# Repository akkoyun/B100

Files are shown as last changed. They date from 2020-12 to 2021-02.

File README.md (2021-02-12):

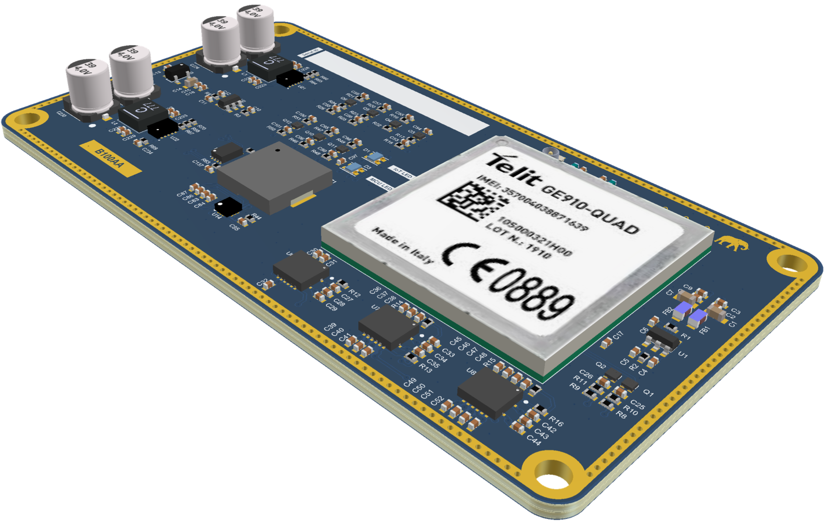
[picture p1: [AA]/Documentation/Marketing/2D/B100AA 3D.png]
B100AA


# B100 All in one GSM IoT Module

B100 module is an open source industrial GSM IoT module.  Module have Atmel based AtMega2560 main microcontroller and AtMega 328P FOTA (remote firmware update - Firmware Over The Air) microcontroller. B100 also have a lot of features on it in a 86x46 (mm) size.

## Features

* Small size 86mm x 46 mm (10 mm heigh).
* Mini header socket for plug and play use.
* 1V8 - 5V5 Vin.
* 3V8 and 5V buck-boost converter.
* 3V3 LDO regulator for digital use.
* All power network are controlled by MCU (for low power modes).
* Main power switch for time trigged sleep mode.
* Atmel based main microcontroller - AtMega2560
* 3V3 / 7.3728mHz main microcontroller.
* Main MCU controlled status LED (RGB).
* 5 port main MCU pinout (socket output).
* External main MCU programmer (ICSP) pinout (socket output).
* External I2C pinout (master line) (socket output).
* External 4 UART pinout (socket output).
* Remote firmware update over GSM.
* Atmel based FOTA microcontroller - AtMega328P
* External FOTA MCU programmer (ICSP) pinout (socket output).
* FOTA MCU controlled status LED (RGB).
* 2G GSM modem - Telit GE910QUAD
* Full hardware based flow control structure.
* External SIM (tray) pin outs.
* Internal eSIM.
* MHF4 GSM antenna output socket.
* GSM power LED.
* GSM status LED (connection etc).
* GSM data transfer LED.
* GSM modem external control USB test points.
* Internal SD card.
* Internal piezo buzzer.
* Internal I2C multiplexer for onboard features.
* Internal real time clock.
* RTC time tick LED.
* I2C Serial ID eeprom.
* I2C eeprom for setting storage.
* Internal I2C ADC (for pressure sensor etc).
* All software (library and samples) are open source.

## Production

All production files are in [production](https://github.com/akkoyun/B100/tree/01.00.00/%5BAA%5D/Production) folder. 

You can download and produce B100 yourself (according license declaration), or you can write us for buy module.

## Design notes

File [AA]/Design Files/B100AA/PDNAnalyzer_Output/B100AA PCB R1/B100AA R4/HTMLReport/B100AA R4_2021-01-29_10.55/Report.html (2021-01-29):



PDN Analyzer Results Report for
B100AA PCB R1

PDN Analyzer Version: 2.0.6.338
Report Time / Date: 29.01.2021 10:55:08
Project Name: B100AA PCB R1
Project Path: C:\Altium Projects\B100\[AA]\Design Files\B100AA\B100AA PCB R1.PcbDoc
PCB Design Name: B100AA PCB R1.PcbDoc
PDN Analyzer Configuration File: C:\Altium Projects\B100\[AA]\Design Files\B100AA\PDNAnalyzer_Output\B100AA PCB R1\B100AA R4\HTMLReport\B100AA R4_2021-01-29_10.55\B100AA R4.pdna

Design Stackup

Layer Name | Layer Name | Material | Thickness (mm) | Dielectric Material | Dielectric Constant | Pullback (mm) | Orientation
Top Overlay | Overlay | | | | | | Top
Top Solder | Solder Mask | Surface Material | 0.013 | Solder Resist | 3,8 | | Top
Top Layer | Signal | Copper | 0.035 | | | | Top
Dielectric 1 | Dielectric | Prepreg | 0.1 | 2313 | 4,05
Mid Layer 1 | Signal | Copper | 0.018
Core 1 | Dielectric | Core | 0.565 | FR-4 | 4,5
Mid Layer 2 | Signal | Copper | 0.018
Dielectric 2 | Dielectric | Prepreg | 0.127 | 2116 | 4,25
Mid Layer 3 | Signal | Copper | 0.018
Core 2 | Dielectric | Core | 0.565 | FR-4 | 4,5
Mid Layer 4 | Signal | Copper | 0.018
Dielectric 3 | Dielectric | Prepreg | 0.1 | 2313 | 4,05
Bottom Layer | Signal | Copper | 0.035 | | | | Bottom
Bottom Solder | Solder Mask | Surface Material | 0.013 | Solder Resist | 3,8 | | Bottom
Bottom Overlay | Overlay | | | | | | Bottom

Artwork by Layer

Layer: Top Layer
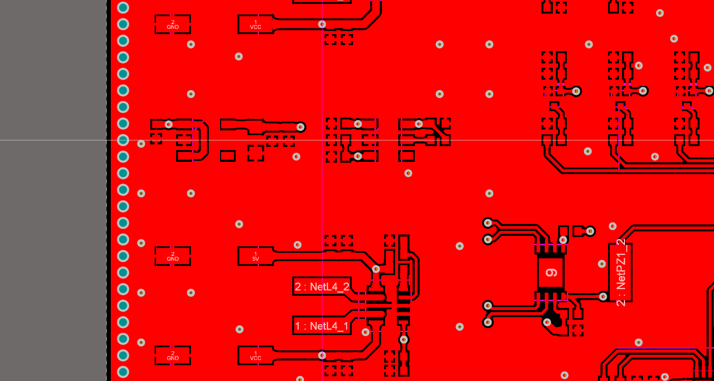
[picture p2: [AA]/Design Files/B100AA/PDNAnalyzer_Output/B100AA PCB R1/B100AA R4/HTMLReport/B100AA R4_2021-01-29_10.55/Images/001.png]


Layer: Mid Layer 1
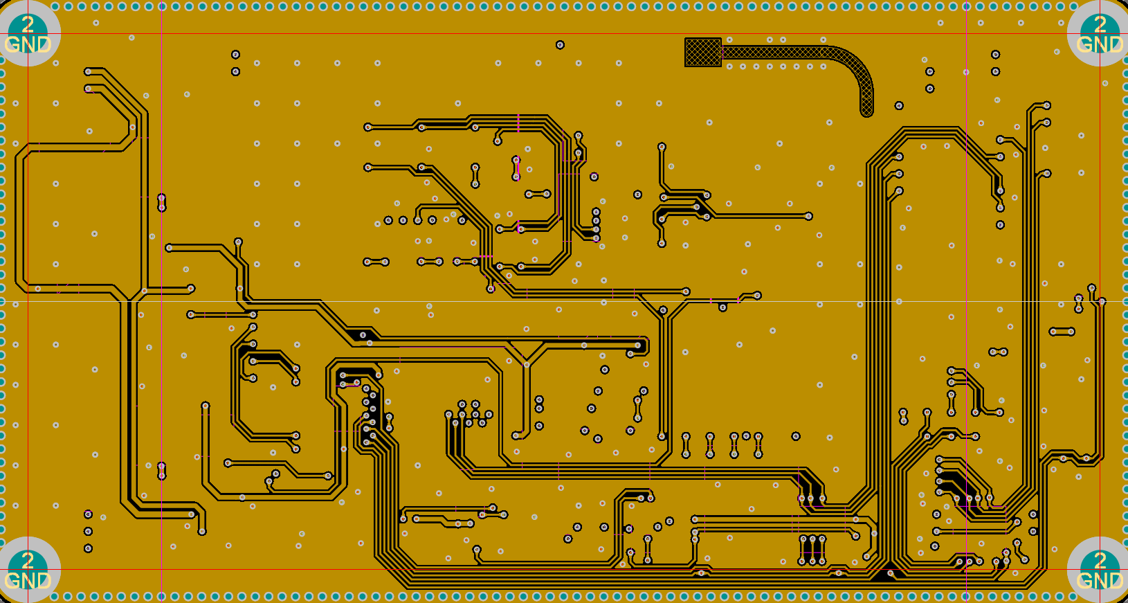
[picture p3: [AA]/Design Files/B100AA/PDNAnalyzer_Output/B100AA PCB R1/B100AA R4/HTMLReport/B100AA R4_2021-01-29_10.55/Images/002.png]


Layer: Mid Layer 2
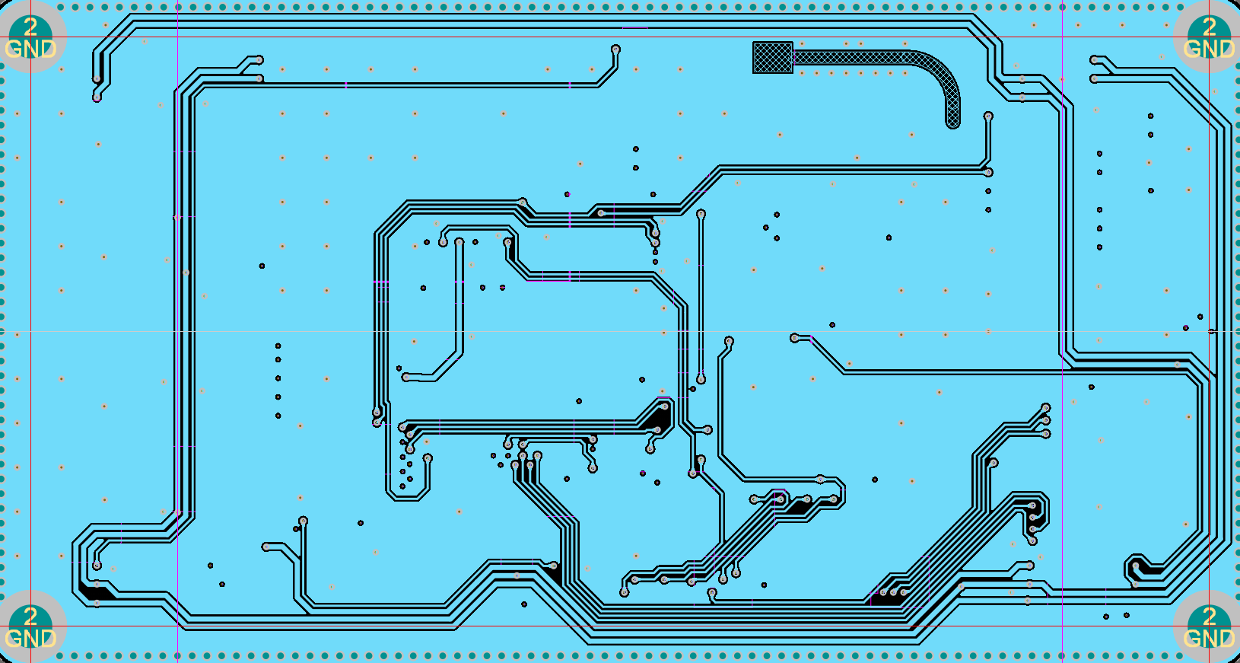
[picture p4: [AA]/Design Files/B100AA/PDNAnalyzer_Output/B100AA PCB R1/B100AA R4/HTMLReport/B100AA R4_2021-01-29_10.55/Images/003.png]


Layer: Mid Layer 3
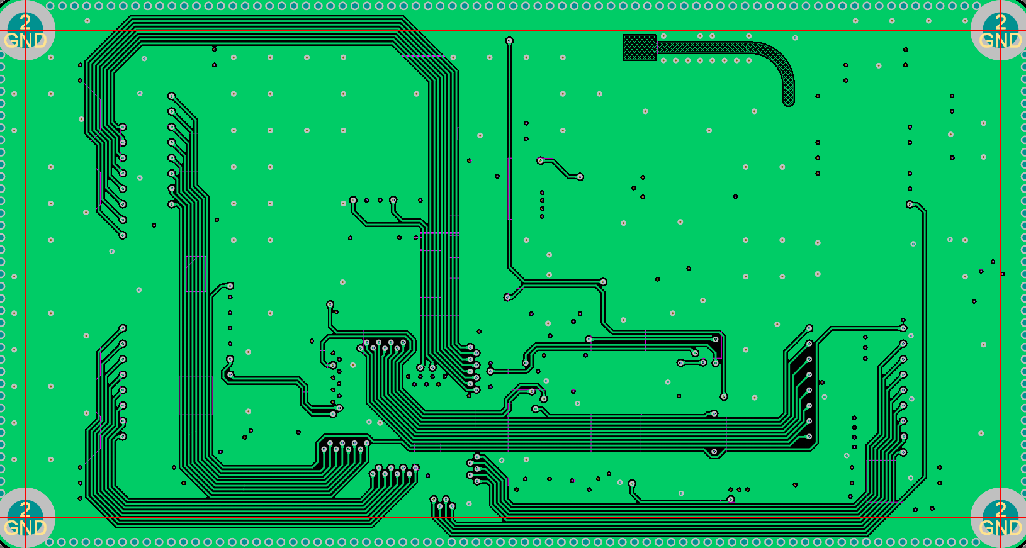
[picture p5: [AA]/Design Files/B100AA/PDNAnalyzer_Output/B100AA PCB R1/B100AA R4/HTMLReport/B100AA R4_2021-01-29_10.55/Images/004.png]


Layer: Mid Layer 4
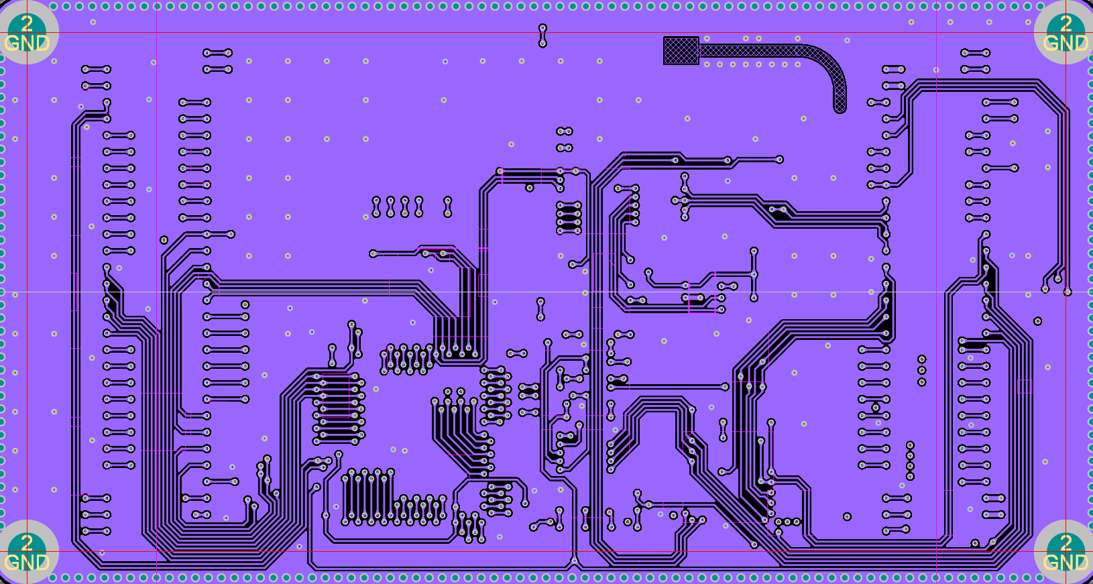
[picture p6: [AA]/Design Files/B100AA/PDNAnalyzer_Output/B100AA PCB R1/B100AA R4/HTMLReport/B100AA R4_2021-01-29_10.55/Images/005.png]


Layer: Bottom Layer
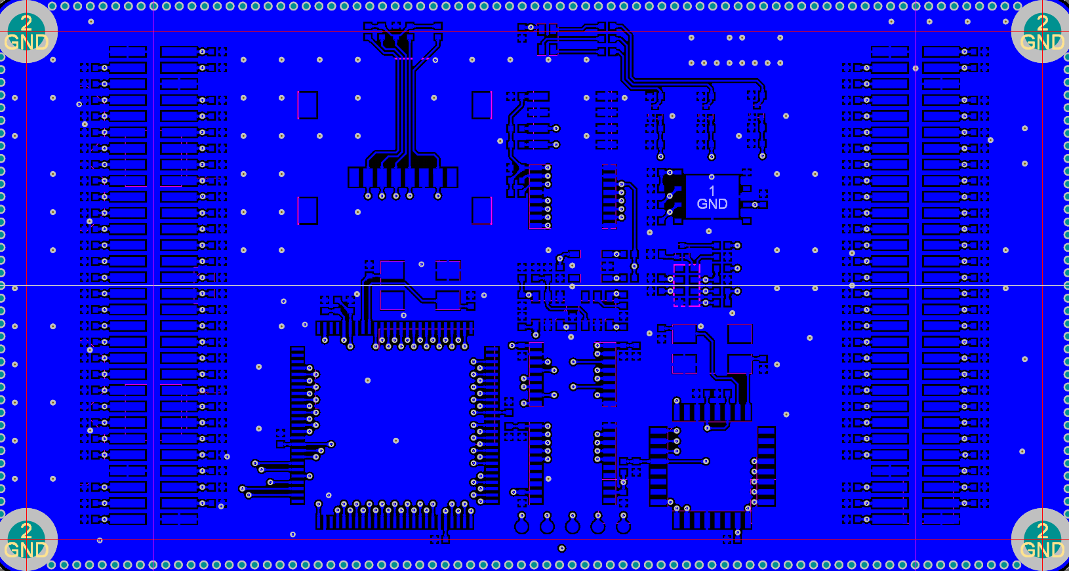
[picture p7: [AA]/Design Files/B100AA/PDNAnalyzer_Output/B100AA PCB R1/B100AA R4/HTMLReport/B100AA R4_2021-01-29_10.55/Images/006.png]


PDN Analizer Global Settings

Parameter | Value
Metal conductivity | 47M S/m
Metal base temperature | 3E+01 °C
Metal work temperature | 3E+01 °C
Metal base conductivity | 47M S/m
Metal temperature coefficient | 4E+02m %/°C
Conductor Max Current Density for Surfase Layers | 0 A/mm^2
Conductor Max Current Density for Internal Layers | 0 A/mm^2
Via wall thickness | 17,78 μm
Max Via Current Density | 0 A/mm^2

System-Level Power Network Results

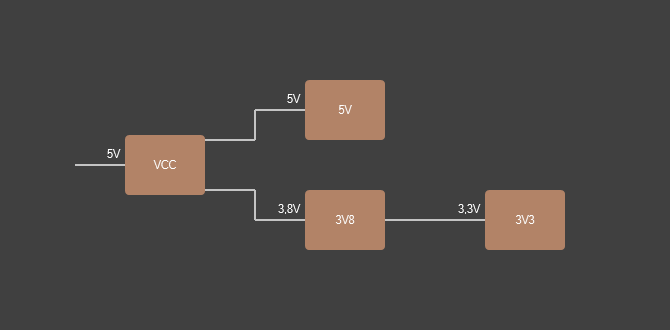
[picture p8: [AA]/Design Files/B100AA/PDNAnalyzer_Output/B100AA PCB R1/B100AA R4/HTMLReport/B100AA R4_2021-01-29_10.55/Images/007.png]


Simulation Pass/Fail Overall: PASS
VCC PASS
3V8 PASS
5V PASS
3V3 PASS

Total Power Consumption: 18,5 Watts

Least Margins:

Margin Type | Absolute | Pass/Fail | Network | ID
Load Voltage (V) | 283,51m | PASS | 3V8 | Load 2
Voltage Source Current (A) | 29,743m | PASS | 3V3 | Source 1
Series Element Current (A) | 1,4298 | PASS | 3V3 | Series 1

Margin Type (%) | Percent | Pass/Fail | Network | ID
Load Voltage | 8.34% | PASS | 3V8 | Load 2
Voltage Source Current | 4.96% | PASS | 3V3 | Source 1
Series Element Current | 71.49% | PASS | 3V3 | Series 1

Network VCC Details

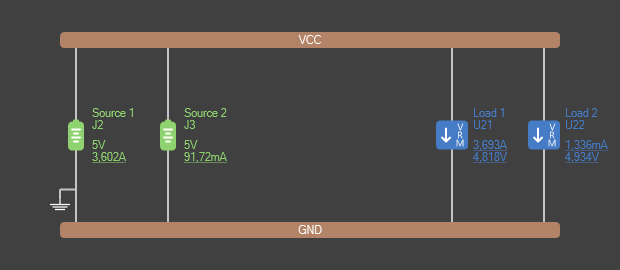
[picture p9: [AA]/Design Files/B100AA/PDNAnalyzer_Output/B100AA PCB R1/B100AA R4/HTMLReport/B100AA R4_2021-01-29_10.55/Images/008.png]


PDN Analysis Pass/Fail: PASS

Power Consumption for This Network: 15,3 Watts

Least Margins:

Margin Type | Absolute | Pass/Fail | ID
Voltage Source Current (A) | 397,64m | PASS | Source 1

Margin Type (%) | Percent | Pass/Fail | ID
Voltage Source Current | 9.94% | PASS | Source 1

Voltage Source Performance Summary:

ID | Source Type | Ref Des | Pass / Fail | Vout setting (V) | Actual Output Voltage (V) | Max Output Current (A) | Actual Output Current (A) | Margin (A) | Margin (%) | Max Pin Current | Highest Actual (A) | Margin (A) | Margin (%) | Max Power Dissipation (W) | Actual Power Dissipation (W) | Margin (W) | Margin (%)
Source 1 | Voltage Source | J2 | PASS | 5 | 4,9964 | 4 | 3,6024 | 397,64m | 9.94% | 0 | 1,8012 | ∞ | ∞
Source 2 | Voltage Source | J3 | PASS | 5 | 4,9999 | 4 | 91,721m | 3,9083 | 97.71% | 0 | 45,86m | ∞ | ∞

Voltage Source Pin Voltage/Current Details:

ID | SourceType | Terminal | Ref Des | Pin | Max Pin Current (A) | Actual Pin Current (A) | Pass / Fail | Pin Voltage (V)
Source 1 | Voltage Source | Power | J2 | 60 | 0 | 1,8012 | PASS | 4,9964
Source 1 | Voltage Source | Power | J2 | 1 | 0 | 1,8012 | PASS | 4,9964
Source 1 | Voltage Source | Ground | J2 | 30 | 0 | 900,59m | PASS | 0
Source 1 | Voltage Source | Ground | J2 | 58 | 0 | 900,59m | PASS | 0
Source 1 | Voltage Source | Ground | J2 | 4 | 0 | 900,59m | PASS | 0
Source 1 | Voltage Source | Ground | J2 | 31 | 0 | 900,59m | PASS | 0
Source 2 | Voltage Source | Power | J3 | 60 | 0 | 45,86m | PASS | 5,001
Source 2 | Voltage Source | Power | J3 | 1 | 0 | 45,86m | PASS | 5,001
Source 2 | Voltage Source | Ground | J3 | 30 | 0 | 22,93m | PASS | 1,0648m
Source 2 | Voltage Source | Ground | J3 | 58 | 0 | 22,93m | PASS | 1,0648m
Source 2 | Voltage Source | Ground | J3 | 4 | 0 | 22,93m | PASS | 1,0648m
Source 2 | Voltage Source | Ground | J3 | 31 | 0 | 22,93m | PASS | 1,0648m

Load Performance Summary:

ID | Load Type | Ref Des | Pass / Fail | Load Value | Min Voltage (V) | Max Voltage (V) | Actual Voltage | Margin (V) | Margin (%) | Min Pwr Pin | Voltage (V) | Max Gnd Pin | Voltage (V) | Actual Current (A)
Load 1 | SMPS_S | U21 | | | | | 4,8183 | | | U21-10 | 4,8232 | U21-8 | 4,8112m | 3,6928
Load 2 | SMPS_S | U22 | | | | | 4,9336 | | | U22-10 | 4,9344 | U22-8 | 859,12u | 1,3363m

Load Pin Voltage/Current Details:

ID | Load Type | Terminal | Ref Des | Pin | Pin Voltage (V) | Pin Current (A)
Load 1 | SMPS_S | In+ | U21 | 10 | 4,8232 | 3,6928
Load 1 | SMPS_S | In- | U21 | 8 | 4,8112m | 418,84m
Load 1 | SMPS_S | In- | U21 | 8 | 4,8112m | 1,8464
Load 1 | SMPS_S | In- | U21 | 3 | 4,8112m | 418,84m
Load 1 | SMPS_S | In- | U21 | 3 | 4,8112m | 1,8464
Load 2 | SMPS_S | In+ | U22 | 10 | 4,9344 | 1,3363m
Load 2 | SMPS_S | In- | U22 | 8 | 859,12u | 592,72u
Load 2 | SMPS_S | In- | U22 | 8 | 859,12u | 668,16u
Load 2 | SMPS_S | In- | U22 | 3 | 859,12u | 592,72u
Load 2 | SMPS_S | In- | U22 | 3 | 859,12u | 668,16u

Component Definition Summary:

ID | Ref Des | Type | In+ Pins | In- Pins | Out+ Pins | Out- Pins | S+ | S- | Vout (V) | Efficiency (%) | Ibias (A) | Resistance | Load Current (A) | Vmin | Vmax | Iout max (A) | PD max (W) | Pin Current max (A)
Source 1 | J2 | Voltage Source | | | J2-1,60 | J2-4,30,31,58 | | | 5 | | | | | | | 4 | | 1,8012
Source 2 | J3 | Voltage Source | | | J3-1,60 | J3-4,30,31,58 | | | 5 | | | | | | | 4 | | 45,86m
Load 1 | U21 | SMPS_S | U21-10 | U21-3,8 | U21-6 | U21-3,8 | R65-2 | R66-1 | 3,8 | 850m | | | 0 | | | 2 | | 0
Load 2 | U22 | SMPS_S | U22-10 | U22-3,8 | U22-6 | U22-3,8 | R68-2 | R70-1 | 5 | 900m | | | 0 | | | 2 | | 0

Network 3V8 Details

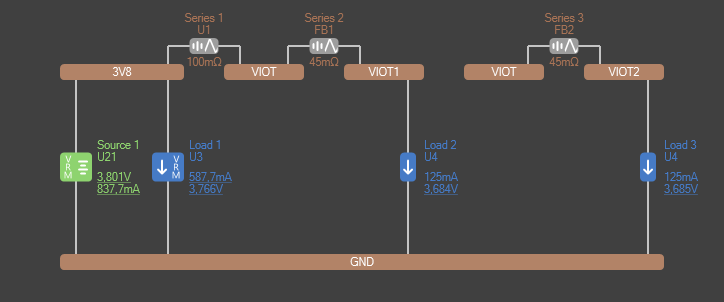
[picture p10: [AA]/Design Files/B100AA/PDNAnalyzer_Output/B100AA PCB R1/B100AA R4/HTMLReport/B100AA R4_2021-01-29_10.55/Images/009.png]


PDN Analysis Pass/Fail: PASS

Power Consumption for This Network: 1,3 Watts

Least Margins:

Margin Type | Absolute | Pass/Fail | ID
Load Voltage (V) | 283,51m | PASS | Load 2
Voltage Source Current (A) | 1,1623 | PASS | Source 1
Series Element Current (A) | 1,75 | PASS | Series 1

Margin Type (%) | Percent | Pass/Fail | ID
Load Voltage | 8.34% | PASS | Load 2
Voltage Source Current | 58.12% | PASS | Source 1
Series Element Current | 87.50% | PASS | Series 1

Voltage Source Performance Summary:

ID | Source Type | Ref Des | Pass / Fail | Vout setting (V) | Actual Output Voltage (V) | Max Output Current (A) | Actual Output Current (A) | Margin (A) | Margin (%) | Max Pin Current | Highest Actual (A) | Margin (A) | Margin (%) | Max Power Dissipation (W) | Actual Power Dissipation (W) | Margin (W) | Margin (%)
Source 1 | SMPS_S | U21 | PASS | 3,8 | 3,8005 | 2 | 837,69m | 1,1623 | 58.12% | 0 | 3,6928 | ∞ | ∞

Voltage Source Pin Voltage/Current Details:

ID | SourceType | Terminal | Ref Des | Pin | Max Pin Current (A) | Actual Pin Current (A) | Pass / Fail | Pin Voltage (V)
Source 1 | SMPS_S | Out+ | U21 | 6 | 0 | 837,69m | PASS | 3,8053
Source 1 | SMPS_S | Out- | U21 | 8 | 0 | 418,84m | PASS | 4,8112m
Source 1 | SMPS_S | Out- | U21 | 8 | 0 | 1,8464 | PASS | 4,8112m
Source 1 | SMPS_S | Out- | U21 | 3 | 0 | 418,84m | PASS | 4,8112m
Source 1 | SMPS_S | Out- | U21 | 3 | 0 | 1,8464 | PASS | 4,8112m

Load Performance Summary:

ID | Load Type | Ref Des | Pass / Fail | Load Value | Min Voltage (V) | Max Voltage (V) | Actual Voltage | Margin (V) | Margin (%) | Min Pwr Pin | Voltage (V) | Max Gnd Pin | Voltage (V) | Actual Current (A)
Load 2 | Current | U4 | PASS | 125mA | 3,4 | 4,2 | 3,6835 | 283,51m | 8.34% | U4-M02 | 3,6846 | U4-P04 | 1,1256m | 125m
Load 3 | Current | U4 | PASS | 125mA | 3,4 | 4,2 | 3,6848 | 284,78m | 8.38% | U4-P02 | 3,6859 | U4-P04 | 1,1256m | 125m
Load 1 | SMPS | U3 | | | | | 3,7664 | | | U3-1 | 3,7673 | U3-2 | 904,12u | 587,68m

Load Pin Voltage/Current Details:

ID | Load Type | Terminal | Ref Des | Pin | Pin Voltage (V) | Pin Current (A)
Load 2 | Current | Power | U4 | M01 | 3,6848 | 62,523m
Load 2 | Current | Power | U4 | M02 | 3,6846 | 62,477m
Load 2 | Current | Ground | U4 | R02 | 1,1179m | 3,288m
Load 2 | Current | Ground | U4 | R04 | 1,1241m | 3,2859m
Load 2 | Current | Ground | U4 | R03 | 1,122m | 3,2866m
Load 2 | Current | Ground | U4 | P03 | 1,124m | 3,286m
Load 2 | Current | Ground | U4 | P04 | 1,1256m | 3,2854m
Load 2 | Current | Ground | U4 | N03 | 1,1242m | 3,2859m
Load 2 | Current | Ground | U4 | R05 | 1,1236m | 3,2861m
Load 2 | Current | Ground | U4 | R06 | 1,1209m | 3,287m
Load 2 | Current | Ground | U4 | P05 | 1,1248m | 3,2857m
Load 2 | Current | Ground | U4 | R08 | 1,1134m | 3,2894m
Load 2 | Current | Ground | U4 | N05 | 1,1234m | 3,2862m
Load 2 | Current | Ground | U4 | P06 | 1,1214m | 3,2868m
Load 2 | Current | Ground | U4 | N04 | 1,125m | 3,2856m
Load 2 | Current | Ground | U4 | N06 | 1,1195m | 3,2874m
Load 2 | Current | Ground | U4 | L01 | 1,1132m | 3,2895m
Load 2 | Current | Ground | U4 | L02 | 1,1174m | 3,2881m
Load 2 | Current | Ground | U4 | J01 | 1,1123m | 3,2898m
Load 2 | Current | Ground | U4 | K02 | 1,1174m | 3,2881m
Load 2 | Current | Ground | U4 | H01 | 1,1102m | 3,2905m
Load 2 | Current | Ground | U4 | J02 | 1,1152m | 3,2889m
Load 2 | Current | Ground | U4 | G02 | 1,1106m | 3,2904m
Load 2 | Current | Ground | U4 | M03 | 1,1218m | 3,2867m
Load 2 | Current | Ground | U4 | M04 | 1,1224m | 3,2865m
Load 2 | Current | Ground | U4 | H02 | 1,1119m | 3,2899m
Load 2 | Current | Ground | U4 | R10 | 1,1108m | 3,2903m
Load 2 | Current | Ground | U4 | P09 | 1,1114m | 3,2901m
Load 2 | Current | Ground | U4 | P10 | 1,1104m | 3,2904m
Load 2 | Current | Ground | U4 | P08 | 1,1137m | 3,2893m
Load 2 | Current | Ground | U4 | P13 | 1,1005m | 3,2937m
Load 2 | Current | Ground | U4 | M12 | 1,1003m | 3,2937m
Load 2 | Current | Ground | U4 | G01 | 1,111m | 3,2902m
Load 2 | Current | Ground | U4 | E01 | 1,1066m | 3,2917m
Load 2 | Current | Ground | U4 | F02 | 1,1088m | 3,2909m
Load 2 | Current | Ground | U4 | E02 | 1,1078m | 3,2913m
Load 2 | Current | Ground | U4 | A02 | 1,1018m | 3,2932m
Load 2 | Current | Ground | U4 | A04 | 1,0998m | 3,2939m
Load 2 | Current | Ground | U4 | E14 | 1,0695m | 3,3039m
Load 2 | Current | Ground | U4 | B13 | 1,0906m | 3,297m
Load 3 | Current | Power | U4 | P01 | 3,6863 | 31,289m
Load 3 | Current | Power | U4 | P02 | 3,6859 | 31,222m
Load 3 | Current | Power | U4 | N02 | 3,686 | 31,233m
Load 3 | Current | Power | U4 | N01 | 3,6861 | 31,256m
Load 3 | Current | Ground | U4 | R02 | 1,1179m | 3,2887m
Load 3 | Current | Ground | U4 | R04 | 1,1241m | 3,2876m
Load 3 | Current | Ground | U4 | R03 | 1,122m | 3,288m
Load 3 | Current | Ground | U4 | P03 | 1,124m | 3,2876m
Load 3 | Current | Ground | U4 | P04 | 1,1256m | 3,2873m
Load 3 | Current | Ground | U4 | N03 | 1,1242m | 3,2876m
Load 3 | Current | Ground | U4 | R05 | 1,1236m | 3,2877m
Load 3 | Current | Ground | U4 | R06 | 1,1209m | 3,2882m
Load 3 | Current | Ground | U4 | P05 | 1,1248m | 3,2875m
Load 3 | Current | Ground | U4 | R08 | 1,1134m | 3,2895m
Load 3 | Current | Ground | U4 | N05 | 1,1234m | 3,2877m
Load 3 | Current | Ground | U4 | P06 | 1,1214m | 3,2881m
Load 3 | Current | Ground | U4 | N04 | 1,125m | 3,2875m
Load 3 | Current | Ground | U4 | N06 | 1,1195m | 3,2884m
Load 3 | Current | Ground | U4 | L01 | 1,1132m | 3,2895m
Load 3 | Current | Ground | U4 | L02 | 1,1174m | 3,2888m
Load 3 | Current | Ground | U4 | J01 | 1,1123m | 3,2896m
Load 3 | Current | Ground | U4 | K02 | 1,1174m | 3,2888m
Load 3 | Current | Ground | U4 | H01 | 1,1102m | 3,29m
Load 3 | Current | Ground | U4 | J02 | 1,1152m | 3,2892m
Load 3 | Current | Ground | U4 | G02 | 1,1106m | 3,2899m
Load 3 | Current | Ground | U4 | M03 | 1,1218m | 3,288m
Load 3 | Current | Ground | U4 | M04 | 1,1224m | 3,2879m
Load 3 | Current | Ground | U4 | H02 | 1,1119m | 3,2897m
Load 3 | Current | Ground | U4 | R10 | 1,1108m | 3,2899m
Load 3 | Current | Ground | U4 | P09 | 1,1114m | 3,2898m
Load 3 | Current | Ground | U4 | P10 | 1,1104m | 3,29m
Load 3 | Current | Ground | U4 | P08 | 1,1137m | 3,2894m
Load 3 | Current | Ground | U4 | P13 | 1,1005m | 3,2917m
Load 3 | Current | Ground | U4 | M12 | 1,1003m | 3,2917m
Load 3 | Current | Ground | U4 | G01 | 1,111m | 3,2899m
Load 3 | Current | Ground | U4 | E01 | 1,1066m | 3,2906m
Load 3 | Current | Ground | U4 | F02 | 1,1088m | 3,2902m
Load 3 | Current | Ground | U4 | E02 | 1,1078m | 3,2904m
Load 3 | Current | Ground | U4 | A02 | 1,1018m | 3,2915m
Load 3 | Current | Ground | U4 | A04 | 1,0998m | 3,2918m
Load 3 | Current | Ground | U4 | E14 | 1,0695m | 3,297m
Load 3 | Current | Ground | U4 | B13 | 1,0906m | 3,2934m
Load 1 | SMPS | In+ | U3 | 1 | 3,7673 | 587,68m
Load 1 | SMPS | In- | U3 | 2 | 904,12u | 570,26m
Load 1 | SMPS | In- | U3 | 2 | 904,12u | 587,68m

Series Element Performance Summary:

ID | Ref Des | Pass / Fail | Voltage (V) | Resistance (Ohms) | Max Current (A) | Actual Current (A) | Margin (A) | Margin (%) | Actual Voltage Drop (V)
Series 1 | U1 | PASS | 0 | 100m | 2 | 250m | 1,75 | 87.50% | 25m
Series 2 | FB1 | PASS | 0 | 45m | 2 | 125m | 1,875 | 93.75% | 5,63m
Series 3 | FB2 | PASS | 0 | 45m | 2 | 125m | 1,875 | 93.75% | 5,62m

Series Element Pin Voltage/Current Details:

ID | Terminal | Ref Des | Pin | Pin Voltage (V) | Pin Current (A)
Series 1 | In | U1 | 1 | 3,7208 | 250m
Series 1 | Out | U1 | 6 | 3,6958 | 250m
Series 2 | In | FB1 | 1 | 3,6945 | 125m
Series 2 | Out | FB1 | 2 | 3,6889 | 125m
Series 3 | In | FB2 | 1 | 3,6946 | 125m
Series 3 | Out | FB2 | 2 | 3,689 | 125m

Component Definition Summary:

ID | Ref Des | Type | In+ Pins | In- Pins | Out+ Pins | Out- Pins | S+ | S- | Vout (V) | Efficiency (%) | Ibias (A) | Resistance | Load Current (A) | Vmin | Vmax | Iout max (A) | PD max (W) | Pin Current max (A)
Source 1 | U21 | SMPS_S
Load 2 | U4 | Current | U4-M01,M02 | U4-R02,R04,R03,P03,P04,N03,R05,R06,P05,R08,N05,P06,N04,N06,L01,L02,J01,K02,H01,J02,G02,M03,M04,H02,R10,P09,P10,P08,P13,M12,G01,E01,F02,E02,A02,A04,E14,B13 | | | | | | | | | 125m | 3,4 | 4,2
Load 3 | U4 | Current | U4-P01,P02,N02,N01 | U4-R02,R04,R03,P03,P04,N03,R05,R06,P05,R08,N05,P06,N04,N06,L01,L02,J01,K02,H01,J02,G02,M03,M04,H02,R10,P09,P10,P08,P13,M12,G01,E01,F02,E02,A02,A04,E14,B13 | | | | | | | | | 125m | 3,4 | 4,2
Load 1 | U3 | SMPS | U3-1 | U3-2 | U3-5 | U3-2 | | | 3,3 | 850m | | | 0 | | | 600m | | 0
Series 1 | U1 | Series | U1-1 | | U1-6 | | | | 0 | | | 100m | | | | 2 | | 2
Series 2 | FB1 | Series | FB1-1 | | FB1-2 | | | | 0 | | | 45m | | | | 2 | | 2
Series 3 | FB2 | Series | FB2-1 | | FB2-2 | | | | 0 | | | 45m | | | | 2 | | 2

Network 5V Details

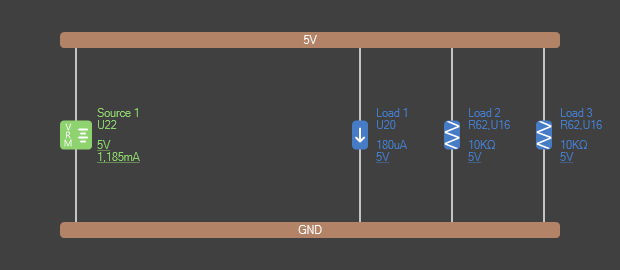
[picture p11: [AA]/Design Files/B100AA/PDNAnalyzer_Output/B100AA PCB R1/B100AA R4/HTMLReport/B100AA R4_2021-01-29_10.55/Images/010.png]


PDN Analysis Pass/Fail: PASS

Power Consumption for This Network: 5,93m Watts

Least Margins:

Margin Type | Absolute | Pass/Fail | ID
Load Voltage (V) | 500,24m | PASS | Load 1
Voltage Source Current (A) | 1,9988 | PASS | Source 1

Margin Type (%) | Percent | Pass/Fail | ID
Load Voltage | 18.53% | PASS | Load 1
Voltage Source Current | 99.94% | PASS | Source 1

Voltage Source Performance Summary:

ID | Source Type | Ref Des | Pass / Fail | Vout setting (V) | Actual Output Voltage (V) | Max Output Current (A) | Actual Output Current (A) | Margin (A) | Margin (%) | Max Pin Current | Highest Actual (A) | Margin (A) | Margin (%) | Max Power Dissipation (W) | Actual Power Dissipation (W) | Margin (W) | Margin (%)
Source 1 | SMPS_S | U22 | PASS | 5 | 5 | 2 | 1,1854m | 1,9988 | 99.94% | 0 | 1,3363m | ∞ | ∞

Voltage Source Pin Voltage/Current Details:

ID | SourceType | Terminal | Ref Des | Pin | Max Pin Current (A) | Actual Pin Current (A) | Pass / Fail | Pin Voltage (V)
Source 1 | SMPS_S | Out+ | U22 | 6 | 0 | 1,1854m | PASS | 5,0009
Source 1 | SMPS_S | Out- | U22 | 8 | 0 | 592,72u | PASS | 859,12u
Source 1 | SMPS_S | Out- | U22 | 8 | 0 | 668,16u | PASS | 859,12u
Source 1 | SMPS_S | Out- | U22 | 3 | 0 | 592,72u | PASS | 859,12u
Source 1 | SMPS_S | Out- | U22 | 3 | 0 | 668,16u | PASS | 859,12u

Load Performance Summary:

ID | Load Type | Ref Des | Pass / Fail | Load Value | Min Voltage (V) | Max Voltage (V) | Actual Voltage | Margin (V) | Margin (%) | Min Pwr Pin | Voltage (V) | Max Gnd Pin | Voltage (V) | Actual Current (A)
Load 1 | Current | U20 | PASS | 180uA | 2,7 | 5,5 | 4,9998 | 500,24m | 18.53% | U20-3 | 5,0008 | U20-6 | 1,0267m | 180u
Load 2 | Resistor | R62, U16 | PASS | 10KOhm | 0 | 0 | 4,9997 | 0 | ∞ | R62-2 | 5,0008 | U16-8 | 1,0912m | 500,05u
Load 3 | Resistor | R62, U16 | PASS | 10KOhm | 0 | 0 | 4,9997 | 0 | ∞ | R62-2 | 5,0008 | U16-8 | 1,0912m | 500,05u

Load Pin Voltage/Current Details:

ID | Load Type | Terminal | Ref Des | Pin | Pin Voltage (V) | Pin Current (A)
Load 1 | Current | Power | U20 | 3 | 5,0008 | 180u
Load 1 | Current | Ground | U20 | 6 | 1,0267m | 180u
Load 2 | Resistor | Power | R62 | 2 | 5,0008 | 500,05u
Load 2 | Resistor | Ground | U16 | 8 | 1,0912m | 499,88u
Load 3 | Resistor | Power | R62 | 2 | 5,0008 | 500,05u
Load 3 | Resistor | Ground | U16 | 8 | 1,0912m | 499,88u

Component Definition Summary:

ID | Ref Des | Type | In+ Pins | In- Pins | Out+ Pins | Out- Pins | S+ | S- | Vout (V) | Efficiency (%) | Ibias (A) | Resistance | Load Current (A) | Vmin | Vmax | Iout max (A) | PD max (W) | Pin Current max (A)
Source 1 | U22 | SMPS_S
Load 1 | U20 | Current | U20-3 | U20-6 | | | | | | | | | 180u | 2,7 | 5,5
Load 2 | R62, U16 | Resistor | R62-2 | U16-8 | | | | | | | | 10K | | 0 | 0
Load 3 | R62, U16 | Resistor | R62-2 | U16-8 | | | | | | | | 10K | | 0 | 0

Network 3V3 Details

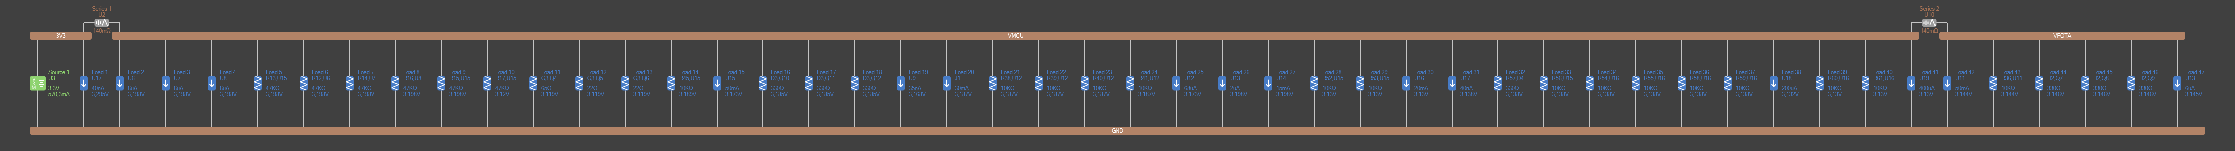
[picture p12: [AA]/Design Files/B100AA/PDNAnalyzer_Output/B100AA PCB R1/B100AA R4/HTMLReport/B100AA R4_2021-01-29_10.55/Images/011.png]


PDN Analysis Pass/Fail: PASS

Power Consumption for This Network: 1,88 Watts

Least Margins:

Margin Type | Absolute | Pass/Fail | ID
Load Voltage (V) | 630,33m | PASS | Load 41
Voltage Source Current (A) | 29,743m | PASS | Source 1
Series Element Current (A) | 1,4298 | PASS | Series 1

Margin Type (%) | Percent | Pass/Fail | ID
Load Voltage | 25.21% | PASS | Load 41
Voltage Source Current | 4.96% | PASS | Source 1
Series Element Current | 71.49% | PASS | Series 1

Voltage Source Performance Summary:

ID | Source Type | Ref Des | Pass / Fail | Vout setting (V) | Actual Output Voltage (V) | Max Output Current (A) | Actual Output Current (A) | Margin (A) | Margin (%) | Max Pin Current | Highest Actual (A) | Margin (A) | Margin (%) | Max Power Dissipation (W) | Actual Power Dissipation (W) | Margin (W) | Margin (%)
Source 1 | SMPS | U3 | PASS | 3,3 | 3,2994 | 600m | 570,26m | 29,743m | 4.96% | 0 | 587,68m | ∞ | ∞

Voltage Source Pin Voltage/Current Details:

ID | SourceType | Terminal | Ref Des | Pin | Max Pin Current (A) | Actual Pin Current (A) | Pass / Fail | Pin Voltage (V)
Source 1 | SMPS | Out+ | U3 | 5 | 0 | 570,26m | PASS | 3,3003
Source 1 | SMPS | Out- | U3 | 2 | 0 | 570,26m | PASS | 904,12u
Source 1 | SMPS | Out- | U3 | 2 | 0 | 587,68m | PASS | 904,12u

Load Performance Summary:

ID | Load Type | Ref Des | Pass / Fail | Load Value | Min Voltage (V) | Max Voltage (V) | Actual Voltage | Margin (V) | Margin (%) | Min Pwr Pin | Voltage (V) | Max Gnd Pin | Voltage (V) | Actual Current (A)
Load 1 | Current | U17 | PASS | 40nA | 0 | 0 | 3,2947 | 0 | ∞ | U17-6 | 3,2957 | U17-5 | 1,0866m | 100u
Load 2 | Current | U6 | PASS | 8uA | 0 | 0 | 3,1979 | 0 | ∞ | U6-1 | 3,1989 | U6-17 | 1,0207m | 100u
Load 3 | Current | U7 | PASS | 8uA | 0 | 0 | 3,1979 | 0 | ∞ | U7-1 | 3,1989 | U7-17 | 1,0605m | 100u
Load 4 | Current | U8 | PASS | 8uA | 0 | 0 | 3,1978 | 0 | ∞ | U8-1 | 3,1989 | U8-8 | 1,0789m | 100u
Load 5 | Resistor | R13, U15 | PASS | 47KOhm | 0 | 0 | 3,1979 | 0 | ∞ | R13-2 | 3,1989 | U15-62 | 996,22u | 68,031u
Load 6 | Resistor | R12, U6 | PASS | 47KOhm | 0 | 0 | 3,1979 | 0 | ∞ | R12-2 | 3,1989 | U6-17 | 1,0207m | 68,043u
Load 7 | Resistor | R14, U7 | PASS | 47KOhm | 0 | 0 | 3,1979 | 0 | ∞ | R14-2 | 3,1989 | U7-17 | 1,0605m | 68,042u
Load 8 | Resistor | R16, U8 | PASS | 47KOhm | 0 | 0 | 3,1978 | 0 | ∞ | R16-2 | 3,1989 | U8-8 | 1,0789m | 68,042u
Load 9 | Resistor | R15, U15 | PASS | 47KOhm | 0 | 0 | 3,1979 | 0 | ∞ | R15-2 | 3,1989 | U15-62 | 996,22u | 68,052u
Load 10 | Resistor | R17, U15 | PASS | 47KOhm | 0 | 0 | 3,1198 | 0 | ∞ | R17-2 | 3,1208 | U15-62 | 996,22u | 66,391u
Load 11 | Resistor | Q3, Q4 | PASS | 65Ohm | 0 | 0 | 3,1194 | 0 | ∞ | Q3-2 | 3,1206 | Q4-2 | 1,1851m | 47,99m
Load 12 | Resistor | Q3, Q5 | PASS | 22Ohm | 0 | 0 | 3,1193 | 0 | ∞ | Q3-2 | 3,1206 | Q5-2 | 1,2824m | 141,79m
Load 13 | Resistor | Q3, Q6 | PASS | 22Ohm | 0 | 0 | 3,1193 | 0 | ∞ | Q3-2 | 3,1206 | Q6-2 | 1,2945m | 141,78m
Load 14 | Resistor | R45, U15 | PASS | 10KOhm | 0 | 0 | 3,1893 | 0 | ∞ | R45-2 | 3,1903 | U15-62 | 996,22u | 318,96u
Load 15 | Current | U15 | PASS | 50mA | 0 | 0 | 3,1733 | 0 | ∞ | U15-61 | 3,1743 | U15-62 | 996,22u | 50m
Load 16 | Resistor | D3, Q10 | PASS | 330Ohm | 0 | 0 | 3,1853 | 0 | ∞ | D3-4 | 3,1864 | Q10-2 | 1,1398m | 9,6523m
Load 17 | Resistor | D3, Q11 | PASS | 330Ohm | 0 | 0 | 3,1853 | 0 | ∞ | D3-4 | 3,1864 | Q11-2 | 1,1343m | 9,6523m
Load 18 | Resistor | D3, Q12 | PASS | 330Ohm | 0 | 0 | 3,1853 | 0 | ∞ | D3-4 | 3,1864 | Q12-2 | 1,1368m | 9,6523m
Load 19 | Current | U9 | PASS | 35nA | 0 | 0 | 3,1676 | 0 | ∞ | U9-1 | 3,1687 | U9-2 | 1,0522m | 100u
Load 42 | Current | U11 | PASS | 50mA | 0 | 0 | 3,1435 | 0 | ∞ | U11-18 | 3,1447 | U11-5 | 1,1612m | 50m
Load 43 | Resistor | R36, U11 | PASS | 10KOhm | 0 | 0 | 3,1444 | 0 | ∞ | R36-2 | 3,1456 | U11-5 | 1,1612m | 314,4u
Load 44 | Resistor | D2, Q7 | PASS | 330Ohm | 0 | 0 | 3,1455 | 0 | ∞ | D2-4 | 3,1467 | Q7-2 | 1,1072m | 9,532m
Load 45 | Resistor | D2, Q8 | PASS | 330Ohm | 0 | 0 | 3,1455 | 0 | ∞ | D2-4 | 3,1467 | Q8-2 | 1,1062m | 9,532m
Load 46 | Resistor | D2, Q9 | PASS | 330Ohm | 0 | 0 | 3,1455 | 0 | ∞ | D2-4 | 3,1467 | Q9-2 | 1,106m | 9,532m
Load 20 | Current | J1 | PASS | 30mA | 0 | 0 | 3,187 | 0 | ∞ | J1-4 | 3,1881 | J1-6 | 1,1258m | 30m
Load 21 | Resistor | R38, U12 | PASS | 10KOhm | 0 | 0 | 3,187 | 0 | ∞ | R38-2 | 3,1881 | U12-8 | 1,059m | 318,66u
Load 22 | Resistor | R39, U12 | PASS | 10KOhm | 0 | 0 | 3,187 | 0 | ∞ | R39-2 | 3,1881 | U12-8 | 1,059m | 318,66u
Load 23 | Resistor | R40, U12 | PASS | 10KOhm | 0 | 0 | 3,187 | 0 | ∞ | R40-2 | 3,1881 | U12-8 | 1,059m | 318,66u
Load 24 | Resistor | R41, U12 | PASS | 10KOhm | 0 | 0 | 3,187 | 0 | ∞ | R41-2 | 3,1881 | U12-8 | 1,059m | 318,66u
Load 25 | Current | U12 | PASS | 68uA | 0 | 0 | 3,1735 | 0 | ∞ | U12-16 | 3,1745 | U12-8 | 1,059m | 100u
Load 26 | Current | U13 | PASS | 2uA | 0 | 0 | 3,1979 | 0 | ∞ | U13-2 | 3,1989 | U13-11 | 1,0581m | 100u
Load 47 | Current | U13 | PASS | 6uA | 0 | 0 | 3,1445 | 0 | ∞ | U13-19 | 3,1456 | U13-11 | 1,0581m | 100u
Load 27 | Current | U14 | PASS | 15mA | 0 | 0 | 3,1979 | 0 | ∞ | U14-12 | 3,1989 | U14-13 | 1,0191m | 15m
Load 28 | Resistor | R52, U15 | PASS | 10KOhm | 0 | 0 | 3,1304 | 0 | ∞ | R52-2 | 3,1314 | U15-62 | 996,22u | 313,07u
Load 29 | Resistor | R53, U15 | PASS | 10KOhm | 0 | 0 | 3,1304 | 0 | ∞ | R53-2 | 3,1314 | U15-62 | 996,22u | 313,07u
Load 30 | Current | U16 | PASS | 20mA | 0 | 0 | 3,1303 | 0 | ∞ | U16-16 | 3,1314 | U16-13 | 1,1003m | 20m
Load 31 | Current | U17 | PASS | 40nA | 0 | 0 | 3,1383 | 0 | ∞ | U17-7 | 3,1394 | U17-5 | 1,0866m | 100u
Load 32 | Resistor | R57, D4 | PASS | 330Ohm | 0 | 0 | 3,1379 | 0 | ∞ | R57-2 | 3,139 | D4-1 | 1,0985m | 9,5087m
Load 33 | Resistor | R56, U15 | PASS | 10KOhm | 0 | 0 | 3,1381 | 0 | ∞ | R56-2 | 3,1391 | U15-62 | 996,22u | 313,83u
Load 34 | Resistor | R54, U16 | PASS | 10KOhm | 0 | 0 | 3,1379 | 0 | ∞ | R54-2 | 3,139 | U16-8 | 1,0912m | 313,85u
Load 35 | Resistor | R55, U16 | PASS | 10KOhm | 0 | 0 | 3,1379 | 0 | ∞ | R55-2 | 3,139 | U16-13 | 1,1003m | 313,83u
Load 36 | Resistor | R58, U16 | PASS | 10KOhm | 0 | 0 | 3,1385 | 0 | ∞ | R58-2 | 3,1396 | U16-8 | 1,0912m | 313,9u
Load 37 | Resistor | R59, U16 | PASS | 10KOhm | 0 | 0 | 3,1385 | 0 | ∞ | R59-2 | 3,1396 | U16-8 | 1,0912m | 313,9u
Load 38 | Current | U18 | PASS | 200uA | 1,62 | 5,25 | 3,1317 | 1,5117 | 93.31% | U18-5 | 3,1328 | U18-2 | 1,0825m | 200u
Load 39 | Resistor | R60, U16 | PASS | 10KOhm | 0 | 0 | 3,1303 | 0 | ∞ | R60-2 | 3,1314 | U16-8 | 1,0912m | 313,09u
Load 40 | Resistor | R61, U16 | PASS | 10KOhm | 0 | 0 | 3,1303 | 0 | ∞ | R61-2 | 3,1314 | U16-8 | 1,0912m | 313,09u
Load 41 | Current | U19 | PASS | 400uA | 2,5 | 5,5 | 3,1303 | 630,33m | 25.21% | U19-8 | 3,1314 | U19-4 | 1,0956m | 400u

Load Pin Voltage/Current Details:

ID | Load Type | Terminal | Ref Des | Pin | Pin Voltage (V) | Pin Current (A)
Load 1 | Current | Power | U17 | 6 | 3,2957 | 100u
Load 1 | Current | Ground | U17 | 5 | 1,0866m | 100u
Load 2 | Current | Power | U6 | 1 | 3,1989 | 100u
Load 2 | Current | Ground | U6 | 8 | 1,0111m | 33,335u
Load 2 | Current | Ground | U6 | 9 | 1,0066m | 33,338u
Load 2 | Current | Ground | U6 | 17 | 1,0207m | 33,328u
Load 3 | Current | Power | U7 | 1 | 3,1989 | 100u
Load 3 | Current | Ground | U7 | 8 | 1,0554m | 33,334u
Load 3 | Current | Ground | U7 | 9 | 1,0528m | 33,336u
Load 3 | Current | Ground | U7 | 17 | 1,0605m | 33,331u
Load 4 | Current | Power | U8 | 1 | 3,1989 | 100u
Load 4 | Current | Ground | U8 | 8 | 1,0789m | 33,333u
Load 4 | Current | Ground | U8 | 9 | 1,0774m | 33,334u
Load 4 | Current | Ground | U8 | 17 | 1,0786m | 33,333u
Load 5 | Resistor | Power | R13 | 2 | 3,1989 | 68,031u
Load 5 | Resistor | Ground | U15 | 11 | 896,7u | 13,621u
Load 5 | Resistor | Ground | U15 | 32 | 974,2u | 13,619u
Load 5 | Resistor | Ground | U15 | 62 | 996,22u | 13,618u
Load 5 | Resistor | Ground | U15 | 81 | 941,96u | 13,62u
Load 5 | Resistor | Ground | U15 | 99 | 871,28u | 13,621u
Load 6 | Resistor | Power | R12 | 2 | 3,1989 | 68,043u
Load 6 | Resistor | Ground | U6 | 8 | 1,0111m | 22,678u
Load 6 | Resistor | Ground | U6 | 9 | 1,0066m | 22,678u
Load 6 | Resistor | Ground | U6 | 17 | 1,0207m | 22,678u
Load 7 | Resistor | Power | R14 | 2 | 3,1989 | 68,042u
Load 7 | Resistor | Ground | U7 | 8 | 1,0554m | 22,678u
Load 7 | Resistor | Ground | U7 | 9 | 1,0528m | 22,678u
Load 7 | Resistor | Ground | U7 | 17 | 1,0605m | 22,677u
Load 8 | Resistor | Power | R16 | 2 | 3,1989 | 68,042u
Load 8 | Resistor | Ground | U8 | 8 | 1,0789m | 22,677u
Load 8 | Resistor | Ground | U8 | 9 | 1,0774m | 22,677u
Load 8 | Resistor | Ground | U8 | 17 | 1,0786m | 22,677u
Load 9 | Resistor | Power | R15 | 2 | 3,1989 | 68,052u
Load 9 | Resistor | Ground | U15 | 11 | 896,7u | 13,6u
Load 9 | Resistor | Ground | U15 | 32 | 974,2u | 13,598u
Load 9 | Resistor | Ground | U15 | 62 | 996,22u | 13,597u
Load 9 | Resistor | Ground | U15 | 81 | 941,96u | 13,598u
Load 9 | Resistor | Ground | U15 | 99 | 871,28u | 13,6u
Load 10 | Resistor | Power | R17 | 2 | 3,1208 | 66,391u
Load 10 | Resistor | Ground | U15 | 11 | 896,7u | 13,268u
Load 10 | Resistor | Ground | U15 | 32 | 974,2u | 13,266u
Load 10 | Resistor | Ground | U15 | 62 | 996,22u | 13,265u
Load 10 | Resistor | Ground | U15 | 81 | 941,96u | 13,266u
Load 10 | Resistor | Ground | U15 | 99 | 871,28u | 13,268u
Load 11 | Resistor | Power | Q3 | 2 | 3,1206 | 47,99m
Load 11 | Resistor | Ground | Q4 | 2 | 1,1851m | 47,99m
Load 12 | Resistor | Power | Q3 | 2 | 3,1206 | 141,79m
Load 12 | Resistor | Ground | Q5 | 2 | 1,2824m | 141,79m
Load 13 | Resistor | Power | Q3 | 2 | 3,1206 | 141,78m
Load 13 | Resistor | Ground | Q6 | 2 | 1,2945m | 141,78m
Load 14 | Resistor | Power | R45 | 2 | 3,1903 | 318,96u
Load 14 | Resistor | Ground | U15 | 11 | 896,7u | 63,768u
Load 14 | Resistor | Ground | U15 | 32 | 974,2u | 63,759u
Load 14 | Resistor | Ground | U15 | 62 | 996,22u | 63,756u
Load 14 | Resistor | Ground | U15 | 81 | 941,96u | 63,763u
Load 14 | Resistor | Ground | U15 | 99 | 871,28u | 63,771u
Load 15 | Current | Power | U15 | 10 | 3,1969 | 10,542m
Load 15 | Current | Power | U15 | 31 | 3,1903 | 9,8755m
Load 15 | Current | Power | U15 | 61 | 3,1743 | 8,2802m
Load 15 | Current | Power | U15 | 80 | 3,1988 | 10,729m
Load 15 | Current | Power | U15 | 100 | 3,1972 | 10,574m
Load 15 | Current | Ground | U15 | 11 | 896,7u | 10,004m
Load 15 | Current | Ground | U15 | 32 | 974,2u | 9,9962m
Load 15 | Current | Ground | U15 | 62 | 996,22u | 9,994m
Load 15 | Current | Ground | U15 | 81 | 941,96u | 9,9994m
Load 15 | Current | Ground | U15 | 99 | 871,28u | 10,007m
Load 16 | Resistor | Power | D3 | 4 | 3,1864 | 9,6523m
Load 16 | Resistor | Ground | Q10 | 2 | 1,1398m | 9,6523m
Load 17 | Resistor | Power | D3 | 4 | 3,1864 | 9,6523m
Load 17 | Resistor | Ground | Q11 | 2 | 1,1343m | 9,6524m
Load 18 | Resistor | Power | D3 | 4 | 3,1864 | 9,6523m
Load 18 | Resistor | Ground | Q12 | 2 | 1,1368m | 9,6524m
Load 19 | Current | Power | U9 | 1 | 3,1687 | 100u
Load 19 | Current | Ground | U9 | 2 | 1,0522m | 100u
Load 42 | Current | Power | U11 | 4 | 3,1466 | 16,774m
Load 42 | Current | Power | U11 | 6 | 3,1465 | 16,762m
Load 42 | Current | Power | U11 | 18 | 3,1447 | 16,464m
Load 42 | Current | Ground | U11 | 3 | 1,1126m | 16,667m
Load 42 | Current | Ground | U11 | 5 | 1,1612m | 16,659m
Load 42 | Current | Ground | U11 | 21 | 1,0627m | 16,675m
Load 43 | Resistor | Power | R36 | 2 | 3,1456 | 314,4u
Load 43 | Resistor | Ground | U11 | 3 | 1,1126m | 104,86u
Load 43 | Resistor | Ground | U11 | 5 | 1,1612m | 104,86u
Load 43 | Resistor | Ground | U11 | 21 | 1,0627m | 104,87u
Load 44 | Resistor | Power | D2 | 4 | 3,1467 | 9,532m
Load 44 | Resistor | Ground | Q7 | 2 | 1,1072m | 9,532m
Load 45 | Resistor | Power | D2 | 4 | 3,1467 | 9,532m
Load 45 | Resistor | Ground | Q8 | 2 | 1,1062m | 9,532m
Load 46 | Resistor | Power | D2 | 4 | 3,1467 | 9,532m
Load 46 | Resistor | Ground | Q9 | 2 | 1,106m | 9,532m
Load 20 | Current | Power | J1 | 4 | 3,1881 | 30m
Load 20 | Current | Ground | J1 | 6 | 1,1258m | 30m
Load 21 | Resistor | Power | R38 | 2 | 3,1881 | 318,66u
Load 21 | Resistor | Ground | U12 | 8 | 1,059m | 159,39u
Load 21 | Resistor | Ground | U12 | 15 | 1,0474m | 159,39u
Load 22 | Resistor | Power | R39 | 2 | 3,1881 | 318,66u
Load 22 | Resistor | Ground | U12 | 8 | 1,059m | 159,39u
Load 22 | Resistor | Ground | U12 | 15 | 1,0474m | 159,39u
Load 23 | Resistor | Power | R40 | 2 | 3,1881 | 318,66u
Load 23 | Resistor | Ground | U12 | 8 | 1,059m | 159,39u
Load 23 | Resistor | Ground | U12 | 15 | 1,0474m | 159,39u
Load 24 | Resistor | Power | R41 | 2 | 3,1881 | 318,66u
Load 24 | Resistor | Ground | U12 | 8 | 1,059m | 159,39u
Load 24 | Resistor | Ground | U12 | 15 | 1,0474m | 159,39u
Load 25 | Current | Power | U12 | 16 | 3,1745 | 100u
Load 25 | Current | Ground | U12 | 8 | 1,059m | 49,996u
Load 25 | Current | Ground | U12 | 15 | 1,0474m | 50,005u
Load 26 | Current | Power | U13 | 2 | 3,1989 | 100u
Load 26 | Current | Ground | U13 | 11 | 1,0581m | 100u
Load 47 | Current | Power | U13 | 19 | 3,1456 | 100u
Load 47 | Current | Ground | U13 | 11 | 1,0581m | 100u
Load 27 | Current | Power | U14 | 12 | 3,1989 | 15m
Load 27 | Current | Ground | U14 | 5 | 1,0078m | 7,5006m
Load 27 | Current | Ground | U14 | 13 | 1,0191m | 7,4994m
Load 28 | Resistor | Power | R52 | 2 | 3,1314 | 313,07u
Load 28 | Resistor | Ground | U15 | 11 | 896,7u | 62,592u
Load 28 | Resistor | Ground | U15 | 32 | 974,2u | 62,583u
Load 28 | Resistor | Ground | U15 | 62 | 996,22u | 62,58u
Load 28 | Resistor | Ground | U15 | 81 | 941,96u | 62,587u
Load 28 | Resistor | Ground | U15 | 99 | 871,28u | 62,595u
Load 29 | Resistor | Power | R53 | 2 | 3,1314 | 313,07u
Load 29 | Resistor | Ground | U15 | 11 | 896,7u | 62,592u
Load 29 | Resistor | Ground | U15 | 32 | 974,2u | 62,583u
Load 29 | Resistor | Ground | U15 | 62 | 996,22u | 62,58u
Load 29 | Resistor | Ground | U15 | 81 | 941,96u | 62,587u
Load 29 | Resistor | Ground | U15 | 99 | 871,28u | 62,595u
Load 30 | Current | Power | U16 | 16 | 3,1314 | 9,6883m
Load 30 | Current | Power | U16 | 3 | 3,1398 | 10,312m
Load 30 | Current | Ground | U16 | 13 | 1,1003m | 4,9997m
Load 30 | Current | Ground | U16 | 2 | 1,0967m | 5m
Load 30 | Current | Ground | U16 | 8 | 1,0912m | 5,0004m
Load 30 | Current | Ground | U16 | 1 | 1,0984m | 4,9999m
Load 31 | Current | Power | U17 | 7 | 3,1394 | 100u
Load 31 | Current | Ground | U17 | 5 | 1,0866m | 100u
Load 32 | Resistor | Power | R57 | 2 | 3,139 | 9,5087m
Load 32 | Resistor | Ground | D4 | 1 | 1,0985m | 9,5087m
Load 33 | Resistor | Power | R56 | 2 | 3,1391 | 313,83u
Load 33 | Resistor | Ground | U15 | 11 | 896,7u | 62,744u
Load 33 | Resistor | Ground | U15 | 32 | 974,2u | 62,735u
Load 33 | Resistor | Ground | U15 | 62 | 996,22u | 62,732u
Load 33 | Resistor | Ground | U15 | 81 | 941,96u | 62,739u
Load 33 | Resistor | Ground | U15 | 99 | 871,28u | 62,747u
Load 34 | Resistor | Power | R54 | 2 | 3,139 | 313,85u
Load 34 | Resistor | Ground | U16 | 8 | 1,0912m | 313,74u
Load 35 | Resistor | Power | R55 | 2 | 3,139 | 313,83u
Load 35 | Resistor | Ground | U16 | 13 | 1,1003m | 78,416u
Load 35 | Resistor | Ground | U16 | 2 | 1,0967m | 78,417u
Load 35 | Resistor | Ground | U16 | 8 | 1,0912m | 78,418u
Load 35 | Resistor | Ground | U16 | 1 | 1,0984m | 78,417u
Load 36 | Resistor | Power | R58 | 2 | 3,1396 | 313,9u
Load 36 | Resistor | Ground | U16 | 8 | 1,0912m | 313,8u
Load 37 | Resistor | Power | R59 | 2 | 3,1396 | 313,9u
Load 37 | Resistor | Ground | U16 | 8 | 1,0912m | 313,79u
Load 38 | Current | Power | U18 | 5 | 3,1328 | 200u
Load 38 | Current | Ground | U18 | 2 | 1,0825m | 200u
Load 39 | Resistor | Power | R60 | 2 | 3,1314 | 313,09u
Load 39 | Resistor | Ground | U16 | 8 | 1,0912m | 312,98u
Load 40 | Resistor | Power | R61 | 2 | 3,1314 | 313,09u
Load 40 | Resistor | Ground | U16 | 8 | 1,0912m | 312,98u
Load 41 | Current | Power | U19 | 8 | 3,1314 | 400u
Load 41 | Current | Ground | U19 | 4 | 1,0956m | 400u

Series Element Performance Summary:

ID | Ref Des | Pass / Fail | Voltage (V) | Resistance (Ohms) | Max Current (A) | Actual Current (A) | Margin (A) | Margin (%) | Actual Voltage Drop (V)
Series 1 | U2 | PASS | 0 | 140m | 2 | 570,16m | 1,4298 | 71.49% | 79,82m
Series 2 | U10 | PASS | 0 | 140m | 2 | 79,01m | 1,921 | 96.05% | 11,06m

Series Element Pin Voltage/Current Details:

ID | Terminal | Ref Des | Pin | Pin Voltage (V) | Pin Current (A)
Series 1 | In | U2 | 1 | 3,2895 | 570,16m
Series 1 | Out | U2 | 6 | 3,2097 | 570,16m
Series 2 | In | U10 | 1 | 3,1628 | 79,01m
Series 2 | Out | U10 | 6 | 3,1517 | 79,01m

Component Definition Summary:

ID | Ref Des | Type | In+ Pins | In- Pins | Out+ Pins | Out- Pins | S+ | S- | Vout (V) | Efficiency (%) | Ibias (A) | Resistance | Load Current (A) | Vmin | Vmax | Iout max (A) | PD max (W) | Pin Current max (A)
Source 1 | U3 | SMPS
Load 1 | U17 | Current | U17-6 | U17-5 | | | | | | | | | 40n | 0 | 0
Load 2 | U6 | Current | U6-1 | U6-8,9,17 | | | | | | | | | 8u | 0 | 0
Load 3 | U7 | Current | U7-1 | U7-8,9,17 | | | | | | | | | 8u | 0 | 0
Load 4 | U8 | Current | U8-1 | U8-8,9,17 | | | | | | | | | 8u | 0 | 0
Load 5 | R13, U15 | Resistor | R13-2 | U15-11,32,62,81,99 | | | | | | | | 47K | | 0 | 0
Load 6 | R12, U6 | Resistor | R12-2 | U6-8,9,17 | | | | | | | | 47K | | 0 | 0
Load 7 | R14, U7 | Resistor | R14-2 | U7-8,9,17 | | | | | | | | 47K | | 0 | 0
Load 8 | R16, U8 | Resistor | R16-2 | U8-8,9,17 | | | | | | | | 47K | | 0 | 0
Load 9 | R15, U15 | Resistor | R15-2 | U15-11,32,62,81,99 | | | | | | | | 47K | | 0 | 0
Load 10 | R17, U15 | Resistor | R17-2 | U15-11,32,62,81,99 | | | | | | | | 47K | | 0 | 0
Load 11 | Q3, Q4 | Resistor | Q3-2 | Q4-2 | | | | | | | | 65 | | 0 | 0
Load 12 | Q3, Q5 | Resistor | Q3-2 | Q5-2 | | | | | | | | 22 | | 0 | 0
Load 13 | Q3, Q6 | Resistor | Q3-2 | Q6-2 | | | | | | | | 22 | | 0 | 0
Load 14 | R45, U15 | Resistor | R45-2 | U15-11,32,62,81,99 | | | | | | | | 10K | | 0 | 0
Load 15 | U15 | Current | U15-10,31,61,80,100 | U15-11,32,62,81,99 | | | | | | | | | 50m | 0 | 0
Load 16 | D3, Q10 | Resistor | D3-4 | Q10-2 | | | | | | | | 330 | | 0 | 0
Load 17 | D3, Q11 | Resistor | D3-4 | Q11-2 | | | | | | | | 330 | | 0 | 0
Load 18 | D3, Q12 | Resistor | D3-4 | Q12-2 | | | | | | | | 330 | | 0 | 0
Load 19 | U9 | Current | U9-1 | U9-2 | | | | | | | | | 35n | 0 | 0
Load 42 | U11 | Current | U11-4,6,18 | U11-3,5,21 | | | | | | | | | 50m | 0 | 0
Load 43 | R36, U11 | Resistor | R36-2 | U11-3,5,21 | | | | | | | | 10K | | 0 | 0
Load 44 | D2, Q7 | Resistor | D2-4 | Q7-2 | | | | | | | | 330 | | 0 | 0
Load 45 | D2, Q8 | Resistor | D2-4 | Q8-2 | | | | | | | | 330 | | 0 | 0
Load 46 | D2, Q9 | Resistor | D2-4 | Q9-2 | | | | | | | | 330 | | 0 | 0
Load 20 | J1 | Current | J1-4 | J1-6 | | | | | | | | | 30m | 0 | 0
Load 21 | R38, U12 | Resistor | R38-2 | U12-8,15 | | | | | | | | 10K | | 0 | 0
Load 22 | R39, U12 | Resistor | R39-2 | U12-8,15 | | | | | | | | 10K | | 0 | 0
Load 23 | R40, U12 | Resistor | R40-2 | U12-8,15 | | | | | | | | 10K | | 0 | 0
Load 24 | R41, U12 | Resistor | R41-2 | U12-8,15 | | | | | | | | 10K | | 0 | 0
Load 25 | U12 | Current | U12-16 | U12-8,15 | | | | | | | | | 68u | 0 | 0
Load 26 | U13 | Current | U13-2 | U13-11 | | | | | | | | | 2u | 0 | 0
Load 47 | U13 | Current | U13-19 | U13-11 | | | | | | | | | 6u | 0 | 0
Load 27 | U14 | Current | U14-12 | U14-5,13 | | | | | | | | | 15m | 0 | 0
Load 28 | R52, U15 | Resistor | R52-2 | U15-11,32,62,81,99 | | | | | | | | 10K | | 0 | 0
Load 29 | R53, U15 | Resistor | R53-2 | U15-11,32,62,81,99 | | | | | | | | 10K | | 0 | 0
Load 30 | U16 | Current | U16-3,16 | U16-1,2,8,13 | | | | | | | | | 20m | 0 | 0
Load 31 | U17 | Current | U17-7 | U17-5 | | | | | | | | | 40n | 0 | 0
Load 32 | R57, D4 | Resistor | R57-2 | D4-1 | | | | | | | | 330 | | 0 | 0
Load 33 | R56, U15 | Resistor | R56-2 | U15-11,32,62,81,99 | | | | | | | | 10K | | 0 | 0
Load 34 | R54, U16 | Resistor | R54-2 | U16-8 | | | | | | | | 10K | | 0 | 0
Load 35 | R55, U16 | Resistor | R55-2 | U16-1,2,8,13 | | | | | | | | 10K | | 0 | 0
Load 36 | R58, U16 | Resistor | R58-2 | U16-8 | | | | | | | | 10K | | 0 | 0
Load 37 | R59, U16 | Resistor | R59-2 | U16-8 | | | | | | | | 10K | | 0 | 0
Load 38 | U18 | Current | U18-5 | U18-2 | | | | | | | | | 200u | 1,62 | 5,25
Load 39 | R60, U16 | Resistor | R60-2 | U16-8 | | | | | | | | 10K | | 0 | 0
Load 40 | R61, U16 | Resistor | R61-2 | U16-8 | | | | | | | | 10K | | 0 | 0
Load 41 | U19 | Current | U19-8 | U19-4 | | | | | | | | | 400u | 2,5 | 5,5
Series 1 | U2 | Series | U2-1 | | U2-6 | | | | 0 | | | 140m | | | | 2 | | 2
Series 2 | U10 | Series | U10-1 | | U10-6 | | | | 0 | | | 140m | | | | 2 | | 2

Network Simulation Messages Details

Type | Text
Info | Generated the settings file: C:\Altium Projects\B100\[AA]\Design Files\B100AA\PDNAnalyzer_Output\B100AA PCB R1\B100AA R4\B100AA PCB R1.py
Info | Simulation Progress: 10%
Info | Simulation Progress: 99,16%
Info | Simulation Progress: 99,91%
Info | Simulation Progress: 100%
Info | Load and analyze result for B100AA R4
Info | Found violations
Info | Analysis Complete B100AA R4
Info | No violations

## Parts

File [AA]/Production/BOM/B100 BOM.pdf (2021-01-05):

### Resistor (Passive)

References | Value | Part ID | Power | Tolerance | Package | Supplier | Qty / Pc
R1 | | CRCW0402100KFKED | | | | Yageo | 1
R11, R12, R25, R26, R27, R35, R36, R37, R38, R42, R43, R44, R45, R46, R47, R49, R50 | | CRCW040210K0FKEDHP | | | | Vishay Dale | 17
R2 | | CRCW0402390KFKED | | | | Vishay | 1
R23 | | CRCW0402249KFKED | | | | Vishay | 1
R3 | | CRCW040291K0FKED | | | | Vishay | 1
R4, R6, R18, R19, R20, R30, R31, R32, R39, R48, R59, R60, R62 | | CRCW0402330RFKED | | | | Vishay | 13
R5, R7, R10, R13, R14, R16, R17, R21, R22, R24, R28, R29, R33, R34, R40, R41, R61, R63, R64 | | CRCW040247K0FKEDHP | | | | Vishay Dale | 19
R8, R9, R15 | | CRCW04020000Z0ED | | | | Vishay | 3
| | | | | | Quantity | 56

### Capacitor (Passive)

References | Value | Part ID | Voltage | Tolerance | Package | Supplier | Qty / Pc
C2, C5, C7, C8, C13, C19, C23, C25, C36, C37, C55, C56, C106, C108, C109, C110, C111, C112, C115, C116, C117, C126, C127, C128, C131, C132, C133, C136, C137, C140, C141, C142, C150, C151, C152, C153 | 100 nF | 04026D104KAT4A | 6V3 | | | Kyocera AVX | 36
C1, C6, C11, C12, C14, C17, C18, C20, C21, C22, C26, C27, C28, C29, C30, C31, C34, C35, C38, C39, C40, C41, C42, C43, C44, C45, C47, C48, C49, C50, C51, C52, C53, C54, C57, C58, C59, C60, C61, C62, C63, C64, C65, C66, C67, C68, C69, C70, C71, C72, C73, C74, C75, C76, C77, C78, C79, C80, C81, C82, C83, C84, C85, C86, C87, C88, C89, C90, C91, C92, C93, C94, C95, C96, C97, C98, C99, C100, C101, C102, C103, C104, C105, C107, C118, C119, C120, C121, C122, C123, C124, C125, C129, C130, C134, C135, C154, C155, C156 | | C0402C330J9RACAUTO | | | | KEMET | 99
C10, C16 | | GRM153R60J105ME95D | | | | Murata | 2
C113, C114, C138, C139 | | CBR04C130F5GAC | | | | KEMET | 4
C15 | | F380J476MMAAXEH3 | | | | Kyocera AVX | 1
C3, C4 | | 16SVPC39MV | | | | Panasonic | 2
C32 | | 04026C474KAT2A | | | | Kyocera AVX | 1
C33, C46 | | 04026C102MAT2A | | | | Kyocera AVX | 2
C9, C24 | | F380J106MMAAH3 | | | | Kyocera AVX | 2
| | | | | | Quantity | 149

### Fuse (Passive)

References | Value | Part ID | Voltage | Current | Package | Supplier | Qty / Pc
Quantity | 0

### Diode (Active)

References | Value | Part ID | Voltage | Current | Package | Supplier | Qty / Pc
D1, D2, D5 | | 150066M153000 | | | | Wurth Electronics | 3
D3 | | SMLP13BC8TT86 | | | | Rohm | 1
| | | | | | Quantity | 4

### Transistor (Active)

References | Value | Part ID | Polarity | Current | Package | Supplier | Qty / Pc
Q1, Q2, Q3, Q4, Q5, Q6, Q7, Q8, Q9, Q10, Q14, Q15, Q16 | | BC847AQAZ | | | | Nexperia | 13
| | | | | | Quantity | 13

### Oscillator (Active)

References | Value | Part ID | Freq. | Tolerance | Package | Supplier | Qty / Pc
X1, X2 | | ABMM2-7.3728MHZ-E2-T | 7,3728 | | | Abracon | 2
| | | | | | Quantity | 2

### Inductor (Passive)

References | Value | Part ID | Imp. | Tolerance | Package | Supplier | Qty / Pc
FB1, FB2 | | BLM18EG101TZ1D | | | | Murata | 2
L1 | | 7443551130 | | | | Wurth Electronics | 1
L2, L3 | | LQG15HN1N0S02D | | | | Murata | 2
| | | | | | Quantity | 5

### IC (Active)

References | Value | Part ID | Package | Supplier | Qty / Pc
U1 | | TPS63802DLAT | | Texas Instruments | 1
U10 | | TPL5111DDCT | | Texas Instruments | 1
U11 | | TCA9546APWR | | Texas Instruments | 1
U12 | | ATMEGA328P-AU | | Microchip / Atmel | 1
U14 | | SN3257QPWRQ1 | | Texas Instruments | 1
U15 | | DS28CM00R-A00+T | | Maxim | 1
U16 | | 203591-MG01 | | Micro Crystal | 1

U17 | 24LC128T-I/SN | Microchip | 1
U19 | PAM8904EGPR | Diodes | 1
U2, U3, U21 | TPS22917DBVR | Texas Instruments | 3
U4 | TLV75533PDBVR | Texas Instruments | 1
U5 | | | 1
U6 | | | 1
U7, U13 | TXS0108EPWR | Texas Instruments | 2
U8 | TXS0101DBVR | Texas Instruments | 1
U9 | ATMEGA2560V-8AU | Microchip | 1
| | Quantity | 19

### Connectors

References | Type | Part ID | Package | Supplier | Qty / Pc
RF1 | | RSP-122811-01 | | Samtec | 1
J1 | | 472192001 | | Molex | 1
J2, J3 | | FTSH-130-01-F-DV | | Samtec | 2
| | | | Quantity | 4

### Mechanical

References | Type | Part ID | Package | Supplier | Qty / Pc
PZ1 | | PKMCS0909E4000-R1 | | Murata | 1
| | | | Quantity | 1

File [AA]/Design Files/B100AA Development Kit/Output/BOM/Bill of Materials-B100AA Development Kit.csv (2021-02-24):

Designator | Quantity | Description | Footprint | Case | Manufacturer _Part_Number | Manufacturer Name | Manufacturer Part Number | Manufacturer_Name | Manufacturer_Part_Number
C1, C2, C3, C4, C5, C6, C8, C9, C15, C16, C17, C18, C19, C20, C21, C23, C25, C26, C27, C28, C29, C30, C31, C32, C33, C34, C35, C36, C38, C39, C40, C41, C42, C43, C44, C45, C47, C48, C49, C50, C51, C52, C53, C54, C55, C56, C57, C58, C60, C61, C62, C63, C64, C65, C66, C67, C68, C69, C70, C71, C72, C73, C74, C75, C76, C77, C78, C79, C80, C81, C82, C83, C84, C85, C86, C87, C88, C89, C90, C91, C92, C93, C94, C95, C96, C98, C101, C102, C103, C104, C105, C106, C107, C109, C111, C112, C113, C115, C116, C117, C118, C119, C120, C129, C130, C147, C148 | 107 | Capacitor - 33pF [0402] (Ceramic) | CAPACITOR_0402 | 0402 |  | Kemet | C0402C330J9RACAUTO
C7, C10, C22, C24, C37, C46, C97, C99, C100, C108, C110, C114, C133, C134, C137, C138, C141, C142, C145, C146 | 20 | Capacitor - 33pF [0402] (Ceramic) | CAPACITOR_0402 | 0402 |  |  |  | Kemet | C0402C330J9RACAUTO
C11, C13, C14, C121, C122, C123, C124, C125, C126, C127, C128, C132, C136, C140, C144 | 15 | Capacitor - 100nF [0402-6V3] (Ceramic) | CAPACITOR_0402 | 0402 |  |  |  | AVX | 04026D104KAT4A
C12 | 1 | Capacitor - 10uF [0402] (Ceramic) | CAPACITOR_0402 | 0402 |  | Kemet | C0402C106M9PACTU
C59 | 1 | Capacitor - 470nF [0402] (Ceramic) | CAPACITOR_0402 | 0402 |  | AVX | 04026C474KAT2A
C131, C135, C139, C143 | 4 | Capacitor - 4.7uF [0402] (Ceramic) | CAPACITOR_0402 | 0402 |  |  |  | Kemet | C0402C475M9PACTU
D1, D2, D3, D4, D5, D6, D7, D8, D9, D10, D11, D12, D13, D14, D15, D16, D17, D18, D19, D20, D21, D22, D23, D24, D25, D26, D27, D28, D29, D30, D31, D32, D33, D34, D35, D36, D37, D38, D39, D40, D41, D42, D43, D44, D45, D46, D47, D48, D49, D50, D51, D52, D53, D54, D55, D56, D57, D58, D59, D60, D61, D62, D63, D64, D65, D66, D67, D68, D69, D70, D71, D72, D73 | 73 | Standard LEDs - SMD PICOLEDTM;BLUE LED; 25M @ 5MA | LED_0402 | 0402 |  |  |  | ROHM Semiconductor | SMLP13BC8TT86
J1 | 1 | Fixed Terminal Blocks Terminal block, screwless, 3.50, 45 , 2 poles, cool gray | TBL002A-350-02GY-2GY |  |  | CUI Devices | TBL002A-350-02GY-2GY
J2, J3, J4, J8, J10, J14, J15, J17, J19 | 9 | Headers & Wire Housings BREAKAWAY HDR VERT 8 | 8P Header |  |  | Molex | 22-28-4083
J5, J6, J16, J18 | 4 | Mini Tunic Connector with 6P | Connector_Tunic 6P - H |  |  |  |  | Molex | 53261-0671
J7, J12 | 2 | Headers & Wire Housings BREAKAWAY HDR VERT 60 | SAMTEC-CLP-130-02-X-D |  |  | Samtec | CLP-130-02-F-D
J9 | 1 | Memory Card Connectors ASSY 1.90 SIM CARD R IM CARD READER CONN. | Connector - SIM Tray |  |  |  |  | Molex | 47388-2001
J11, J13, J20 | 3 | Headers & Wire Housings BREAKAWAY HDR VERT 6 | 6P Header |  |  | Molex | 22-28-4063
J21, J22, J23, J24 | 4 | USB Connectors MINI B RECEPT RA SMT W/ POST | USB Micro B Female - Vertical | SMD |  |  |  | Molex | 105133-0011
Q1, Q2, Q3, Q4, Q5, Q6, Q7, Q8, Q9, Q10, Q11, Q12, Q13, Q14, Q15, Q16, Q17, Q18, Q19, Q20, Q21, Q22, Q23, Q24, Q25, Q26, Q27, Q28, Q29, Q30, Q31, Q32, Q33, Q34, Q35, Q36, Q37, Q38, Q39, Q40, Q41, Q42, Q43, Q44, Q45, Q46, Q47, Q48, Q49, Q50, Q51, Q52, Q53, Q54, Q55, Q56, Q57, Q58, Q59, Q60, Q61, Q62, Q63, Q64, Q65 | 65 | Bipolar Transistors - BJT BC847AQA/DFN1010D-3/REEL 7" Q2 | SOT1215 | DFN-1010D-3 |  |  |  | Nexperia | BC847AQAZ
R1, R3, R4, R6, R7, R10, R12, R13, R40, R42, R43, R45, R46, R48, R49, R51, R68, R70, R71, R73, R74, R77, R79, R81, R103, R105, R106, R108, R109, R111, R112, R113, R130, R132, R133, R135, R136, R141, R142, R143 | 40 | Thick Film Resistors - SMD 1/16 W 47 Kohms 1% | RESISTOR_0402 | 0402 |  | Vishay | CRCW040247K0FKED
R2, R5, R8, R9, R14, R17, R20, R23, R25, R27, R31, R32, R34, R35, R36, R37, R38, R39, R41, R44, R47, R52, R53, R54, R57, R60, R63, R66, R69, R72, R75, R76, R78, R80, R82, R83, R84, R85, R88, R90, R92, R93, R95, R97, R99, R100, R102, R104, R107, R110, R114, R115, R118, R120, R121, R122, R124, R128, R131, R134, R137, R138, R139, R140, R144, R145, R152, R159, R163 | 69 | Thick Film Resistors - SMD 1/16 W 330 Ohm 1% | RESISTOR_0402 | 0402 |  | Vishay | CRCW0402330RFKED
R11, R28, R29, R50, R64 | 5 | Thick Film Resistors - SMD 1/16 W 47 Kohms 1% | RESISTOR_0402 | 0402 |  |  |  | Vishay | CRCW040247K0FKED
R15, R16 | 2 | Thick Film Resistors - SMD 1/16 W 249 Kohms 1% | RESISTOR_0402 | 0402 |  |  |  | Vishay | CRCW0402249KFKED
R18, R19, R21, R22, R24, R26, R30, R33, R55, R56, R58, R59, R61, R62, R65, R67, R86, R87, R89, R91, R94, R96, R98, R101, R116, R117, R119, R123, R125, R126, R127, R129, R146, R147, R157, R158, R160, R161, R162, R164 | 40 | Thick Film Resistors - SMD 1/16 W 1.0 Kohms 1% | RESISTOR_0402 | 0402 |  | Vishay | CRCW04021K00FKED
R148, R149, R150, R151 | 4 | Thick Film Resistors - SMD 1/16 W 330 Ohm 1% | RESISTOR_0402 | 0402 |  |  |  | Vishay | CRCW0402330RFKED
R153, R154, R155, R156 | 4 | Thick Film Resistors - SMD 1/16 W 10 Kohms 1% | RESISTOR_0402 | 0402 |  |  |  | Vishay | CRCW040210K0FKED
SW1, SW4, SW5, SW7, SW8, SW9, SW11, SW12, SW14, SW15, SW16, SW18, SW19, SW20, SW21, SW22, SW23, SW25, SW26, SW27, SW28, SW30, SW31, SW32, SW33, SW35, SW36, SW37, SW38, SW40, SW41, SW42, SW43, SW45, SW49, SW50, SW51, SW53, SW54, SW55, SW56, SW57, SW58, SW60, SW61, SW62 | 46 | Tactile Switches 50mA 12VDC, 5.2x5.2mm, 0.8mm H, 260gf, G leads. | PTS526_Switch |  |  | C&K Switches | PTS526 SK08 SMTR2 LFS
SW2, SW10, SW17, SW24, SW29, SW34, SW39, SW44, SW52, SW59 | 10 | DIP Switches/SIP Switches TRI-STATE DIP 8P G RAISED T&R | TDS08SGNNTR04 |  |  | TE Connectivity | TDS08SGNNTR04
SW3, SW6, SW13, SW46, SW47, SW48 | 6 | DIP Switches/SIP Switches DIP Switch, SPST, 2.54 pitch, flat actuator, SMT, Tape and reel, 1 position, Black | DS04-254-2-01BK-SMT-TR |  |  | CUI Devices | DS04-254-2-01BK-SMT-TR
U1 | 1 | LDO Voltage Regulators 800MA LDO LINEAR REG | SOT-223-4 | SOT-223-4 |  | Texas Instruments | LM1117MPX-3.3/NOPB
U2 | 1 | Timers & Support Products Ultra Low Power System Timer (35 nA) for Power Gating in duty cycled applications. | SOT-23-6 |  | TPL5111DDCT |  |  | Texas Instruments
U3, U4, U5, U6 | 4 | USB/UART IC | DFN-12 |  |  |  |  | FTDI Chip | FT234XD-R

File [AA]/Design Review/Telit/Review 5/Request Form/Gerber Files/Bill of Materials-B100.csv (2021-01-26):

Description | Designator | Quantity | Case | Mouser_Part_Number | Tolerance | Value | Manufacturer Part Number | Manufacturer_Part_Number
Crystals 7.3728MHz 18pF -40C +85C | X2 | 1 |  |  | 20 ppm |  | ABMM2-7.3728MHZ-E2-T
Crystals 7.3728MHz 18pF -40C +85C | X1 | 1 |  |  | 20 ppm |  | ABMM2-7.3728MHZ-E2-T
Switching Voltage Regulators High current, high efficiency single inductor buck-boost converter 10-VSON-HR -40 to 125 | U22 | 1 | VSON-10 | 595-TPS63802DLAT |  |  |  | TPS63802DLAT
Switching Voltage Regulators High current, high efficiency single inductor buck-boost converter 10-VSON-HR -40 to 125 | U21 | 1 | VSON-10 | 595-TPS63802DLAT |  |  |  | TPS63802DLAT
Analog to Digital Converters - ADC 18B delta-sigma ADC dual Ch 4sps | U20 | 1 | DFN-8 | 579-MCP3422A0-E/MC |  |  |  | MCP3422A0-E/MC
EEPROM | U19 | 1 | SOIC-8 |  |  |  | 24LC128T-I/SN
Security ICs / Authentication ICs I C/SMBus Silicon Serial Number | U18 | 1 | SOT-23-5 | 700-DS28CM00R-A00T |  |  |  | DS28CM00R-A00+T
Real Time Clock 32.768kHz I2C Time Acc. 1ppm | U17 | 1 | SMD | 428-203591-MG01 |  |  |  | RV-3028-C7
Switch ICs - Various 4-Channel I2C and SMBus | U16 | 1 | TSSOP-16 |  |  |  |  | TCA9546APWR
8-bit Microcontrollers - MCU 256kB Flash 4kB EEPROM 86 I/O Pins | U15 | 1 | TQFP-100 | 556-ATMEGA2560V8AU |  |  |  | ATMEGA2560V-8AU
Audio Amplifiers Audio High Volt | U14 | 1 | VQFN2020-12 | 621-PAM8904EGPR |  |  |  | PAM8904EGPR
Translation - Voltage Levels 8B Bidir Vltg-Level Translator | U13 | 1 | TSSOP-20 |  |  |  | TXS0108EPWR
Analogue Switch ICs 2:1 (SPDT), 4-channel switch with 1.8-V logic 16-TSSOP -40 to 125 | U12 | 1 | TSSOP-16 |  |  |  |  | SN3257QPWRQ1
8-bit Microcontrollers - MCU 32KB In-system Flash 20MHz 1.8V-5.5V | U11 | 1 | TQFP-32 | 556-ATMEGA328P-AU |  |  |  | ATMEGA328P-AU
Power Switch MosFet | U10 | 1 |  | 595-TPS22917DBVR |  |  |  | TPS22917DBVR
Timers & Support Products Ultra Low Power System Timer (35 nA) for Power Gating in duty cycled applications. | U9 | 1 |  | 595-TPL5111DDCT
Translation - Voltage Levels Low Power Dual Channel | U8 | 1 | VQFN-16 |  |  |  | SN74AVCH4T245RGYR
Translation - Voltage Levels Low Power Dual Channel | U7 | 1 | VQFN-16 |  |  |  | SN74AVCH4T245RGYR
Translation - Voltage Levels Low Power Dual Channel | U6 | 1 | VQFN-16 |  |  |  | SN74AVCH4T245RGYR
SIM Chip MFF2 | U5 | 1
Telit GE910 GPRS/UMTS Module | U4 | 1 |  |  |  | GE910QUAD
LDO Voltage Regulators 500-mA low-IQ small-size low-dropout (LDO) regulator. | U3 | 1 | SOT-23-5 | 595-TLV75533PDBVR |  |  |  | TLV75533PDBVR
Power Switch MosFet | U2 | 1 |  | 595-TPS22917DBVR |  |  |  | TPS22917DBVR
Power Switch MosFet | U1 | 1 |  | 595-TPS22917DBVR |  |  |  | TPS22917DBVR
MHF Antenna Socket | RF1 | 1
Thick Film Resistors - SMD 1/16 W 91 Kohms 1% | R70 | 1 | 0402 |  | %1 | 91K | CRCW040291K0FKED
Thick Film Resistors - SMD 1/16 W 47 Kohms 1% | R69 | 1 | 0402 |  | %1 | 47K | CRCW040247K0FKED
Thick Film Resistors - SMD 1/16 W 806 Kohms 1% | R68 | 1 | 0402 |  | %1 | 806K | CRCW0402806KFKED
Thick Film Resistors - SMD 1/16 W 100 Kohms 1% | R67 | 1 | 0402 |  | %1 | 100K | CRCW0402100KFKED
Thick Film Resistors - SMD 1/16 W 91 Kohms 1% | R66 | 1 | 0402 |  | %1 | 91K | CRCW040291K0FKED
Thick Film Resistors - SMD 1/16 W 604 Kohms 1% | R65 | 1 | 0402 |  | %1 | 604K | CRCW0402604KFKED
Thick Film Resistors - SMD 1/16 W 100 Kohms 1% | R64 | 1 | 0402 |  | %1 | 100K | CRCW0402100KFKED
Thick Film Resistors - SMD 1/16 W 10 Kohms 1% | R63 | 1 | 0402 |  | %1 | 10K | CRCW040210K0FKED
Thick Film Resistors - SMD 1/16 W 10 Kohms 1% | R62 | 1 | 0402 |  | %1 | 10K | CRCW040210K0FKED
Thick Film Resistors - SMD 1/16 W 10 Kohms 1% | R61 | 1 | 0402 |  | %1 | 10K | CRCW040210K0FKED
Thick Film Resistors - SMD 1/16 W 10 Kohms 1% | R60 | 1 | 0402 |  | %1 | 10K | CRCW040210K0FKED
Thick Film Resistors - SMD 1/16 W 10 Kohms 1% | R59 | 1 | 0402 |  | %1 | 10K | CRCW040210K0FKED
Thick Film Resistors - SMD 1/16 W 10 Kohms 1% | R58 | 1 | 0402 |  | %1 | 10K | CRCW040210K0FKED
Thick Film Resistors - SMD 1/16 W 330 Ohm 1% | R57 | 1 | 0402 |  | %1 | 330R | CRCW0402330RFKED
Thick Film Resistors - SMD 1/16 W 10 Kohms 1% | R56 | 1 | 0402 |  | %1 | 10K | CRCW040210K0FKED
Thick Film Resistors - SMD 1/16 W 10 Kohms 1% | R55 | 1 | 0402 |  | %1 | 10K | CRCW040210K0FKED
Thick Film Resistors - SMD 1/16 W 10 Kohms 1% | R54 | 1 | 0402 |  | %1 | 10K | CRCW040210K0FKED
Thick Film Resistors - SMD 1/16 W 10 Kohms 1% | R53 | 1 | 0402 |  | %1 | 10K | CRCW040210K0FKED
Thick Film Resistors - SMD 1/16 W 10 Kohms 1% | R52 | 1 | 0402 |  | %1 | 10K | CRCW040210K0FKED
Thick Film Resistors - SMD 1/16 W 47 Kohms 1% | R51 | 1 | 0402 |  | %1 | 47K | CRCW040247K0FKED
Thick Film Resistors - SMD 1/16 W 330 Ohm 1% | R50 | 1 | 0402 |  | %1 | 330R | CRCW0402330RFKED
Thick Film Resistors - SMD 1/16 W 47 Kohms 1% | R49 | 1 | 0402 |  | %1 | 47K | CRCW040247K0FKED
Thick Film Resistors - SMD 1/16 W 330 Ohm 1% | R48 | 1 | 0402 |  | %1 | 330R | CRCW0402330RFKED
Thick Film Resistors - SMD 1/16 W 47 Kohms 1% | R47 | 1 | 0402 |  | %1 | 47K | CRCW040247K0FKED
Thick Film Resistors - SMD 1/16 W 330 Ohm 1% | R46 | 1 | 0402 |  | %1 | 330R | CRCW0402330RFKED
Thick Film Resistors - SMD 1/16 W 10 Kohms 1% | R45 | 1 | 0402 |  | %1 | 10K | CRCW040210K0FKED
Thick Film Resistors - SMD 1/16 W 47 Kohms 1% | R44 | 1 | 0402 |  | %1 | 47K | CRCW040247K0FKED
Thick Film Resistors - SMD 1/16 W 47 Kohms 1% | R43 | 1 | 0402 |  | %1 | 47K | CRCW040247K0FKED
Thick Film Resistors - SMD 1/16 W 47 Kohms 1% | R42 | 1 | 0402 |  | %1 | 47K | CRCW040247K0FKED
Thick Film Resistors - SMD 1/16 W 10 Kohms 1% | R41 | 1 | 0402 |  | %1 | 10K | CRCW040210K0FKED
Thick Film Resistors - SMD 1/16 W 10 Kohms 1% | R40 | 1 | 0402 |  | %1 | 10K | CRCW040210K0FKED
Thick Film Resistors - SMD 1/16 W 10 Kohms 1% | R39 | 1 | 0402 |  | %1 | 10K | CRCW040210K0FKED
Thick Film Resistors - SMD 1/16 W 10 Kohms 1% | R38 | 1 | 0402 |  | %1 | 10K | CRCW040210K0FKED
Thick Film Resistors - SMD 1/16 W 47 Kohms 1% | R37 | 1 | 0402 |  | %1 | 47K | CRCW040247K0FKED
Thick Film Resistors - SMD 1/16 W 10 Kohms 1% | R36 | 1 | 0402 |  | %1 | 10K | CRCW040210K0FKED
Thick Film Resistors - SMD 1/16 W 47 Kohms 1% | R35 | 1 | 0402 |  | %1 | 47K | CRCW040247K0FKED
Thick Film Resistors - SMD 1/16 W 330 Ohm 1% | R34 | 1 | 0402 |  | %1 | 330R | CRCW0402330RFKED
Thick Film Resistors - SMD 1/16 W 47 Kohms 1% | R33 | 1 | 0402 |  | %1 | 47K | CRCW040247K0FKED
Thick Film Resistors - SMD 1/16 W 330 Ohm 1% | R32 | 1 | 0402 |  | %1 | 330R | CRCW0402330RFKED
Thick Film Resistors - SMD 1/16 W 330 Ohm 1% | R31 | 1 | 0402 |  | %1 | 330R | CRCW0402330RFKED
Thick Film Resistors - SMD 1/16 W 47 Kohms 1% | R30 | 1 | 0402 |  | %1 | 47K | CRCW040247K0FKED
Thick Film Resistors - SMD 1/16 W 47 Kohms 1% | R29 | 1 | 0402 |  | %1 | 47K | CRCW040247K0FKED
Thick Film Resistors - SMD 1/16 W 249 Kohms 1% | R28 | 1 | 0402 |  | %1 | 249K | CRCW0402249KFKED
Thick Film Resistors - SMD 1/16 W 330 Ohm 1% | R27 | 1 | 0402 |  | %1 | 330R | CRCW0402330RFKED
Thick Film Resistors - SMD 1/16 W 47 Kohms 1% | R26 | 1 | 0402 |  | %1 | 47K | CRCW040247K0FKED
Thick Film Resistors - SMD 1/16 W 47 Kohms 1% | R25 | 1 | 0402 |  | %1 | 47K | CRCW040247K0FKED
Thick Film Resistors - SMD 1/16 W 4.7 Kohms 1% | R24 | 1 | 0402 |  | %1 | 4K7 | CRCW04024K70FKED
Thick Film Resistors - SMD 1/16 W 4.7 Kohms 1% | R23 | 1 | 0402 |  | %1 | 4K7 | CRCW04024K70FKED
Thick Film Resistors - SMD 1/16 W 4.7 Kohms 1% | R22 | 1 | 0402 |  | %1 | 4K7 | CRCW04024K70FKED
Thick Film Resistors - SMD 1/16 W 22R Ohms 1% | R21 | 1 | 0402 |  | %1 | 22R | CRCW040222R0FKED
Thick Film Resistors - SMD 1/16 W 22R Ohms 1% | R20 | 1 | 0402 |  | %1 | 22R | CRCW040222R0FKED
Thick Film Resistors - SMD 1/16 W 64R9 Ohms 1% | R19 | 1 | 0402 |  | %1 | 64R9 | CRCW040264R9FKED
Thick Film Resistors - SMD 1/16 W 4.7 Kohms 1% | R18 | 1 | 0402 |  | %1 | 4K7 | CRCW04024K70FKED
Thick Film Resistors - SMD 1/16 W 47 Kohms 1% | R17 | 1 | 0402 |  | %1 | 47K | CRCW040247K0FKED
Thick Film Resistors - SMD 1/16 W 47 Kohms 1% | R16 | 1 | 0402 |  | %1 | 47K | CRCW040247K0FKED
Thick Film Resistors - SMD 1/16 W 47 Kohms 1% | R15 | 1 | 0402 |  | %1 | 47K | CRCW040247K0FKED
Thick Film Resistors - SMD 1/16 W 47 Kohms 1% | R14 | 1 | 0402 |  | %1 | 47K | CRCW040247K0FKED
Thick Film Resistors - SMD 1/16 W 47 Kohms 1% | R13 | 1 | 0402 |  | %1 | 47K | CRCW040247K0FKED
Thick Film Resistors - SMD 1/16 W 47 Kohms 1% | R12 | 1 | 0402 |  | %1 | 47K | CRCW040247K0FKED
Thick Film Resistors - SMD 1/16 W 47 Kohms 1% | R11 | 1 | 0402 |  | %1 | 47K | CRCW040247K0FKED
Thick Film Resistors - SMD 1/16 W 47 Kohms 1% | R10 | 1 | 0402 |  | %1 | 47K | CRCW040247K0FKED
Thick Film Resistors - SMD 1/16 W 10 Kohms 1% | R9 | 1 | 0402 |  | %1 | 10K | CRCW040210K0FKED
Thick Film Resistors - SMD 1/16 W 10 Kohms 1% | R8 | 1 | 0402 |  | %1 | 10K | CRCW040210K0FKED
Thick Film Resistors - SMD 1/16 W 0 Ohms | R7 | 1 | 0402 |  |  | 0R | CRCW04020000Z0ED
Thick Film Resistors - SMD 1/16 W 0 Ohms | R6 | 1 | 0402 |  |  | 0R | CRCW04020000Z0ED
Thick Film Resistors - SMD 1/16 W 0 Ohms | R5 | 1 | 0402 |  |  | 0R | CRCW04020000Z0ED
Thick Film Resistors - SMD 1/16 W 47 Kohms 1% | R4 | 1 | 0402 |  | %1 | 47K | CRCW040247K0FKED
Thick Film Resistors - SMD 1/16 W 330 Ohm 1% | R3 | 1 | 0402 |  | %1 | 330R | CRCW0402330RFKED
Thick Film Resistors - SMD 1/16 W 47 Kohms 1% | R2 | 1 | 0402 |  | %1 | 47K | CRCW040247K0FKED
Thick Film Resistors - SMD 1/16 W 330 Ohm 1% | R1 | 1 | 0402 |  | %1 | 330R | CRCW0402330RFKED
Bipolar Transistors - BJT BC847AQA/DFN1010D-3/REEL 7" Q2 | Q13 | 1 | DFN-1010D-3 | 771-BC847AQAZ |  |  |  | BC847AQAZ
Bipolar Transistors - BJT BC847AQA/DFN1010D-3/REEL 7" Q2 | Q12 | 1 | DFN-1010D-3 | 771-BC847AQAZ |  |  |  | BC847AQAZ
Bipolar Transistors - BJT BC847AQA/DFN1010D-3/REEL 7" Q2 | Q11 | 1 | DFN-1010D-3 | 771-BC847AQAZ |  |  |  | BC847AQAZ
Bipolar Transistors - BJT BC847AQA/DFN1010D-3/REEL 7" Q2 | Q10 | 1 | DFN-1010D-3 | 771-BC847AQAZ |  |  |  | BC847AQAZ
Bipolar Transistors - BJT BC847AQA/DFN1010D-3/REEL 7" Q2 | Q9 | 1 | DFN-1010D-3 | 771-BC847AQAZ |  |  |  | BC847AQAZ
Bipolar Transistors - BJT BC847AQA/DFN1010D-3/REEL 7" Q2 | Q8 | 1 | DFN-1010D-3 | 771-BC847AQAZ |  |  |  | BC847AQAZ
Bipolar Transistors - BJT BC847AQA/DFN1010D-3/REEL 7" Q2 | Q7 | 1 | DFN-1010D-3 | 771-BC847AQAZ |  |  |  | BC847AQAZ
Bipolar Transistors - BJT BC847AQA/DFN1010D-3/REEL 7" Q2 | Q6 | 1 | DFN-1010D-3 | 771-BC847AQAZ |  |  |  | BC847AQAZ
Bipolar Transistors - BJT BC847AQA/DFN1010D-3/REEL 7" Q2 | Q5 | 1 | DFN-1010D-3 | 771-BC847AQAZ |  |  |  | BC847AQAZ
Bipolar Transistors - BJT BC847AQA/DFN1010D-3/REEL 7" Q2 | Q4 | 1 | DFN-1010D-3 | 771-BC847AQAZ |  |  |  | BC847AQAZ
Bipolar Transistors - BJT 45 V, 500 mA PNP gen purpose transistors | Q3 | 1 | DFN-1010D-3 |  |  |  | BC807-40QAZ
Bipolar Transistors - BJT BC847AQA/DFN1010D-3/REEL 7" Q2 | Q2 | 1 | DFN-1010D-3 | 771-BC847AQAZ |  |  |  | BC847AQAZ
Bipolar Transistors - BJT BC847AQA/DFN1010D-3/REEL 7" Q2 | Q1 | 1 | DFN-1010D-3 | 771-BC847AQAZ |  |  |  | BC847AQAZ
Piezo Buzzers & Audio Indicators Piezo Buzzer 9x9mm 4KHz 1.9mm Thickness | PZ1 | 1 |  |  |  |  | PKMCS0909E4000-R1
Fixed Inductors 0.47uH 20% 11.2A 8.36mOhms AEC-Q200 | L4 | 1 | XFL4015 |  | 20% | 470 nH | XFL4015-471MEB
Fixed Inductors 0.47uH 20% 11.2A 8.36mOhms AEC-Q200 | L3 | 1 | XFL4015 |  | 20% | 470 nH | XFL4015-471MEB
Fixed Inductor | L2 | 1 | 0402 |  | 0.3 nH | 1nH | LQG15HN1N0S02D
Fixed Inductor | L1 | 1 | 0402 |  | 0.3 nH | 1nH | LQG15HN1N0S02D
Headers & Wire Housings BREAKAWAY HDR VERT 6 | J3 | 1 |  |  |  |  | FTSH-130-01-F-DV
Headers & Wire Housings BREAKAWAY HDR VERT 6 | J2 | 1 |  |  |  |  | FTSH-130-01-F-DV
Memory Card Connectors TFR READER (HINGE TYPE) | J1 | 1 |  |  |  |  | 47219-2001
Ferrite Beads 0603 100ohms 2000mA Auto Infotainment | FB2 | 1 | 0603 |  | 25% | BLM18EG101TZ1D | BLM18EG101TZ1D
Ferrite Beads 0603 100ohms 2000mA Auto Infotainment | FB1 | 1 | 0603 |  | 25% | BLM18EG101TZ1D | BLM18EG101TZ1D
Standard LEDs - SMD PICOLEDTM;BLUE LED; 25M @ 5MA | D4 | 1 | 0402 | 755-SMLP13BC8TT86 |  |  |  | SMLP13BC8TT86
Standard LEDs - SMD PICOLED series Red LED | D3 | 1 | 0606 (1616 metric) |  |  |  | 150066M153000
Standard LEDs - SMD PICOLED series Red LED | D2 | 1 | 0606 (1616 metric) |  |  |  | 150066M153000
Standard LEDs - SMD PICOLED series Red LED | D1 | 1 | 0606 (1616 metric) |  |  |  | 150066M153000
Capacitor - 33pF [0402] (Ceramic) | C234 | 1 | 0402 |  | 10% | 33pF | C0402C330J9RACAUTO
Capacitor - 33pF [0402] (Ceramic) | C233 | 1 | 0402 |  | 10% | 33pF | C0402C330J9RACAUTO
Capacitor - 100nF [0402-6V3] (Ceramic) | C232 | 1 | 0402 |  | %10 | 100nF | 04026D104KAT4A
Capacitor - 39uF 16V [Can] (Electrolytic) | C231 | 1 | Can |  | 20% | 39uF | 16SVPC39MV
Capacitor - 39uF 16V [Can] (Electrolytic) | C230 | 1 | Can |  | 20% | 39uF | 16SVPC39MV
Capacitor - 100nF [0402-6V3] (Ceramic) | C229 | 1 | 0402 |  | %10 | 100nF | 04026D104KAT4A
Capacitor - 33pF [0402] (Ceramic) | C228 | 1 | 0402 |  | 10% | 33pF | C0402C330J9RACAUTO
Capacitor - 33pF [0402] (Ceramic) | C227 | 1 | 0402 |  | 10% | 33pF | C0402C330J9RACAUTO
Capacitor - 100nF [0402-6V3] (Ceramic) | C226 | 1 | 0402 |  | %10 | 100nF | 04026D104KAT4A
Capacitor - 39uF 16V [Can] (Electrolytic) | C225 | 1 | Can |  | 20% | 39uF | 16SVPC39MV
Capacitor - 39uF 16V [Can] (Electrolytic) | C224 | 1 | Can |  | 20% | 39uF | 16SVPC39MV
Capacitor - 100nF [0402-6V3] (Ceramic) | C223 | 1 | 0402 |  | %10 | 100nF | 04026D104KAT4A
Capacitor - 33pF [0402] (Ceramic) | C222 | 1 | 0402 |  | 10% | 33pF | C0402C330J9RACAUTO
Capacitor - 33pF [0402] (Ceramic) | C221 | 1 | 0402 |  | 10% | 33pF | C0402C330J9RACAUTO
Capacitor - 33pF [0402] (Ceramic) | C220 | 1 | 0402 |  | 10% | 33pF | C0402C330J9RACAUTO
Capacitor - 33pF [0402] (Ceramic) | C219 | 1 | 0402 |  | 10% | 33pF | C0402C330J9RACAUTO
Capacitor - 33pF [0402] (Ceramic) | C218 | 1 | 0402 |  | 10% | 33pF | C0402C330J9RACAUTO
Capacitor - 33pF [0402] (Ceramic) | C217 | 1 | 0402 |  | 10% | 33pF | C0402C330J9RACAUTO
Capacitor - 33pF [0402] (Ceramic) | C216 | 1 | 0402 |  | 10% | 33pF | C0402C330J9RACAUTO
Capacitor - 33pF [0402] (Ceramic) | C215 | 1 | 0402 |  | 10% | 33pF | C0402C330J9RACAUTO
Capacitor - 33pF [0402] (Ceramic) | C214 | 1 | 0402 |  | 10% | 33pF | C0402C330J9RACAUTO
Capacitor - 33pF [0402] (Ceramic) | C213 | 1 | 0402 |  | 10% | 33pF | C0402C330J9RACAUTO
Capacitor - 33pF [0402] (Ceramic) | C212 | 1 | 0402 |  | 10% | 33pF | C0402C330J9RACAUTO
Capacitor - 33pF [0402] (Ceramic) | C211 | 1 | 0402 |  | 10% | 33pF | C0402C330J9RACAUTO
Capacitor - 33pF [0402] (Ceramic) | C210 | 1 | 0402 |  | 10% | 33pF | C0402C330J9RACAUTO
Capacitor - 33pF [0402] (Ceramic) | C209 | 1 | 0402 |  | 10% | 33pF | C0402C330J9RACAUTO
Capacitor - 33pF [0402] (Ceramic) | C208 | 1 | 0402 |  | 10% | 33pF | C0402C330J9RACAUTO
Capacitor - 33pF [0402] (Ceramic) | C207 | 1 | 0402 |  | 10% | 33pF | C0402C330J9RACAUTO
Capacitor - 33pF [0402] (Ceramic) | C206 | 1 | 0402 |  | 10% | 33pF | C0402C330J9RACAUTO
Capacitor - 33pF [0402] (Ceramic) | C205 | 1 | 0402 |  | 10% | 33pF | C0402C330J9RACAUTO
Capacitor - 33pF [0402] (Ceramic) | C204 | 1 | 0402 |  | 10% | 33pF | C0402C330J9RACAUTO
Capacitor - 33pF [0402] (Ceramic) | C203 | 1 | 0402 |  | 10% | 33pF | C0402C330J9RACAUTO
Capacitor - 33pF [0402] (Ceramic) | C202 | 1 | 0402 |  | 10% | 33pF | C0402C330J9RACAUTO
Capacitor - 33pF [0402] (Ceramic) | C201 | 1 | 0402 |  | 10% | 33pF | C0402C330J9RACAUTO
Capacitor - 33pF [0402] (Ceramic) | C200 | 1 | 0402 |  | 10% | 33pF | C0402C330J9RACAUTO
Capacitor - 33pF [0402] (Ceramic) | C199 | 1 | 0402 |  | 10% | 33pF | C0402C330J9RACAUTO
Capacitor - 33pF [0402] (Ceramic) | C198 | 1 | 0402 |  | 10% | 33pF | C0402C330J9RACAUTO
Capacitor - 33pF [0402] (Ceramic) | C197 | 1 | 0402 |  | 10% | 33pF | C0402C330J9RACAUTO
Capacitor - 33pF [0402] (Ceramic) | C196 | 1 | 0402 |  | 10% | 33pF | C0402C330J9RACAUTO
Capacitor - 33pF [0402] (Ceramic) | C195 | 1 | 0402 |  | 10% | 33pF | C0402C330J9RACAUTO
Capacitor - 33pF [0402] (Ceramic) | C194 | 1 | 0402 |  | 10% | 33pF | C0402C330J9RACAUTO
Capacitor - 33pF [0402] (Ceramic) | C193 | 1 | 0402 |  | 10% | 33pF | C0402C330J9RACAUTO
Capacitor - 33pF [0402] (Ceramic) | C192 | 1 | 0402 |  | 10% | 33pF | C0402C330J9RACAUTO
Capacitor - 33pF [0402] (Ceramic) | C191 | 1 | 0402 |  | 10% | 33pF | C0402C330J9RACAUTO
Capacitor - 33pF [0402] (Ceramic) | C190 | 1 | 0402 |  | 10% | 33pF | C0402C330J9RACAUTO
Capacitor - 33pF [0402] (Ceramic) | C189 | 1 | 0402 |  | 10% | 33pF | C0402C330J9RACAUTO
Capacitor - 33pF [0402] (Ceramic) | C188 | 1 | 0402 |  | 10% | 33pF | C0402C330J9RACAUTO
Capacitor - 33pF [0402] (Ceramic) | C187 | 1 | 0402 |  | 10% | 33pF | C0402C330J9RACAUTO
Capacitor - 33pF [0402] (Ceramic) | C186 | 1 | 0402 |  | 10% | 33pF | C0402C330J9RACAUTO
Capacitor - 33pF [0402] (Ceramic) | C185 | 1 | 0402 |  | 10% | 33pF | C0402C330J9RACAUTO
Capacitor - 33pF [0402] (Ceramic) | C184 | 1 | 0402 |  | 10% | 33pF | C0402C330J9RACAUTO
Capacitor - 33pF [0402] (Ceramic) | C183 | 1 | 0402 |  | 10% | 33pF | C0402C330J9RACAUTO
Capacitor - 33pF [0402] (Ceramic) | C182 | 1 | 0402 |  | 10% | 33pF | C0402C330J9RACAUTO
Capacitor - 33pF [0402] (Ceramic) | C181 | 1 | 0402 |  | 10% | 33pF | C0402C330J9RACAUTO
Capacitor - 33pF [0402] (Ceramic) | C180 | 1 | 0402 |  | 10% | 33pF | C0402C330J9RACAUTO
Capacitor - 33pF [0402] (Ceramic) | C179 | 1 | 0402 |  | 10% | 33pF | C0402C330J9RACAUTO
Capacitor - 33pF [0402] (Ceramic) | C178 | 1 | 0402 |  | 10% | 33pF | C0402C330J9RACAUTO
Capacitor - 33pF [0402] (Ceramic) | C177 | 1 | 0402 |  | 10% | 33pF | C0402C330J9RACAUTO
Capacitor - 33pF [0402] (Ceramic) | C176 | 1 | 0402 |  | 10% | 33pF | C0402C330J9RACAUTO
Capacitor - 33pF [0402] (Ceramic) | C175 | 1 | 0402 |  | 10% | 33pF | C0402C330J9RACAUTO
Capacitor - 33pF [0402] (Ceramic) | C174 | 1 | 0402 |  | 10% | 33pF | C0402C330J9RACAUTO
Capacitor - 33pF [0402] (Ceramic) | C173 | 1 | 0402 |  | 10% | 33pF | C0402C330J9RACAUTO
Capacitor - 33pF [0402] (Ceramic) | C172 | 1 | 0402 |  | 10% | 33pF | C0402C330J9RACAUTO
Capacitor - 33pF [0402] (Ceramic) | C171 | 1 | 0402 |  | 10% | 33pF | C0402C330J9RACAUTO
Capacitor - 33pF [0402] (Ceramic) | C170 | 1 | 0402 |  | 10% | 33pF | C0402C330J9RACAUTO
Capacitor - 33pF [0402] (Ceramic) | C169 | 1 | 0402 |  | 10% | 33pF | C0402C330J9RACAUTO
Capacitor - 33pF [0402] (Ceramic) | C168 | 1 | 0402 |  | 10% | 33pF | C0402C330J9RACAUTO
Capacitor - 33pF [0402] (Ceramic) | C167 | 1 | 0402 |  | 10% | 33pF | C0402C330J9RACAUTO
Capacitor - 33pF [0402] (Ceramic) | C166 | 1 | 0402 |  | 10% | 33pF | C0402C330J9RACAUTO
Capacitor - 33pF [0402] (Ceramic) | C165 | 1 | 0402 |  | 10% | 33pF | C0402C330J9RACAUTO
Capacitor - 33pF [0402] (Ceramic) | C164 | 1 | 0402 |  | 10% | 33pF | C0402C330J9RACAUTO
Capacitor - 33pF [0402] (Ceramic) | C163 | 1 | 0402 |  | 10% | 33pF | C0402C330J9RACAUTO
Capacitor - 33pF [0402] (Ceramic) | C162 | 1 | 0402 |  | 10% | 33pF | C0402C330J9RACAUTO
Capacitor - 33pF [0402] (Ceramic) | C161 | 1 | 0402 |  | 10% | 33pF | C0402C330J9RACAUTO
Capacitor - 33pF [0402] (Ceramic) | C160 | 1 | 0402 |  | 10% | 33pF | C0402C330J9RACAUTO
Capacitor - 33pF [0402] (Ceramic) | C159 | 1 | 0402 |  | 10% | 33pF | C0402C330J9RACAUTO
Capacitor - 33pF [0402] (Ceramic) | C158 | 1 | 0402 |  | 10% | 33pF | C0402C330J9RACAUTO
Capacitor - 33pF [0402] (Ceramic) | C157 | 1 | 0402 |  | 10% | 33pF | C0402C330J9RACAUTO
Capacitor - 33pF [0402] (Ceramic) | C156 | 1 | 0402 |  | 10% | 33pF | C0402C330J9RACAUTO
Capacitor - 33pF [0402] (Ceramic) | C155 | 1 | 0402 |  | 10% | 33pF | C0402C330J9RACAUTO
Capacitor - 33pF [0402] (Ceramic) | C154 | 1 | 0402 |  | 10% | 33pF | C0402C330J9RACAUTO
Capacitor - 33pF [0402] (Ceramic) | C153 | 1 | 0402 |  | 10% | 33pF | C0402C330J9RACAUTO
Capacitor - 33pF [0402] (Ceramic) | C152 | 1 | 0402 |  | 10% | 33pF | C0402C330J9RACAUTO
Capacitor - 33pF [0402] (Ceramic) | C151 | 1 | 0402 |  | 10% | 33pF | C0402C330J9RACAUTO
Capacitor - 33pF [0402] (Ceramic) | C150 | 1 | 0402 |  | 10% | 33pF | C0402C330J9RACAUTO
Capacitor - 33pF [0402] (Ceramic) | C149 | 1 | 0402 |  | 10% | 33pF | C0402C330J9RACAUTO
Capacitor - 33pF [0402] (Ceramic) | C148 | 1 | 0402 |  | 10% | 33pF | C0402C330J9RACAUTO
Capacitor - 33pF [0402] (Ceramic) | C147 | 1 | 0402 |  | 10% | 33pF | C0402C330J9RACAUTO
Capacitor - 33pF [0402] (Ceramic) | C146 | 1 | 0402 |  | 10% | 33pF | C0402C330J9RACAUTO
Capacitor - 33pF [0402] (Ceramic) | C145 | 1 | 0402 |  | 10% | 33pF | C0402C330J9RACAUTO
Capacitor - 33pF [0402] (Ceramic) | C144 | 1 | 0402 |  | 10% | 33pF | C0402C330J9RACAUTO
Capacitor - 33pF [0402] (Ceramic) | C143 | 1 | 0402 |  | 10% | 33pF | C0402C330J9RACAUTO
Capacitor - 33pF [0402] (Ceramic) | C142 | 1 | 0402 |  | 10% | 33pF | C0402C330J9RACAUTO
Capacitor - 33pF [0402] (Ceramic) | C141 | 1 | 0402 |  | 10% | 33pF | C0402C330J9RACAUTO
Capacitor - 33pF [0402] (Ceramic) | C140 | 1 | 0402 |  | 10% | 33pF | C0402C330J9RACAUTO
Capacitor - 33pF [0402] (Ceramic) | C139 | 1 | 0402 |  | 10% | 33pF | C0402C330J9RACAUTO
Capacitor - 33pF [0402] (Ceramic) | C138 | 1 | 0402 |  | 10% | 33pF | C0402C330J9RACAUTO
Capacitor - 100nF [0402-6V3] (Ceramic) | C137 | 1 | 0402 |  | %10 | 100nF | 04026D104KAT4A
Capacitor - 100nF [0402-6V3] (Ceramic) | C136 | 1 | 0402 |  | %10 | 100nF | 04026D104KAT4A
Capacitor - 100nF [0402-6V3] (Ceramic) | C135 | 1 | 0402 |  | %10 | 100nF | 04026D104KAT4A
Capacitor - 33pF [0402] (Ceramic) | C134 | 1 | 0402 |  | 10% | 33pF | C0402C330J9RACAUTO
Capacitor - 33pF [0402] (Ceramic) | C133 | 1 | 0402 |  | 10% | 33pF | C0402C330J9RACAUTO
Capacitor - 100nF [0402-6V3] (Ceramic) | C132 | 1 | 0402 |  | %10 | 100nF | 04026D104KAT4A
Capacitor - 100nF [0402-6V3] (Ceramic) | C131 | 1 | 0402 |  | %10 | 100nF | 04026D104KAT4A
Capacitor - 100nF [0402-6V3] (Ceramic) | C130 | 1 | 0402 |  | %10 | 100nF | 04026D104KAT4A
Capacitor - 33pF [0402] (Ceramic) | C129 | 1 | 0402 |  | 10% | 33pF | C0402C330J9RACAUTO
Capacitor - 33pF [0402] (Ceramic) | C128 | 1 | 0402 |  | 10% | 33pF | C0402C330J9RACAUTO
Capacitor - 33pF [0402] (Ceramic) | C127 | 1 | 0402 |  | 10% | 33pF | C0402C330J9RACAUTO
Capacitor - 33pF [0402] (Ceramic) | C126 | 1 | 0402 |  | 10% | 33pF | C0402C330J9RACAUTO
Capacitor - 33pF [0402] (Ceramic) | C125 | 1 | 0402 |  | 10% | 33pF | C0402C330J9RACAUTO
Capacitor - 33pF [0402] (Ceramic) | C124 | 1 | 0402 |  | 10% | 33pF | C0402C330J9RACAUTO
Capacitor - 33pF [0402] (Ceramic) | C123 | 1 | 0402 |  | 10% | 33pF | C0402C330J9RACAUTO
Capacitor - 33pF [0402] (Ceramic) | C122 | 1 | 0402 |  | 10% | 33pF | C0402C330J9RACAUTO
Capacitor - 33pF [0402] (Ceramic) | C121 | 1 | 0402 |  | 10% | 33pF | C0402C330J9RACAUTO
Capacitor - 33pF [0402] (Ceramic) | C120 | 1 | 0402 |  | 10% | 33pF | C0402C330J9RACAUTO
Capacitor - 33pF [0402] (Ceramic) | C119 | 1 | 0402 |  | 10% | 33pF | C0402C330J9RACAUTO
Capacitor - 33pF [0402] (Ceramic) | C118 | 1 | 0402 |  | 10% | 33pF | C0402C330J9RACAUTO
Capacitor - 33pF [0402] (Ceramic) | C117 | 1 | 0402 |  | 10% | 33pF | C0402C330J9RACAUTO
Capacitor - 33pF [0402] (Ceramic) | C116 | 1 | 0402 |  | 10% | 33pF | C0402C330J9RACAUTO
Capacitor - 33pF [0402] (Ceramic) | C115 | 1 | 0402 |  | 10% | 33pF | C0402C330J9RACAUTO
Capacitor - 33pF [0402] (Ceramic) | C114 | 1 | 0402 |  | 10% | 33pF | C0402C330J9RACAUTO
Capacitor - 33pF [0402] (Ceramic) | C113 | 1 | 0402 |  | 10% | 33pF | C0402C330J9RACAUTO
Capacitor - 33pF [0402] (Ceramic) | C112 | 1 | 0402 |  | 10% | 33pF | C0402C330J9RACAUTO
Capacitor - 33pF [0402] (Ceramic) | C111 | 1 | 0402 |  | 10% | 33pF | C0402C330J9RACAUTO
Capacitor - 33pF [0402] (Ceramic) | C110 | 1 | 0402 |  | 10% | 33pF | C0402C330J9RACAUTO
Capacitor - 33pF [0402] (Ceramic) | C109 | 1 | 0402 |  | 10% | 33pF | C0402C330J9RACAUTO
Capacitor - 33pF [0402] (Ceramic) | C108 | 1 | 0402 |  | 10% | 33pF | C0402C330J9RACAUTO
Capacitor - 33pF [0402] (Ceramic) | C107 | 1 | 0402 |  | 10% | 33pF | C0402C330J9RACAUTO
Capacitor - 33pF [0402] (Ceramic) | C106 | 1 | 0402 |  | 10% | 33pF | C0402C330J9RACAUTO
Capacitor - 33pF [0402] (Ceramic) | C105 | 1 | 0402 |  | 10% | 33pF | C0402C330J9RACAUTO
Capacitor - 33pF [0402] (Ceramic) | C104 | 1 | 0402 |  | 10% | 33pF | C0402C330J9RACAUTO
Capacitor - 33pF [0402] (Ceramic) | C103 | 1 | 0402 |  | 10% | 33pF | C0402C330J9RACAUTO
Capacitor - 33pF [0402] (Ceramic) | C102 | 1 | 0402 |  | 10% | 33pF | C0402C330J9RACAUTO
Capacitor - 33pF [0402] (Ceramic) | C101 | 1 | 0402 |  | 10% | 33pF | C0402C330J9RACAUTO
Capacitor - 33pF [0402] (Ceramic) | C100 | 1 | 0402 |  | 10% | 33pF | C0402C330J9RACAUTO
Capacitor - 33pF [0402] (Ceramic) | C99 | 1 | 0402 |  | 10% | 33pF | C0402C330J9RACAUTO
Capacitor - 33pF [0402] (Ceramic) | C98 | 1 | 0402 |  | 10% | 33pF | C0402C330J9RACAUTO
Capacitor - 33pF [0402] (Ceramic) | C97 | 1 | 0402 |  | 10% | 33pF | C0402C330J9RACAUTO
Capacitor - 33pF [0402] (Ceramic) | C96 | 1 | 0402 |  | 10% | 33pF | C0402C330J9RACAUTO
Capacitor - 33pF [0402] (Ceramic) | C95 | 1 | 0402 |  | 10% | 33pF | C0402C330J9RACAUTO
Capacitor - 100nF [0402-6V3] (Ceramic) | C94 | 1 | 0402 |  | %10 | 100nF | 04026D104KAT4A
Capacitor - 100nF [0402-6V3] (Ceramic) | C93 | 1 | 0402 |  | %10 | 100nF | 04026D104KAT4A
Capacitor - 100nF [0402-6V3] (Ceramic) | C92 | 1 | 0402 |  | %10 | 100nF | 04026D104KAT4A
Capacitor - 13pF [0402] (Ceramic) | C91 | 1 | 0402 |  | 1% | 13pF | CBR04C130F5GAC
Capacitor - 13pF [0402] (Ceramic) | C90 | 1 | 0402 |  | 1% | 13pF | CBR04C130F5GAC
Capacitor - 100nF [0402-6V3] (Ceramic) | C89 | 1 | 0402 |  | %10 | 100nF | 04026D104KAT4A
Capacitor - 100nF [0402-6V3] (Ceramic) | C88 | 1 | 0402 |  | %10 | 100nF | 04026D104KAT4A
Capacitor - 100nF [0402-6V3] (Ceramic) | C87 | 1 | 0402 |  | %10 | 100nF | 04026D104KAT4A
Capacitor - 100nF [0402-6V3] (Ceramic) | C86 | 1 | 0402 |  | %10 | 100nF | 04026D104KAT4A
Capacitor - 33pF [0402] (Ceramic) | C85 | 1 | 0402 |  | 10% | 33pF | C0402C330J9RACAUTO
Capacitor - 100nF [0402-6V3] (Ceramic) | C84 | 1 | 0402 |  | %10 | 100nF | 04026D104KAT4A
Capacitor - 100nF [0402-6V3] (Ceramic) | C83 | 1 | 0402 |  | %10 | 100nF | 04026D104KAT4A
Capacitor - 33pF [0402] (Ceramic) | C82 | 1 | 0402 |  | 10% | 33pF | C0402C330J9RACAUTO
Capacitor - 100nF [0402-6V3] (Ceramic) | C81 | 1 | 0402 |  | %10 | 100nF | 04026D104KAT4A
Capacitor - 100nF [0402-6V3] (Ceramic) | C80 | 1 | 0402 |  | %10 | 100nF | 04026D104KAT4A
Capacitor - 33pF [0402] (Ceramic) | C79 | 1 | 0402 |  | 10% | 33pF | C0402C330J9RACAUTO
Capacitor - 100nF [0402-6V3] (Ceramic) | C78 | 1 | 0402 |  | %10 | 100nF | 04026D104KAT4A
Capacitor - 100nF [0402-6V3] (Ceramic) | C77 | 1 | 0402 |  | %10 | 100nF | 04026D104KAT4A
Capacitor - 100nF [0402-6V3] (Ceramic) | C76 | 1 | 0402 |  | %10 | 100nF | 04026D104KAT4A
Capacitor - 13pF [0402] (Ceramic) | C75 | 1 | 0402 |  | 1% | 13pF | CBR04C130F5GAC
Capacitor - 13pF [0402] (Ceramic) | C74 | 1 | 0402 |  | 1% | 13pF | CBR04C130F5GAC
Capacitor - 33pF [0402] (Ceramic) | C73 | 1 | 0402 |  | 10% | 33pF | C0402C330J9RACAUTO
Capacitor - 33pF [0402] (Ceramic) | C72 | 1 | 0402 |  | 10% | 33pF | C0402C330J9RACAUTO
Capacitor - 33pF [0402] (Ceramic) | C71 | 1 | 0402 |  | 10% | 33pF | C0402C330J9RACAUTO
Capacitor - 33pF [0402] (Ceramic) | C70 | 1 | 0402 |  | 10% | 33pF | C0402C330J9RACAUTO
Capacitor - 33pF [0402] (Ceramic) | C69 | 1 | 0402 |  | 10% | 33pF | C0402C330J9RACAUTO
Capacitor - 33pF [0402] (Ceramic) | C68 | 1 | 0402 |  | 10% | 33pF | C0402C330J9RACAUTO
Capacitor - 33pF [0402] (Ceramic) | C67 | 1 | 0402 |  | 10% | 33pF | C0402C330J9RACAUTO
Capacitor - 100nF [0402-6V3] (Ceramic) | C66 | 1 | 0402 |  | %10 | 100nF | 04026D104KAT4A
Capacitor - 100nF [0402-6V3] (Ceramic) | C65 | 1 | 0402 |  | %10 | 100nF | 04026D104KAT4A
Capacitor - 100nF [0402-6V3] (Ceramic) | C64 | 1 | 0402 |  | %10 | 100nF | 04026D104KAT4A
Capacitor - 33pF [0402] (Ceramic) | C63 | 1 | 0402 |  | 10% | 33pF | C0402C330J9RACAUTO
Capacitor - 33pF [0402] (Ceramic) | C62 | 1 | 0402 |  | 10% | 33pF | C0402C330J9RACAUTO
Capacitor - 100nF [0402-6V3] (Ceramic) | C61 | 1 | 0402 |  | %10 | 100nF | 04026D104KAT4A
Capacitor - 100nF [0402-6V3] (Ceramic) | C60 | 1 | 0402 |  | %10 | 100nF | 04026D104KAT4A
Capacitor - 33pF [0402] (Ceramic) | C59 | 1 | 0402 |  | 10% | 33pF | C0402C330J9RACAUTO
Capacitor - 33pF [0402] (Ceramic) | C58 | 1 | 0402 |  | 10% | 33pF | C0402C330J9RACAUTO
Capacitor - 33pF [0402] (Ceramic) | C57 | 1 | 0402 |  | 10% | 33pF | C0402C330J9RACAUTO
Capacitor - 33pF [0402] (Ceramic) | C56 | 1 | 0402 |  | 10% | 33pF | C0402C330J9RACAUTO
Capacitor - 33pF [0402] (Ceramic) | C55 | 1 | 0402 |  | 10% | 33pF | C0402C330J9RACAUTO
Capacitor - 33pF [0402] (Ceramic) | C54 | 1 | 0402 |  | 10% | 33pF | C0402C330J9RACAUTO
Capacitor - 33pF [0402] (Ceramic) | C53 | 1 | 0402 |  | 10% | 33pF | C0402C330J9RACAUTO
Capacitor - 33pF [0402] (Ceramic) | C52 | 1 | 0402 |  | 10% | 33pF | C0402C330J9RACAUTO
Capacitor - 33pF [0402] (Ceramic) | C51 | 1 | 0402 |  | 10% | 33pF | C0402C330J9RACAUTO
Capacitor - 33pF [0402] (Ceramic) | C50 | 1 | 0402 |  | 10% | 33pF | C0402C330J9RACAUTO
Capacitor - 33pF [0402] (Ceramic) | C49 | 1 | 0402 |  | 10% | 33pF | C0402C330J9RACAUTO
Capacitor - 33pF [0402] (Ceramic) | C48 | 1 | 0402 |  | 10% | 33pF | C0402C330J9RACAUTO
Capacitor - 33pF [0402] (Ceramic) | C47 | 1 | 0402 |  | 10% | 33pF | C0402C330J9RACAUTO
Capacitor - 33pF [0402] (Ceramic) | C46 | 1 | 0402 |  | 10% | 33pF | C0402C330J9RACAUTO
Capacitor - 33pF [0402] (Ceramic) | C45 | 1 | 0402 |  | 10% | 33pF | C0402C330J9RACAUTO
Capacitor - 100nF [0402-6V3] (Ceramic) | C44 | 1 | 0402 |  | %10 | 100nF | 04026D104KAT4A
Capacitor - 100nF [0402-6V3] (Ceramic) | C43 | 1 | 0402 |  | %10 | 100nF | 04026D104KAT4A
Capacitor - 1uF [0402] (Ceramic) | C42 | 1 | 0402 |  | 20% | 1uF | GRM153R60J105ME95D
Capacitor - 33pF [0402] (Ceramic) | C41 | 1 | 0402 |  | 10% | 33pF | C0402C330J9RACAUTO
Capacitor - 33pF [0402] (Ceramic) | C40 | 1 | 0402 |  | 10% | 33pF | C0402C330J9RACAUTO
Capacitor - 33pF [0402] (Ceramic) | C39 | 1 | 0402 |  | 10% | 33pF | C0402C330J9RACAUTO
Capacitor - 33pF [0402] (Ceramic) | C38 | 1 | 0402 |  | 10% | 33pF | C0402C330J9RACAUTO
Capacitor - 33pF [0402] (Ceramic) | C37 | 1 | 0402 |  | 10% | 33pF | C0402C330J9RACAUTO
Capacitor - 33pF [0402] (Ceramic) | C36 | 1 | 0402 |  | 10% | 33pF | C0402C330J9RACAUTO
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

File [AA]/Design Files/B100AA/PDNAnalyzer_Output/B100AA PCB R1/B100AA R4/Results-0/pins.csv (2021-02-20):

refdes | pin | voltage | current
J2 | 60 | 4.99955 | 0.223612
J2 | 1 | 4.99955 | 0.223612
J2 | 30 | 0.0 | -0.111806
J2 | 58 | 0.0 | -0.111806
J2 | 4 | 0.0 | -0.111806
J2 | 31 | 0.0 | -0.111806
J3 | 60 | 5.00024 | 0.00597292
J3 | 1 | 5.00024 | 0.00597292
J3 | 30 | 0.000247092 | -0.00298646
J3 | 58 | 0.000247092 | -0.00298646
J3 | 4 | 0.000247092 | -0.00298646
J3 | 31 | 0.000247092 | -0.00298646
U3 | 5 | 3.29955 | 0.570289
U3 | 2 | 0.000117524 | 0.01495499999999994
U21 | 6 | 3.7997 | 0.835247
U21 | 8 | -0.00037459 | -0.18870699999999999
U21 | 3 | -0.00037459 | -0.18870699999999999
U22 | 6 | 4.99899 | 0.00118523
U22 | 8 | 0.000116946 | 7.527100000000002e-05
U22 | 3 | 0.000116946 | 7.527100000000002e-05
U4 | M01 | 3.67916 | -0.0625225
U4 | M02 | 3.67902 | -0.0624775
U4 | R02 | 0.00027662 | 0.00657453
U4 | R04 | 0.000282598 | 0.00657153
U4 | R03 | 0.000280508 | 0.00657258
U4 | P03 | 0.000281841 | 0.00657191
U4 | P04 | 0.000283437 | 0.0065711
U4 | N03 | 0.000281119 | 0.00657227
U4 | R05 | 0.000282114 | 0.006571769999999999
U4 | R06 | 0.000279664 | 0.006573000000000001
U4 | P05 | 0.000282727 | 0.00657147
U4 | R08 | 0.000273213 | 0.0065762400000000006
U4 | N05 | 0.000280673 | 0.00657249
U4 | P06 | 0.000279564 | 0.00657305
U4 | N04 | 0.000282045 | 0.0065718
U4 | N06 | 0.000277044 | 0.00657432
U4 | L01 | 0.000268479 | 0.00657861
U4 | L02 | 0.000271918 | 0.00657688
U4 | J01 | 0.000261218 | 0.0065822499999999996
U4 | K02 | 0.000269914 | 0.006577889999999999
U4 | H01 | 0.000258178 | 0.00658378
U4 | J02 | 0.000265742 | 0.00657998
U4 | G02 | 0.000258049 | 0.0065838500000000005
U4 | M03 | 0.000277755 | 0.00657395
U4 | M04 | 0.000278586 | 0.006573539999999999
U4 | H02 | 0.000260786 | 0.00658246
U4 | R10 | 0.000271514 | 0.00657709
U4 | P09 | 0.000271239 | 0.00657723
U4 | P10 | 0.000270802 | 0.00657745
U4 | P08 | 0.000272965 | 0.00657636
U4 | P13 | 0.00026378 | 0.00658097
U4 | M12 | 0.00026142 | 0.00658216
U4 | G01 | 0.000258099 | 0.006583820000000001
U4 | E01 | 0.000248441 | 0.00658867
U4 | F02 | 0.000254365 | 0.00658569
U4 | E02 | 0.000250994 | 0.00658739
U4 | A02 | 0.000231115 | 0.00659736
U4 | A04 | 0.000233954 | 0.00659593
U4 | E14 | 0.000241324 | 0.00659224
U4 | B13 | 0.000253061 | 0.0065863499999999995
U4 | P01 | 3.68066 | -0.0312855
U4 | P02 | 3.68031 | -0.0312236
U4 | N02 | 3.68037 | -0.0312353
U4 | N01 | 3.68049 | -0.0312555
U20 | 3 | 4.99892 | -0.00018
U20 | 6 | 0.000149103 | 0.00018
R62 | 2 | 4.99889 | -0.000999896
U16 | 8 | 0.000233938 | 0.0076455287
U17 | 6 | 3.29495 | -0.0001
U17 | 5 | 0.000243125 | 0.0002
U6 | 1 | 3.19812 | -0.0001
U6 | 8 | 0.000209815 | 5.601219999999999e-05
U6 | 9 | 0.000208468 | 5.60131e-05
U6 | 17 | 0.000215344 | 5.6008300000000004e-05
U7 | 1 | 3.19813 | -0.0001
U7 | 8 | 0.000234555 | 5.6011500000000004e-05
U7 | 9 | 0.000233796 | 5.6012e-05
U7 | 17 | 0.000237574 | 5.60094e-05
U8 | 1 | 3.19812 | -0.0001
U8 | 8 | 0.000249224 | 5.60107e-05
U8 | 9 | 0.000248507 | 5.6011200000000003e-05
U8 | 17 | 0.000249326 | 5.60106e-05
R13 | 2 | 3.19813 | -6.80303e-05
U15 | 11 | 0.000161551 | 0.010293918400000001
U15 | 32 | 0.00017479 | 0.0102926111
U15 | 62 | 0.000206309 | 0.010289393499999999
U15 | 81 | 0.000187241 | 0.0102913141
U15 | 99 | 0.000161631 | 0.0102939183
R12 | 2 | 3.19813 | -6.80431e-05
R14 | 2 | 3.19813 | -6.80427e-05
R16 | 2 | 3.19812 | -6.80423e-05
R15 | 2 | 3.19812 | -6.803e-05
R17 | 2 | 3.12017 | -6.63719e-05
Q3 | 2 | 3.11988 | -0.3315889
Q4 | 2 | 0.000272863 | 0.047994
Q5 | 2 | 0.000351176 | 0.141797
Q6 | 2 | 0.000328955 | 0.141798
R45 | 2 | 3.18947 | -0.000318953
U15 | 10 | 3.19613 | -0.0105415
U15 | 31 | 3.18947 | -0.00987545
U15 | 61 | 3.17351 | -0.00828012
U15 | 80 | 3.198 | -0.0107289
U15 | 100 | 3.19645 | -0.010574
D3 | 4 | 3.18562 | -0.02895839
Q10 | 2 | 0.000195556 | 0.0096528
Q11 | 2 | 0.000210867 | 0.00965275
Q12 | 2 | 0.000166971 | 0.00965289
U9 | 1 | 3.16787 | -0.0001
U9 | 2 | 0.000210635 | 0.0001
U11 | 4 | 3.14578 | -0.016774
U11 | 6 | 3.14571 | -0.0167626
U11 | 18 | 3.14392 | -0.0164634
U11 | 3 | 0.000282554 | 0.016772163
U11 | 5 | 0.000329429 | 0.016764357
U11 | 21 | 0.000247816 | 0.016777968
R36 | 2 | 3.14481 | -0.000314407
D2 | 4 | 3.1458600000000003 | -0.02859647
Q7 | 2 | 0.000250367 | 0.00953217
Q8 | 2 | 0.000243294 | 0.00953219
Q9 | 2 | 0.000253842 | 0.00953216
J1 | 4 | 3.1873 | -0.03
J1 | 6 | 0.000260052 | 0.03
R38 | 2 | 3.18726 | -0.000318667
U12 | 8 | 0.00023601400000000002 | 0.000687539
U12 | 15 | 0.000211558 | 0.0006875733
R39 | 2 | 3.18726 | -0.000318667
R40 | 2 | 3.18726 | -0.000318667
R41 | 2 | 3.18726 | -0.000318667
U12 | 16 | 3.17374 | -0.0001
U13 | 2 | 3.19814 | -0.0001
U13 | 11 | 0.000235594 | 0.0002
U13 | 19 | 3.14481 | -0.0001
U14 | 12 | 3.1981 | -0.015
U14 | 5 | 0.000215796 | 0.00750063
U14 | 13 | 0.000227049 | 0.00749937
R52 | 2 | 3.13079 | -0.000313084
R53 | 2 | 3.13079 | -0.000313084
U16 | 16 | 3.13079 | -0.0096896
U16 | 3 | 3.13907 | -0.0103105
U16 | 13 | 0.000238793 | 0.0050782111
U16 | 2 | 0.000234646 | 0.0050785216
U16 | 1 | 0.00023573 | 0.0050784415
U17 | 7 | 3.13868 | -0.0001
R57 | 2 | 3.13828 | -0.00950918
D4 | 1 | 0.000250196 | 0.0095092
R56 | 2 | 3.13837 | -0.000313842
R54 | 2 | 3.13836 | -0.000313865
R55 | 2 | 3.13836 | -0.000313844
R58 | 2 | 3.13889 | -0.000313918
R59 | 2 | 3.13887 | -0.000313916
U18 | 5 | 3.13211 | -0.0002
U18 | 2 | 0.000228325 | 0.0002
R60 | 2 | 3.13079 | -0.000313107
R61 | 2 | 3.13079 | -0.000313107
U19 | 8 | 3.13078 | -0.0004
U19 | 4 | 0.000231661 | 0.0004
U3 | 1 | 3.76185 | -0.585244
U21 | 10 | 4.97808 | -0.457835
R65 | 2 | 3.7982 | -4.05615e-06
R66 | 1 | 7.64107e-05 | 3.5401e-06
U22 | 10 | 4.99183 | -0.00133578
R68 | 2 | 4.99898 | -5.33847e-06
R70 | 1 | 0.000117729 | 4.65927e-06
U1 | 1 | 3.71518 | -0.25
U1 | 6 | 3.69018 | 0.25
FB1 | 1 | 3.68889 | -0.125
FB1 | 2 | 3.68327 | 0.125
FB2 | 1 | 3.68901 | -0.125
FB2 | 2 | 3.68339 | 0.125
U2 | 1 | 3.2887 | -0.570189
U2 | 6 | 3.20887 | 0.570189
U10 | 1 | 3.162 | -0.0790109
U10 | 6 | 3.15094 | 0.0790109

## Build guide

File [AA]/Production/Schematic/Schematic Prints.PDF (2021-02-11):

* Bidirectional signal translator IC changed.
* SIM Vcc capacitor changed to 100nF.

* 33 pF capacitor added to VAUX of GSM
* 33 pF capacitors added to all Output Socket pins.

* GSM IoT LED resistors are calculated and updated.
* GSM IoT LED power enable transistor changed to PNP.

Necip Fazıl Mah. Ortaırmak Sok. Birgül Apt. No: 19/6 Meram / Konya Turkiye

C:\Altium Projects\B100\[AA]\Design Files\B100AA\Schematics\B100 Block Diagram.SchDoc

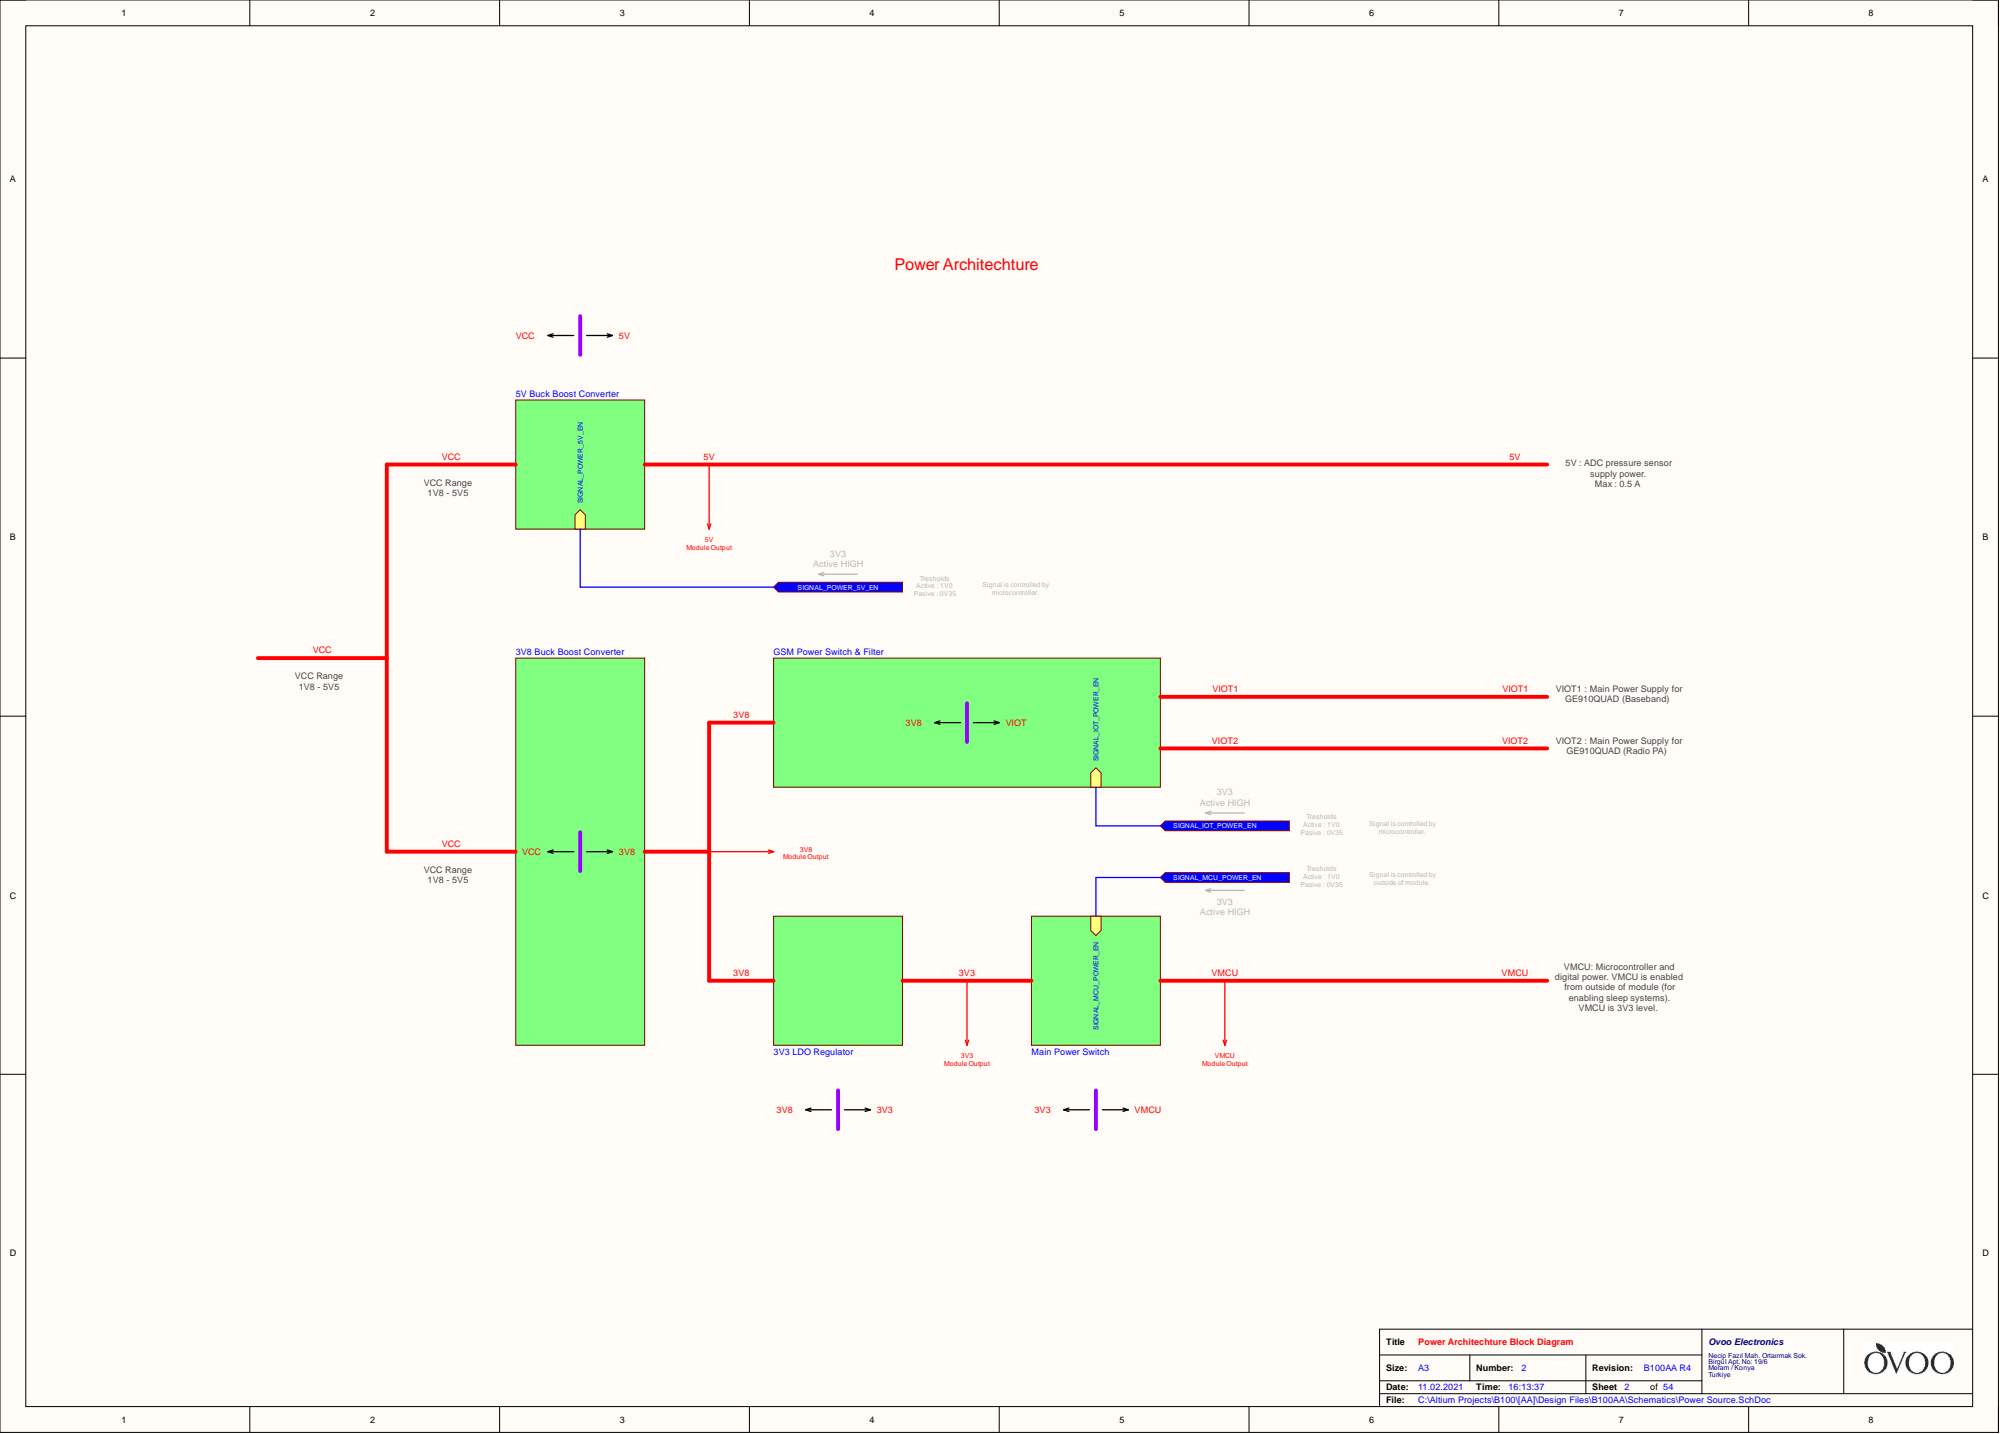
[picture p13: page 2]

Signal is controlled by
microcontroller.

GSM Power Switch & Filter

VIOT1 : Main Power Supply for
GE910QUAD (Baseband)

VIOT2 : Main Power Supply for
GE910QUAD (Radio PA)

outside of module.

VMCU: Microcontroller and
digital power. VMCU is enabled
from outside of module (for
enabling sleep systems).
VMCU is 3V3 level.

Power Architechture Block Diagram

C:\Altium Projects\B100\[AA]\Design Files\B100AA\Schematics\Power Source.SchDoc

MODE 2

3V8 DC/DC Buck Boost Converter

C:\Altium Projects\B100\[AA]\Design Files\B100AA\Schematics\3V8 Buck Boost Converter.SchDoc

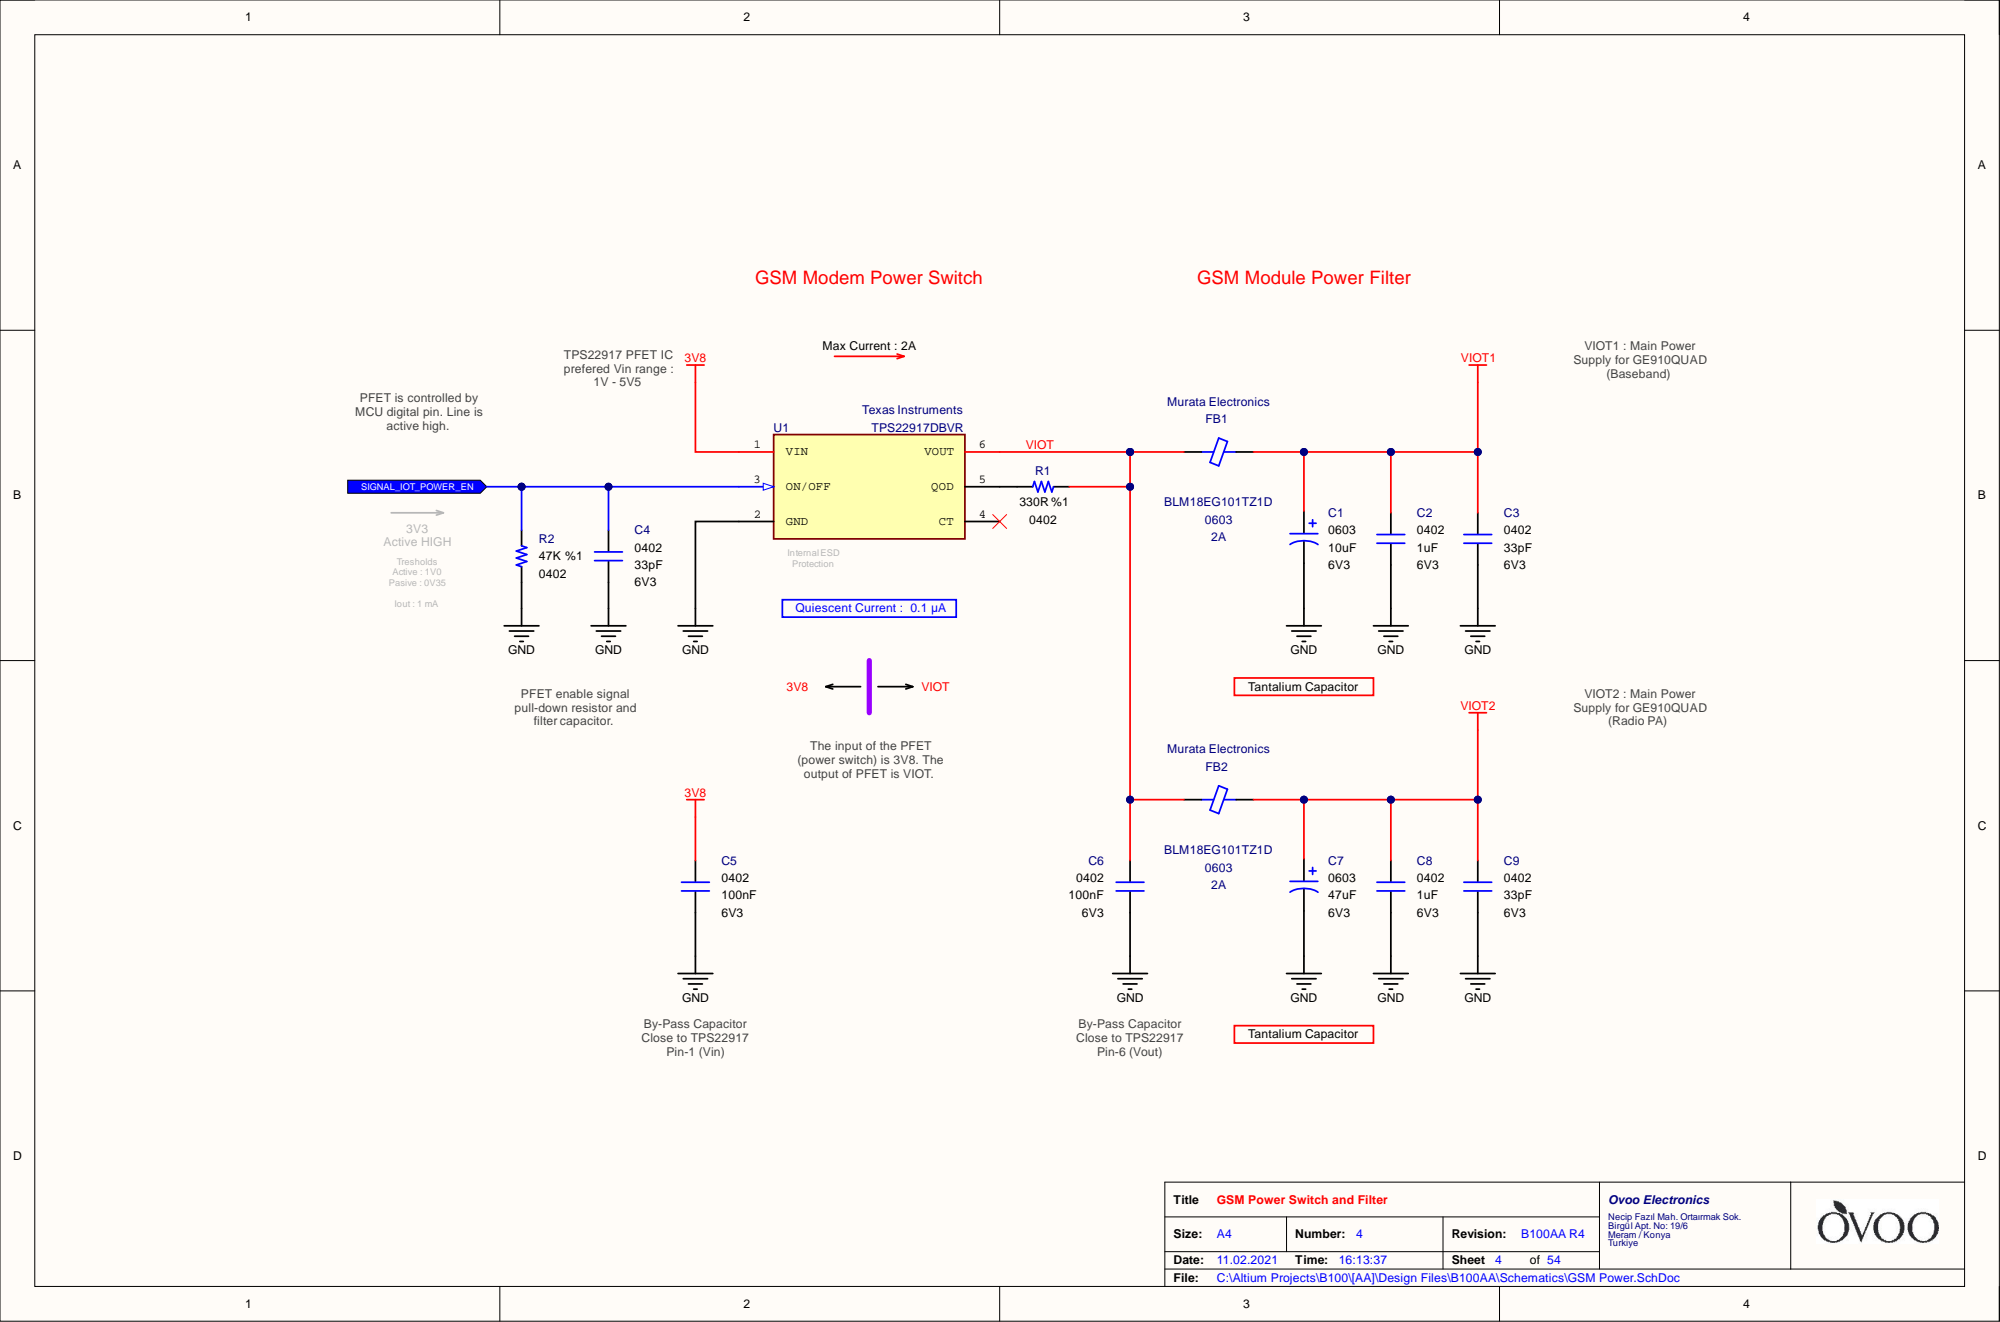
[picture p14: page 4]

GSM Modem Power Switch

GSM Module Power Filter

PFET is controlled by
MCU digital pin. Line is
active high.

PFET enable signal
pull-down resistor and
filter capacitor.

The input of the PFET
(power switch) is 3V8. The
output of PFET is VIOT.

GSM Power Switch and Filter

C:\Altium Projects\B100\[AA]\Design Files\B100AA\Schematics\GSM Power.SchDoc

TLV75533 LDO is a 3V3
regulator. LDO is always

C:\Altium Projects\B100\[AA]\Design Files\B100AA\Schematics\3V3 LDO Regulator.SchDoc

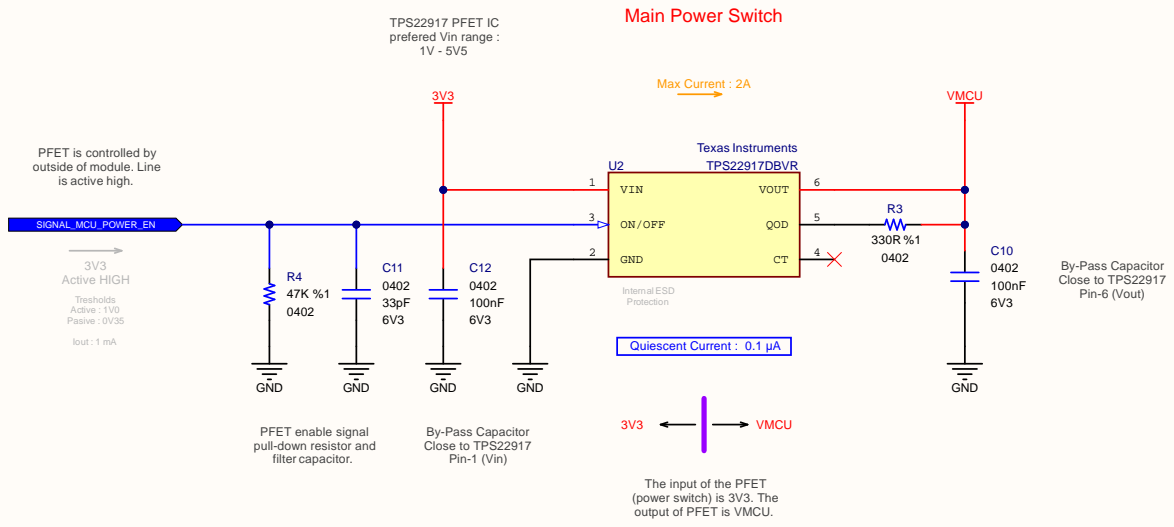
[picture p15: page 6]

PFET is controlled by
outside of module. Line
is active high.

PFET enable signal
pull-down resistor and
filter capacitor.

The input of the PFET
(power switch) is 3V3. The
output of PFET is VMCU.

C:\Altium Projects\B100\[AA]\Design Files\B100AA\Schematics\Main Power Switch.SchDoc

BuckBoost enable signal
pull-down resistor and
filter capacitor.

5V DC/DC Buck Boost Converter

C:\Altium Projects\B100\[AA]\Design Files\B100AA\Schematics\5V Buck Boost Converter.SchDoc

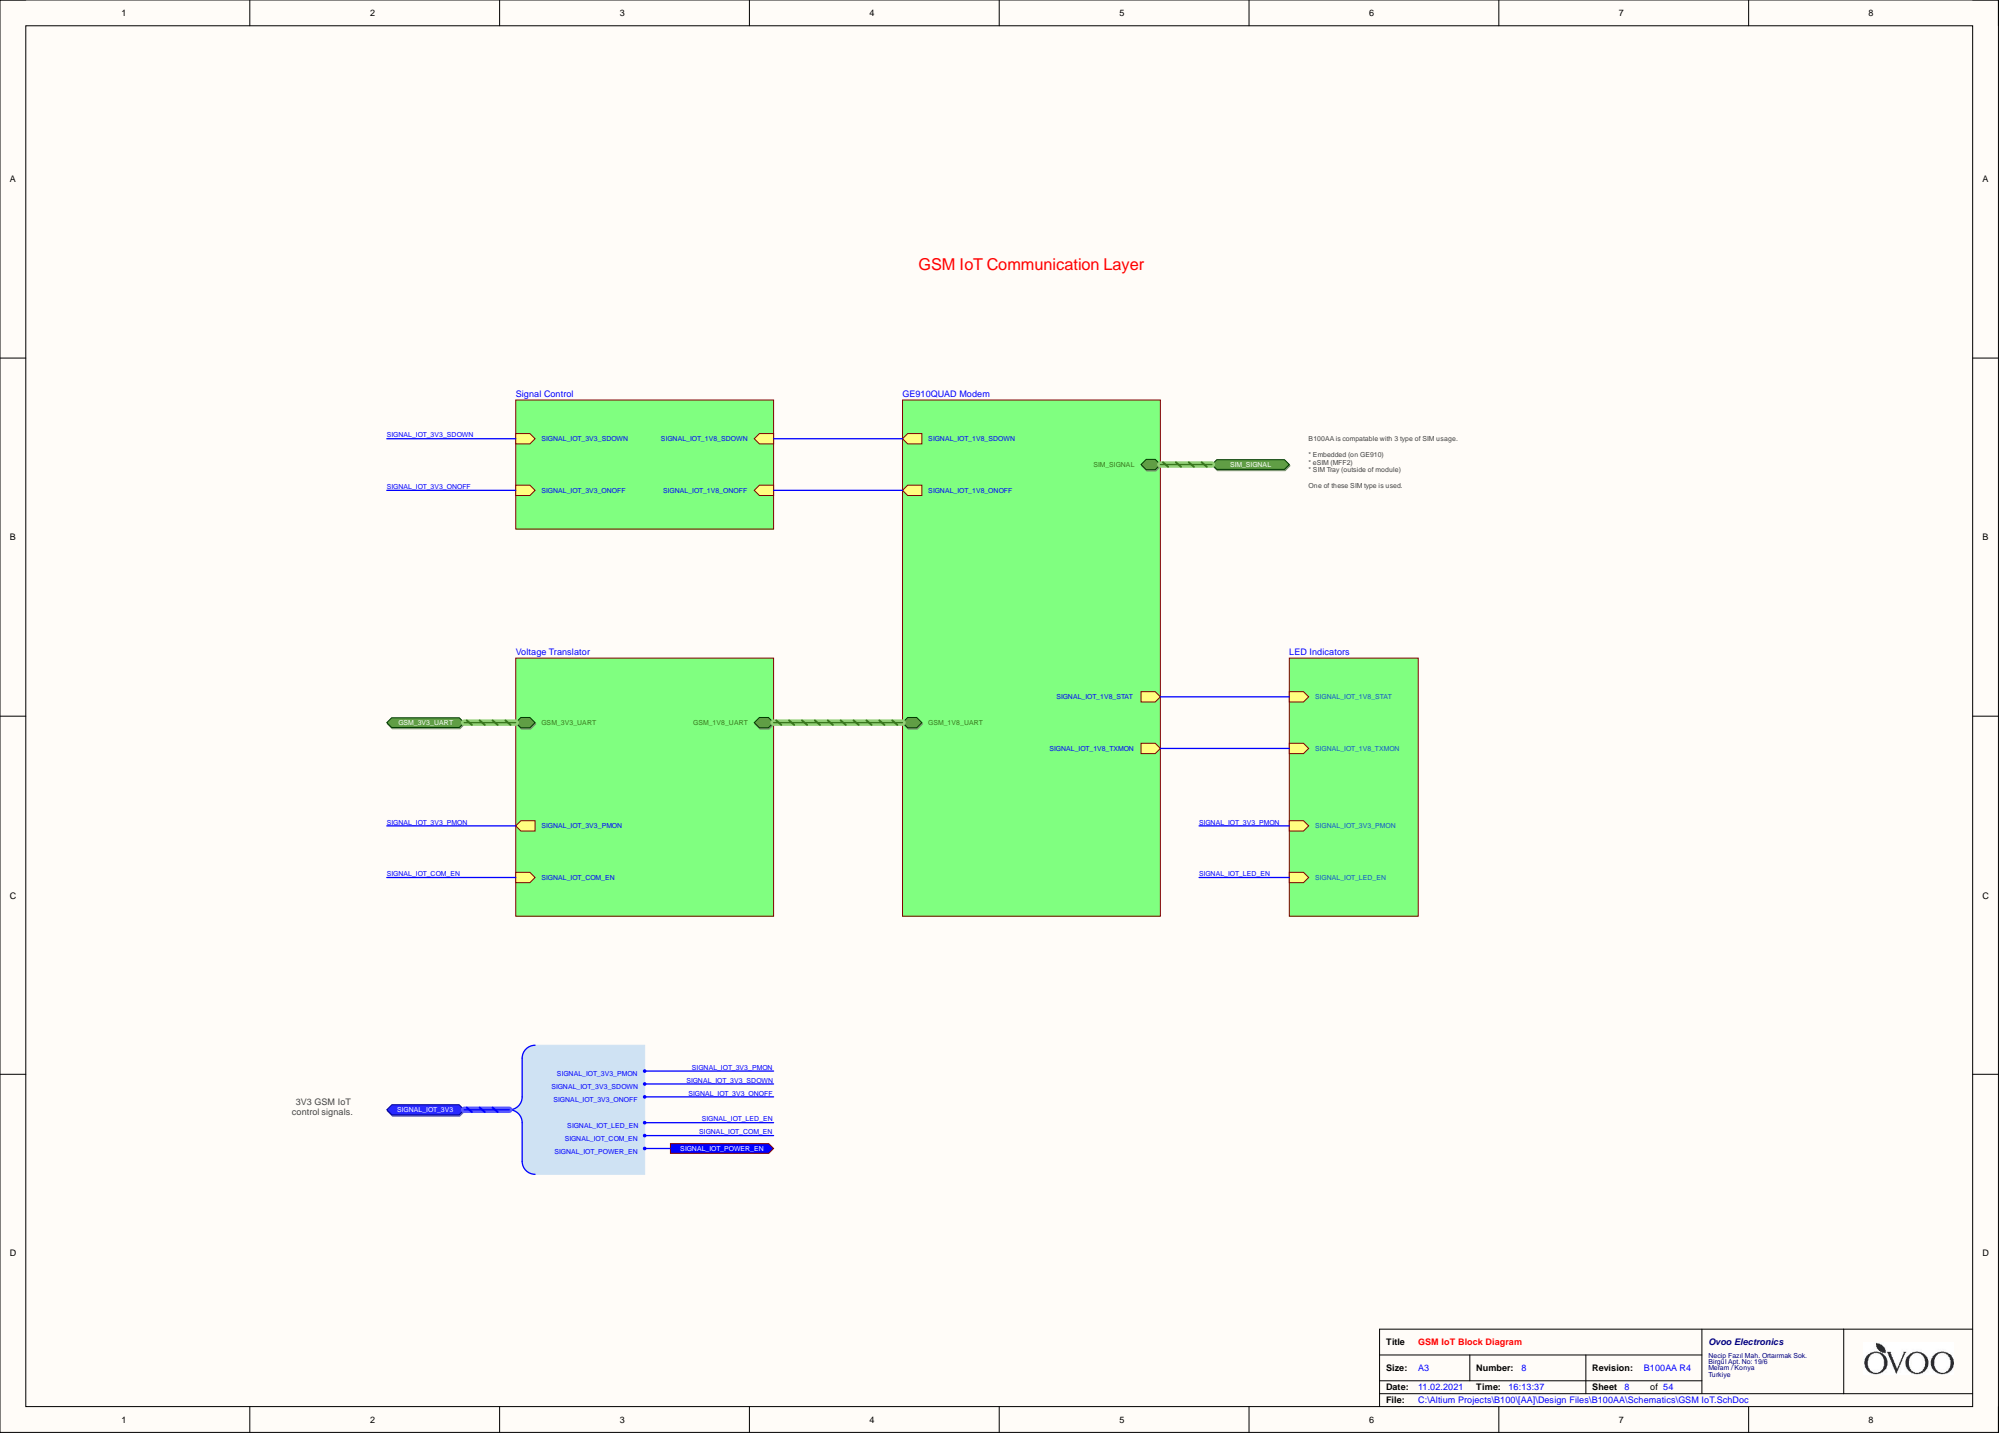
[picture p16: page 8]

GSM IoT Communication Layer

B100AA is compatable with 3 type of SIM usage.

* Embedded (on GE910)
* eSIM (MFF2)
* SIM Tray (outside of module)

One of these SIM type is used.

GSM IoT Block Diagram

C:\Altium Projects\B100\[AA]\Design Files\B100AA\Schematics\GSM IoT.SchDoc

B100AA is compatable with 3 type of SIM usage.
* Embedded (on GE910)
* eSIM (MFF2)
* SIM Tray (outside of module)

One of these SIM type is used.

GE910QUAD-V3 has no
GNSS option. These
pins are marked as NC.

B100AAhas no voice
option so Digital and
Analog voice pins
marked as NC.

ADC and RTC functions
are not used in B100AA.

Impedance Constraint [Min = 49.00 Max = 50.00 ] Power Plane Clearance [Clearance = 5.906mil] Width Constraint [Pref Width = 0.77mm Min Width = 0.77mm Max Width = 0.77mm]

External SIM (MFF2) is only
assembled when

RF Matching network
circuit is not placed on
production. Only 0R
resistor is placed.

C:\Altium Projects\B100\[AA]\Design Files\B100AA\Schematics\GE910QUAD Modem.SchDoc

GSM Module On/Off Signal

GSM Module Shut Down Signal

Signal line is controlled
by MCU digital pin. Line
is active high.

GSM Control Signal Management

C:\Altium Projects\B100\[AA]\Design Files\B100AA\Schematics\GSM Signal Control.SchDoc

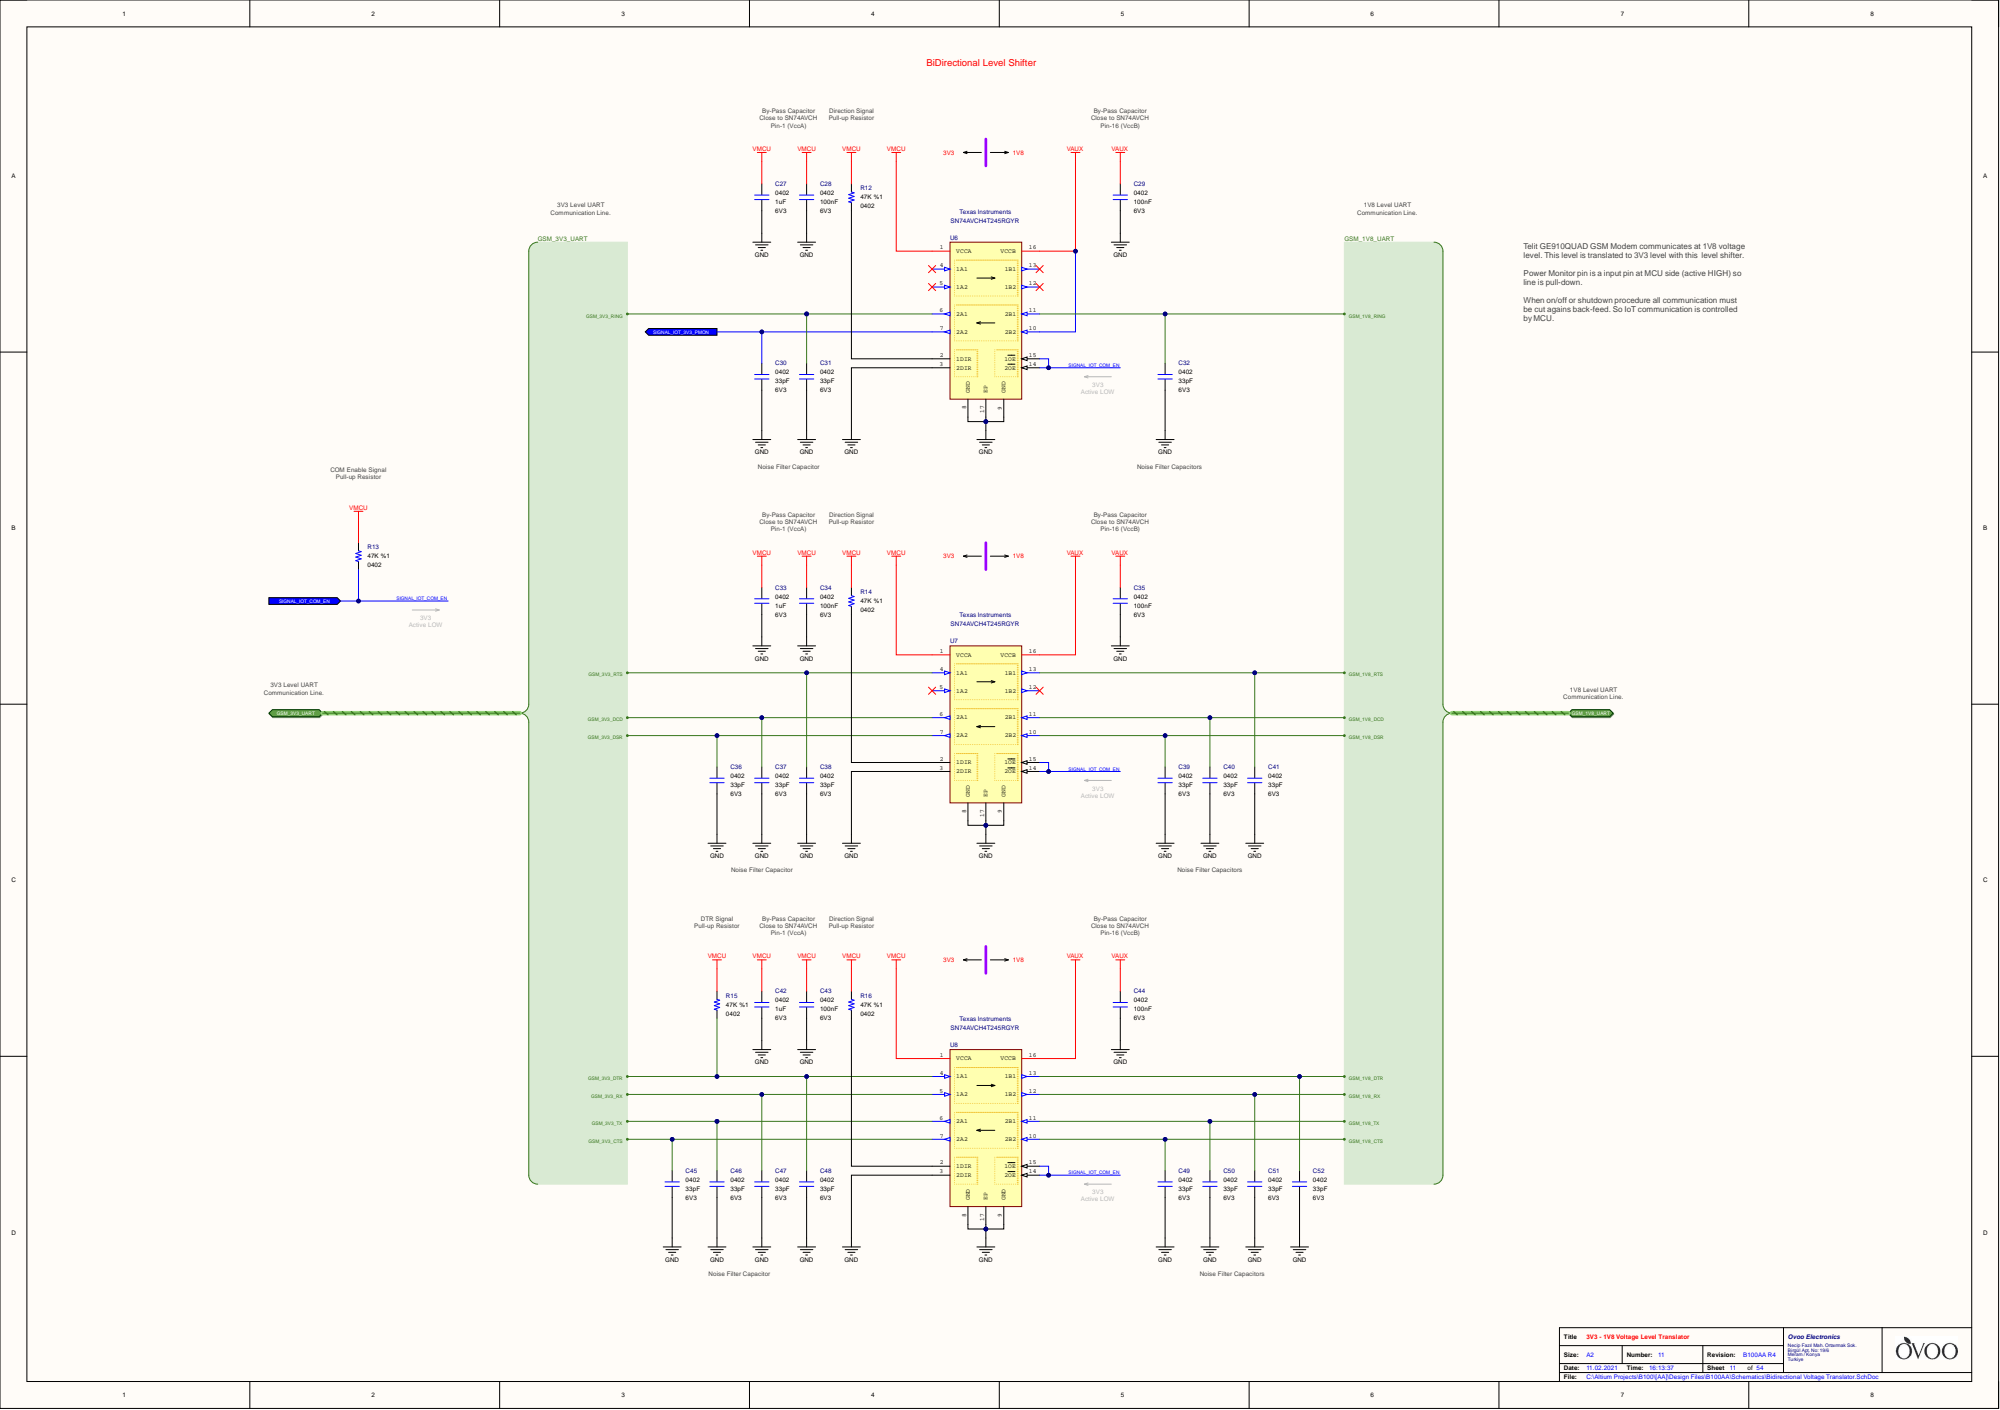
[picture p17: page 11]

Telit GE910QUAD GSM Modem communicates at 1V8 voltage
level. This level is translated to 3V3 level with this level shifter.

Power Monitor pin is a input pin at MCU side (active HIGH) so
line is pull-down.

When on/off or shutdown procedure all communication must
be cut agains back-feed. So IoT communication is controlled
by MCU.

1DIR 2
2DIR 3

C:\Altium Projects\B100\[AA]\Design Files\B100AA\Schematics\Bidirectional Voltage Translator.SchDoc

GSM IoT LED Indicators

Vf_BLUE : 3V4 I_LED : 20 mA

Line pull-down and
filter capacitor are
on voltage translator

Noise filter
capacitors. Place as
close as possible to

LED activates according to
connection. Fast blinking LED
is indicates searching GSM
connection. Slow blinking LED
is indicates GSM connection is

LED activates when GSM
modem powered. This LED is a
active HIGH inducator.

modem sending data to

GSM Modem Signal Indicator LED's

C:\Altium Projects\B100\[AA]\Design Files\B100AA\Schematics\GSM LED Indicators.SchDoc

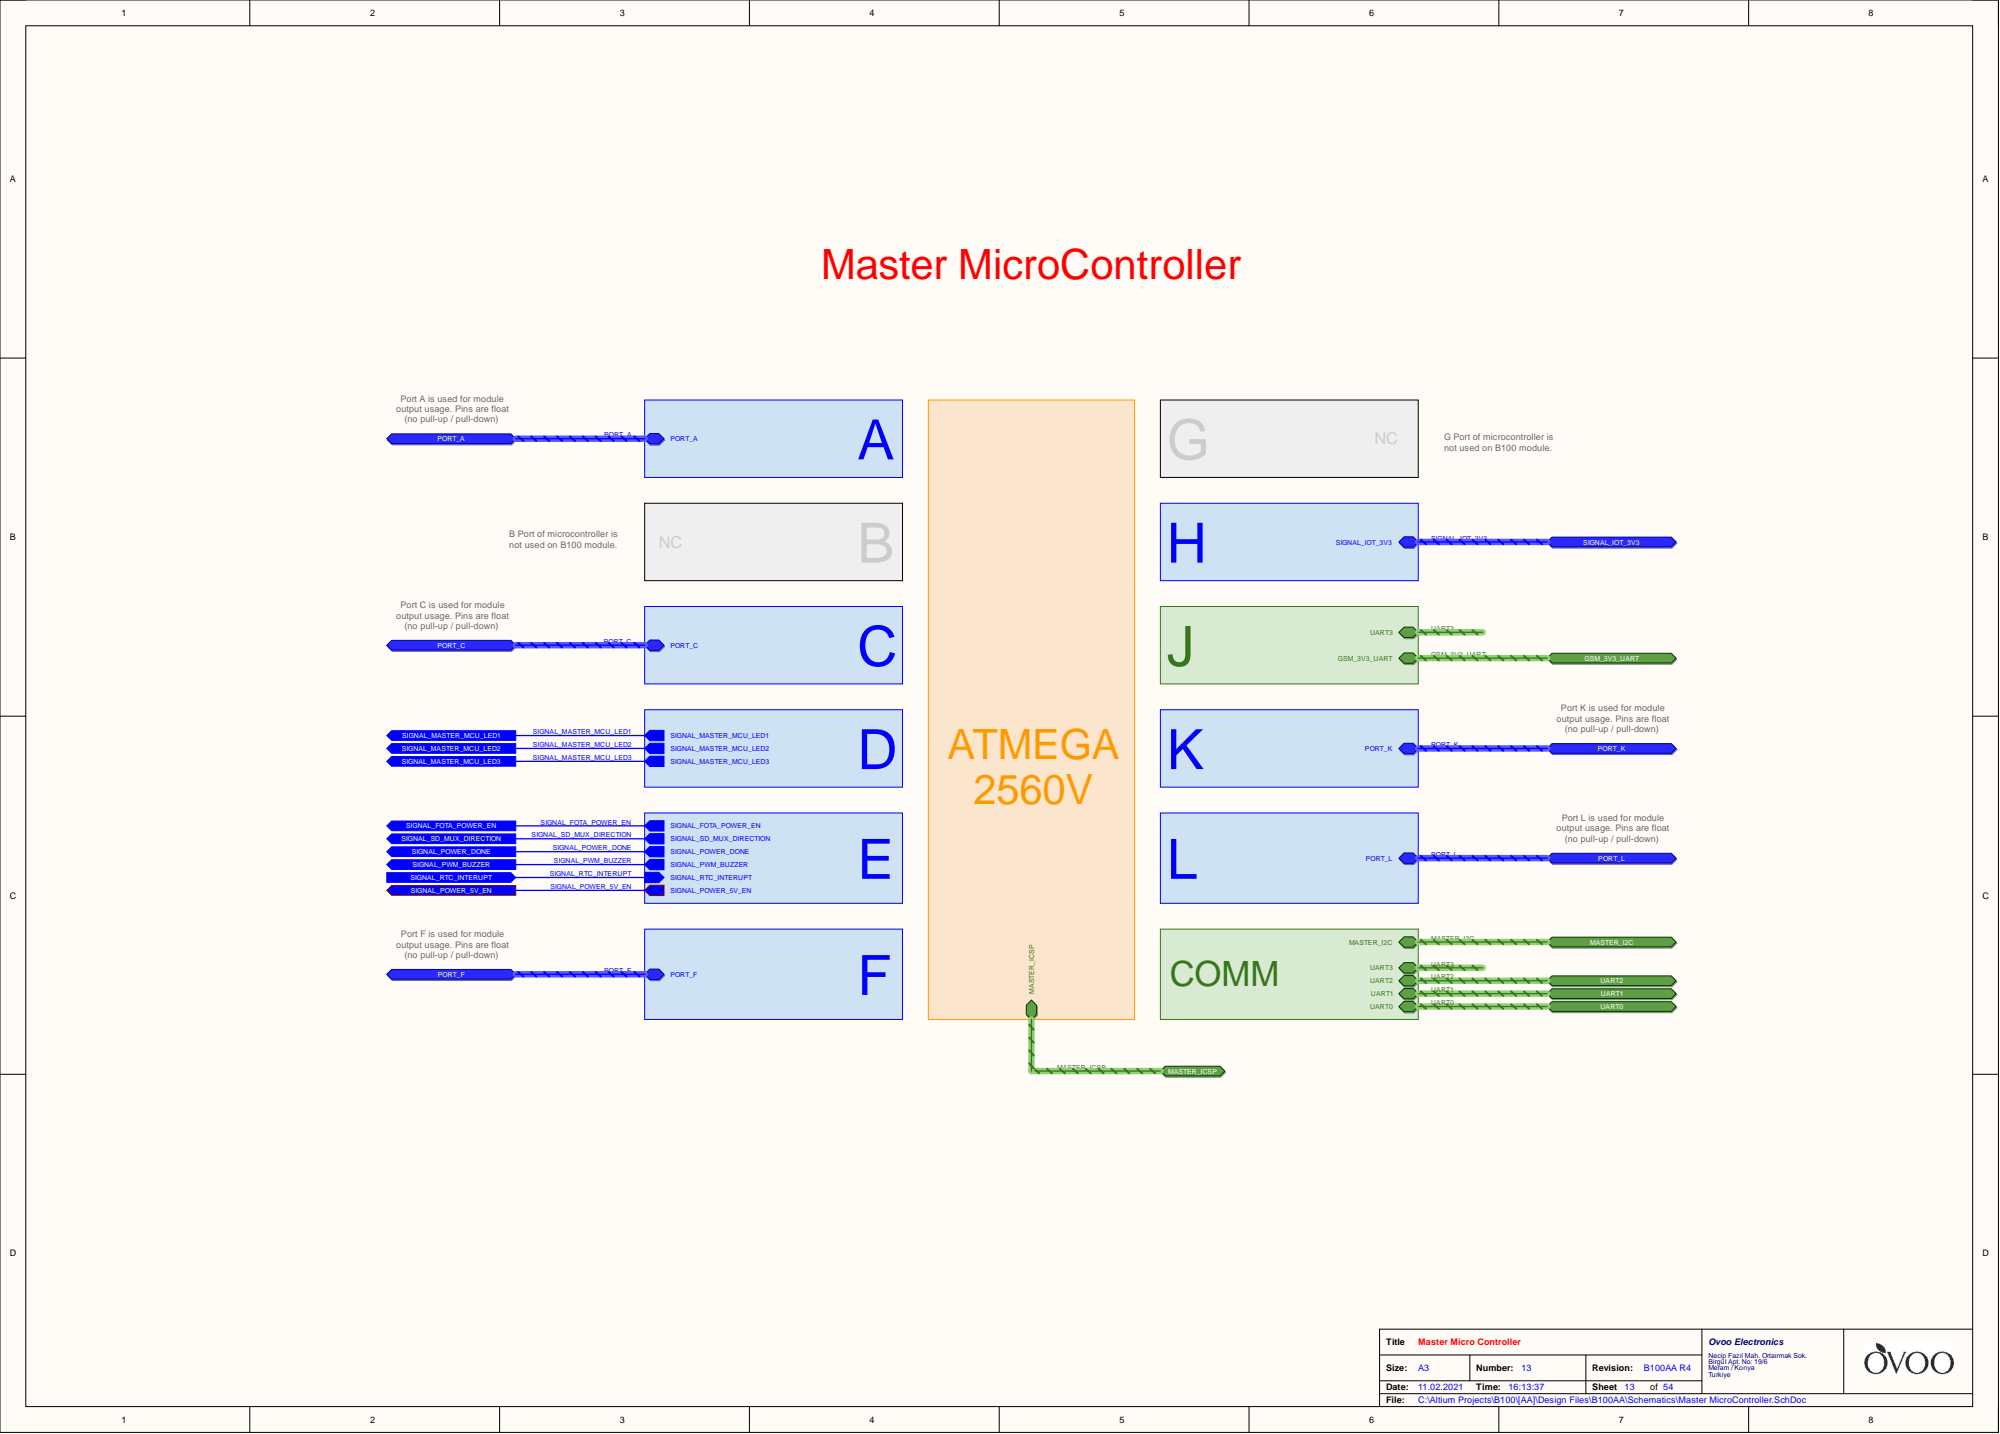
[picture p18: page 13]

Port A is used for module
output usage. Pins are float
(no pull-up / pull-down)

G Port of microcontroller is
not used on B100 module.

B Port of microcontroller is

Port C is used for module

Port K is used for module

Port L is used for module

Port F is used for module

C:\Altium Projects\B100\[AA]\Design Files\B100AA\Schematics\Master MicroController.SchDoc

FOTA MicroController Power Trigger

SD Card and Select Switch

C:\Altium Projects\B100\[AA]\Design Files\B100AA\Schematics\MicroController.SchDoc

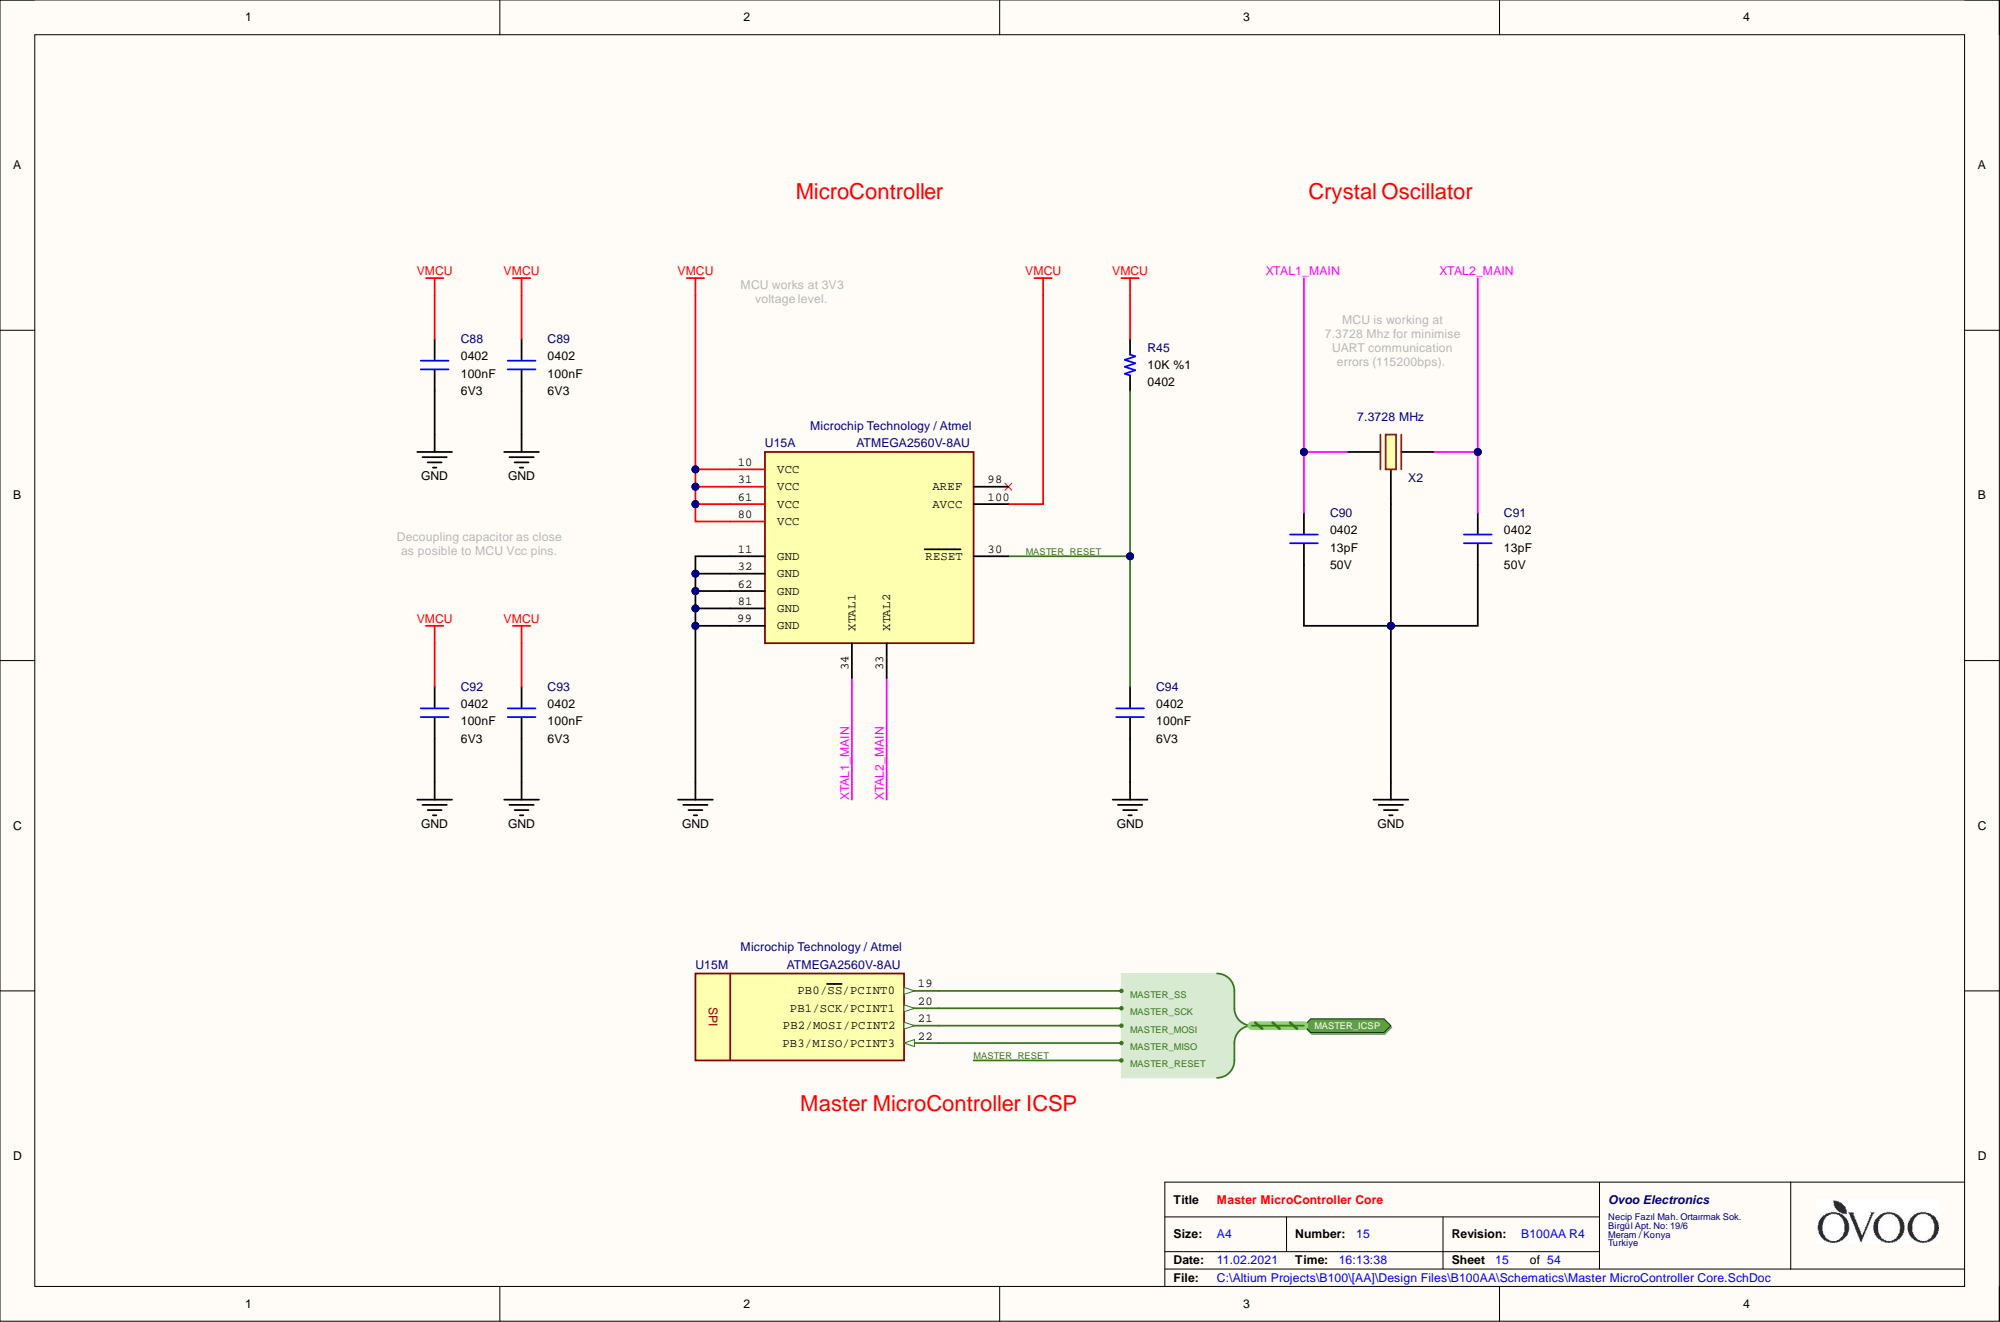
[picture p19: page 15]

MCU is working at
7.3728 Mhz for minimise
UART communication
errors (115200bps).

Decoupling capacitor as close
as posible to MCU Vcc pins.

C:\Altium Projects\B100\[AA]\Design Files\B100AA\Schematics\Master MicroController Core.SchDoc

Master Micro Controller Port A Pin Out

C:\Altium Projects\B100\[AA]\Design Files\B100AA\Schematics\Master MicroController Port A.SchDoc

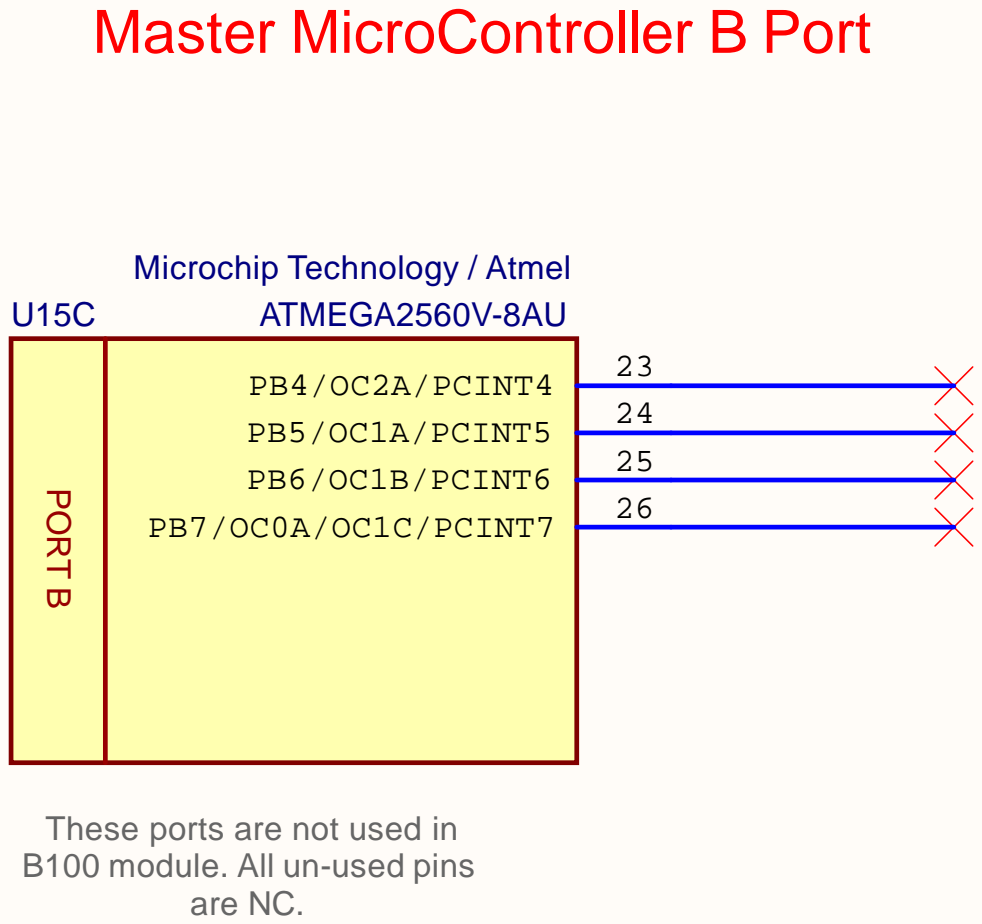
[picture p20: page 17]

These ports are not used in
B100 module. All un-used pins

Master Micro Controller Port B Pin Out

C:\Altium Projects\B100\[AA]\Design Files\B100AA\Schematics\Master MicroController Port B.SchDoc

Master Micro Controller Port C Pin Out

C:\Altium Projects\B100\[AA]\Design Files\B100AA\Schematics\Master MicroController Port C.SchDoc

Micro controller based RGB
LED outputs. These outputs
are controlled in firmware.

Master Micro Controller Port D Pin Out

C:\Altium Projects\B100\[AA]\Design Files\B100AA\Schematics\Master MicroController Port D.SchDoc

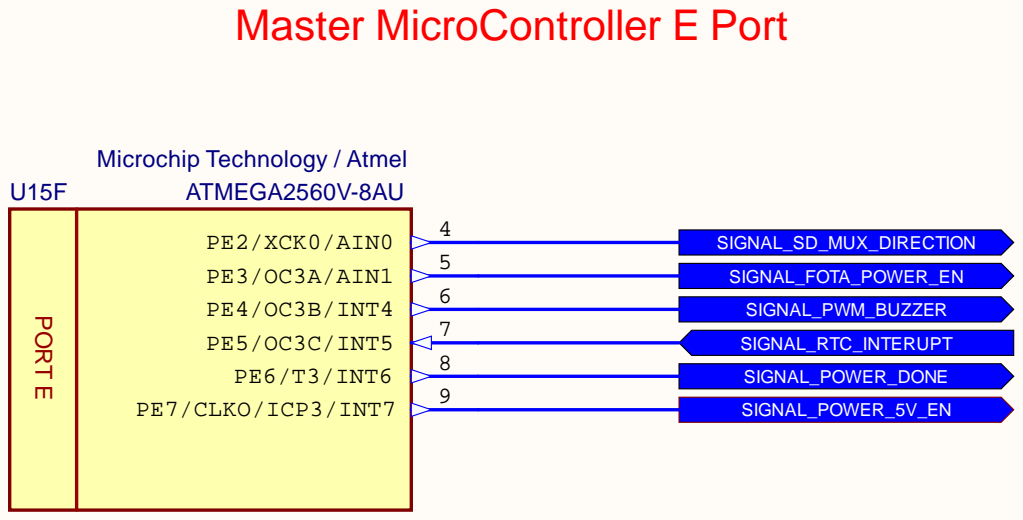
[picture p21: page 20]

Master Micro Controller Port E Pin Out

C:\Altium Projects\B100\[AA]\Design Files\B100AA\Schematics\Master MicroController Port E.SchDoc

Master Micro Controller Port F Pin Out

C:\Altium Projects\B100\[AA]\Design Files\B100AA\Schematics\Master MicroController Port F.SchDoc

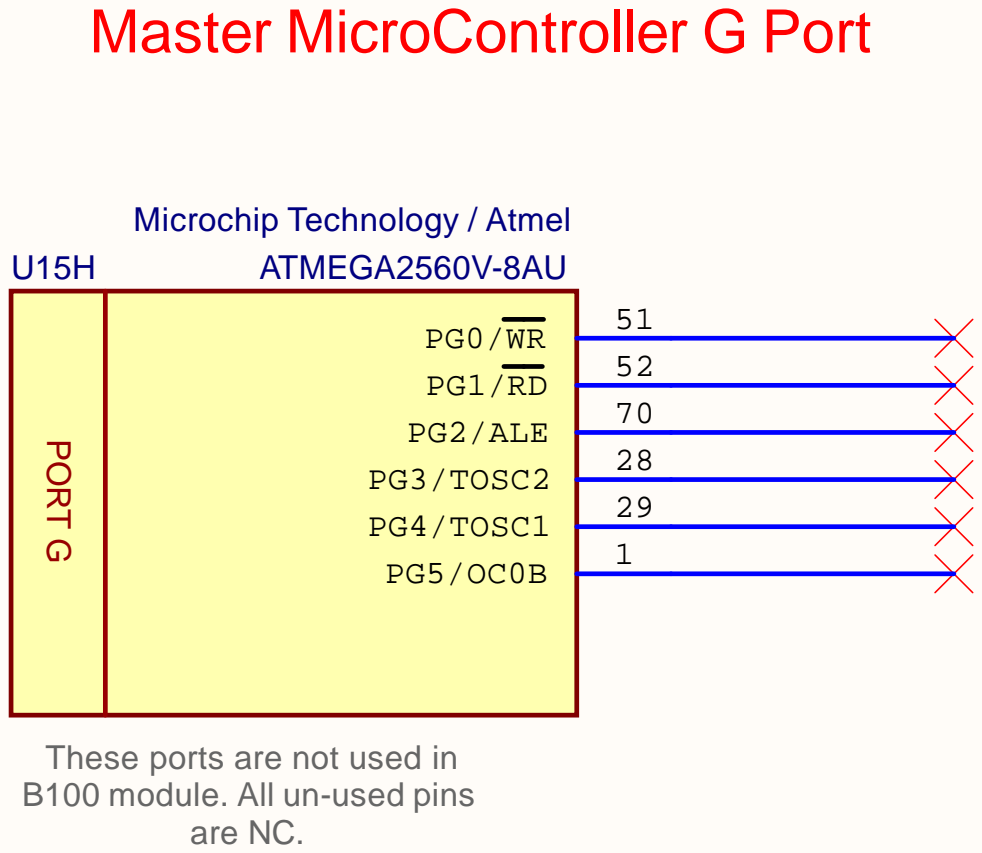
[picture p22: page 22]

These ports are not used in
B100 module. All un-used pins

Master Micro Controller Port G Pin Out

C:\Altium Projects\B100\[AA]\Design Files\B100AA\Schematics\Master MicroController Port G.SchDoc

Master Micro Controller Port H Pin Out

C:\Altium Projects\B100\[AA]\Design Files\B100AA\Schematics\Master MicroController Port H.SchDoc

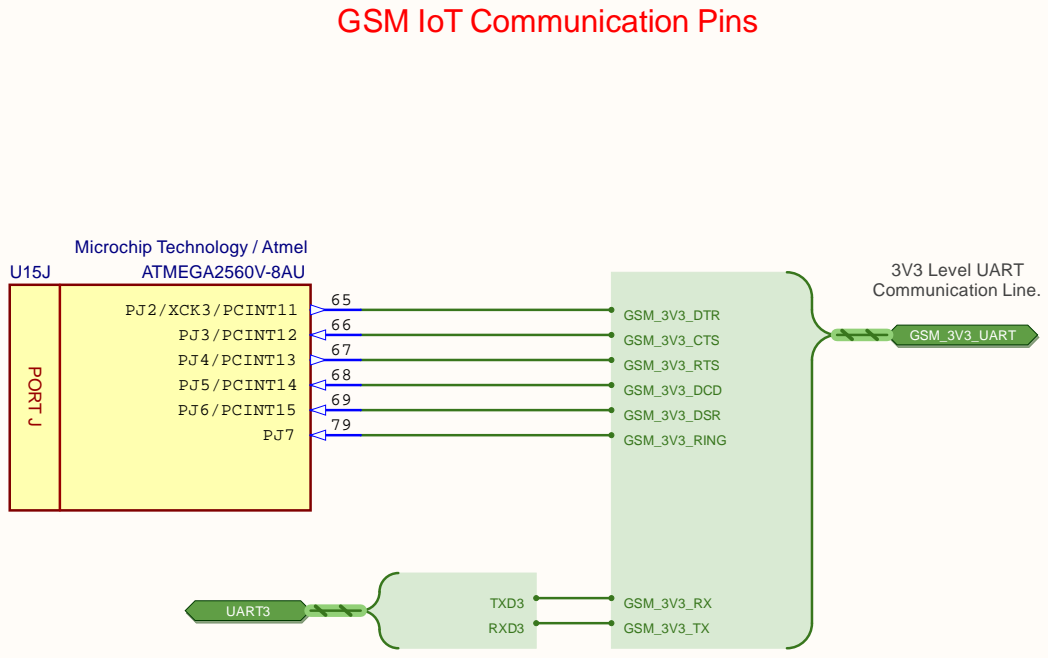
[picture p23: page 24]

GSM IoT Communication Pins

Master Micro Controller Port J Pin Out

C:\Altium Projects\B100\[AA]\Design Files\B100AA\Schematics\Master MicroController Port J.SchDoc

Master Micro Controller Port K Pin Out

C:\Altium Projects\B100\[AA]\Design Files\B100AA\Schematics\Master MicroController Port K.SchDoc

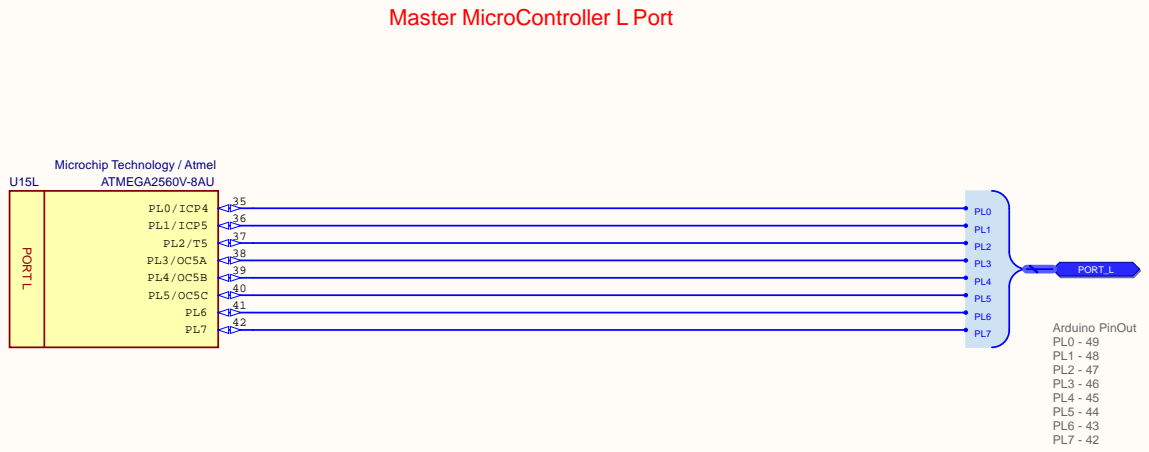
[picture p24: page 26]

Master Micro Controller Port L Pin Out

C:\Altium Projects\B100\[AA]\Design Files\B100AA\Schematics\Master MicroController Port L.SchDoc

UART0

UART1

UART2

UART3

Master MicroController Communication Port Pin Out

C:\Altium Projects\B100\[AA]\Design Files\B100AA\Schematics\Master MicroController Serial Communication Port.SchDoc

Main Microcontroller Status LED Indicators

C:\Altium Projects\B100\[AA]\Design Files\B100AA\Schematics\Master MicroController LED.SchDoc

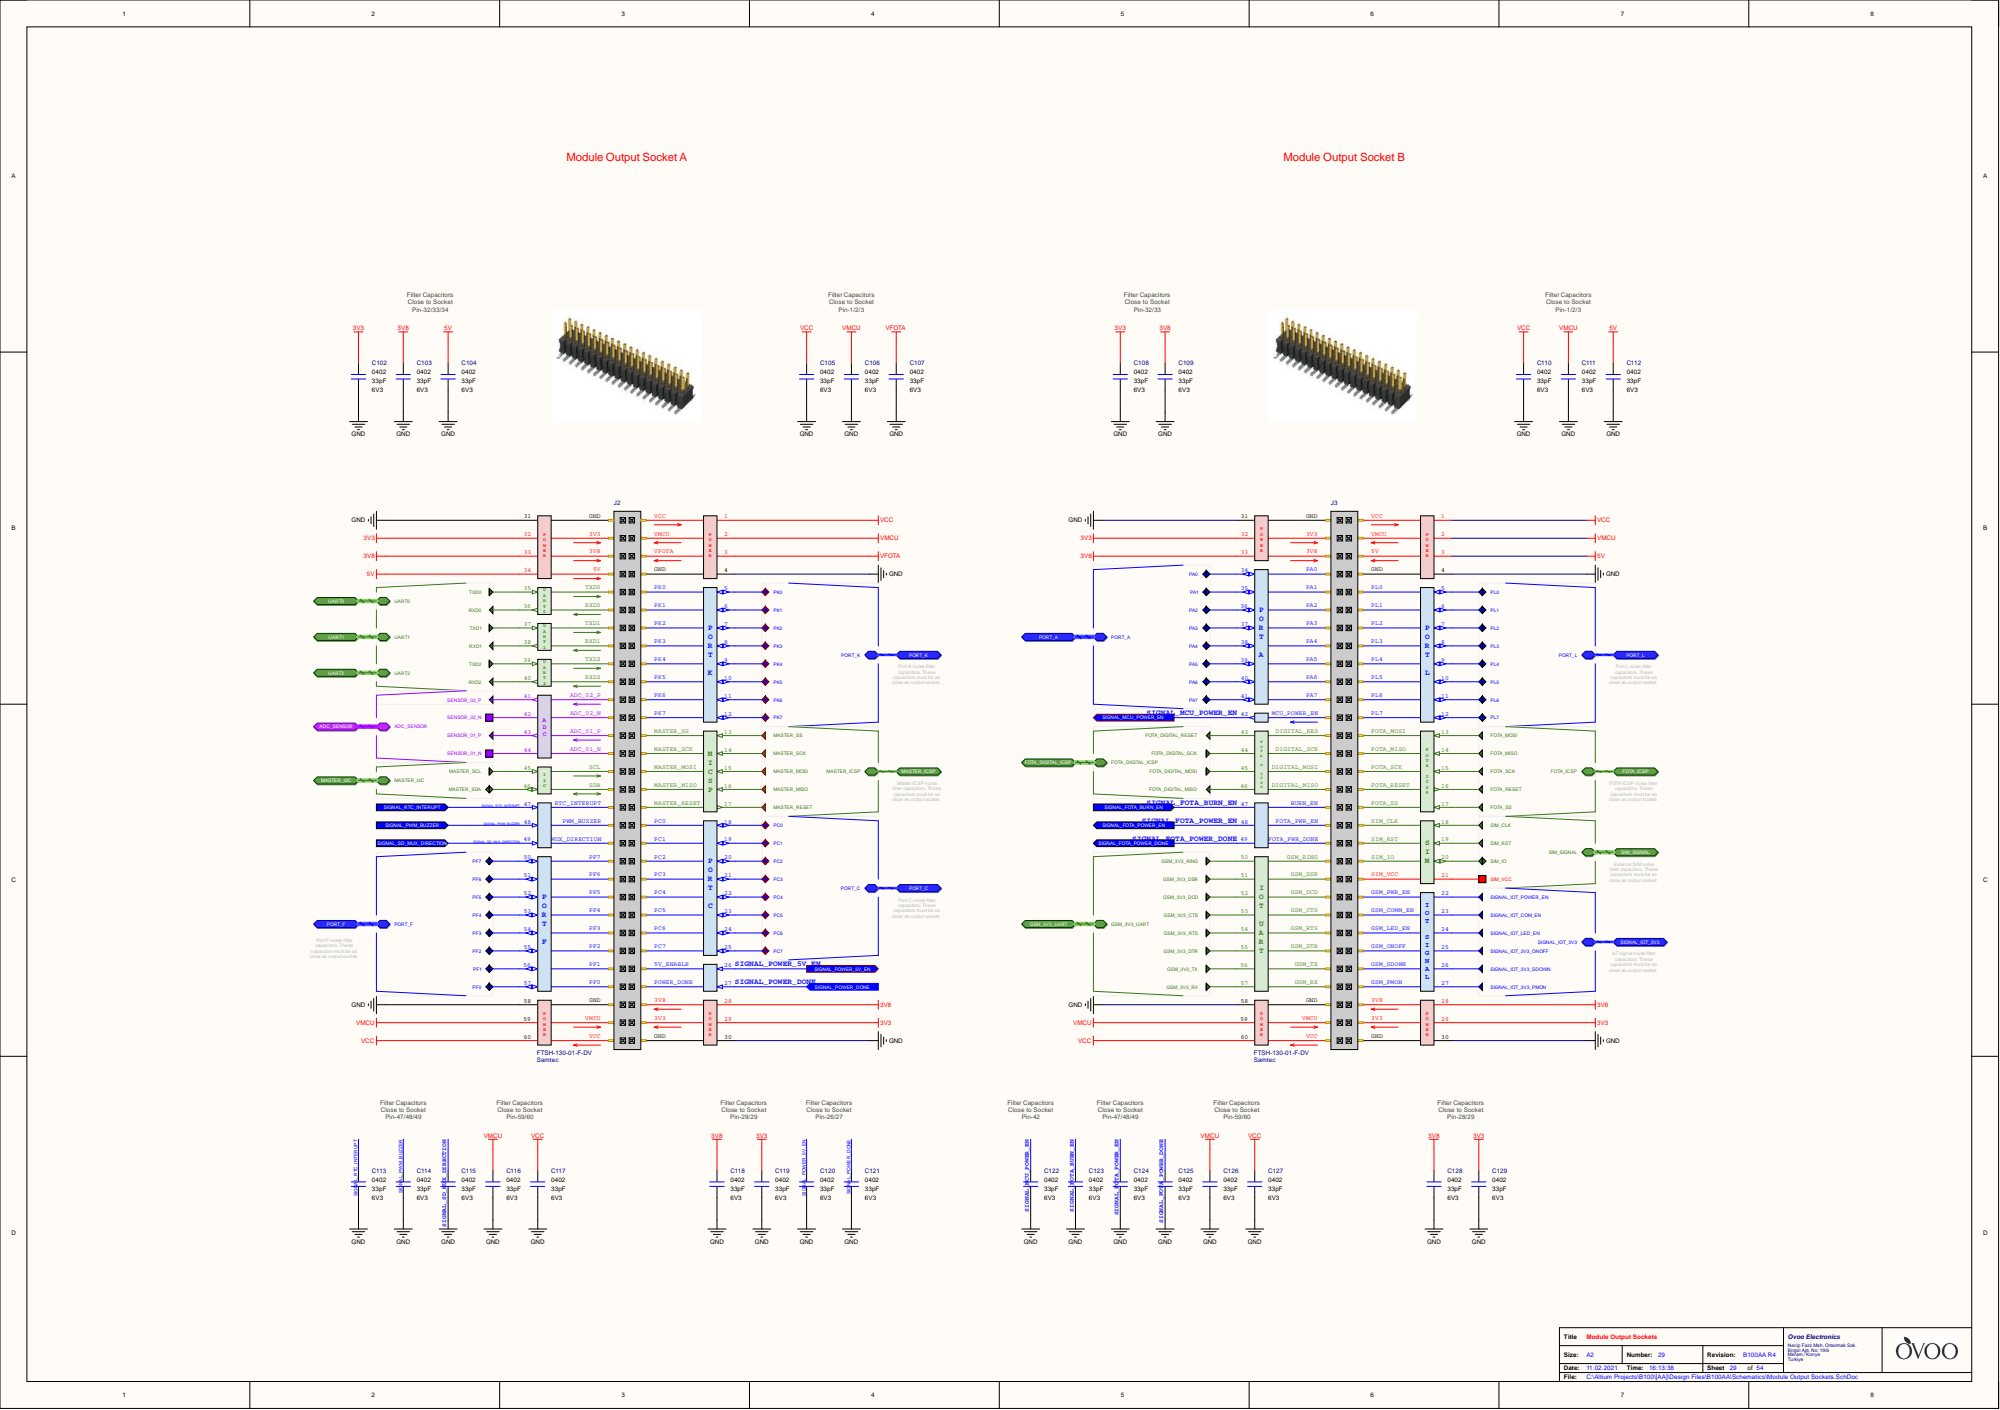
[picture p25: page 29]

Port K noise filter
capacitors. These
capacitors must be as
close as output socket.

Port L noise filter

42 | | ADC_02_N | PK7 | 12 | PL7 | 12
43 44 | A D C | ADC_01_P ADC_01_N

Master ICSP noise
filter capacitors. These

FOTA ICSP noise filter

External SIM noise

Port C noise filter

Port F noise filter

IoT signal noise filter

C:\Altium Projects\B100\[AA]\Design Files\B100AA\Schematics\Module Output Sockets.SchDoc

Port C Output Socket Noise Capacitors

Port C noise filter
capacitors. These
capacitors must be as
close as output socket.

C:\Altium Projects\B100\[AA]\Design Files\B100AA\Schematics\Filter Capacitors - Port C.SchDoc

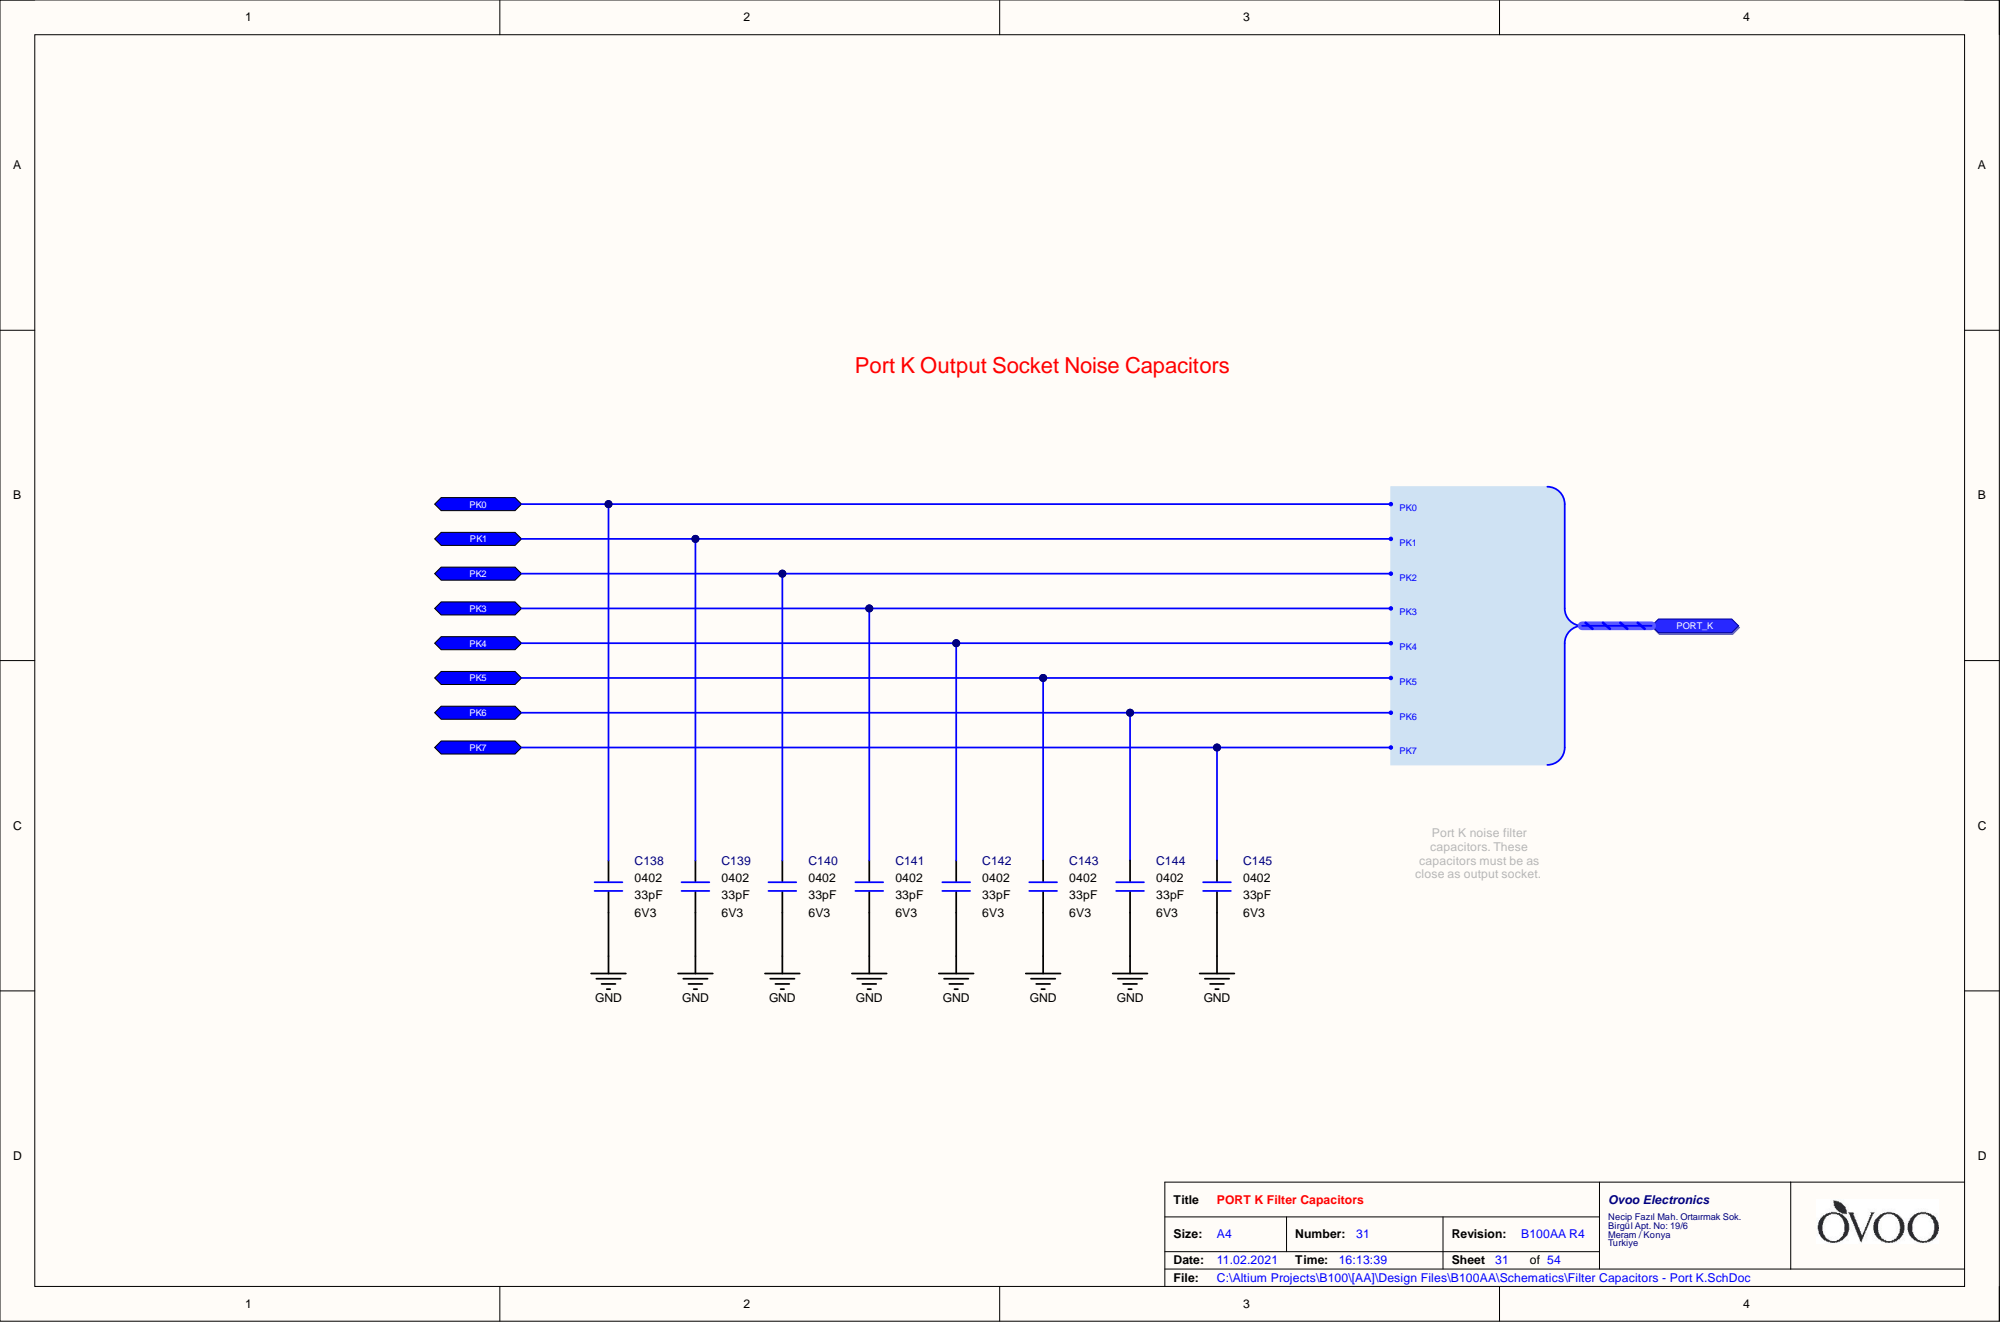
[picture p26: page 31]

Port K Output Socket Noise Capacitors

Port K noise filter
capacitors. These
capacitors must be as
close as output socket.

C:\Altium Projects\B100\[AA]\Design Files\B100AA\Schematics\Filter Capacitors - Port K.SchDoc

Port L Output Socket Noise Capacitors

Port L noise filter
capacitors. These
capacitors must be as
close as output socket.

C:\Altium Projects\B100\[AA]\Design Files\B100AA\Schematics\Filter Capacitors - Port L.SchDoc

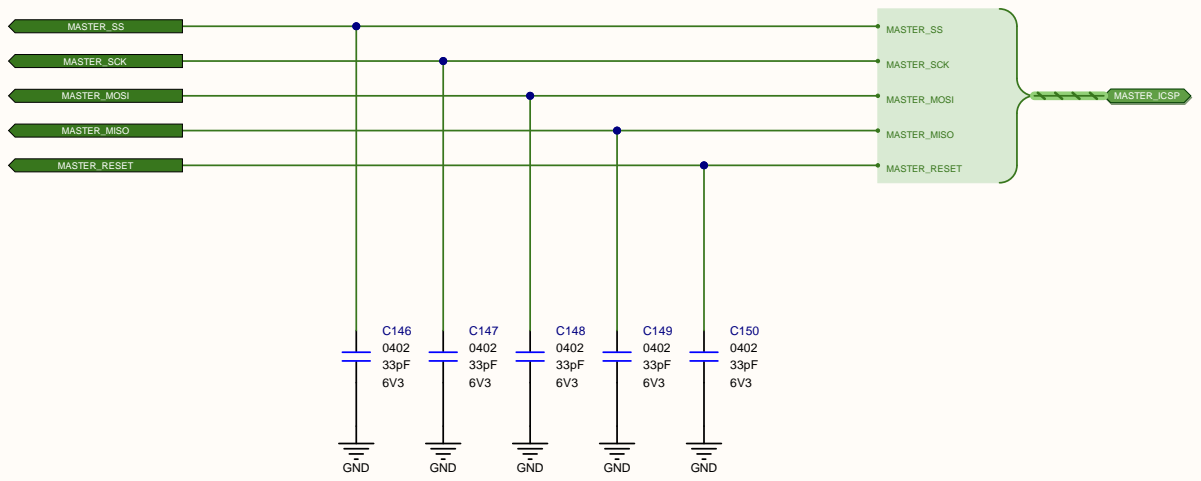
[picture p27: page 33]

Master ICSP Filter Capacitors

C:\Altium Projects\B100\[AA]\Design Files\B100AA\Schematics\Filter Capacitors - Master ICSP.SchDoc

FOTA ICSP Filter Capacitors

C:\Altium Projects\B100\[AA]\Design Files\B100AA\Schematics\Filter Capacitors - FOTA ICSP.SchDoc

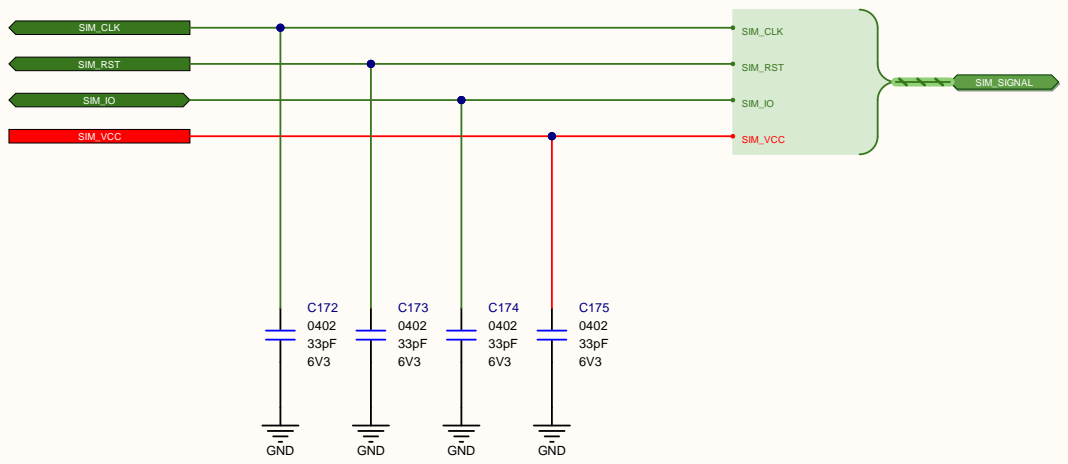
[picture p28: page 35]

External SIM Filter Capacitors

C:\Altium Projects\B100\[AA]\Design Files\B100AA\Schematics\Filter Capacitors - External SIM.SchDoc

Signal IoT Output Socket Noise Capacitors

Signal IoT noise filter
capacitors. These
capacitors must be as
close as output socket.

Signal IoT Filter Capacitors

C:\Altium Projects\B100\[AA]\Design Files\B100AA\Schematics\Filter Capacitors - Signal IoT.SchDoc

Port A Output Socket Noise Capacitors

Port A noise filter
capacitors. These
capacitors must be as
close as output socket.

C:\Altium Projects\B100\[AA]\Design Files\B100AA\Schematics\Filter Capacitors - Port A.SchDoc

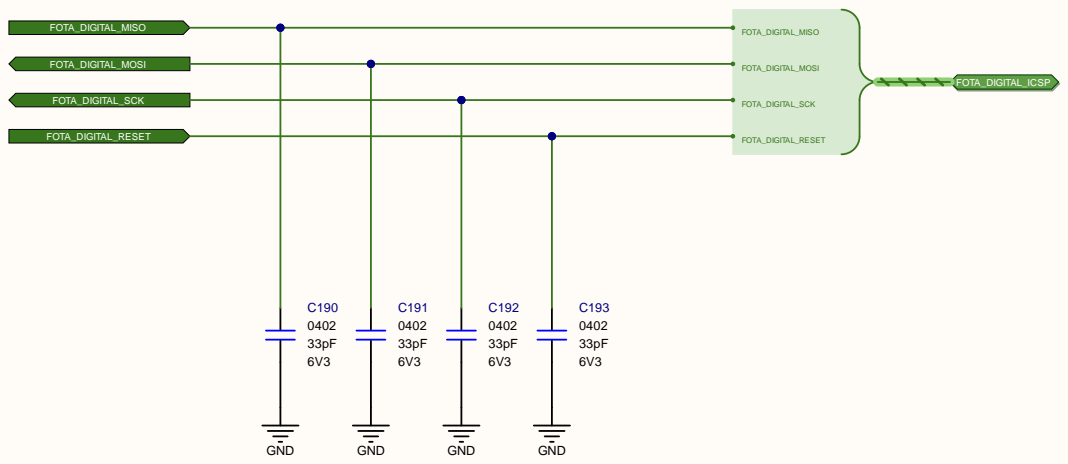
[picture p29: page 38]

FOTA Digital ICSP Filter Capacitors

C:\Altium Projects\B100\[AA]\Design Files\B100AA\Schematics\Filter Capacitors - FOTA Digital ICSP.SchDoc

IoT UART Output Socket Noise Capacitors

Port C noise filter
capacitors. These
capacitors must be as
close as output socket.

IoT UART Filter Capacitors

C:\Altium Projects\B100\[AA]\Design Files\B100AA\Schematics\Filter Capacitors - IoT UART.SchDoc

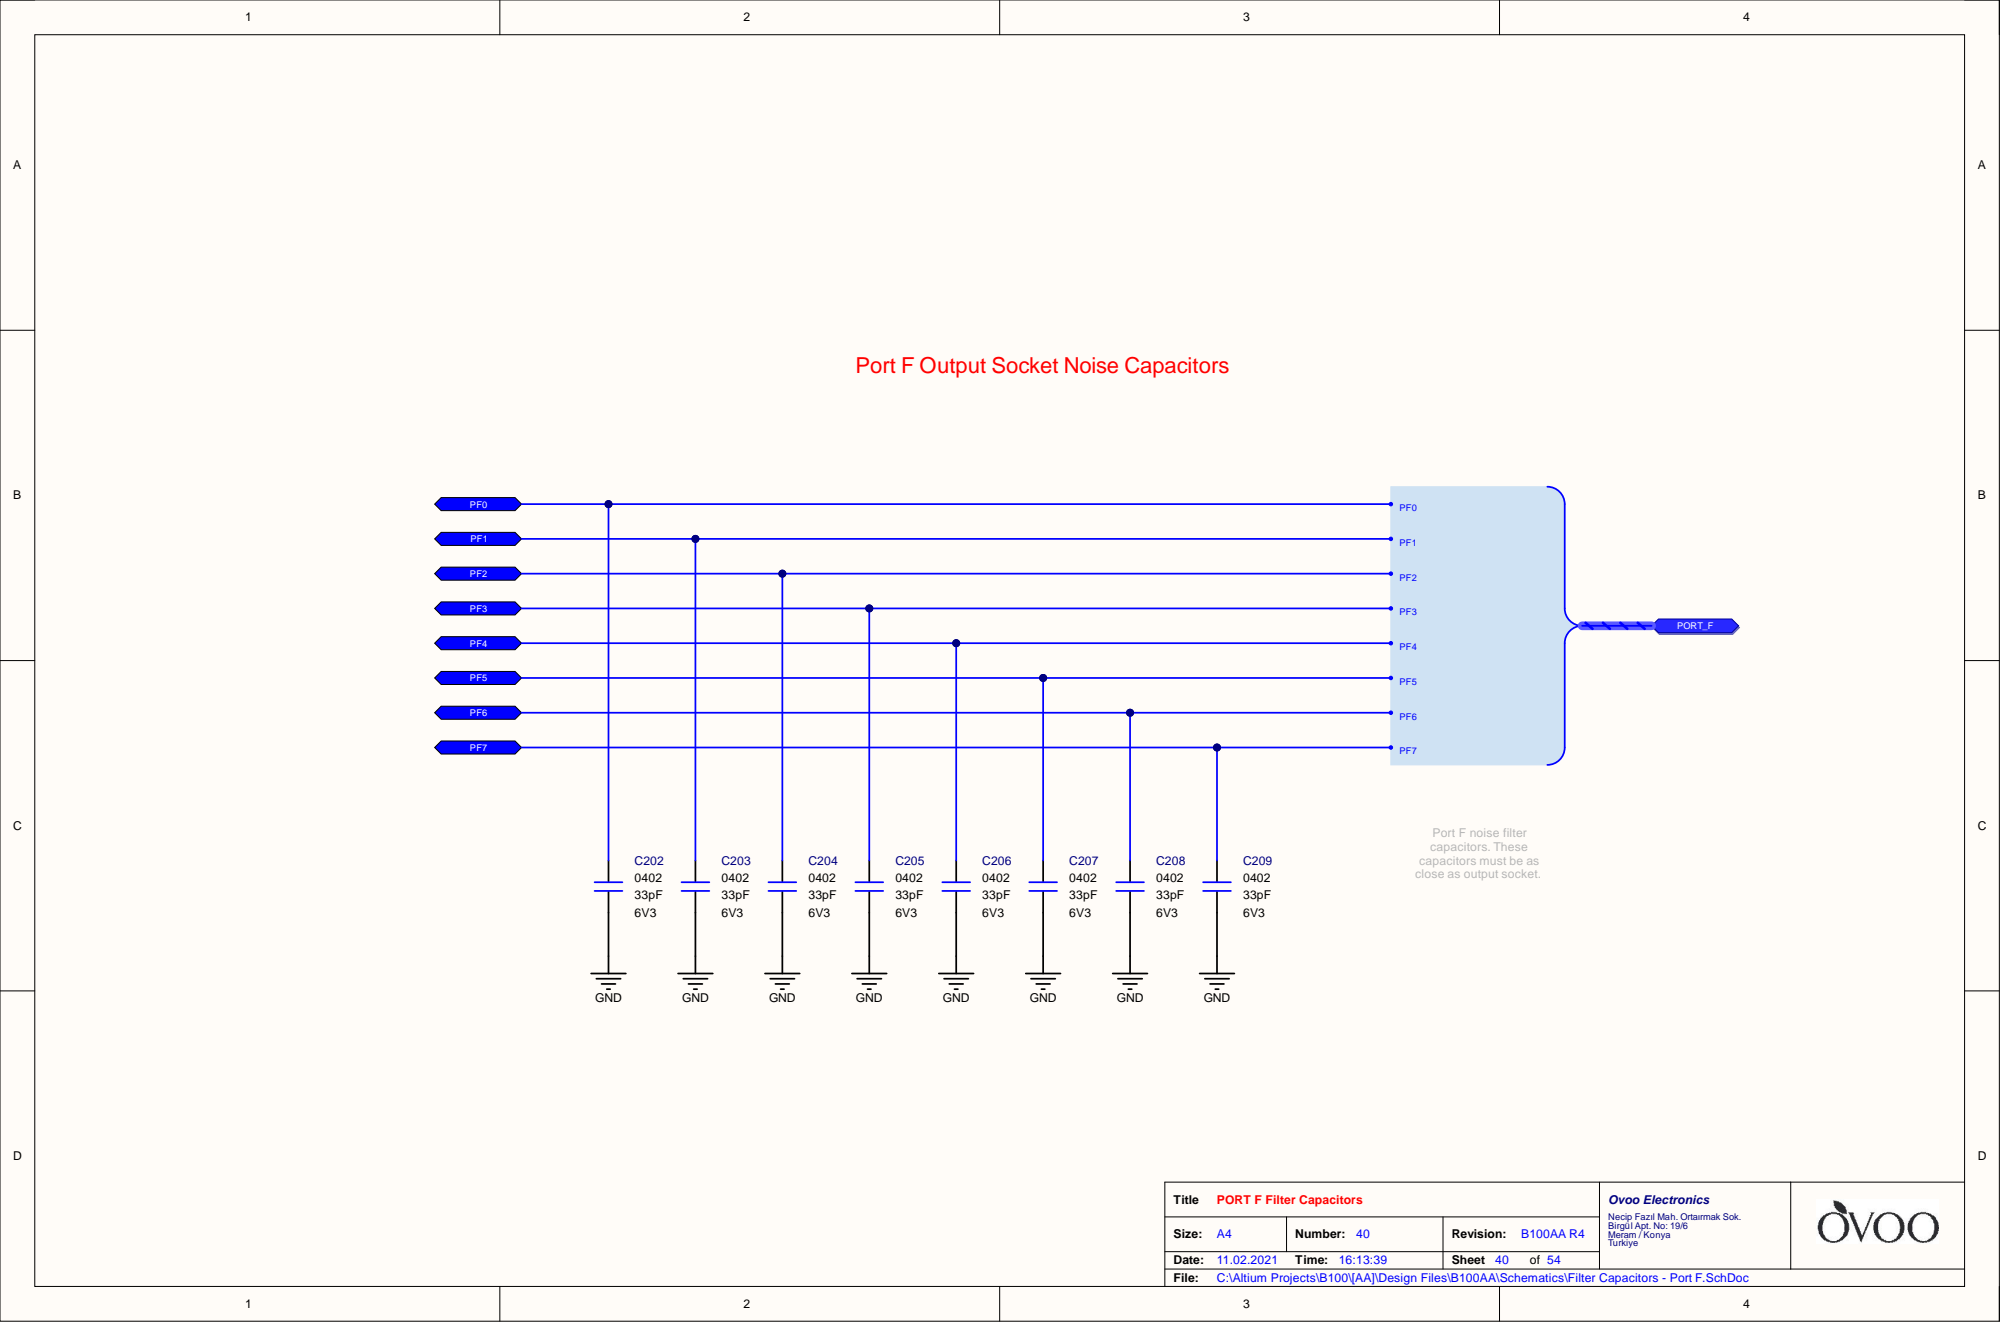
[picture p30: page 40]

Port F Output Socket Noise Capacitors

Port F noise filter
capacitors. These
capacitors must be as
close as output socket.

C:\Altium Projects\B100\[AA]\Design Files\B100AA\Schematics\Filter Capacitors - Port F.SchDoc

Serial Communication Filter Capacitors

C:\Altium Projects\B100\[AA]\Design Files\B100AA\Schematics\Filter Capacitors - Serial Communication.SchDoc

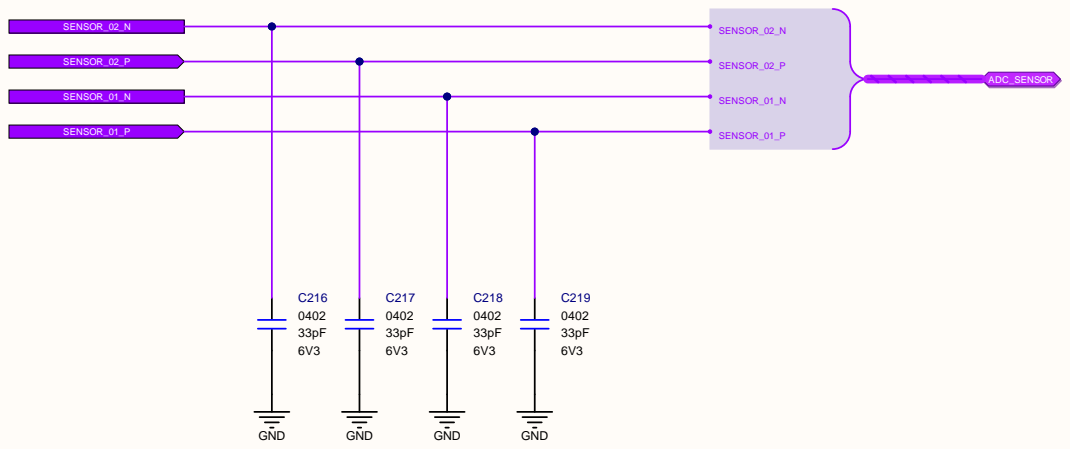
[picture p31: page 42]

ADC Sensor Filter Capacitors

C:\Altium Projects\B100\[AA]\Design Files\B100AA\Schematics\Filter Capacitors - ADC Sensor.SchDoc

C:\Altium Projects\B100\[AA]\Design Files\B100AA\Schematics\Filter Capacitors - I2C.SchDoc

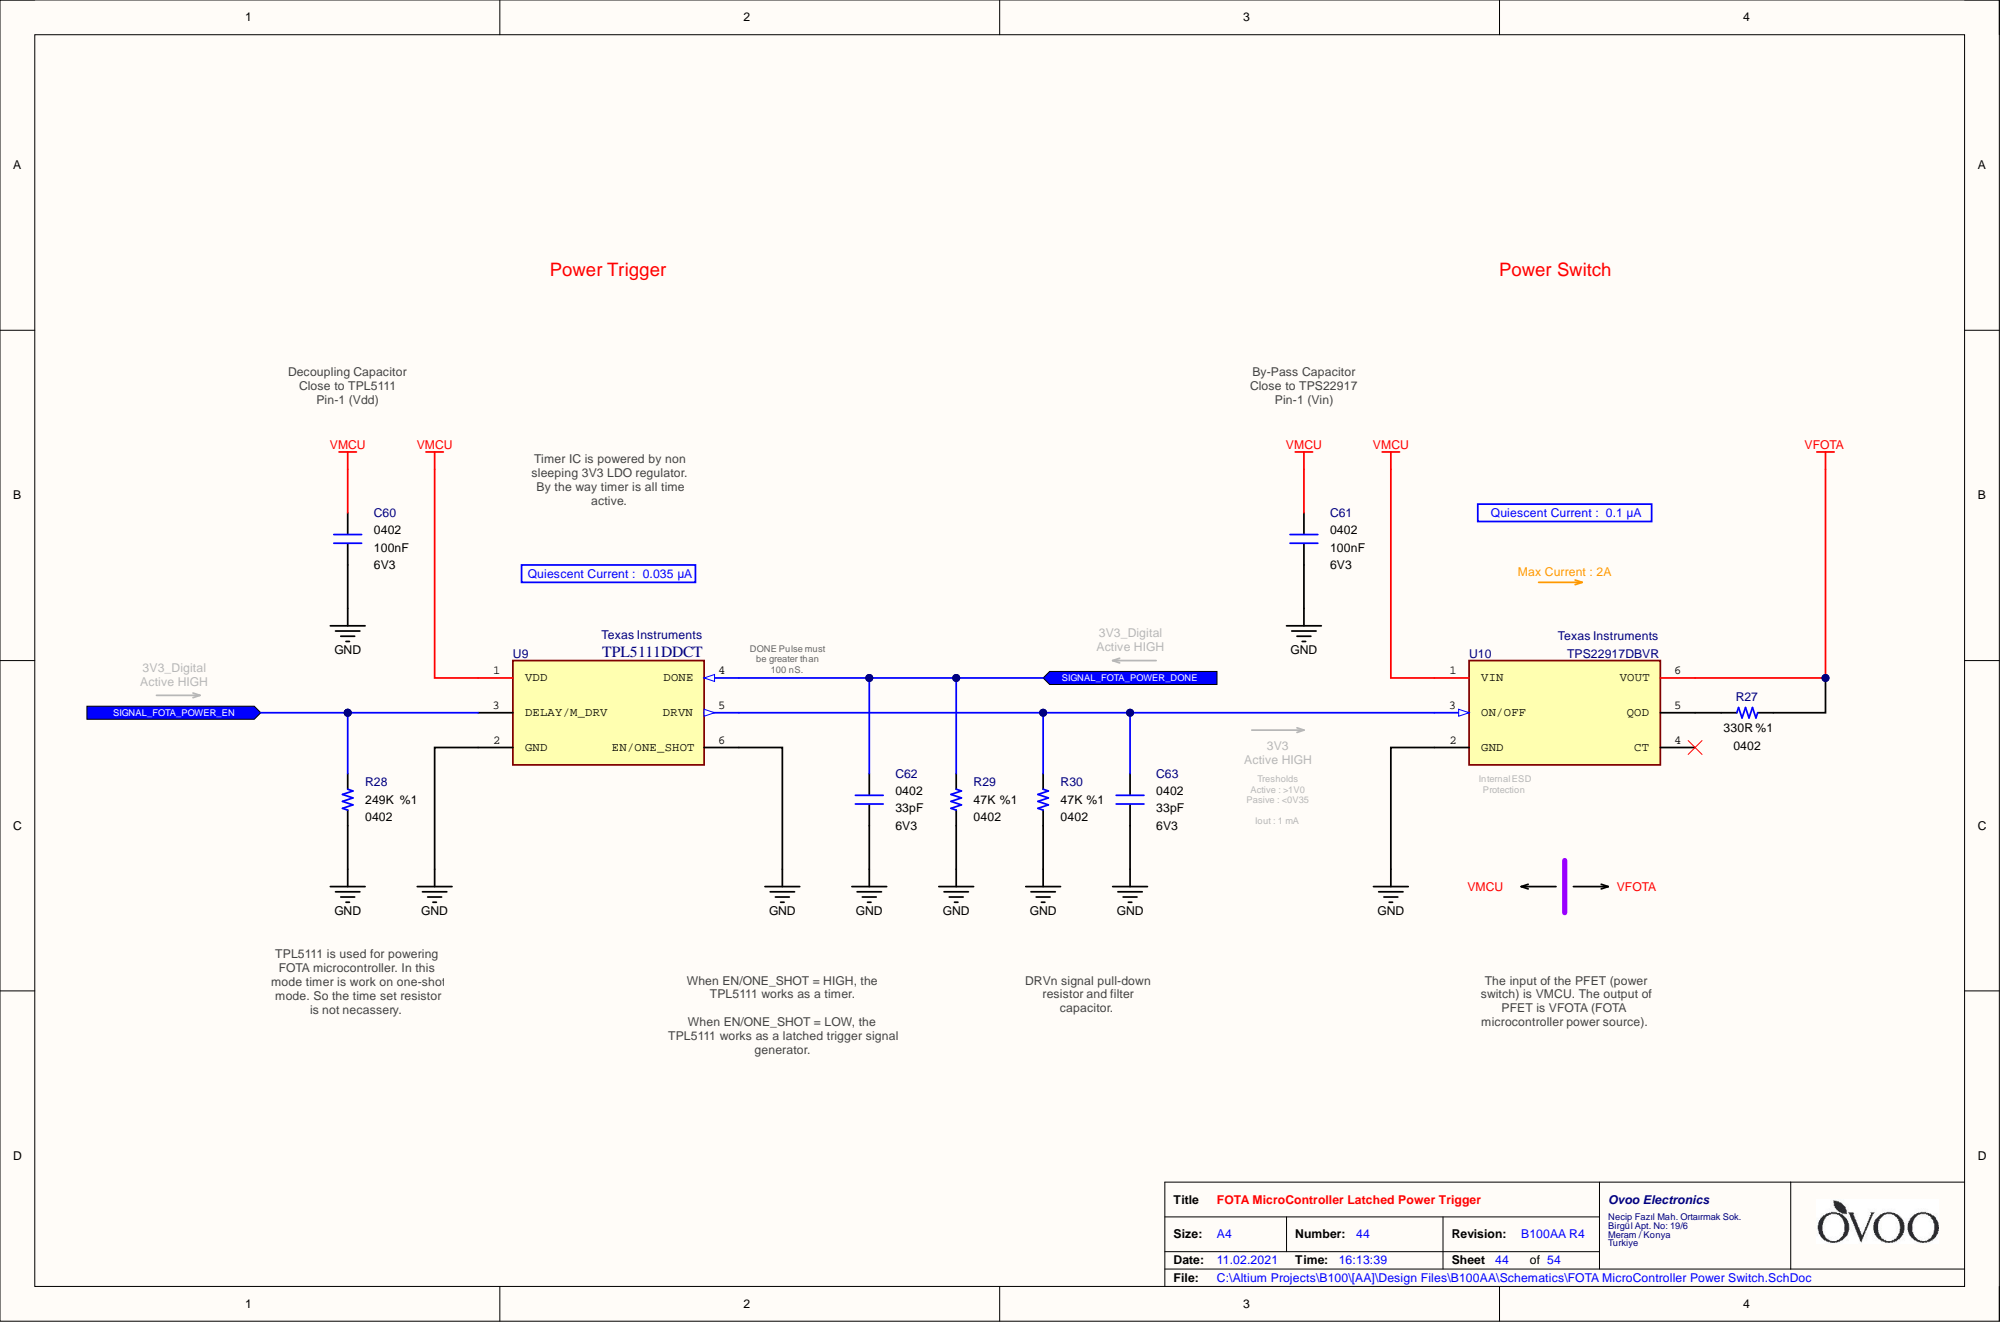
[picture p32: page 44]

Timer IC is powered by non
sleeping 3V3 LDO regulator.
By the way timer is all time

TPL5111 is used for powering
FOTA microcontroller. In this
mode timer is work on one-shot
mode. So the time set resistor

When EN/ONE_SHOT = HIGH, the
TPL5111 works as a timer.

DRVn signal pull-down
resistor and filter
capacitor.

The input of the PFET (power
switch) is VMCU. The output of
PFET is VFOTA (FOTA
microcontroller power source).

When EN/ONE_SHOT = LOW, the
TPL5111 works as a latched trigger signal

FOTA MicroController Latched Power Trigger

C:\Altium Projects\B100\[AA]\Design Files\B100AA\Schematics\FOTA MicroController Power Switch.SchDoc

B100AA Module have
two on-board MCU.

Second microcontroller
is a firmware over the air
controller. This MCU is
burn firmware to the
main MCU.

FOTA Micro Controller ICSP

FOTA Digital ICSP (Main MCU Burn)

FOTA MCU is working at

FOTA MCU Reset Line.

C:\Altium Projects\B100\[AA]\Design Files\B100AA\Schematics\FOTA MicroController.SchDoc

Decoupling Capacitor.
As close as possible to

SD Card mounth tray.
Storage for firmware and
LOG files. 1GB uSD card

1 - DAT2 - Not Used
2 - CD/DAT3 (CS) - Chip Select
3 - CMD (MOSI) - Master Out Slave In
4 - VCC - Positive Supply
5 - CLK - Serial Clock
6 - GND - Ground
7 - DAT0 (MISO) - Master In Slave Out
8 - DAT1 - Not Used

If SEL pin = LOW, Input is
connected to CH1 (Default).
If SEL pin = HIGH, Input is
connected to CH2.

GND 8

MUX_Direction signal
pull-down resistor and
filter capacitor.

SD Card & Select Switch

C:\Altium Projects\B100\[AA]\Design Files\B100AA\Schematics\SD Card.SchDoc

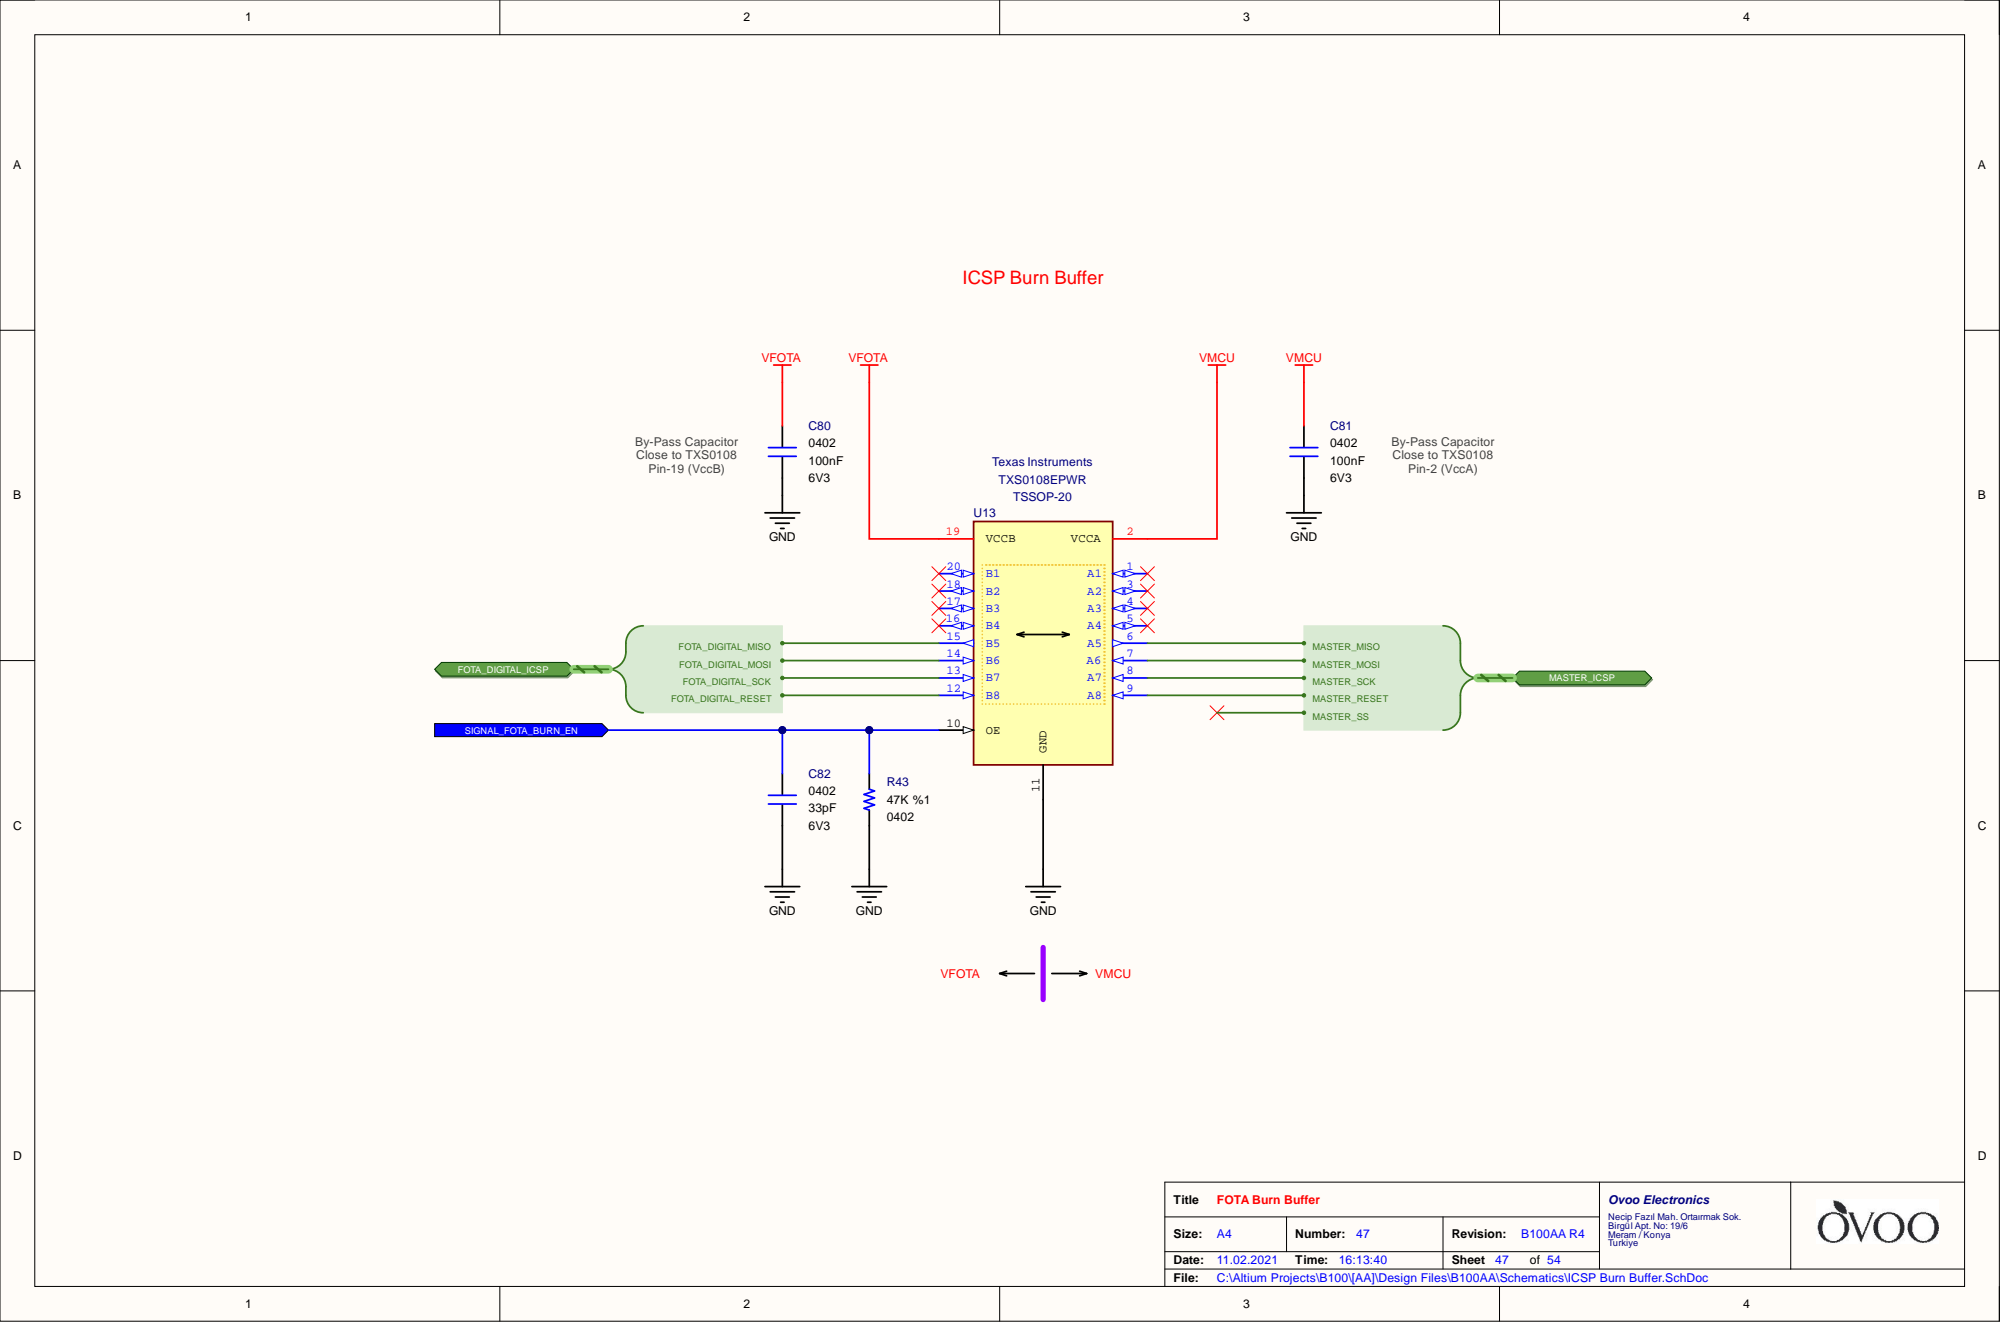
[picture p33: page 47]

C:\Altium Projects\B100\[AA]\Design Files\B100AA\Schematics\ICSP Burn Buffer.SchDoc

EN1 1
EN2 2

C:\Altium Projects\B100\[AA]\Design Files\B100AA\Schematics\Buzzer.SchDoc

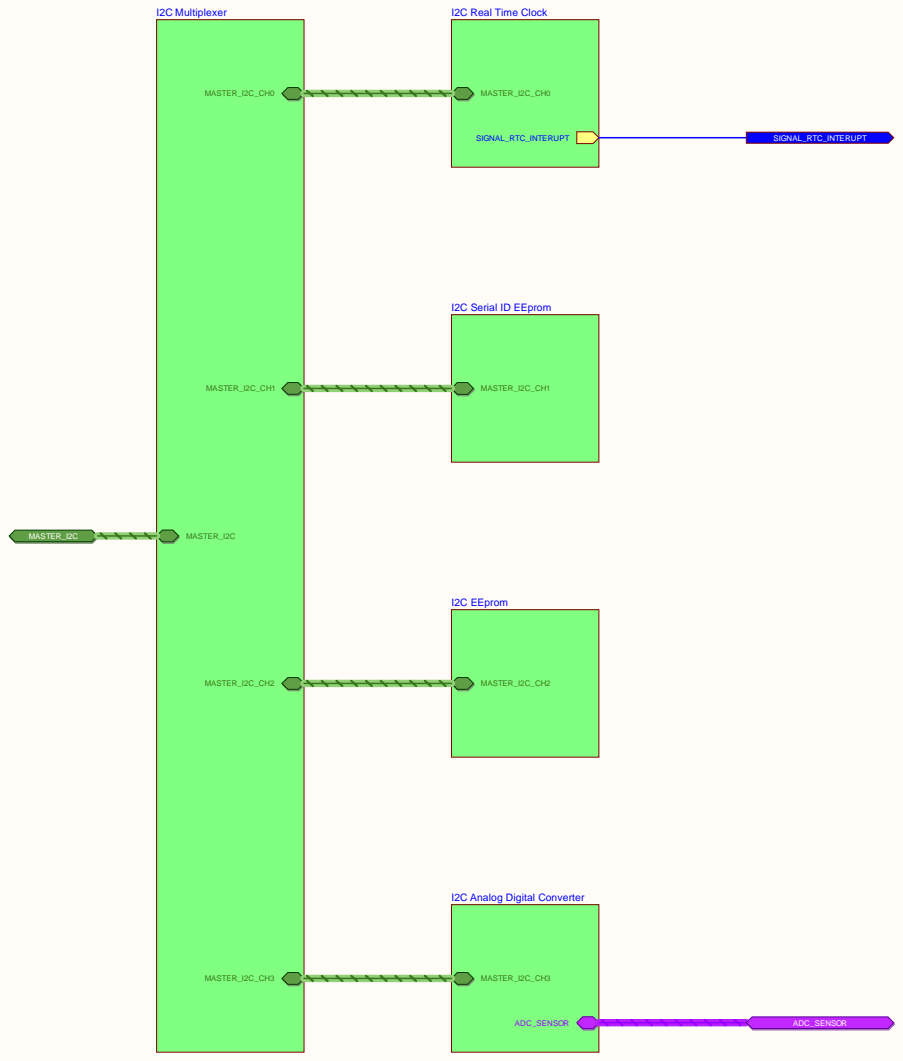
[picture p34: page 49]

C:\Altium Projects\B100\[AA]\Design Files\B100AA\Schematics\I2C Network.SchDoc

SCL 14 SDA 15 A0 1

A1 2
A2 13

RESET 3

Decoupling Capacitor.
As close as possible to
TCA9546 pin-16.

C:\Altium Projects\B100\[AA]\Design Files\B100AA\Schematics\I2C Multiplexer.SchDoc

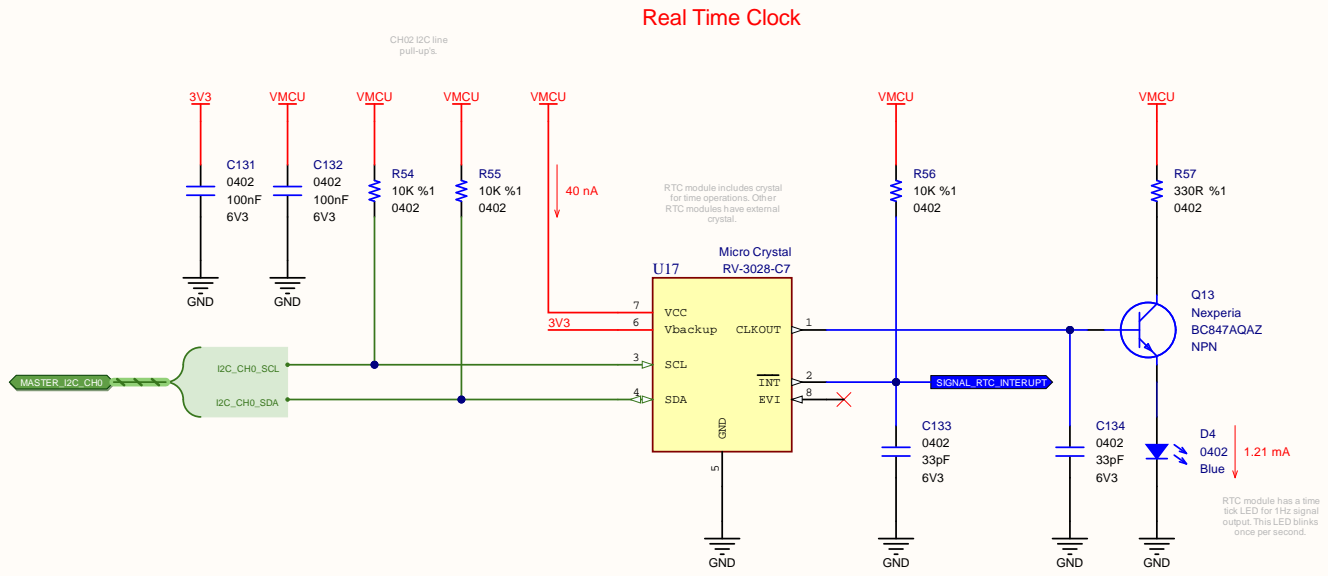
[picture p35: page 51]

RTC module includes crystal
for time operations. Other
RTC modules have external

RTC module has a time
tick LED for 1Hz signal
output. This LED blinks
once per second.

C:\Altium Projects\B100\[AA]\Design Files\B100AA\Schematics\Real Time Clock.SchDoc

C:\Altium Projects\B100\[AA]\Design Files\B100AA\Schematics\Serial ID EEPROM.SchDoc

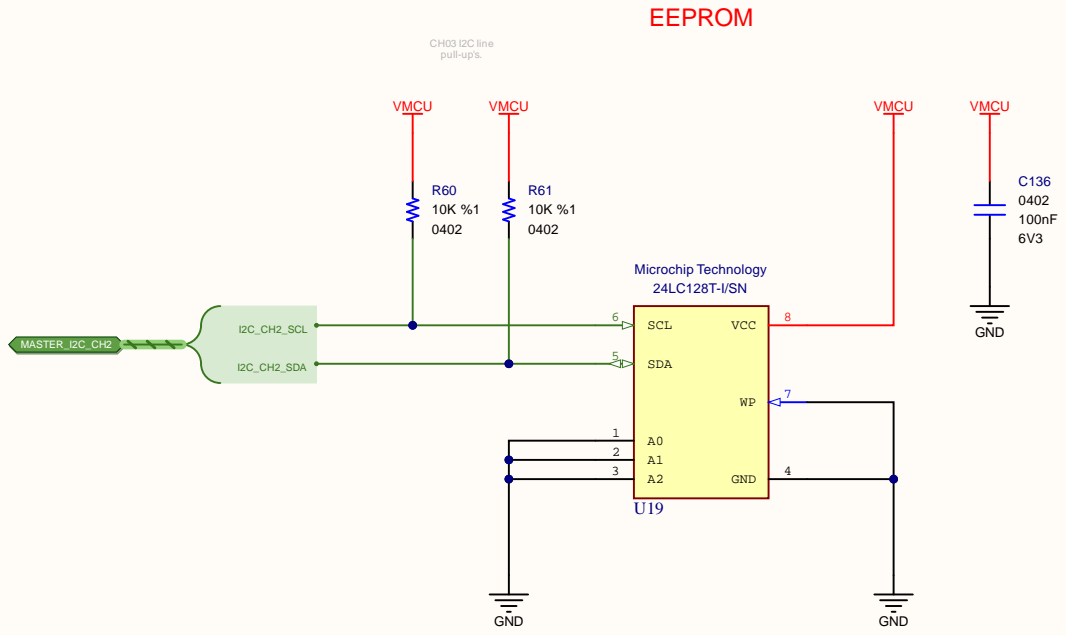
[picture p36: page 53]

C:\Altium Projects\B100\[AA]\Design Files\B100AA\Schematics\EEPROM.SchDoc

Analog inputs are
connected to pressure
sensor. When system is
use 5V analog sensor
resolution is guaranted
1mBar resolution
(calculated resolution is
0.045mBar).

Sensor voltage resolution : 19.073 uV
Sensor pressure resolution : 0.045 mBar

C:\Altium Projects\B100\[AA]\Design Files\B100AA\Schematics\Analog Digital Converter.SchDoc

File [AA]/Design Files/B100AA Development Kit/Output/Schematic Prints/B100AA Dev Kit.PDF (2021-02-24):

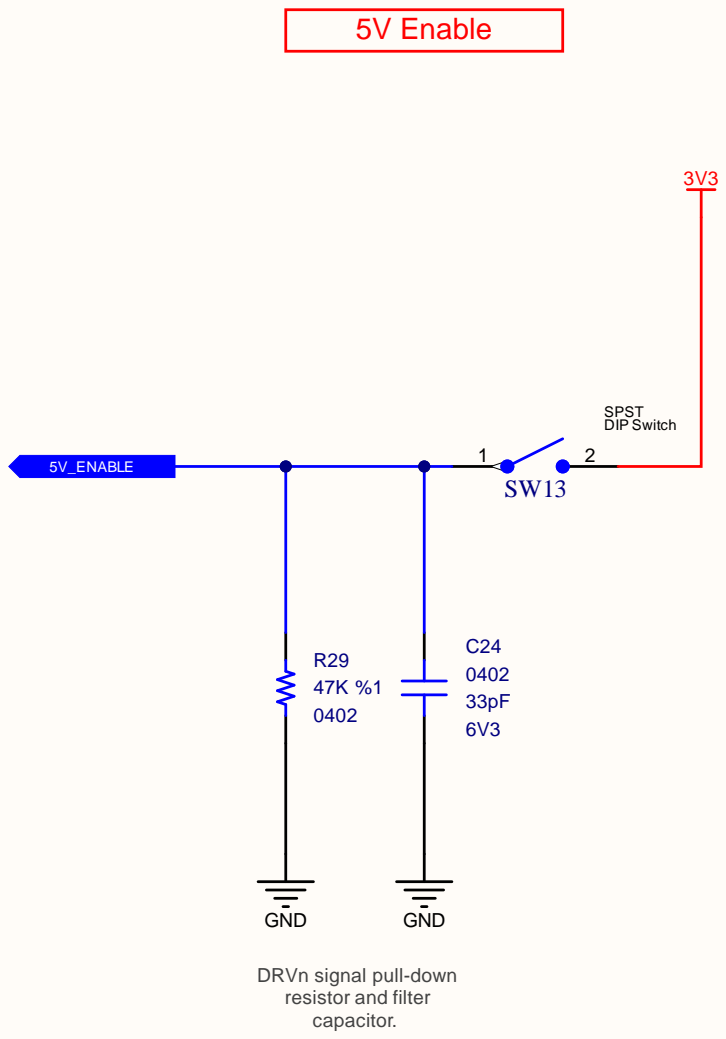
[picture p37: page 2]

DRVn signal pull-down
resistor and filter
capacitor.

Necip Fazıl Mah. Ortaırmak Sok. Birgül Apt. No: 19/6 Meram / Konya Turkiye

C:\Altium Projects\B100\[AA]\Design Files\B100AA Development Kit\Schematic\5V Enable.SchDoc

Analog Sensor Output Socket 1

Analog Sensor Output Socket 2

Pressure Sensor Input Sockets

C:\Altium Projects\B100\[AA]\Design Files\B100AA Development Kit\Schematic\ADS Sensor Sockets.SchDoc

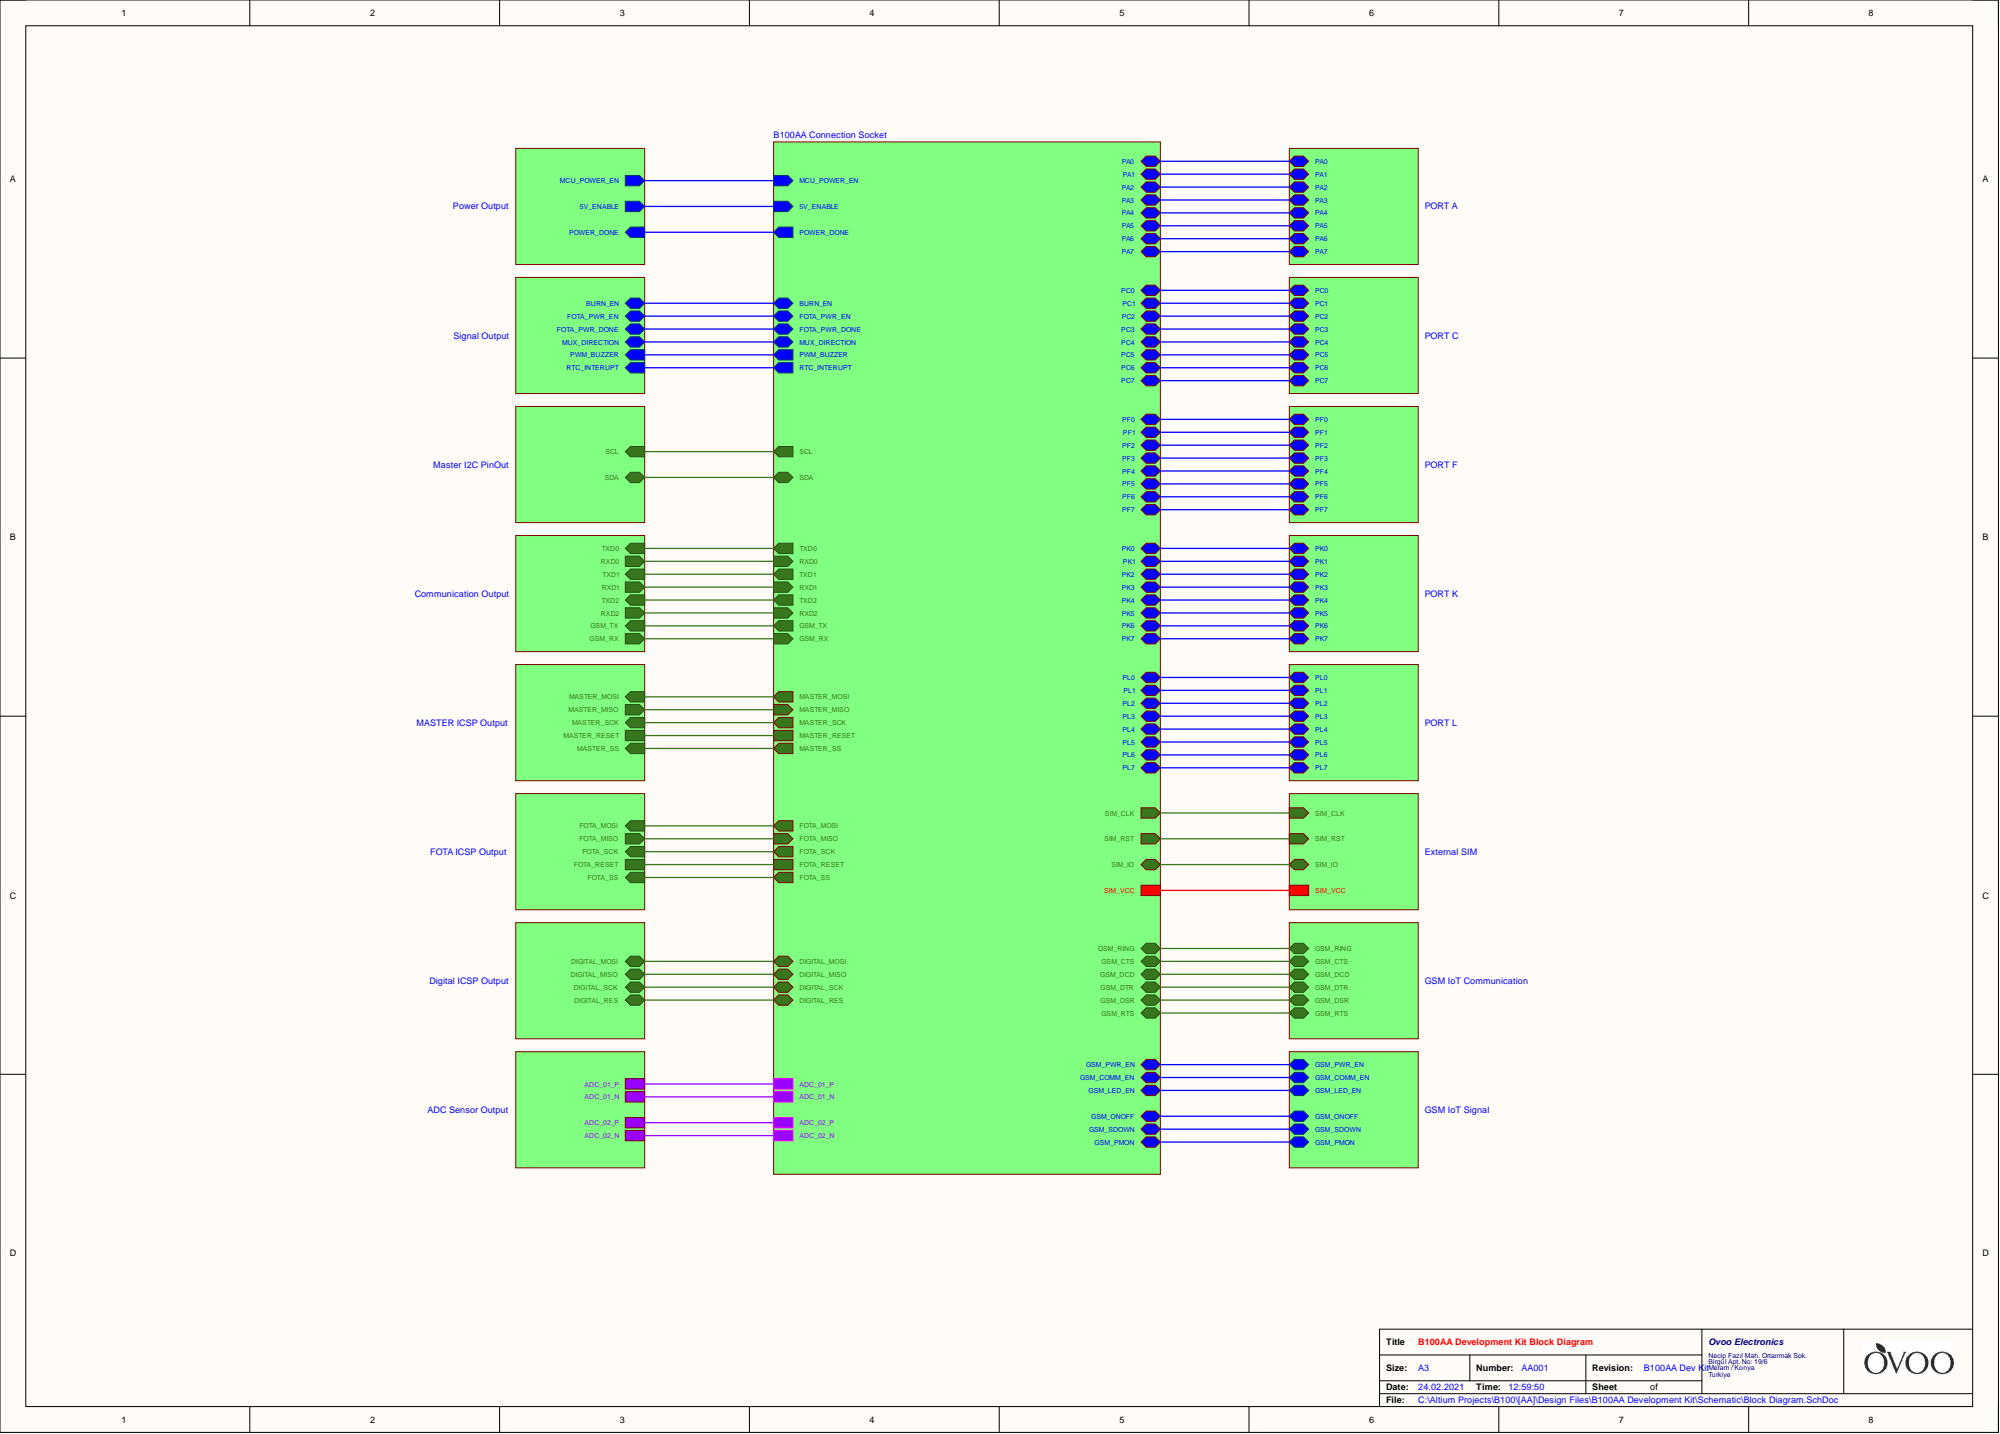
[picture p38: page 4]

B100AA Development Kit Block Diagram

C:\Altium Projects\B100\[AA]\Design Files\B100AA Development Kit\Schematic\Block Diagram.SchDoc

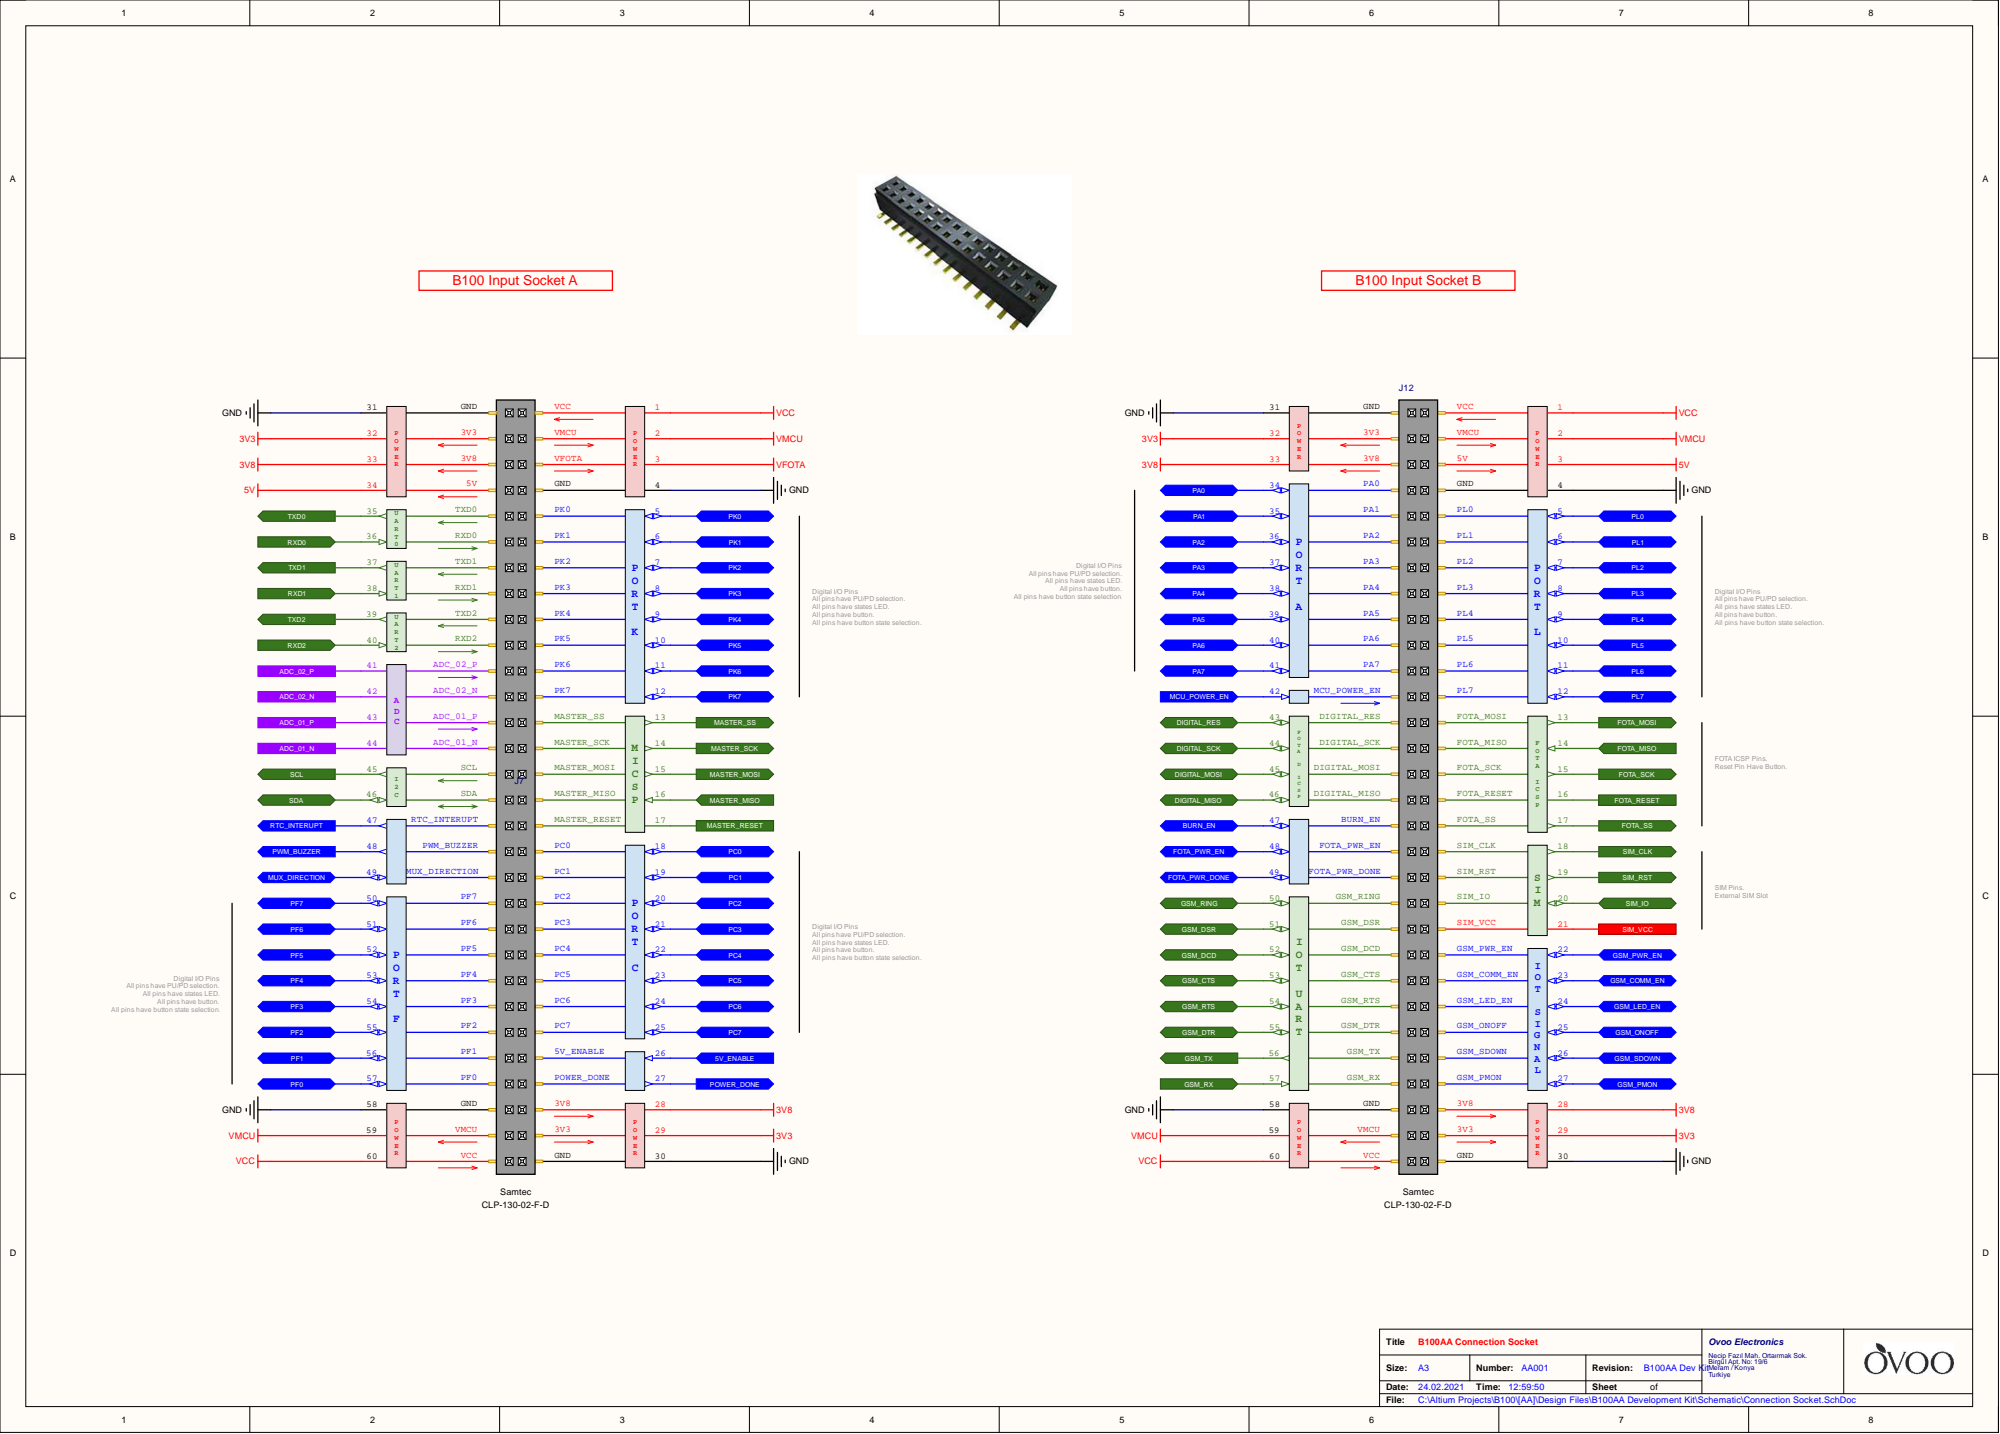
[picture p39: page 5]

Digital ICSP test Points

C:\Altium Projects\B100\[AA]\Design Files\B100AA Development Kit\Schematic\Digital ICSP Test Points.SchDoc

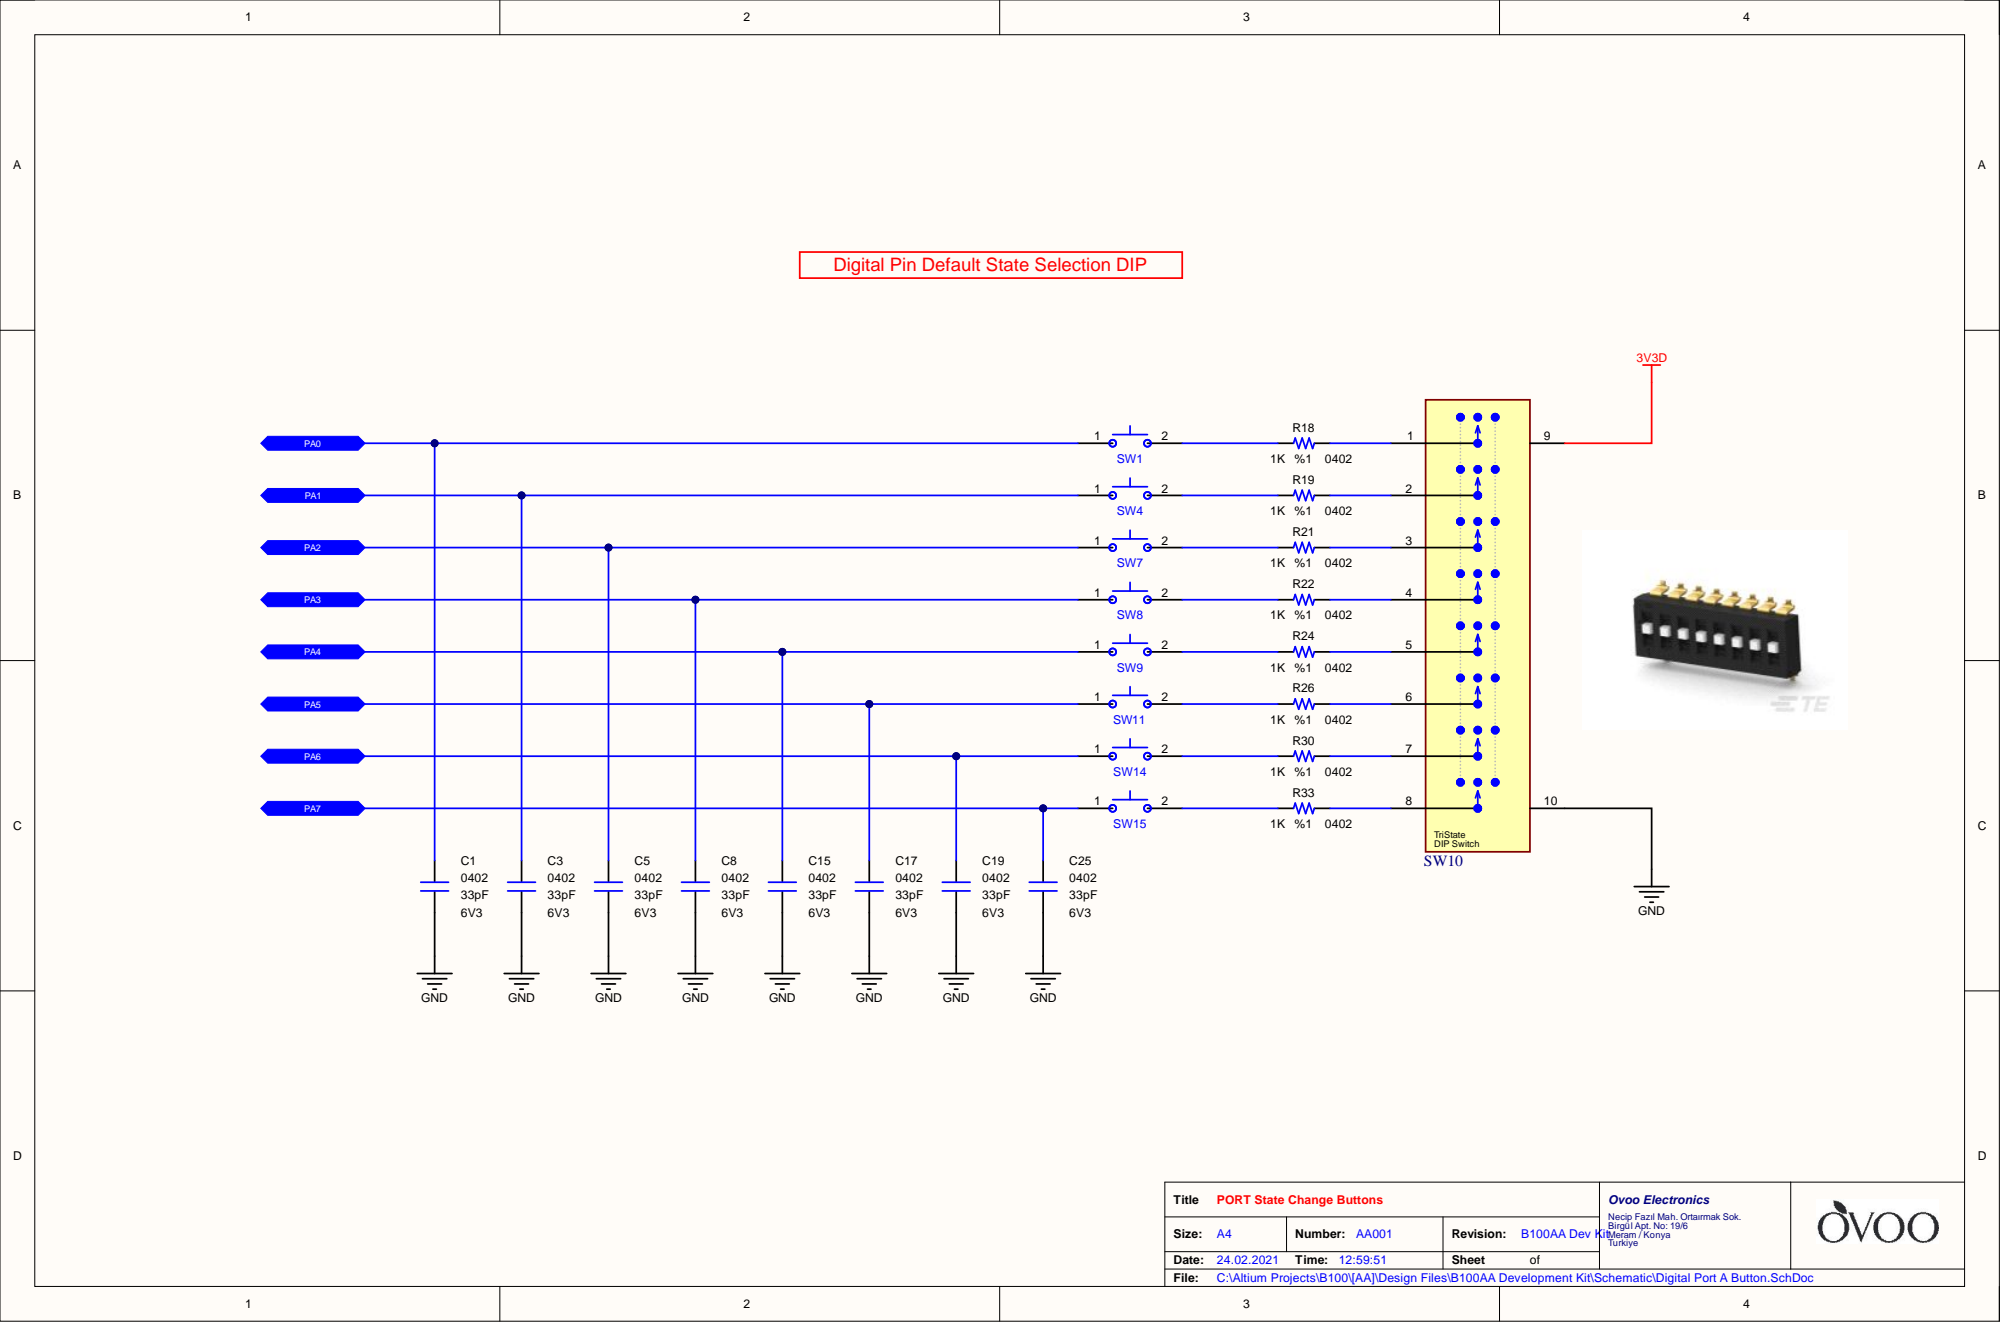
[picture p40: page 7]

Digital Pin Default State Selection DIP

PORT State Change Buttons

Digital Pin Default State Selection DIP

lt State DIP.Sc

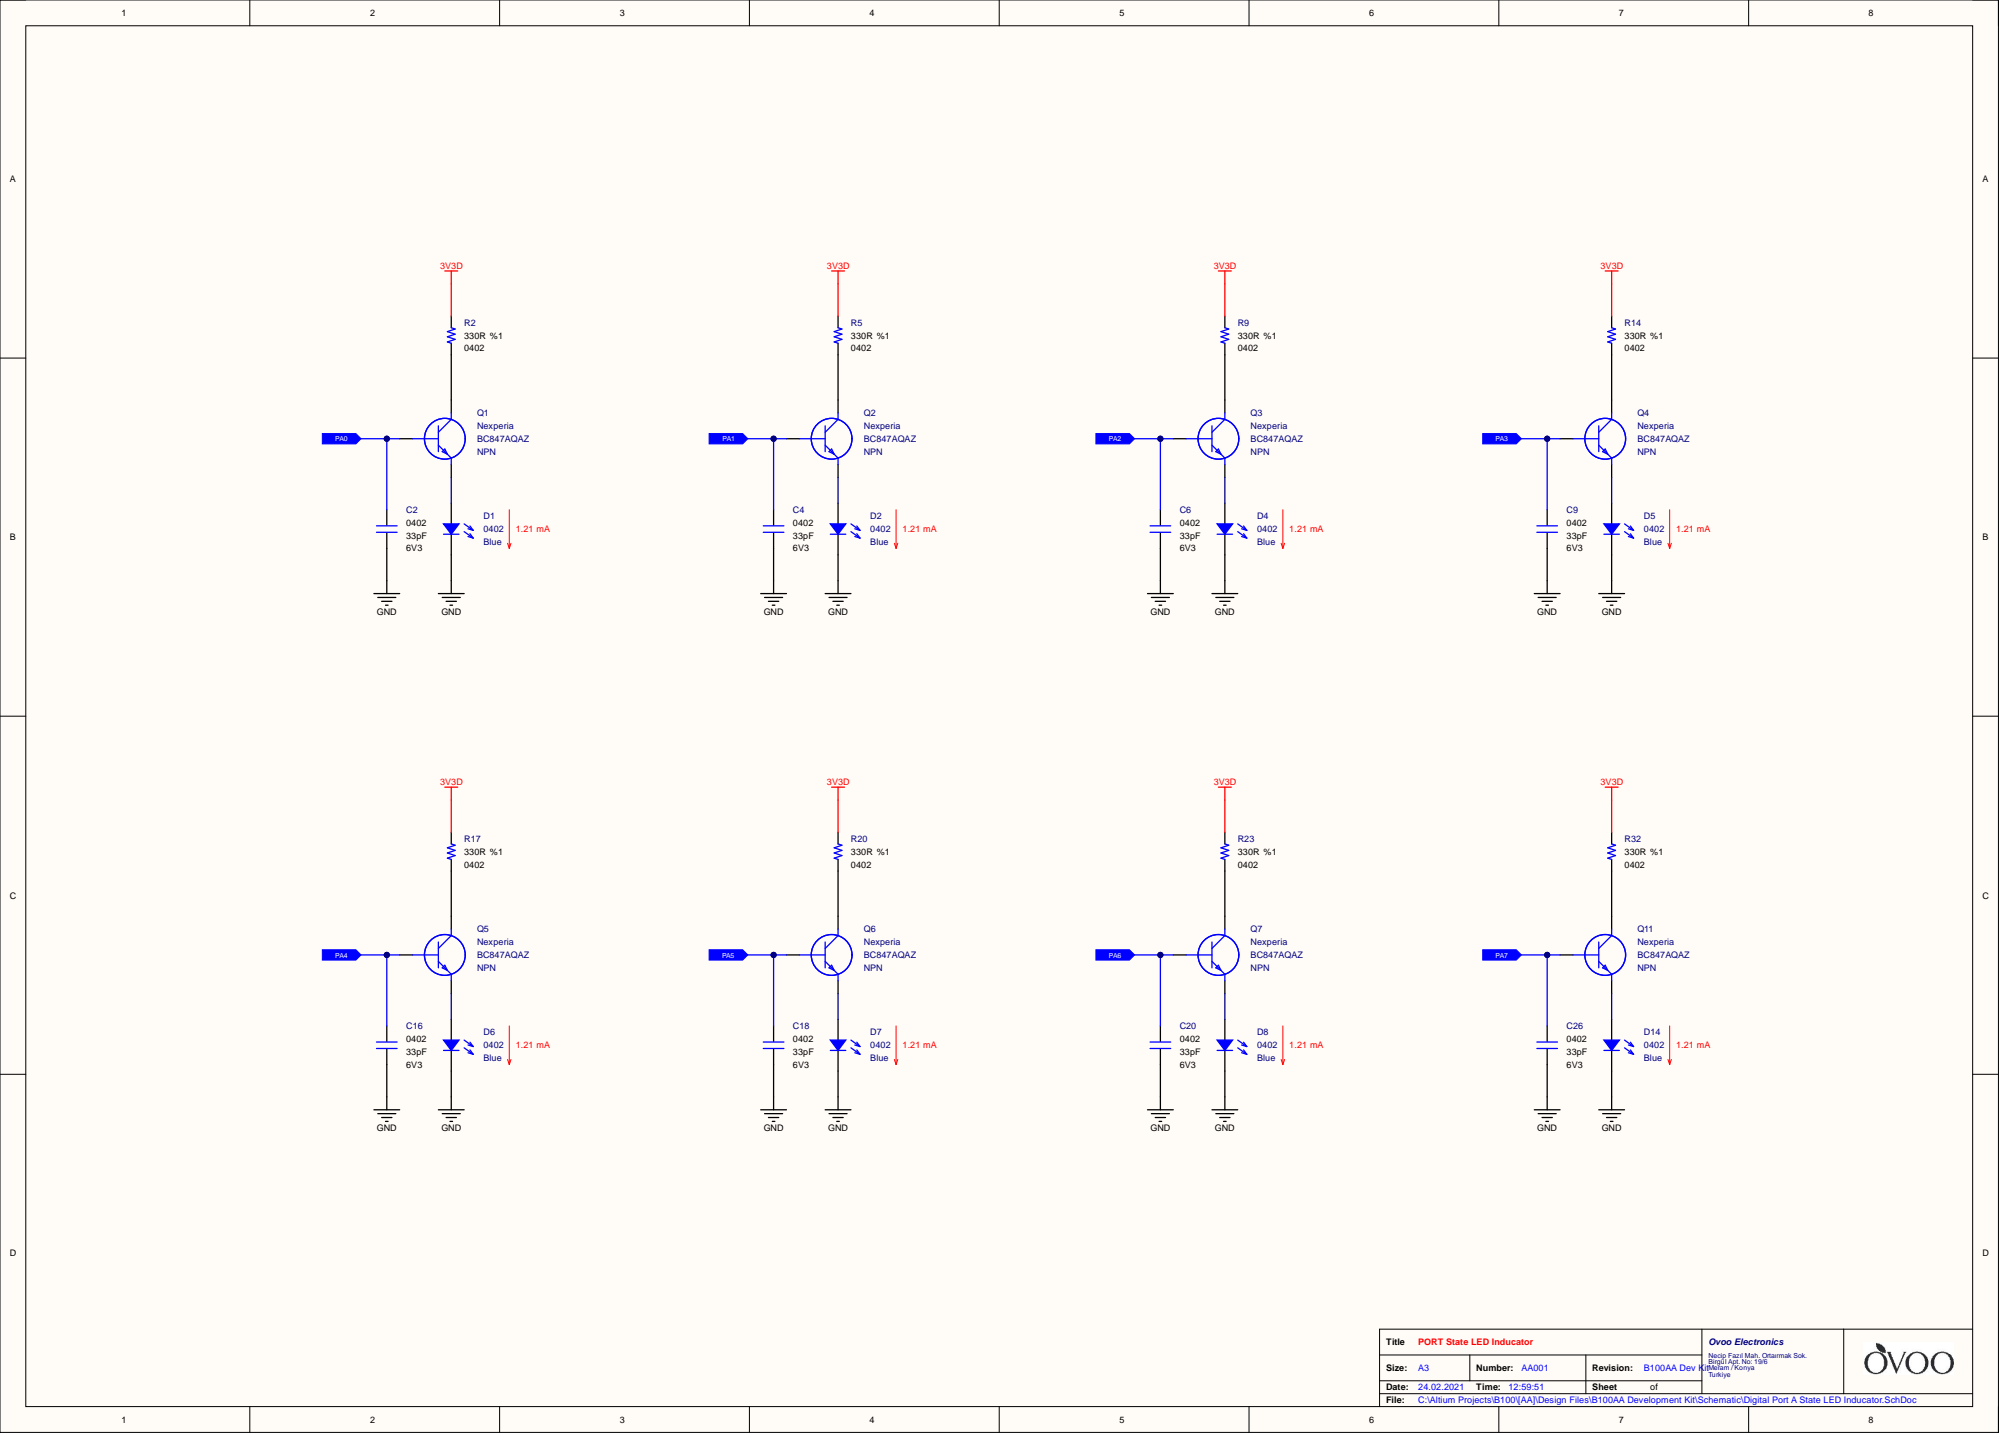
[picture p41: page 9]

PORT State LED Inducator

C:\Altium Projects\B100\[AA]\Design Files\B100AA Development Kit\Schematic\Digital Port A State LED Inducator.SchDoc

Digital Pin Default State Selection DIP

Digital Pin State LED Inducator

Digital Pin State Change Switch

C:\Altium Projects\B100\[AA]\Design Files\B100AA Development Kit\Schematic\Digital Port A.SchDoc

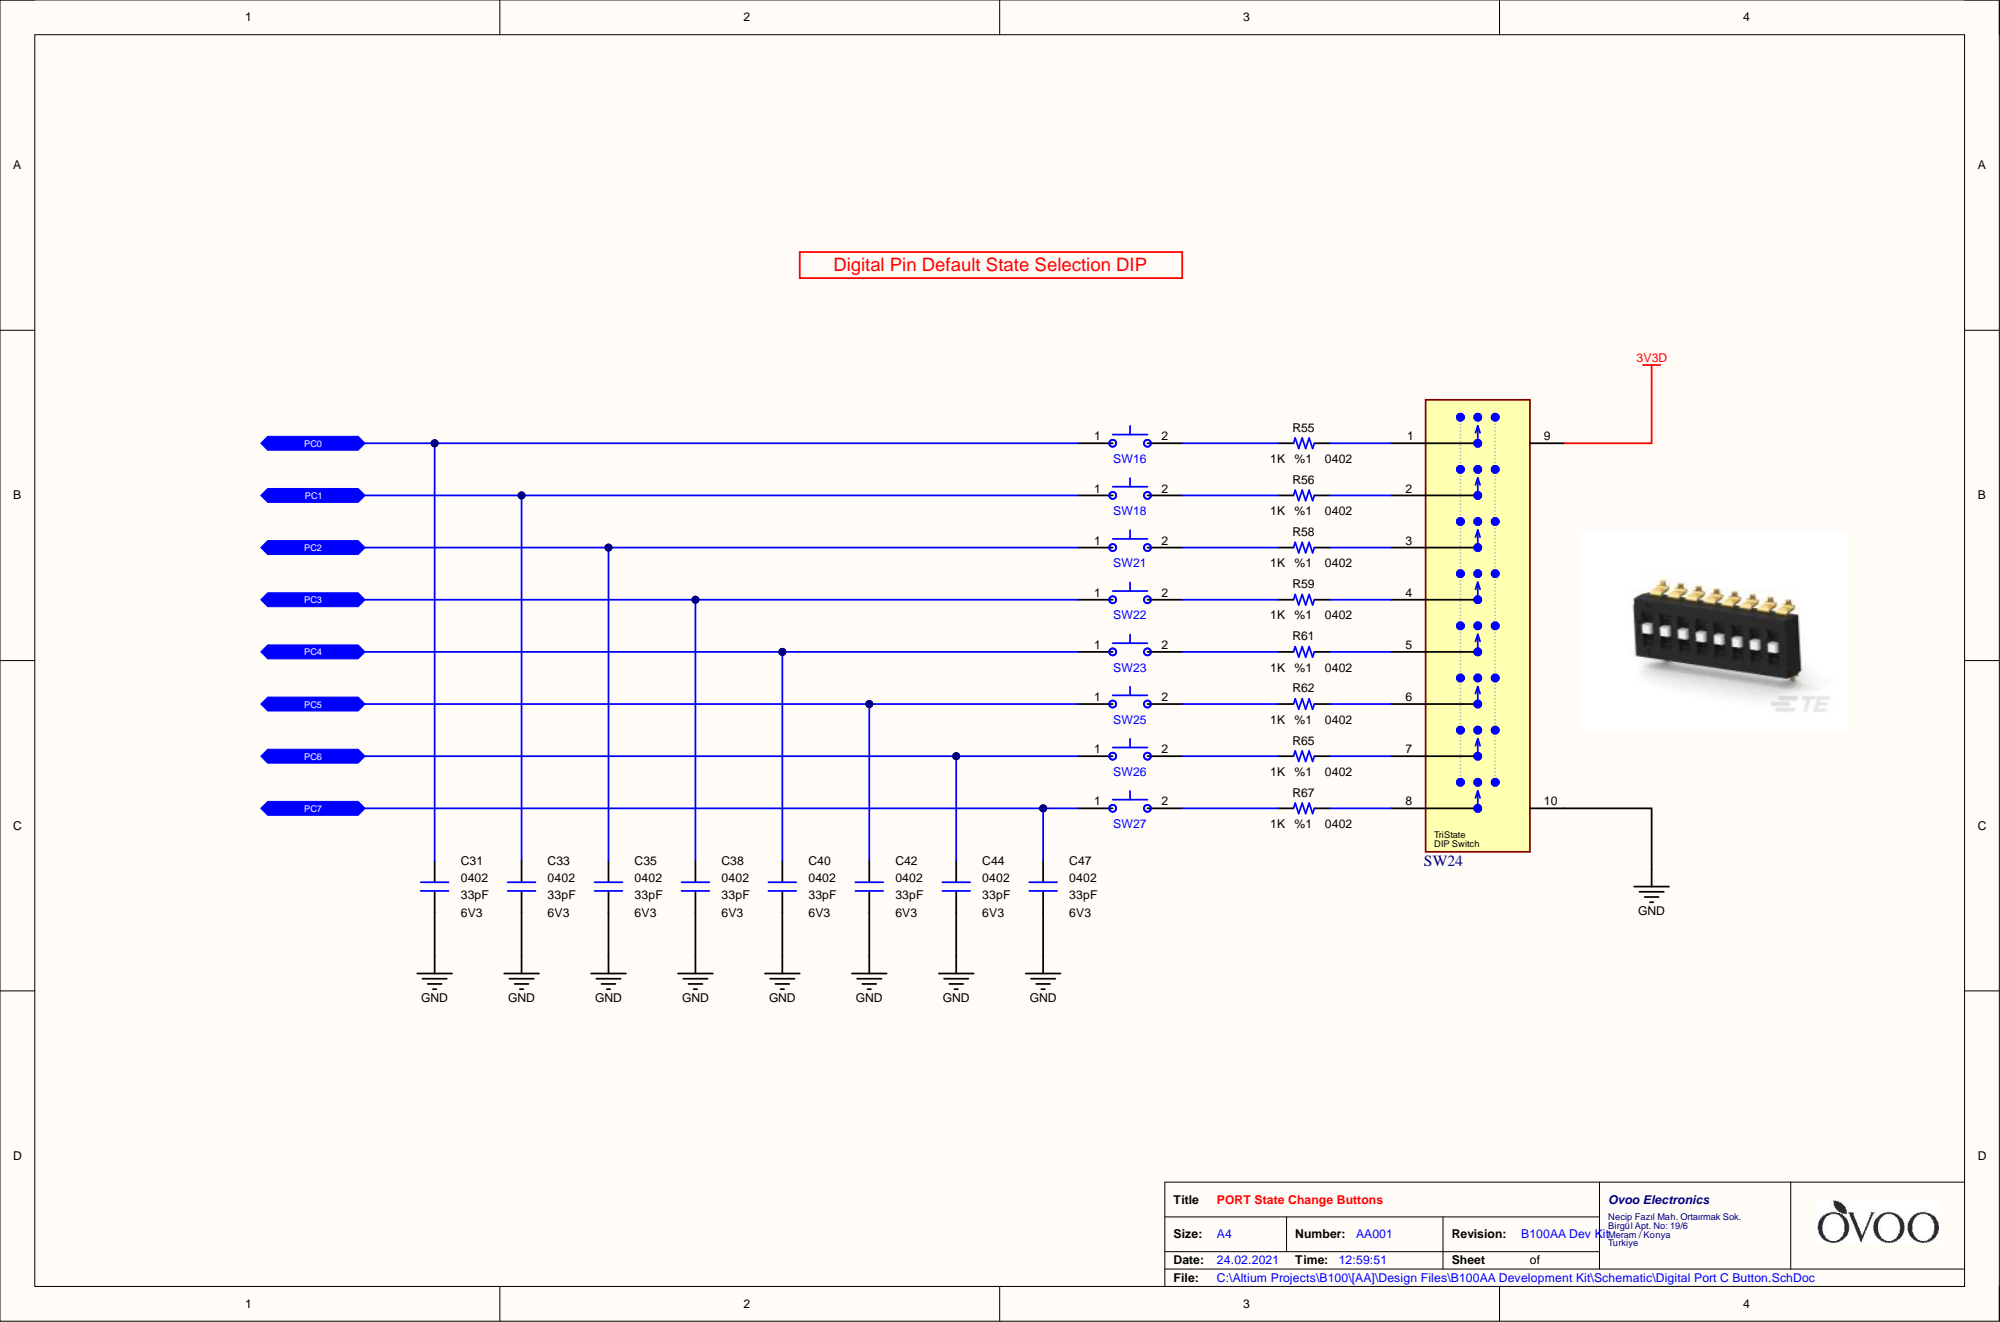
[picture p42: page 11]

Digital Pin Default State Selection DIP

PORT State Change Buttons

Digital Pin Default State Selection DIP

PORT C Default State Sele

lt State DIP.Sc

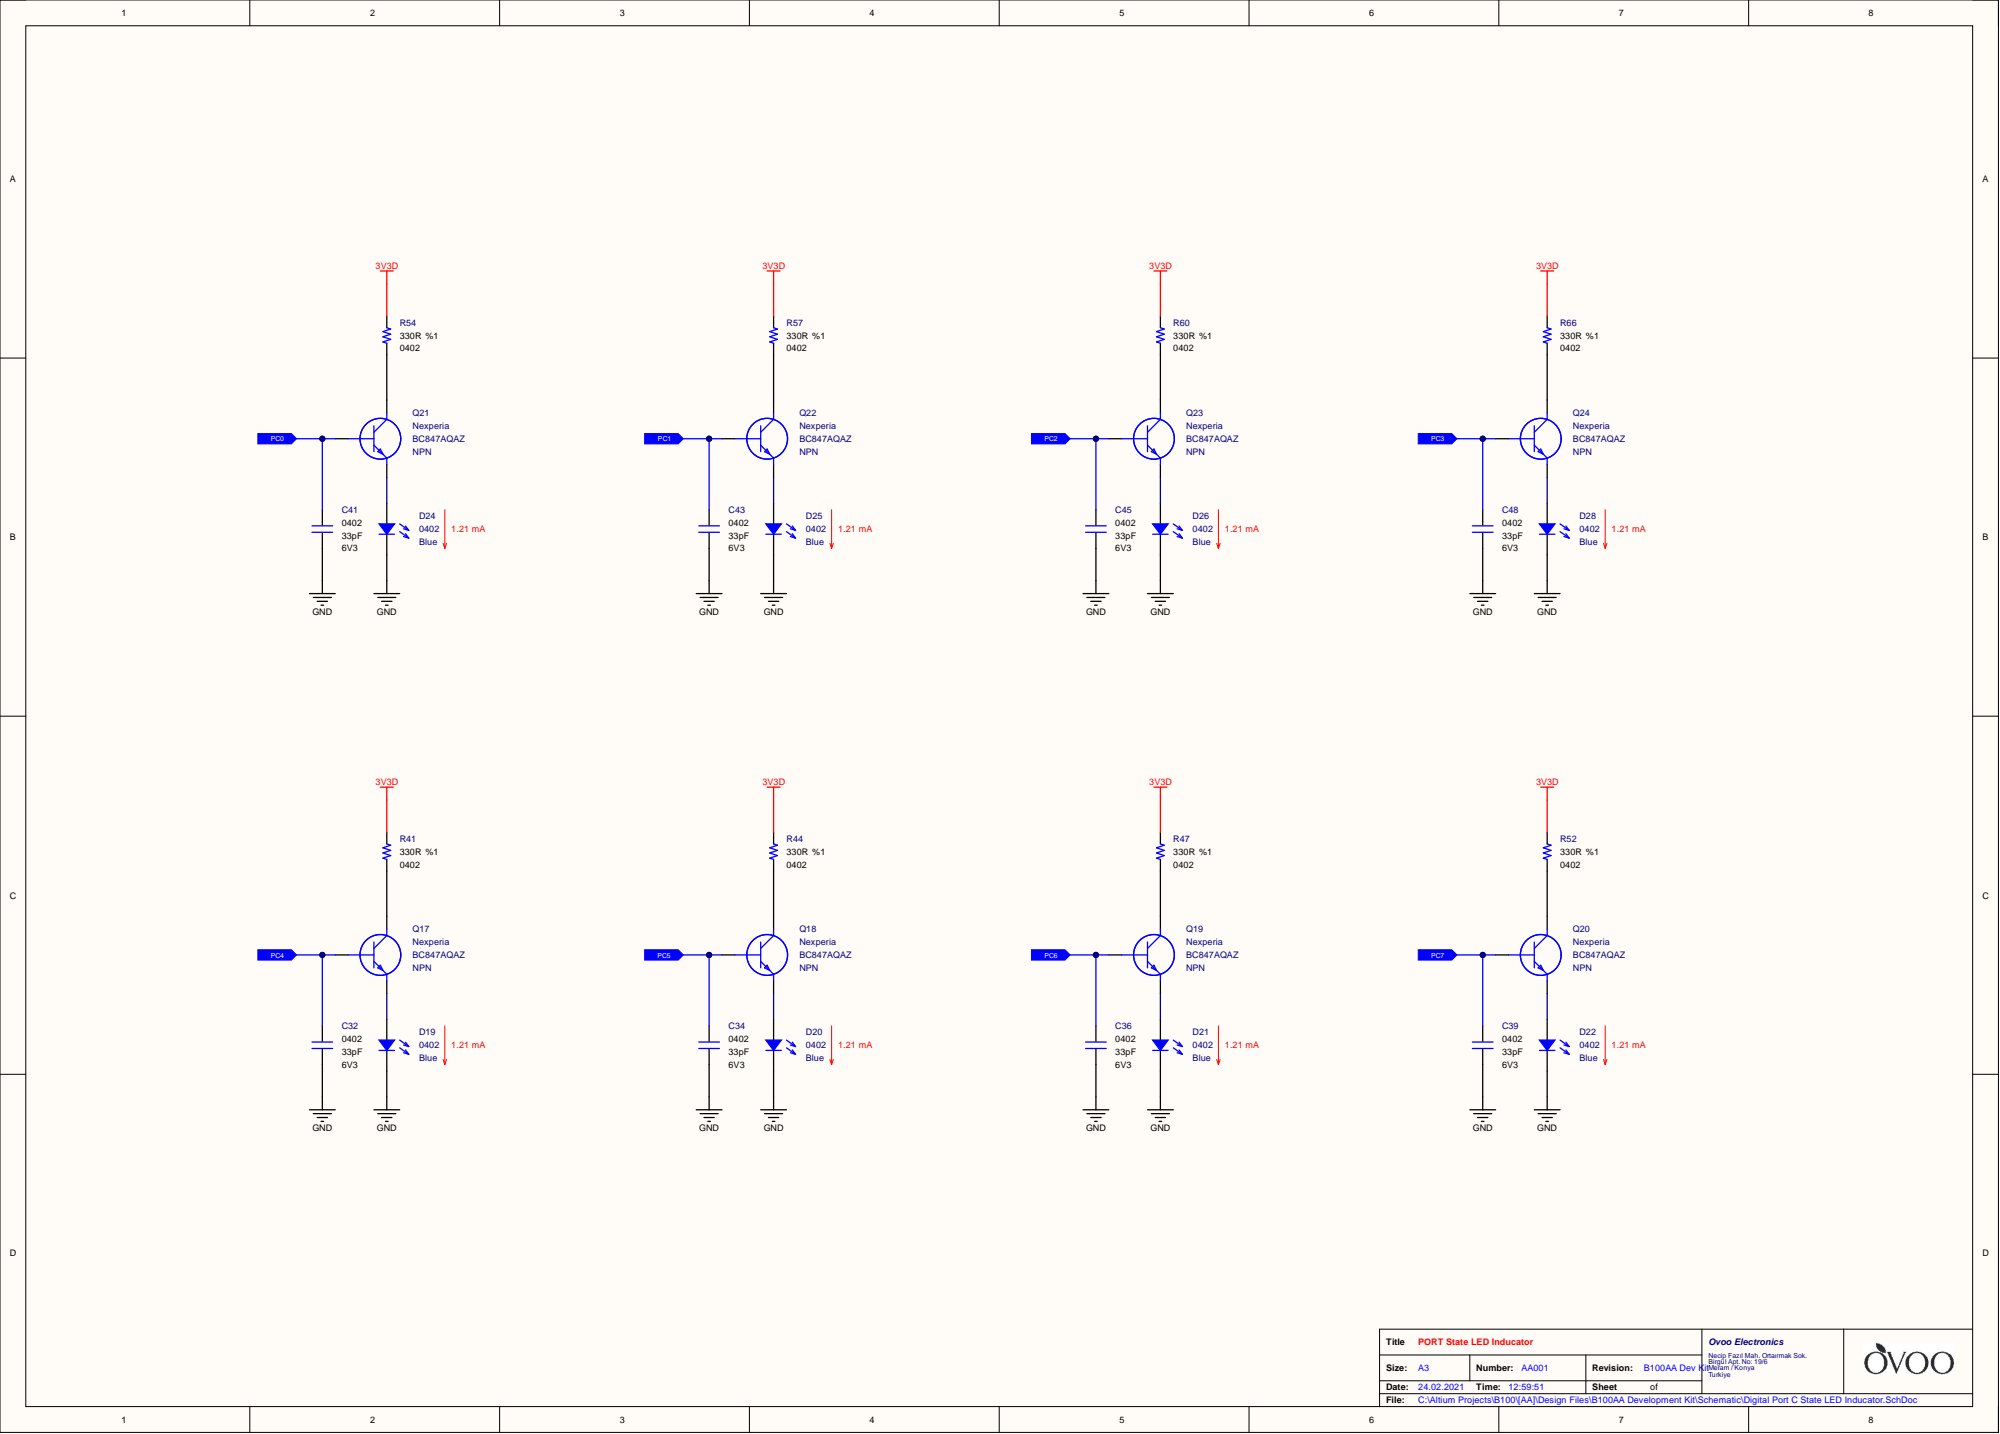
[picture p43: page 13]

PORT State LED Inducator

C:\Altium Projects\B100\[AA]\Design Files\B100AA Development Kit\Schematic\Digital Port C State LED Inducator.SchDoc

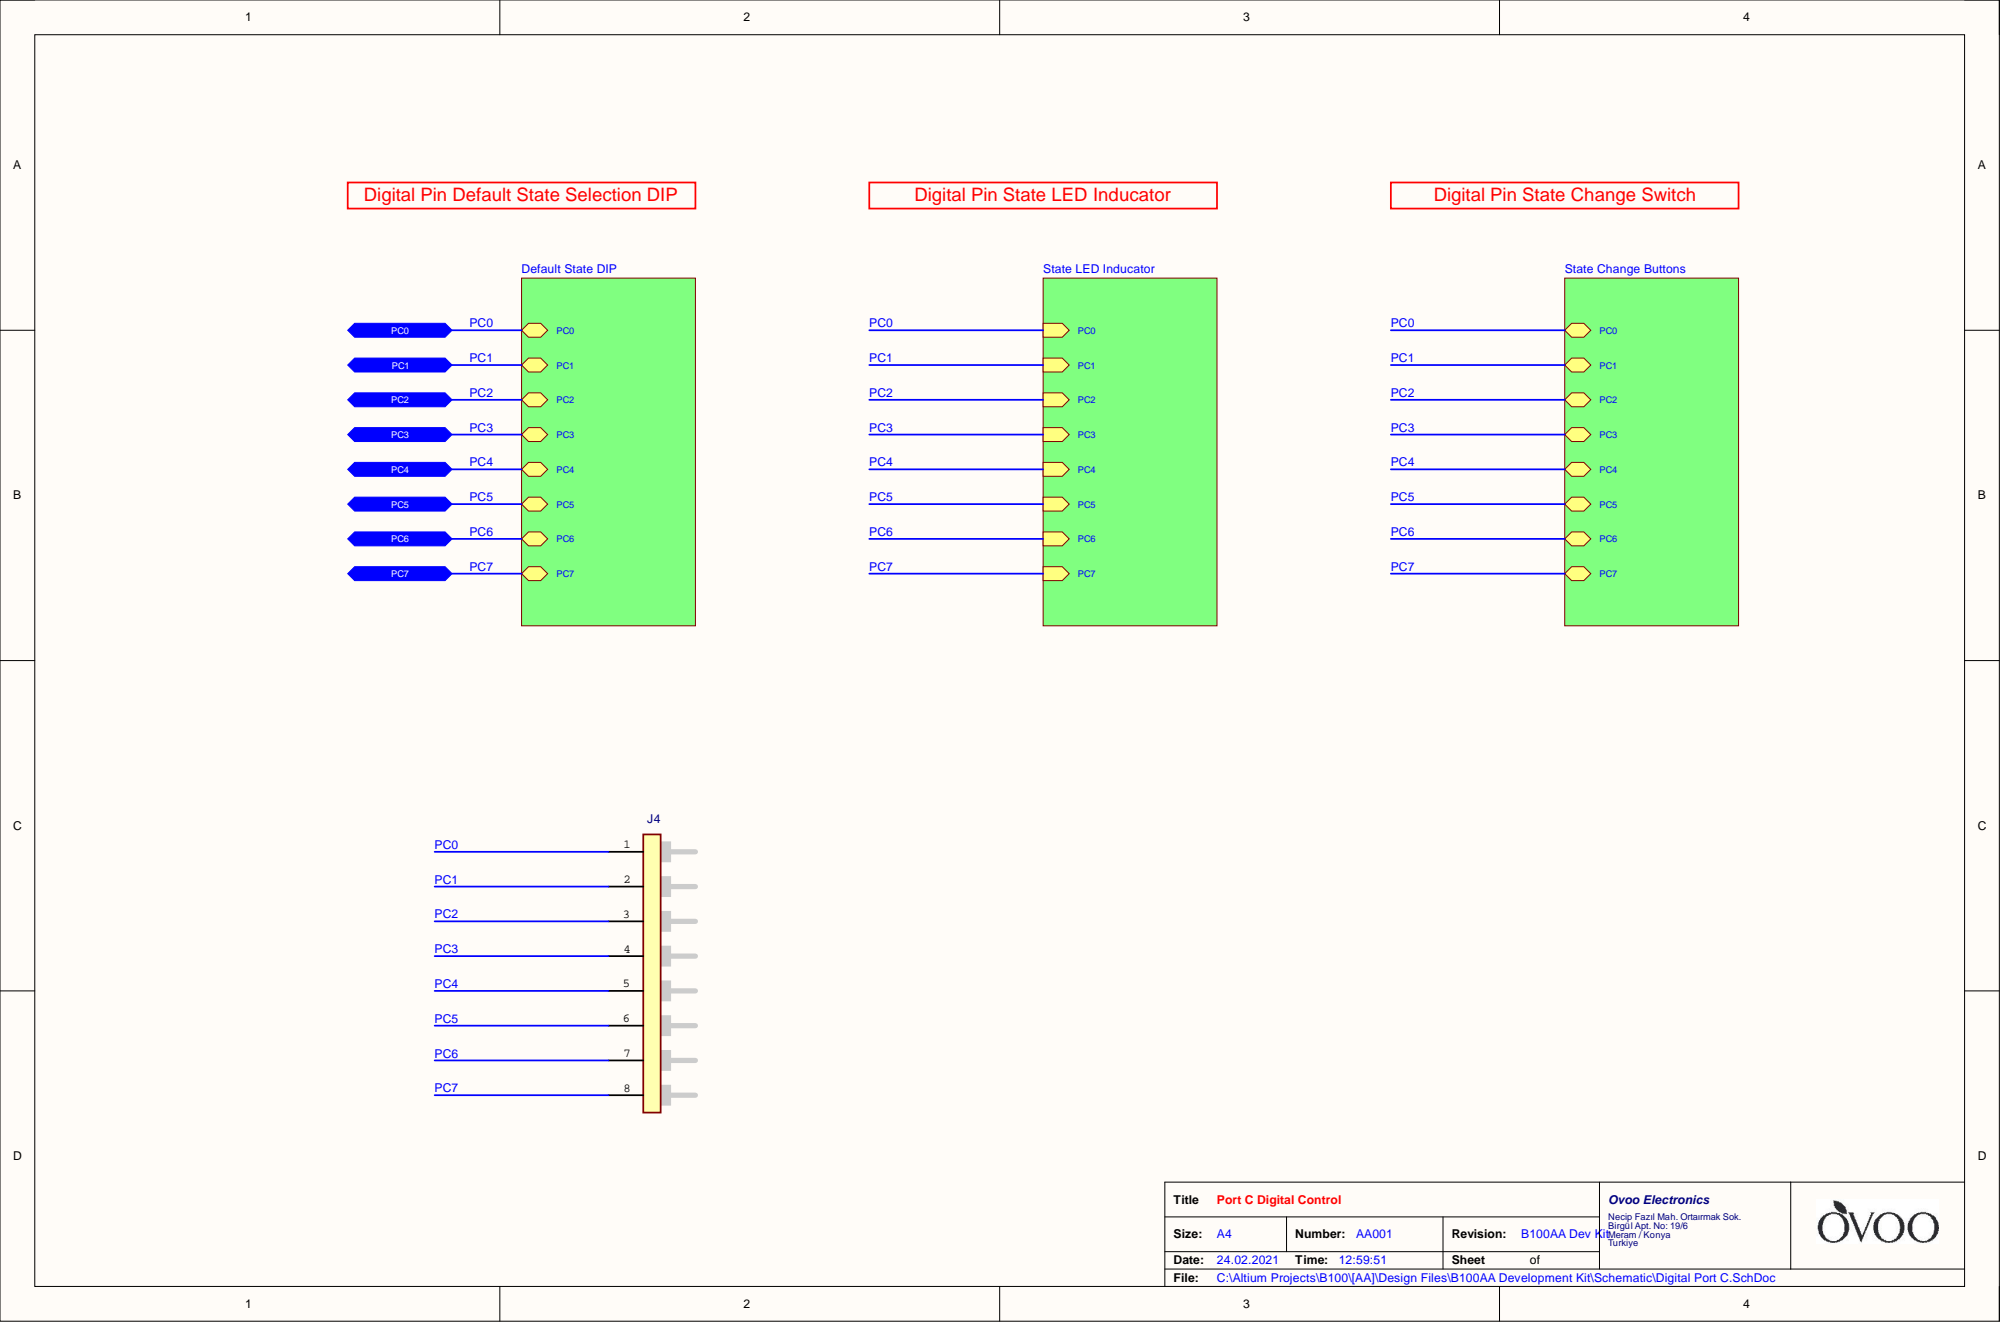
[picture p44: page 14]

Digital Pin Default State Selection DIP

Digital Pin State LED Inducator

Digital Pin State Change Switch

C:\Altium Projects\B100\[AA]\Design Files\B100AA Development Kit\Schematic\Digital Port C.SchDoc

Digital Pin Default State Selection DIP

PORT State Change Buttons

Digital Pin Default State Selection DIP

PORT F Default State Sele

lt State DIP.Sc

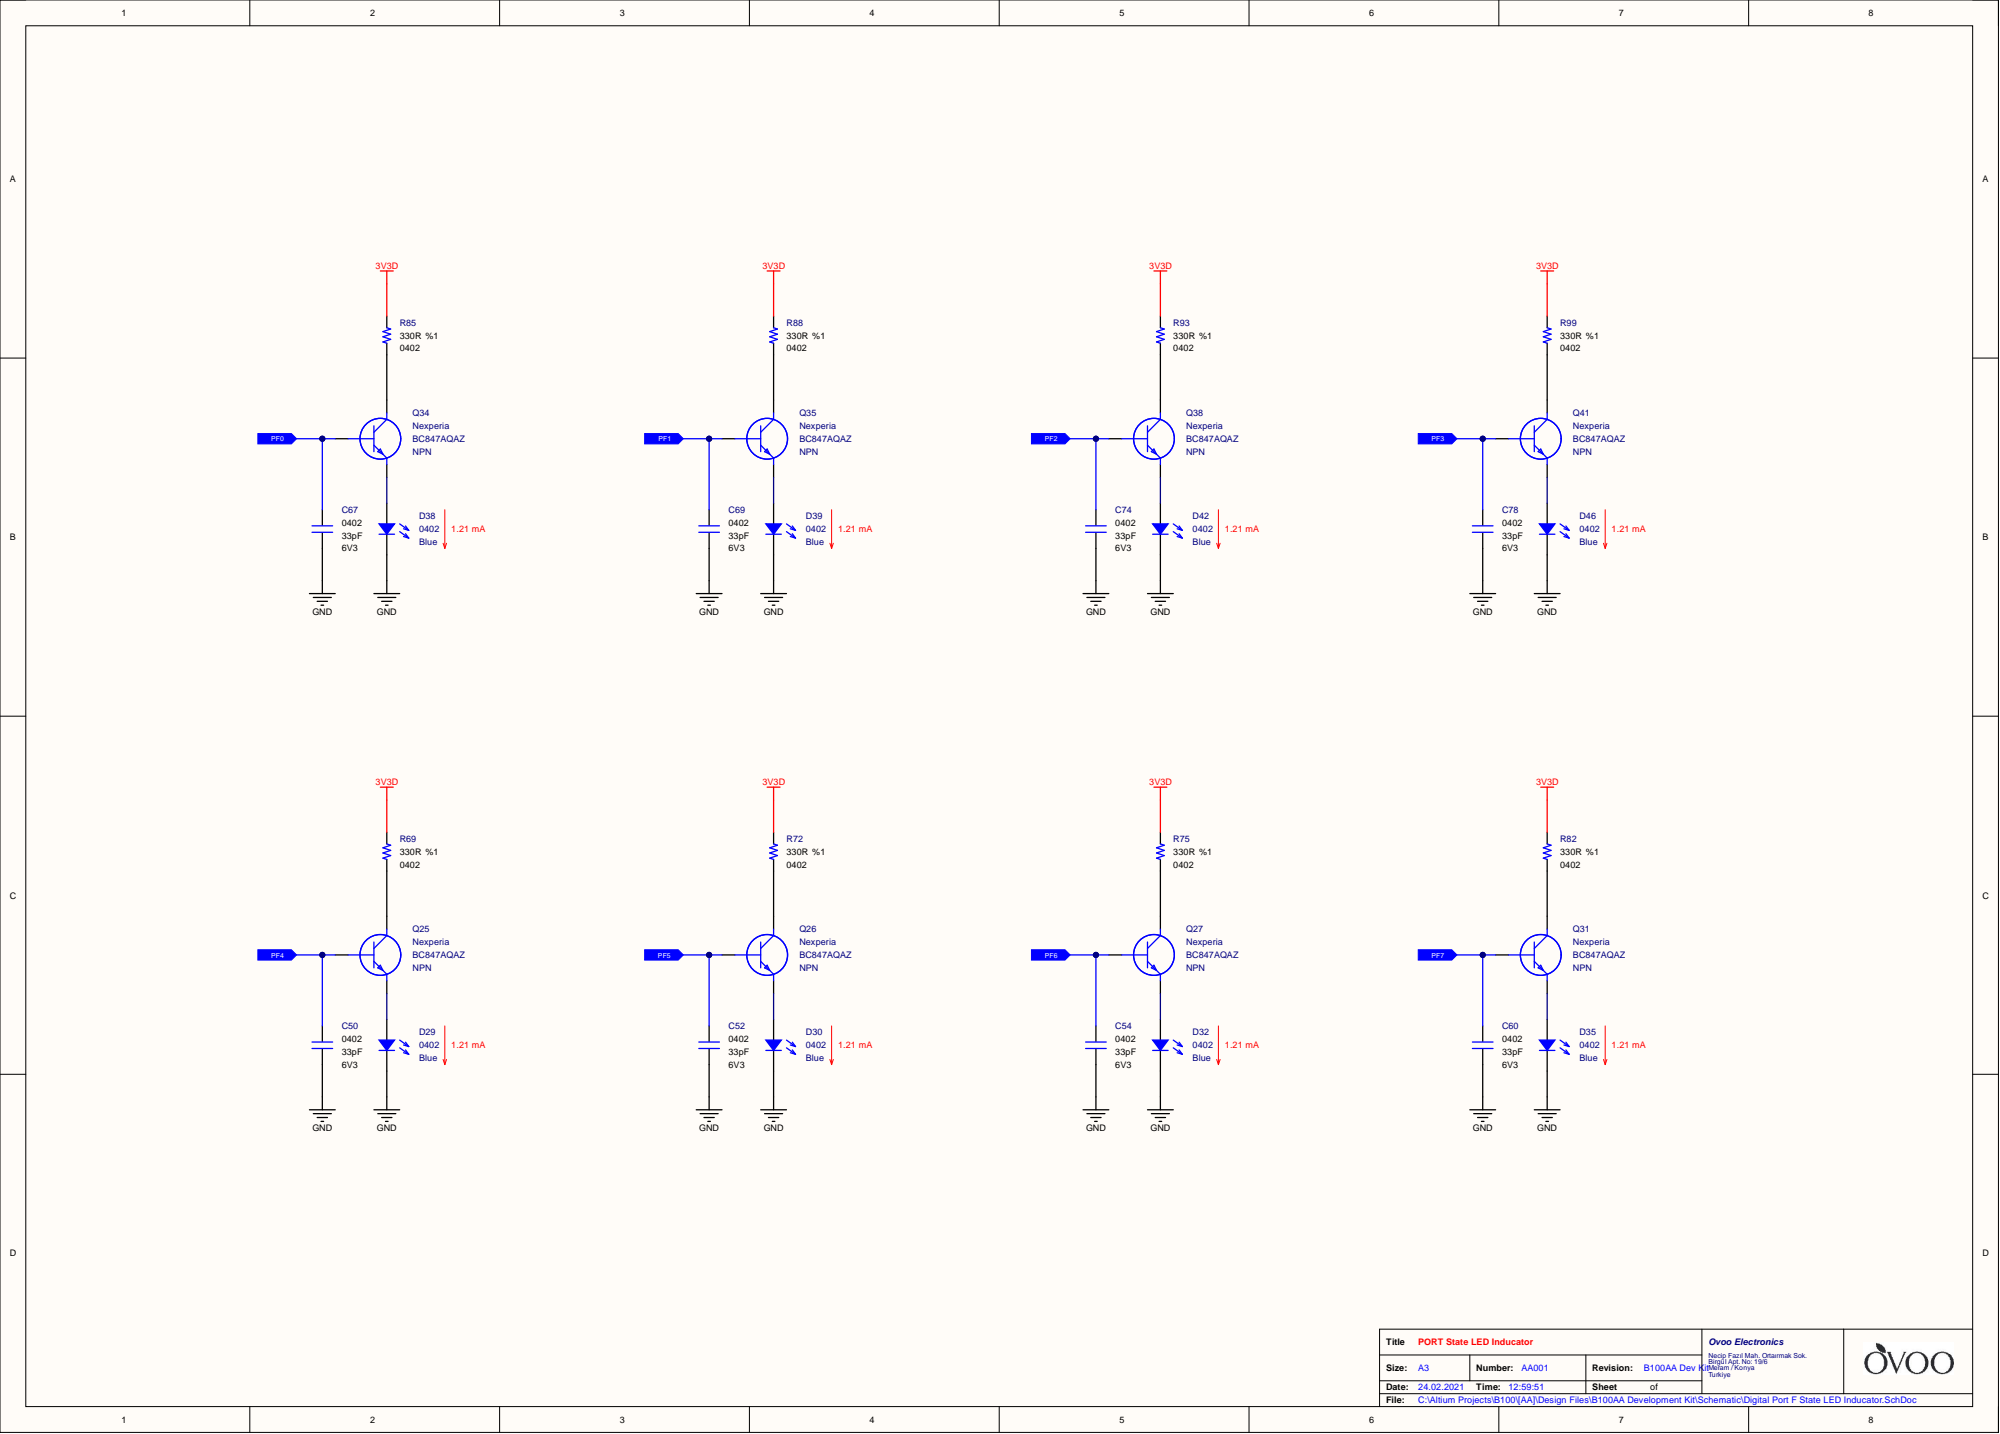
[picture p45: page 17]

PORT State LED Inducator

C:\Altium Projects\B100\[AA]\Design Files\B100AA Development Kit\Schematic\Digital Port F State LED Inducator.SchDoc

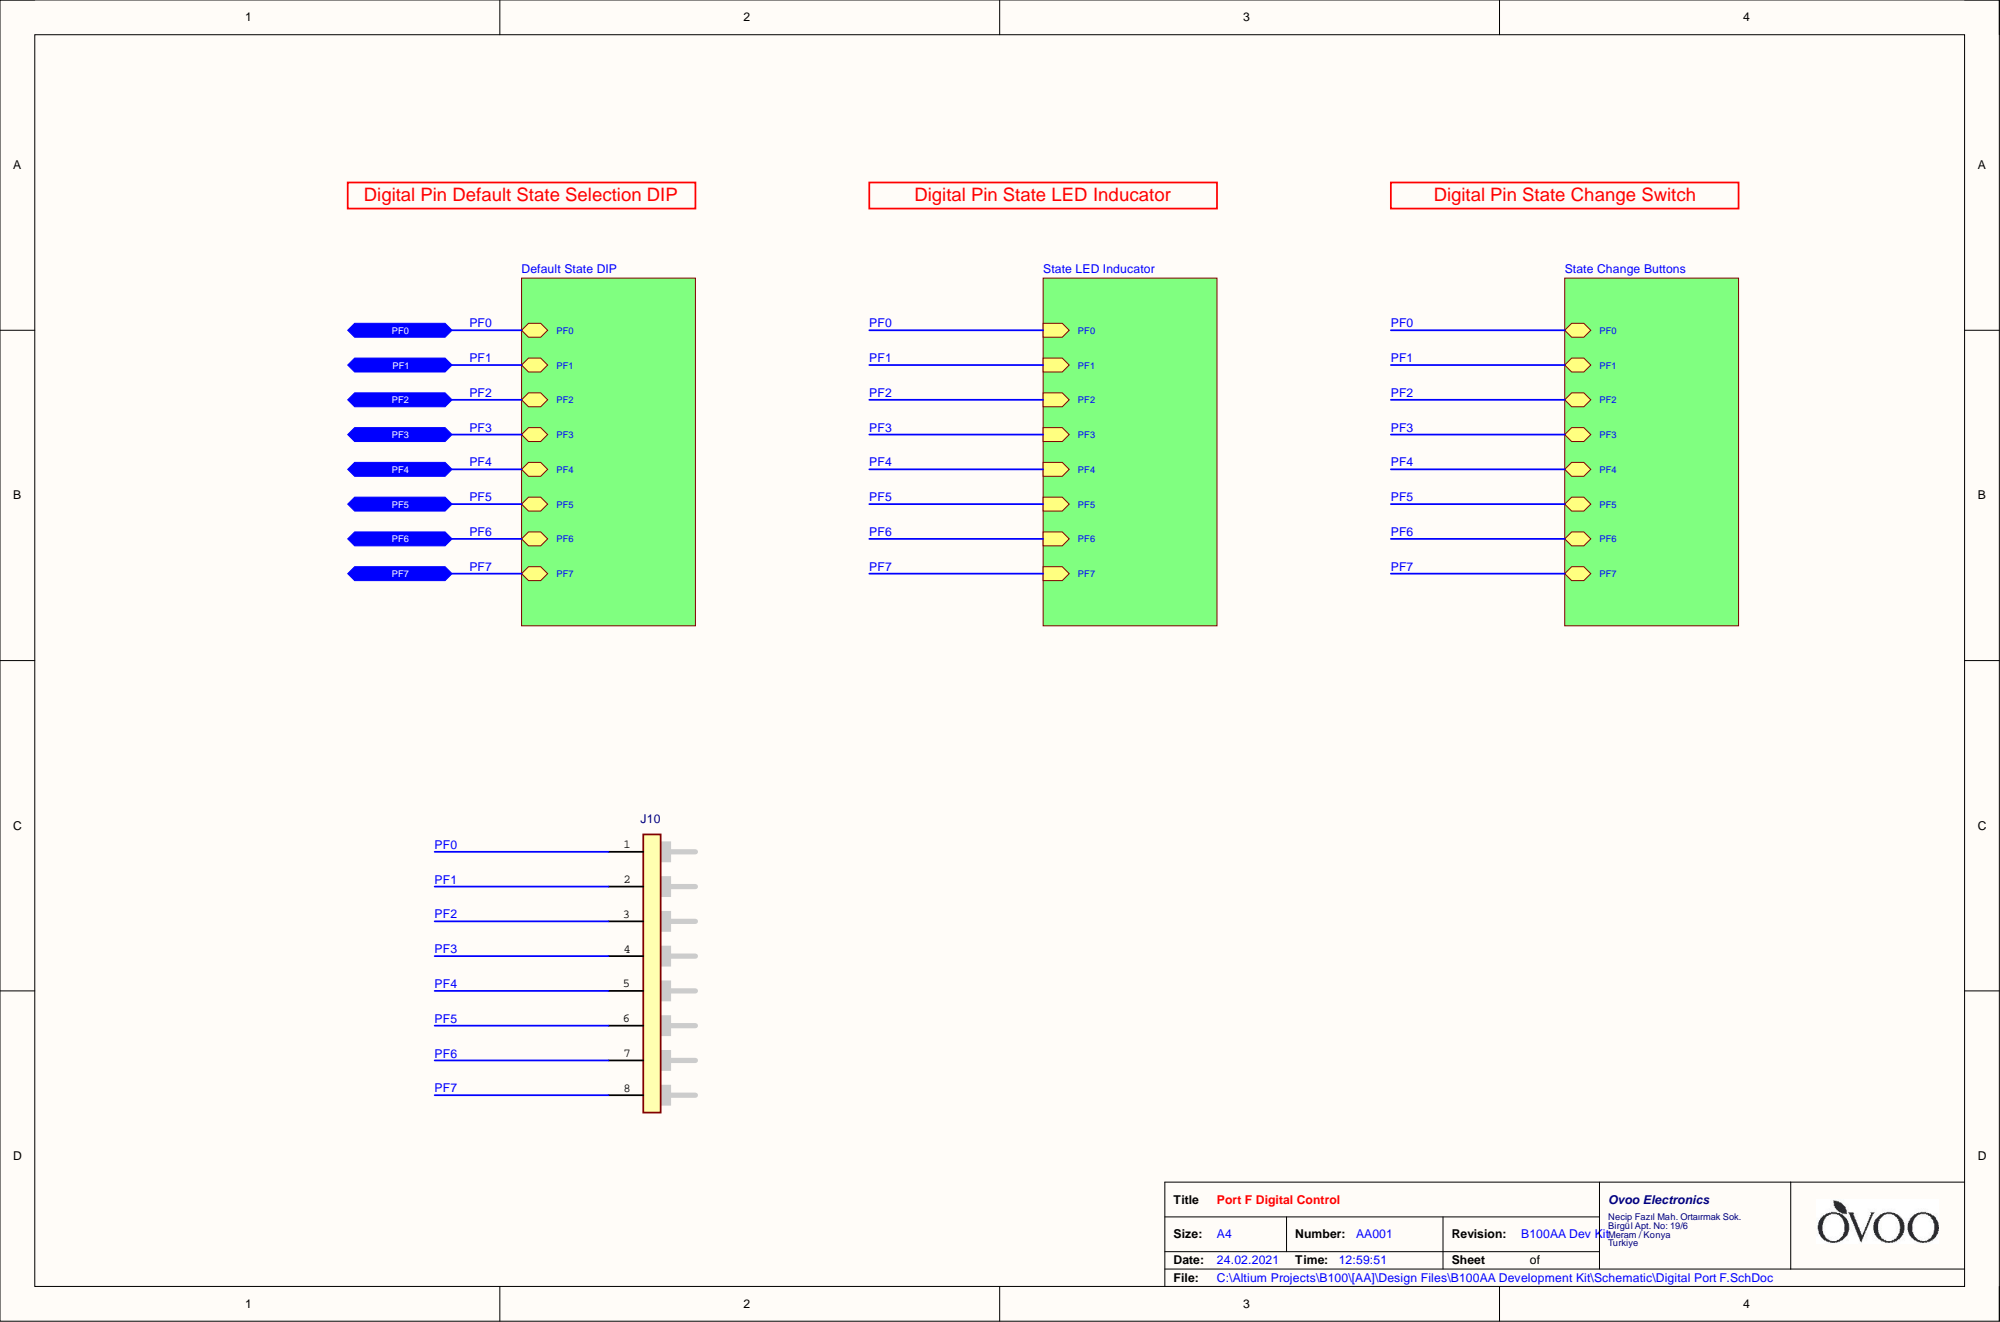
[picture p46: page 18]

Digital Pin Default State Selection DIP

Digital Pin State LED Inducator

Digital Pin State Change Switch

C:\Altium Projects\B100\[AA]\Design Files\B100AA Development Kit\Schematic\Digital Port F.SchDoc

Digital Pin Default State Selection DIP

PORT State Change Buttons

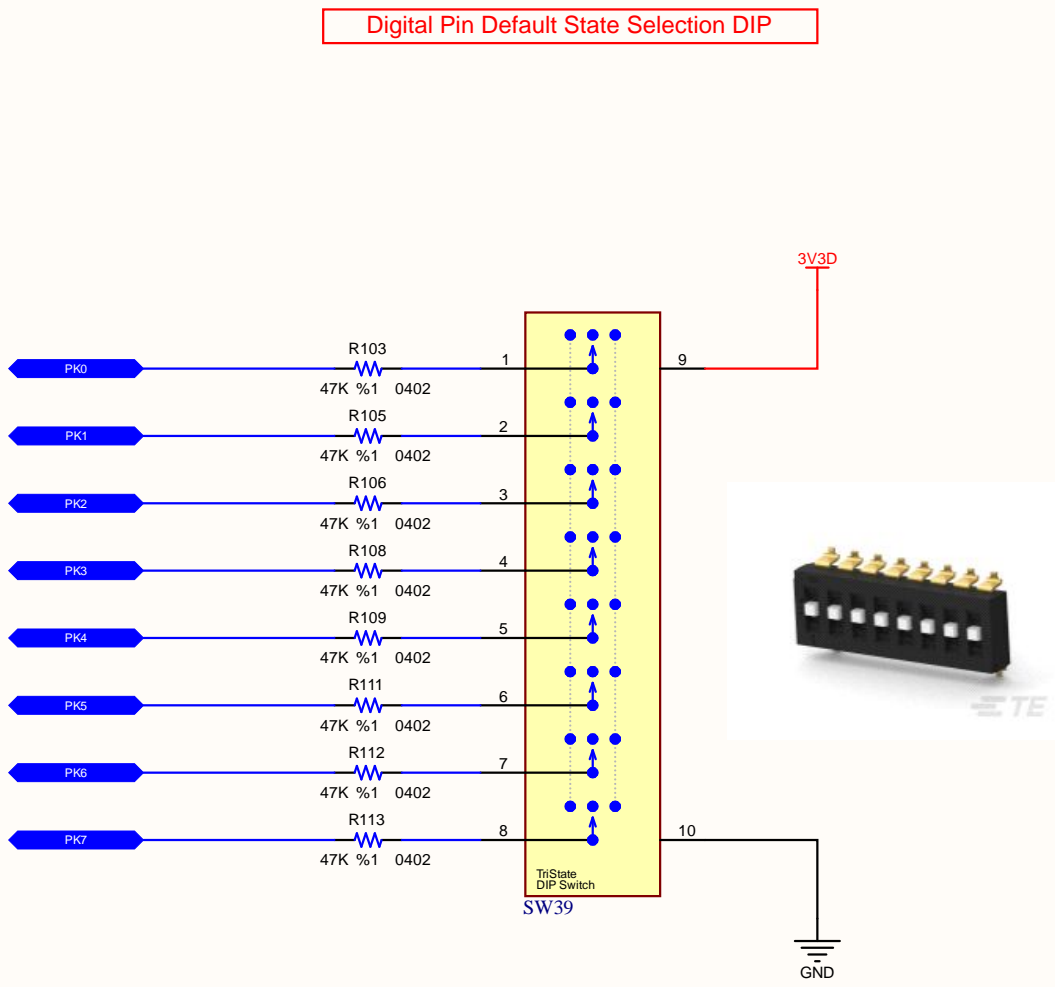
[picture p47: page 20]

Digital Pin Default State Selection DIP

PORT K Default State Selection Switch

C:\Altium Projects\B100\[AA]\Design Files\B100AA Development Kit\Schematic\Digital Port K Default State DIP.SchDoc

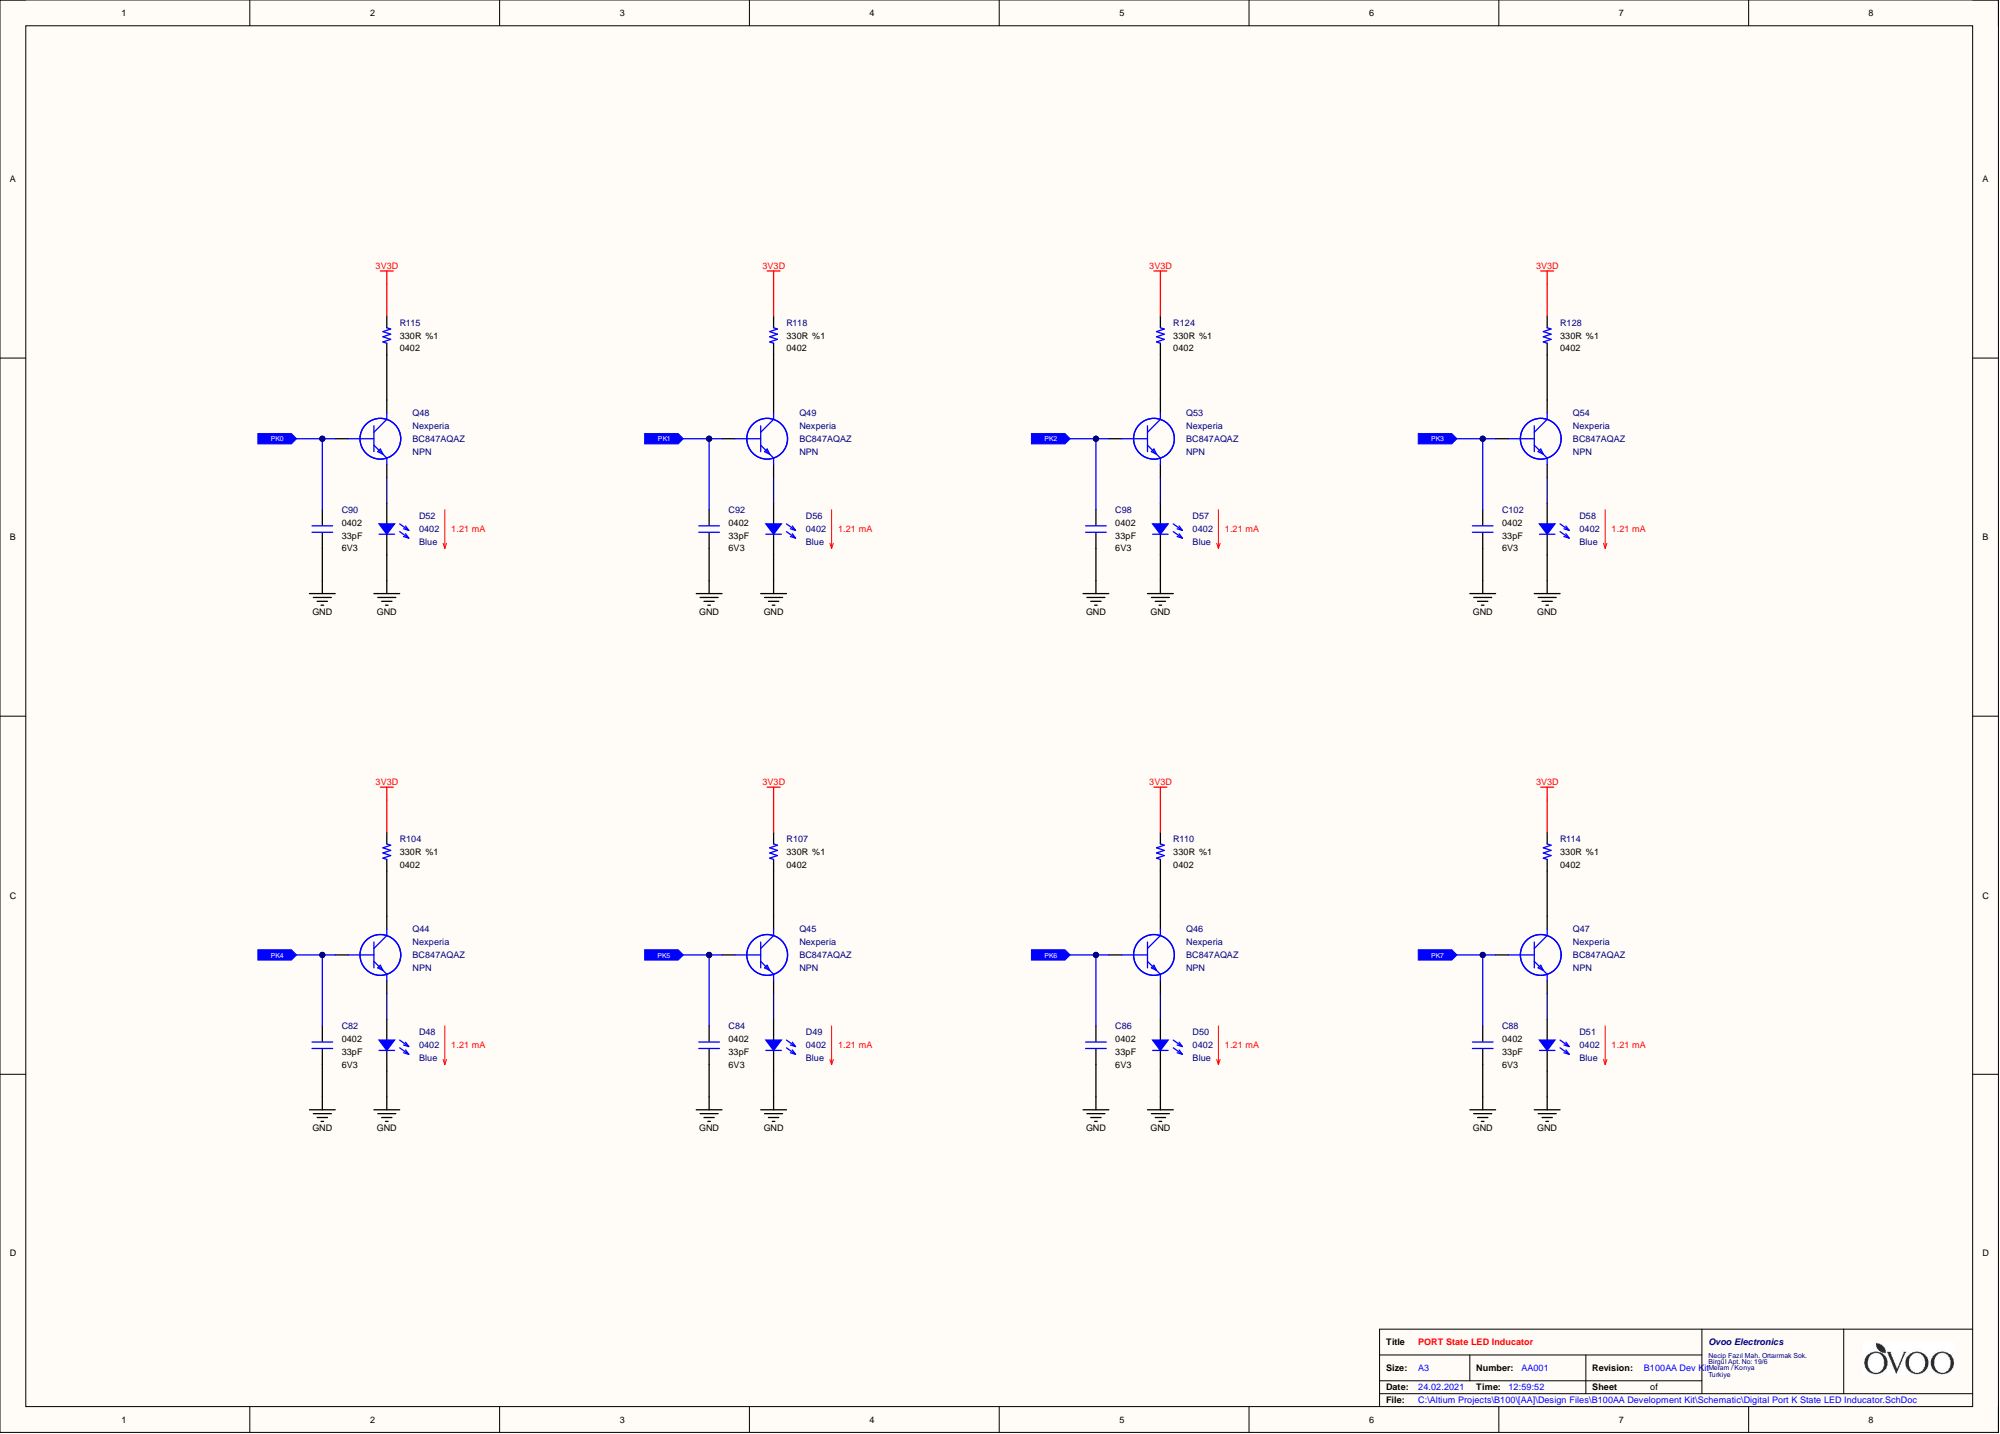
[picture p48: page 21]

PORT State LED Inducator

C:\Altium Projects\B100\[AA]\Design Files\B100AA Development Kit\Schematic\Digital Port K State LED Inducator.SchDoc

Digital Pin Default State Selection DIP

Digital Pin State LED Inducator

Digital Pin State Change Switch

C:\Altium Projects\B100\[AA]\Design Files\B100AA Development Kit\Schematic\Digital Port K.SchDoc

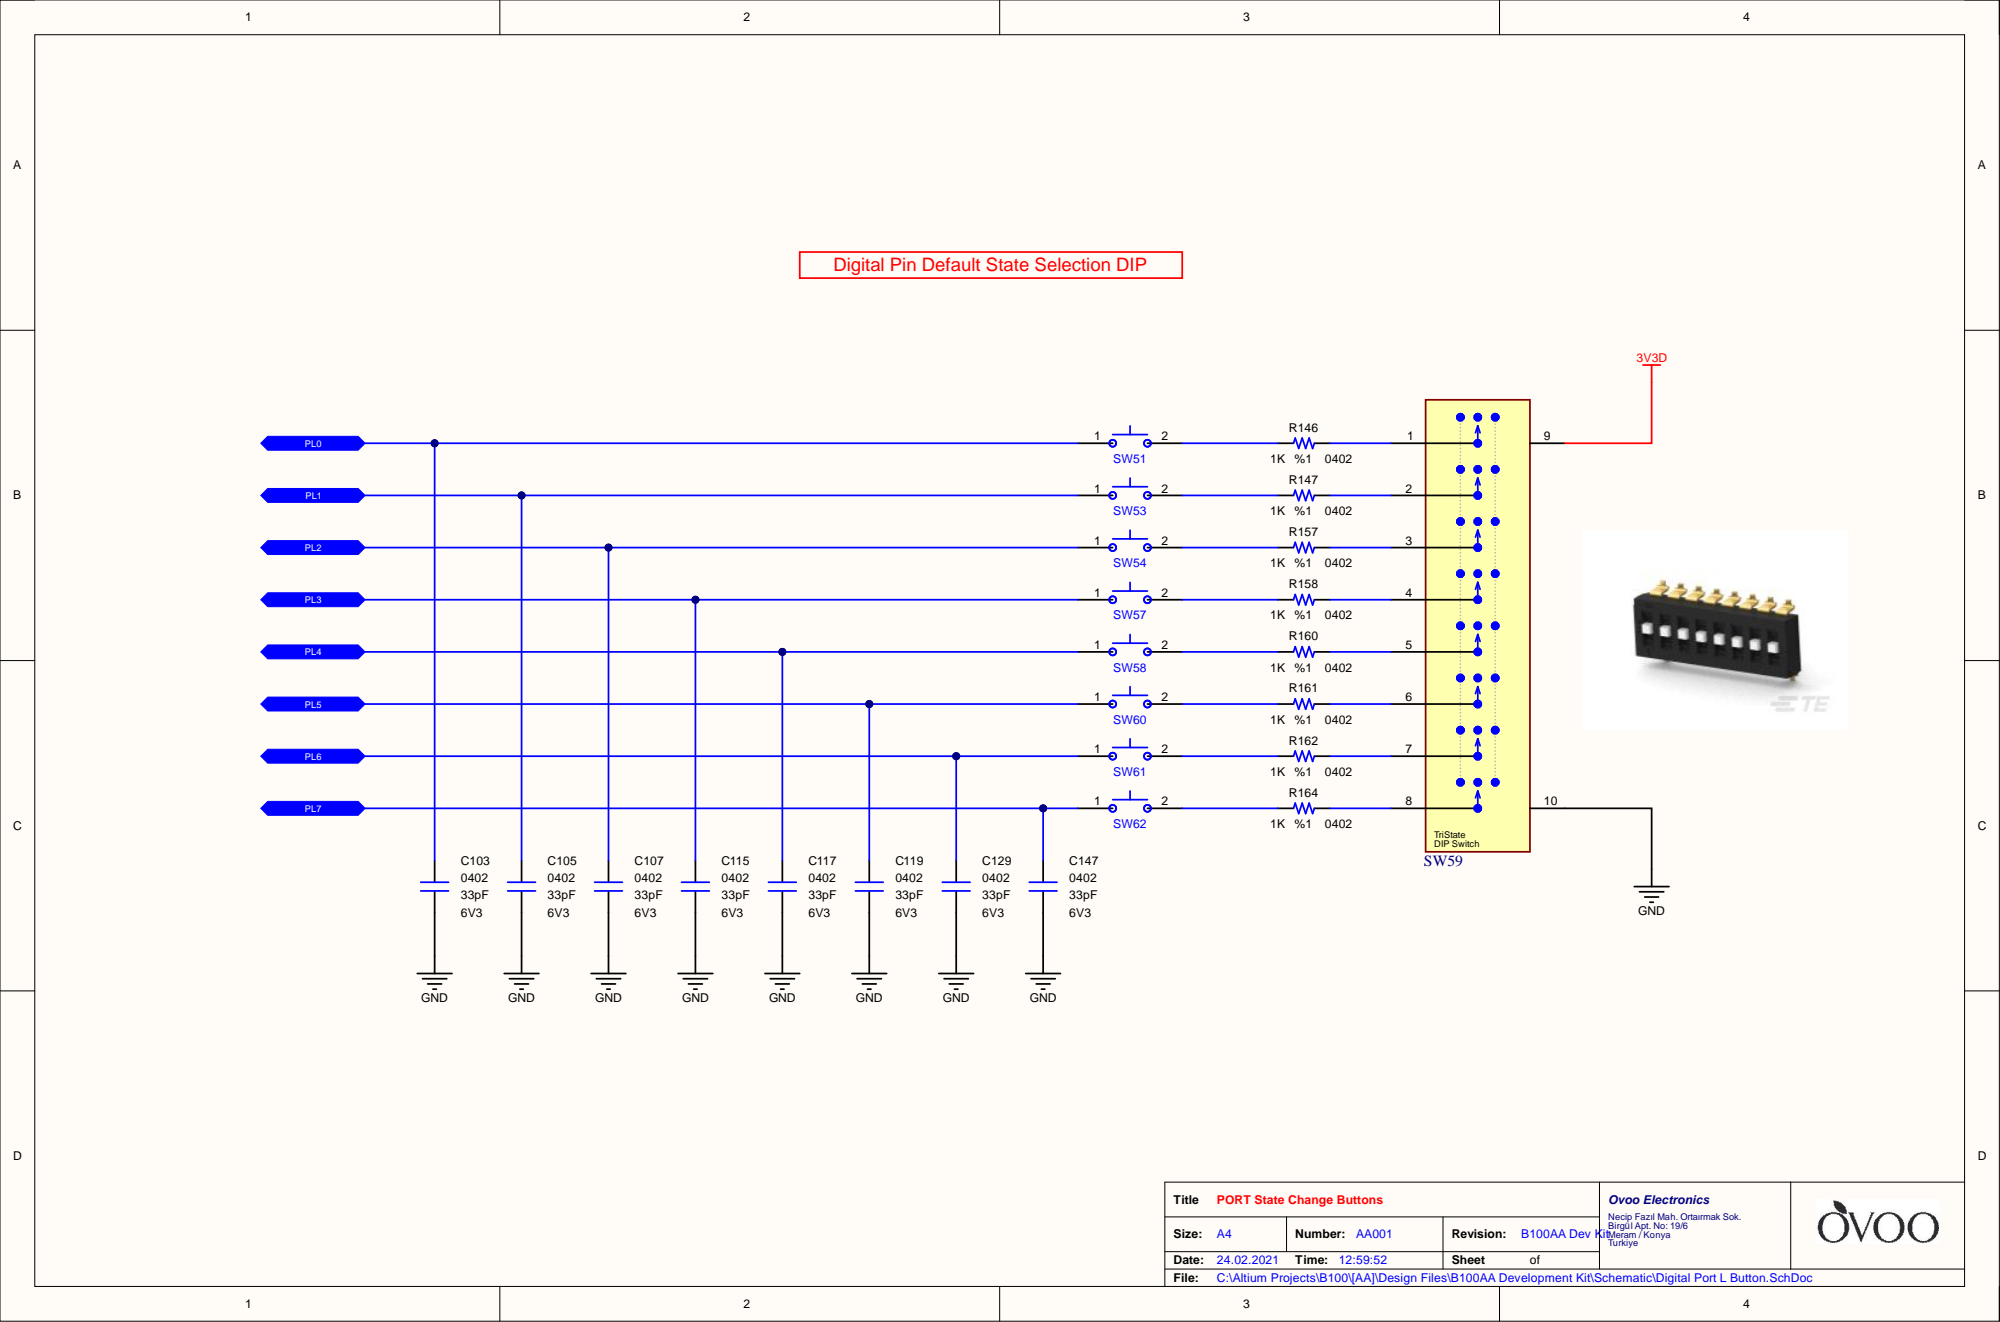
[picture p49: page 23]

Digital Pin Default State Selection DIP

PORT State Change Buttons

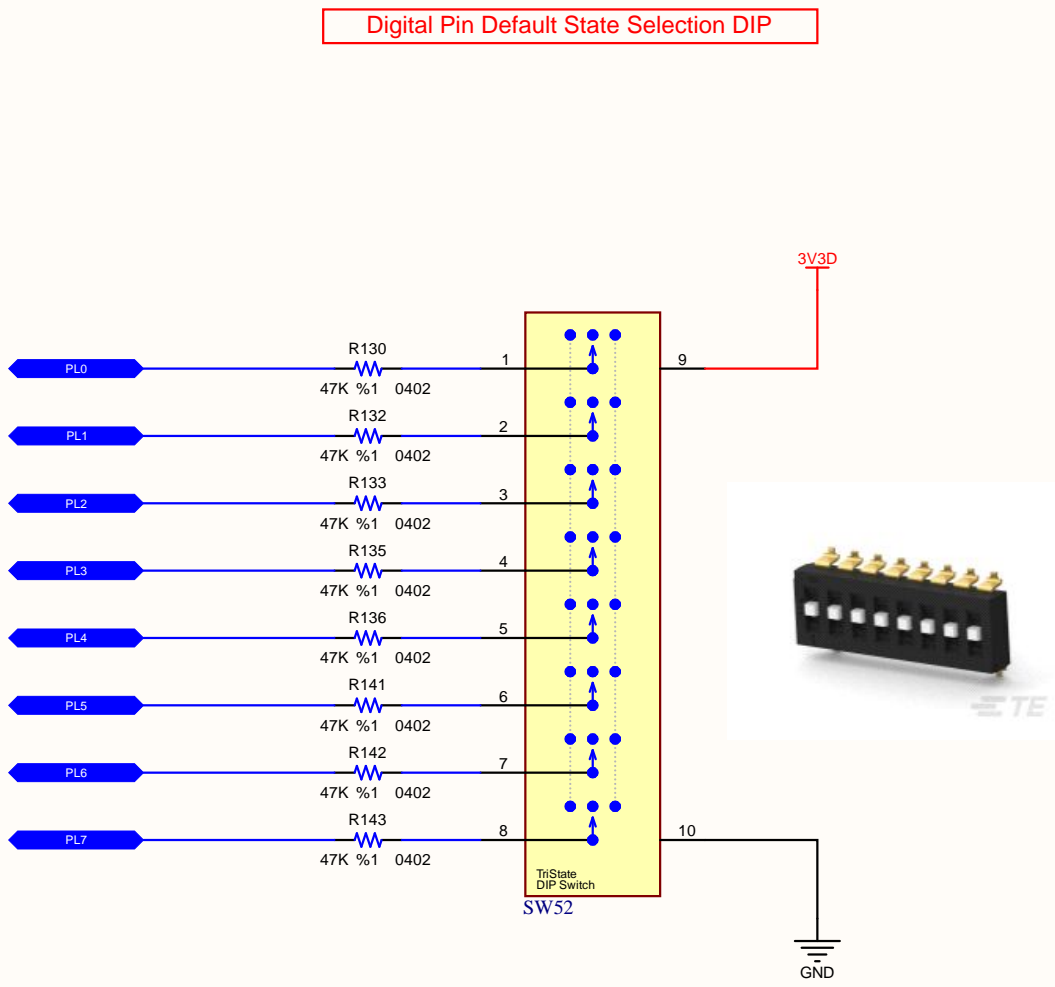
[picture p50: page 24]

Digital Pin Default State Selection DIP

PORT L Default State Selection Switch

C:\Altium Projects\B100\[AA]\Design Files\B100AA Development Kit\Schematic\Digital Port L Default State DIP.SchDoc

PORT State LED Inducator

C:\Altium Projects\B100\[AA]\Design Files\B100AA Development Kit\Schematic\Digital Port L State LED Inducator.SchDoc

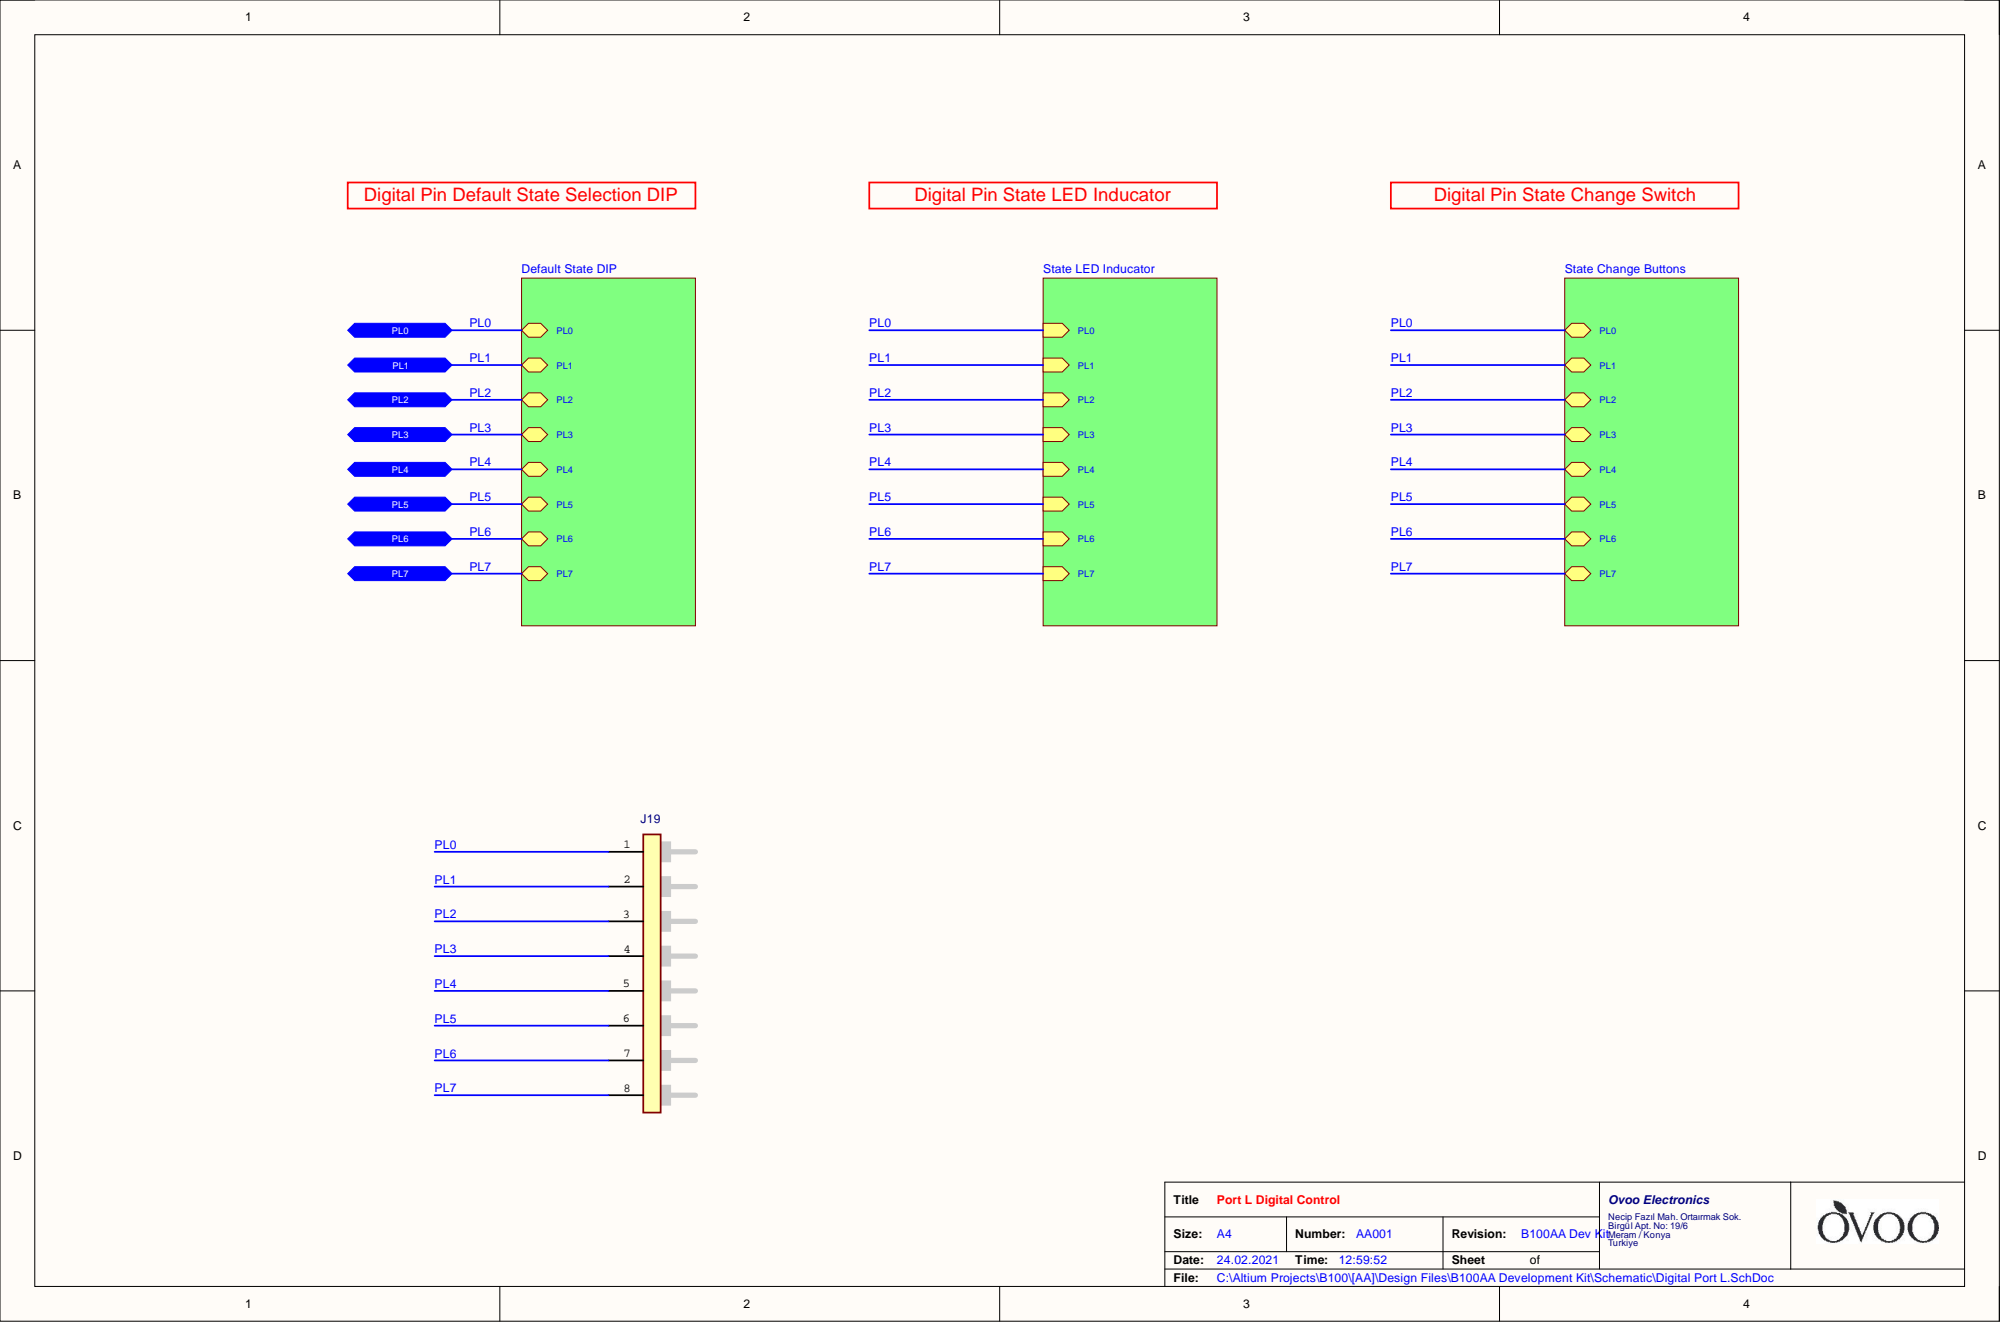
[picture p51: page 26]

Digital Pin Default State Selection DIP

Digital Pin State LED Inducator

Digital Pin State Change Switch

C:\Altium Projects\B100\[AA]\Design Files\B100AA Development Kit\Schematic\Digital Port L.SchDoc

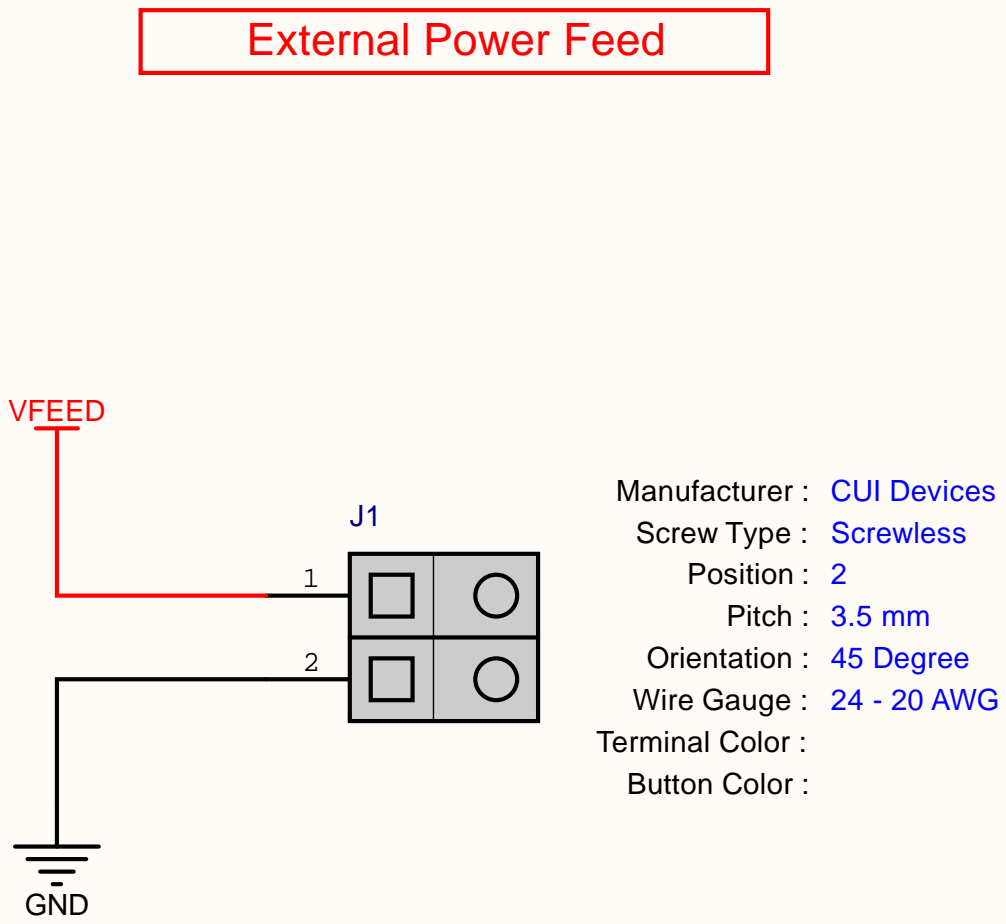
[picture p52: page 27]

C:\Altium Projects\B100\[AA]\Design Files\B100AA Development Kit\Schematic\External Power Feed.SchDoc

TA MCU ICSP Com

TA MCU ICSP Co


C:\Altium Projects\B100\[AA]\Design Files\B100AA Development Kit\Schematic\GSM Communication Signals.SchDoc


C:\Altium Projects\B100\[AA]\Design Files\B100AA Development Kit\Schematic\GSM Control Signals.SchDoc


C:\Altium Projects\B100\[AA]\Design Files\B100AA Development Kit\Schematic\I2C PinOut.SchDoc

ster MCU ICSP Com

ster MCU ICSP Co


C:\Altium Projects\B100\[AA]\Design Files\B100AA Development Kit\Schematic\Power LED Inducators.SchDoc


C:\Altium Projects\B100\[AA]\Design Files\B100AA Development Kit\Schematic\Power Network.SchDoc

C:\Altium Projects\B100\[AA]\Design Files\B100AA Development Kit\Schematic\Power Switch.SchDoc


Power Line Test Pins

C:\Altium Projects\B100\[AA]\Design Files\B100AA Development Kit\Schematic\Power Test Pins.SchDoc


C:\Altium Projects\B100\[AA]\Design Files\B100AA Development Kit\Schematic\Signal Outputs.SchDoc

DRVn signal pull-down
resistor and filter
capacitor.

DONE Pulse must be
greater than 100 nS.

When EN/ONE_SHOT = HIGH, the
TPL5111 works as a timer.

When EN/ONE_SHOT = LOW, the
TPL5111 works as a latched trigger signal

DONE signal pull-down

C:\Altium Projects\B100\[AA]\Design Files\B100AA Development Kit\Schematic\Sleep Timer.SchDoc


Vusb is USB bus voltage.
Feed from outher device via
USB socket. [Vusb = 5V]

Vusb_3V3 is regulated 3V3
voltage. Voltage source is

FT234XD has a 8.3mA
max orerating current and
125uAsuspend current.

LED is a data transfer
inducator. Blinks both
Rx and Tx.

CBUS output current is max
22mA. Calculated current is

Frequency of Operation : 12 MHz

C:\Altium Projects\B100\[AA]\Design Files\B100AA Development Kit\Schematic\UART Communication.SchDoc

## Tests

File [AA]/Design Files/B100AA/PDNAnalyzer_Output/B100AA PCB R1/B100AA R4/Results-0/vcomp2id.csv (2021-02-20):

vrefdes | id
VCOMP0 | 0
VCOMP1 | 1
VCOMP2 | 2
VCOMP3 | 3
VCOMP4 | 4
VCOMP5 | 5
VCOMP6 | 6
VCOMP7 | 7
VCOMP8 | 8
VCOMP9 | 9
VCOMP10 | 10
VCOMP11 | 11
VCOMP12 | 12
VCOMP13 | 13
VCOMP14 | 14
VCOMP15 | 15
VCOMP16 | 16
VCOMP17 | 17
VCOMP18 | 18
VCOMP19 | 19
VCOMP20 | 20
VCOMP21 | 21
VCOMP22 | 22
VCOMP23 | 23
VCOMP24 | 24
VCOMP25 | 25
VCOMP26 | 26
VCOMP27 | 27
VCOMP28 | 28
VCOMP29 | 29
VCOMP30 | 30
VCOMP31 | 31
VCOMP32 | 32
VCOMP33 | 33
VCOMP34 | 34
VCOMP35 | 35
VCOMP36 | 36
VCOMP37 | 37
VCOMP38 | 38
VCOMP39 | 39
VCOMP40 | 40
VCOMP41 | 41
VCOMP42 | 42
VCOMP43 | 43
VCOMP44 | 44
VCOMP45 | 45
VCOMP46 | 46
VCOMP47 | 47
VCOMP48 | 48
VCOMP49 | 49
VCOMP50 | 50
VCOMP51 | 51
VCOMP52 | 52
VCOMP53 | 53
VCOMP54 | 54
VCOMP55 | 55
VCOMP56 | 56
VCOMP57 | 57
VCOMP58 | 58
VCOMP59 | 59
VCOMP60 | 60
VCOMP61 | 61
VCOMP62 | 62
VCOMP63 | 63
VCOMP64 | 64
VCOMP65 | 65
VCOMP66 | 66

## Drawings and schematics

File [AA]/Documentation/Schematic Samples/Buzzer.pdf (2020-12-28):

# Buzz 3 Click schematic v100

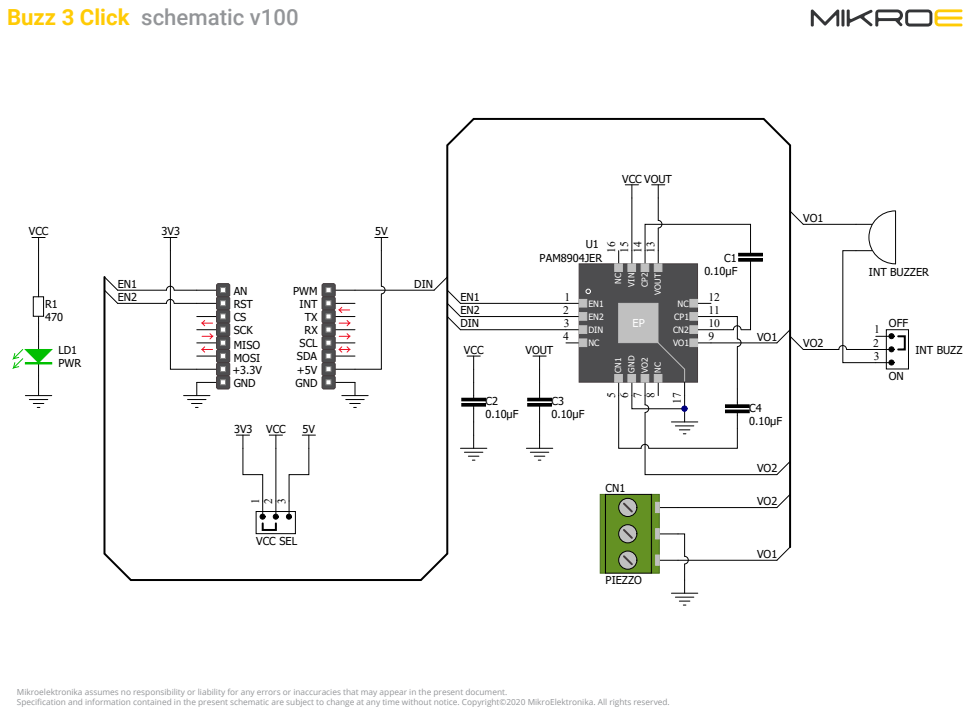
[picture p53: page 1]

Mikroelektronika assumes no responsibility or liability for any errors or inaccuracies that may appear in the present document.
Specification and information contained in the present schematic are subject to change at any time without notice. Copyright©2020 MikroElektronika. All rights reserved.

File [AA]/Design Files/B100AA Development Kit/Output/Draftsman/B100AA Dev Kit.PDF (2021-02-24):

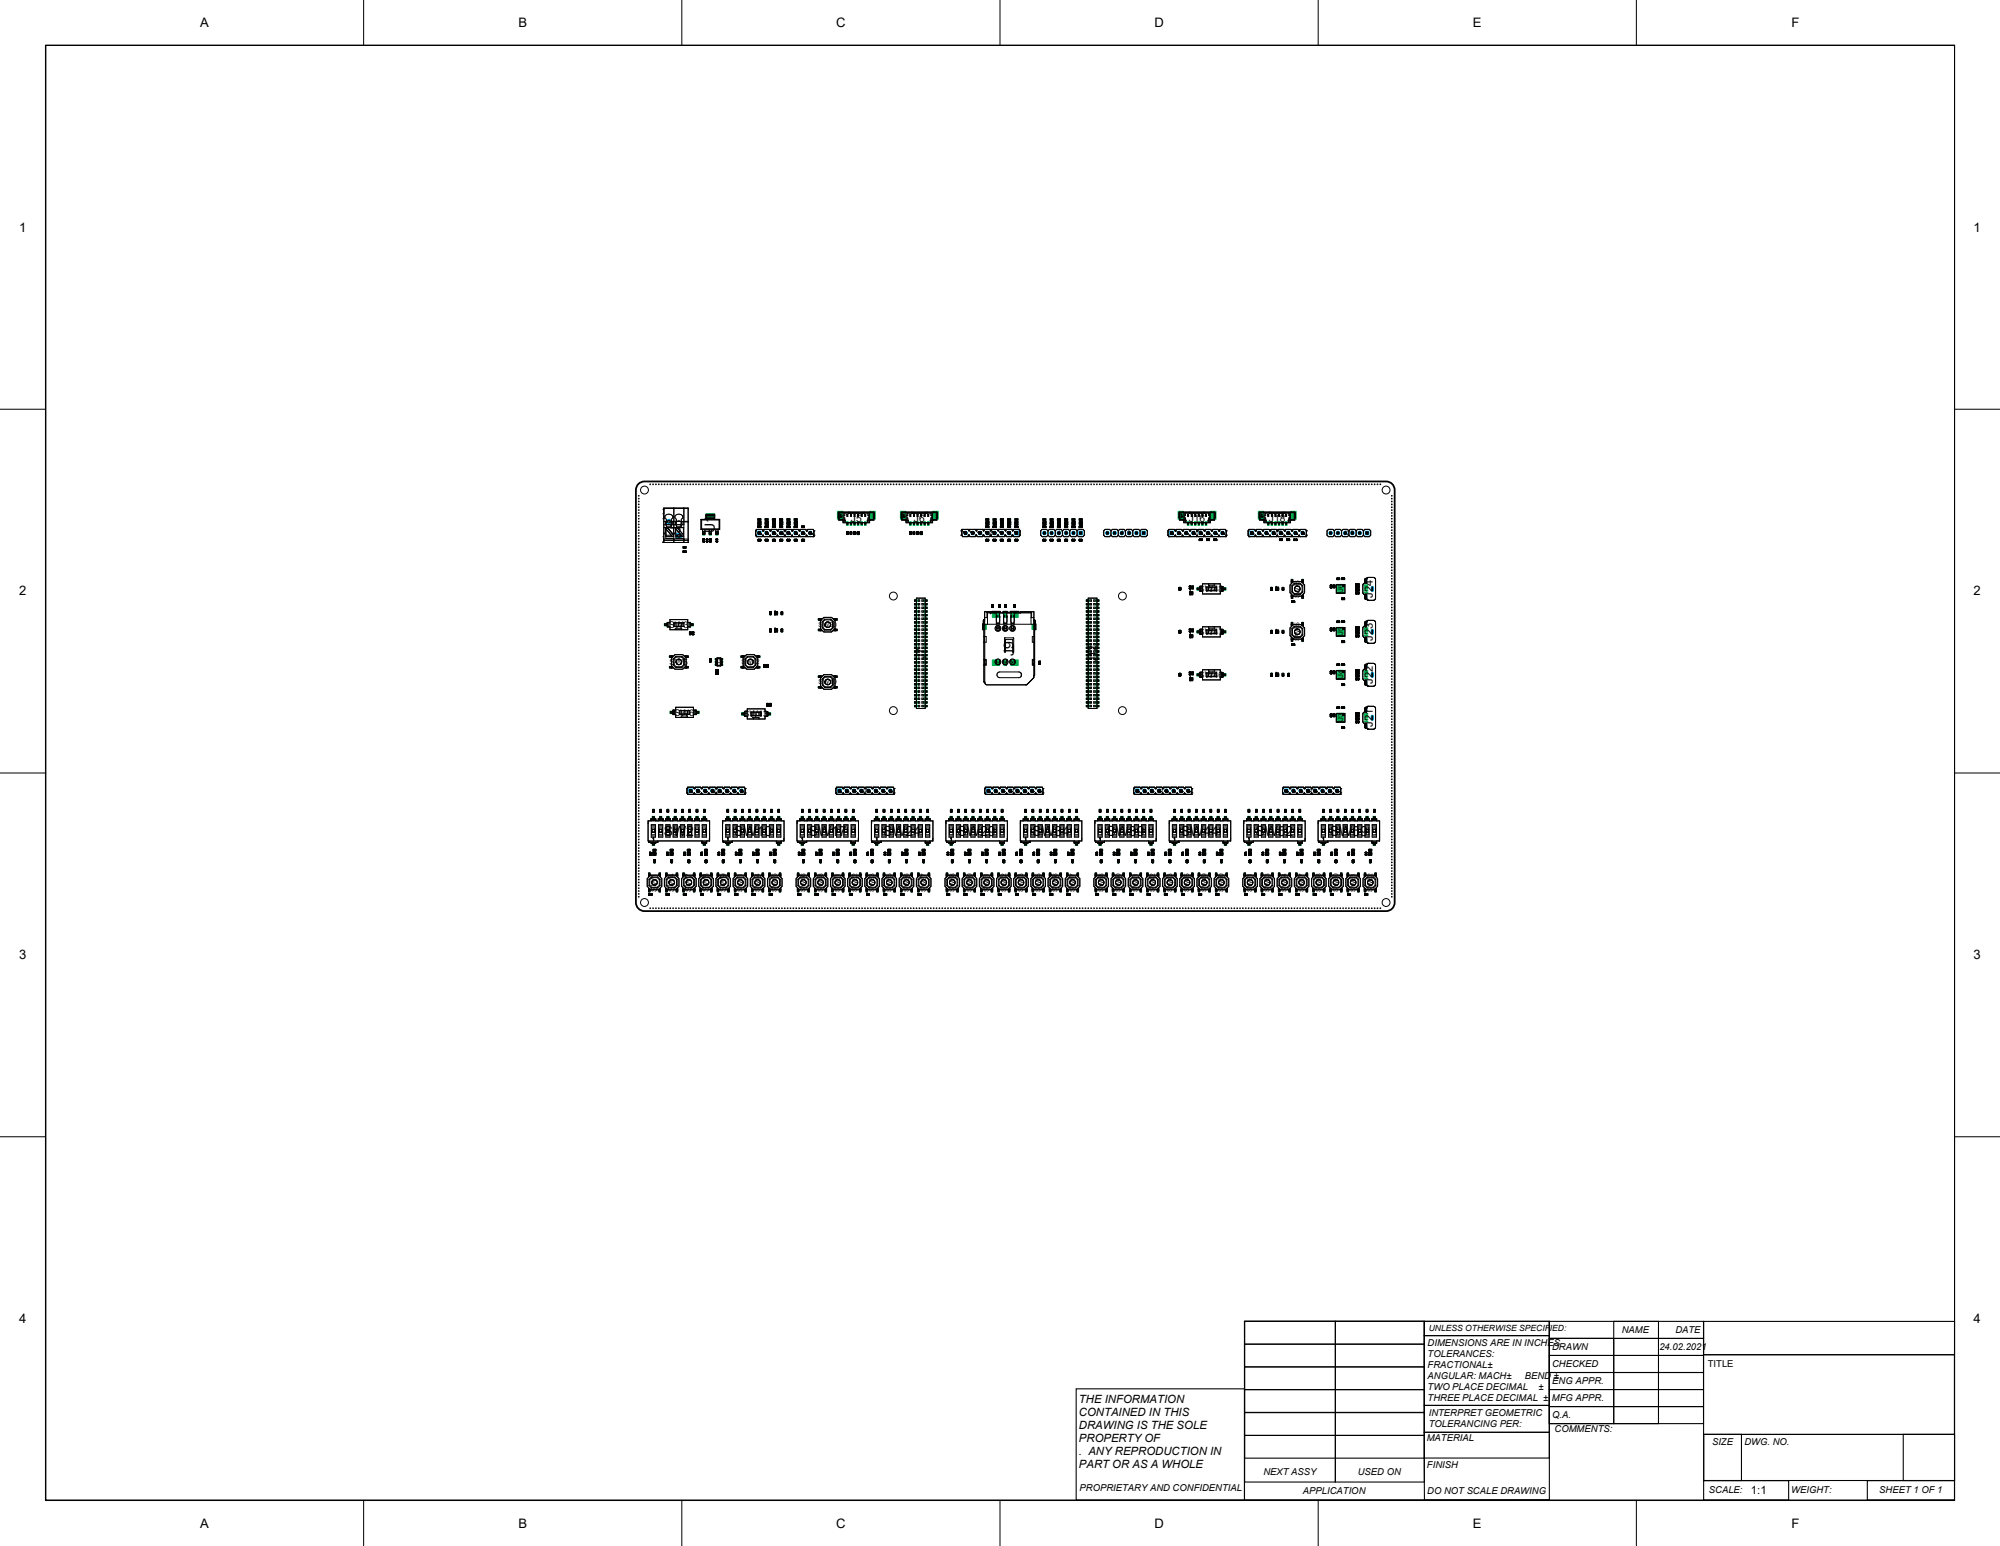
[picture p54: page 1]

UNLESS OTHERWISE SPECIFIED:
DIMENSIONS ARE IN INCHES
TOLERANCES:
FRACTIONAL±
TWO PLACE DECIMAL ±
THREE PLACE DECIMAL ±
INTERPRET GEOMETRIC
TOLERANCING PER:
MATERIAL

THE INFORMATION
CONTAINED IN THIS
DRAWING IS THE SOLE
PROPERTY OF
. ANY REPRODUCTION IN
PART OR AS A WHOLE

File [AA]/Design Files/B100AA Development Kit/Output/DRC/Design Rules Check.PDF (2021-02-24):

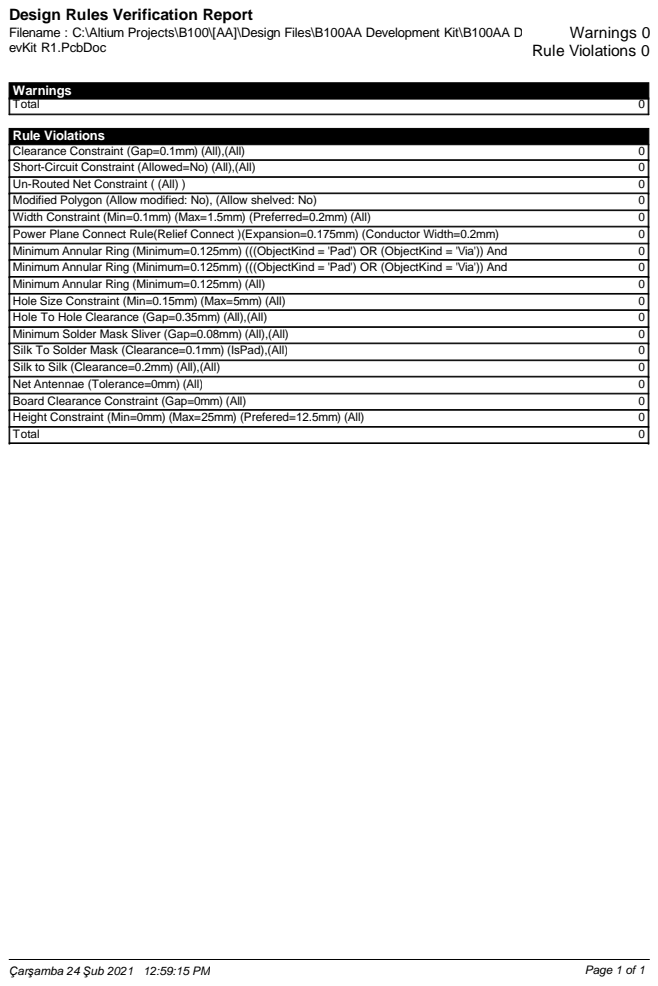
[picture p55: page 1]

Design Rules Verification Report
Filename : C:\Altium Projects\B100\[AA]\Design Files\B100AA Development Kit\B100AA D
evKit R1.PcbDoc

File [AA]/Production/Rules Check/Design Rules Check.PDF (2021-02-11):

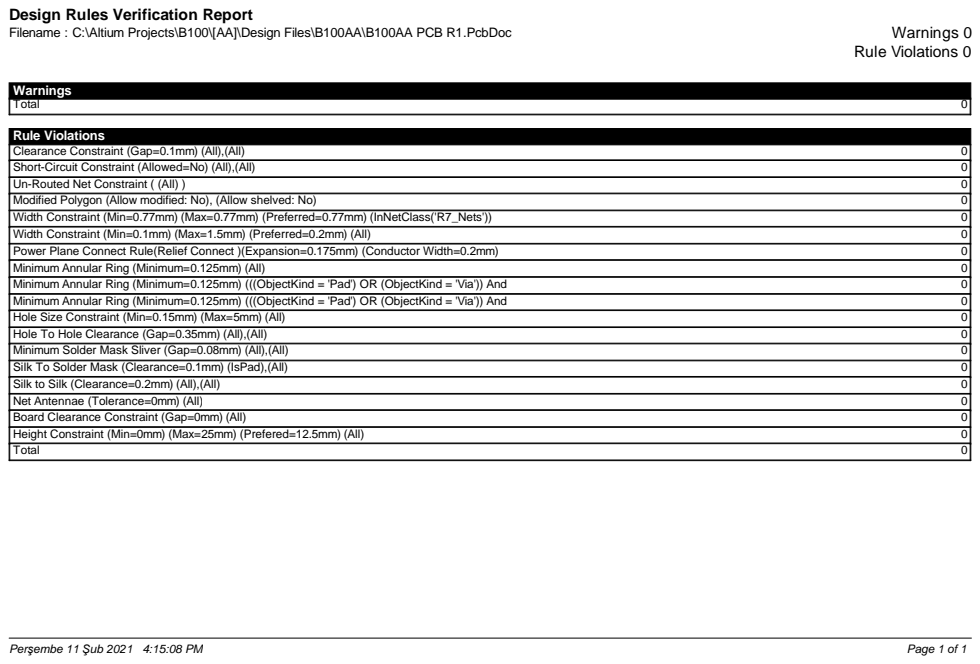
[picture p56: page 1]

Design Rules Verification Report

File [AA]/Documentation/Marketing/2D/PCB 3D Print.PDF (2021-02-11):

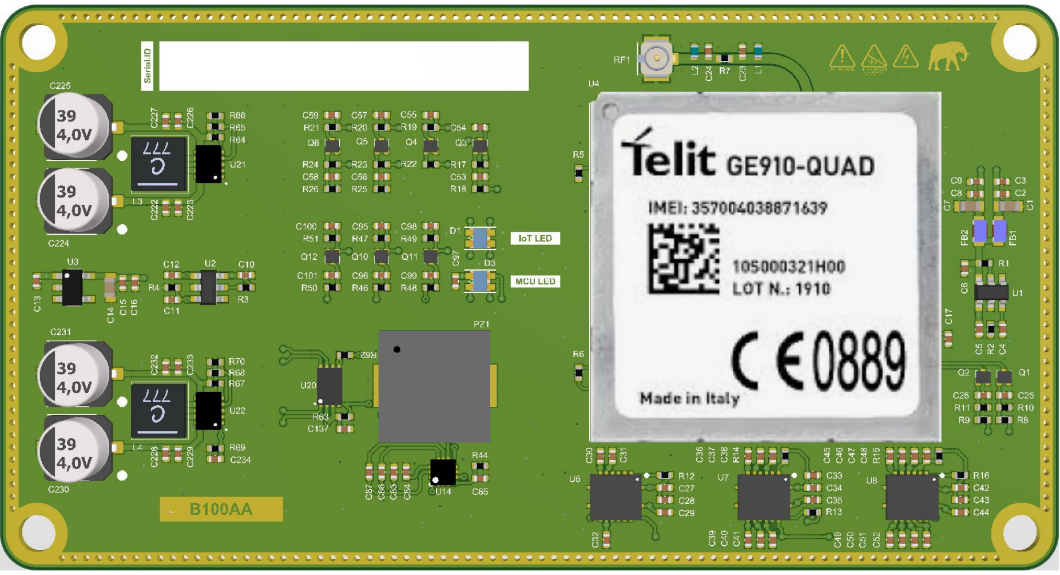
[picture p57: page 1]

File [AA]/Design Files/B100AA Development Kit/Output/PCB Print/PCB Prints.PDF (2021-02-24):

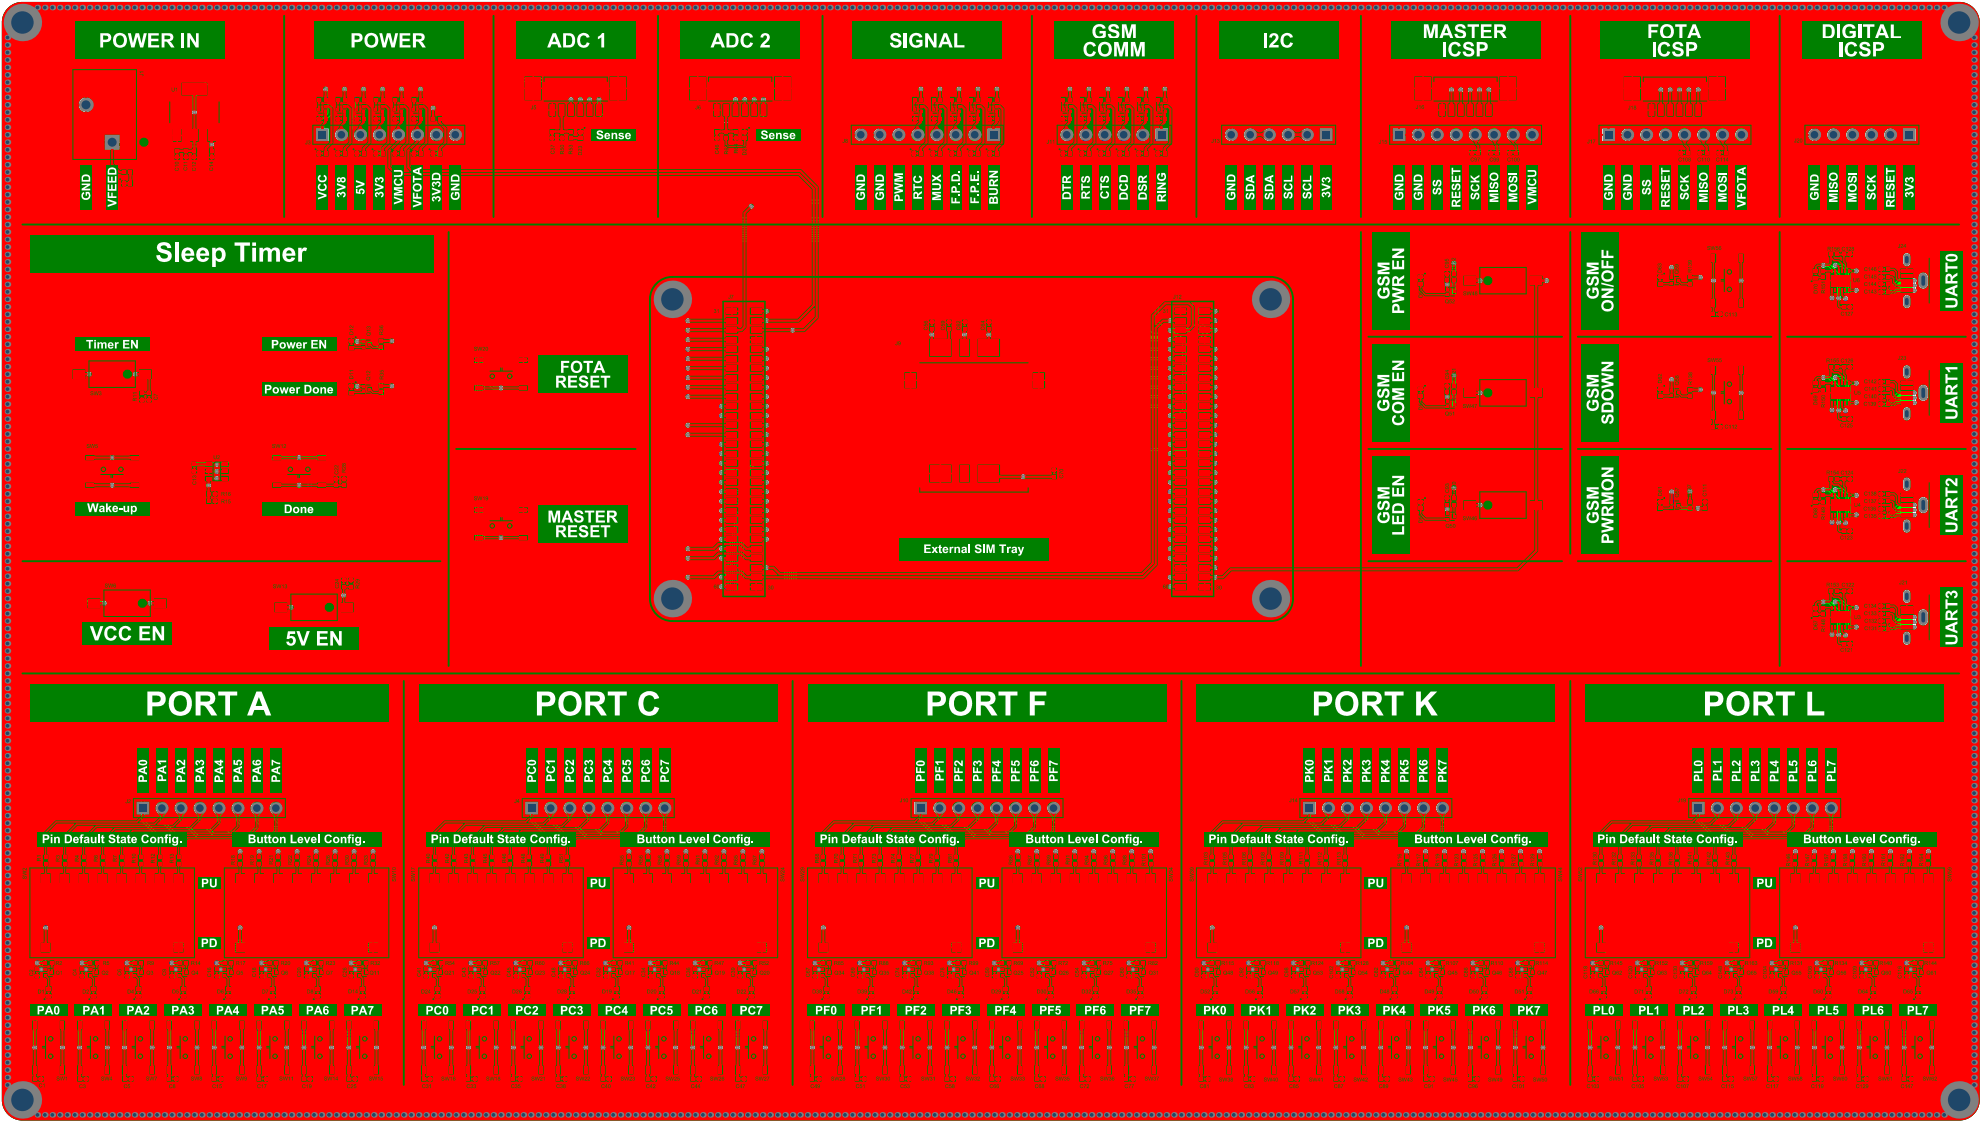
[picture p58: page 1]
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

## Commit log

2020-12-26 Altium file update
    [B100.PrjPcb, B100AA - Block Diagram.SchDoc]
2020-12-26 Folder Update
    Altium folder structure update.
    [B100.PrjPcb, B100AA - Block Diagram.SchDoc]
2020-12-28 Update MCU Pin Map.numbers
2020-12-28 Buck boost regülatör sayfası eklendi.
    [B100.PrjPcb]
2020-12-28 Altium Update
    [B100AA - Block Diagram.SchDoc, Buck Boost Converter.SchDoc]
2020-12-28 Create MCU Pin Map.pdf
2021-01-03 Pin Map Update
2021-01-04 Page number update (Altium)
    [3V3 LDO Regulator.SchDoc]
2021-01-04 Altium page number update
    [B100 Block Diagram.SchDoc, Bidirectional Voltage Translator.SchDoc, Buck Boost Converter.SchDoc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]
2021-01-04 BOM Update
2021-01-05 Schematic document update
2021-01-11 Altium Update
    Design Review düzenlemeleri yapıldı.
    [3V3 LDO Regulator.SchDoc, B100 Block Diagram.SchDoc, B100.PrjPcb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]
2021-01-21 Altium component update
    [3V3 LDO Regulator.SchDoc, 3V8 Buck Boost Converter.SchDoc, 5V Buck Boost Converter.SchDoc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]
2021-01-21 PCB Update
    [B100.PrjPcb]
2021-01-22 Altium R4 Update
    [B100 Block Diagram.SchDoc, B100.PrjPcb, Bill of Materials-B100.csv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]
2021-01-26 Altium PCB Update
    [3V3 LDO Regulator.SchDoc, 3V8 Buck Boost Converter.SchDoc, 5V Buck Boost Converter.SchDoc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]
2021-01-28 review update
    [Bill of Materials-B100.csv]
2021-02-03 Telit Review Update
    [B100AA PCB R1.GBL, B100AA PCB R1.GBO, B100AA PCB R1.GBP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]
2021-02-12 Design review update.
    [B100AA PCB R1.GBL, B100AA PCB R1.GBO, B100AA PCB R1.GBP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]
2021-02-12 Folder Update
    [Assembly Testpoint Report for B100AA PCB R1.csv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]
2021-02-12 XLS export problem.
    [B100.PrjPcb]
2021-02-12 Antenna filter component pads are updated.
2021-02-12 Power line under the antenna zone is retraced.
2021-02-12 Bug update (output job execute)
    [Assembly Testpoint Report for B100AA PCB R1.csv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]
2021-02-16 Development Kit Update
    [3V3 LDO Regulator.SchDoc, 5V Enable.SchDoc, ADS Sensor Sockets.SchDoc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]
2021-02-17 Development Board Update
    [5V Enable.SchDoc, B100AA Development Kit.PrjPcb, Digital Port A Button.SchDoc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]
2021-02-20 Production update
    [B100.PrjPcb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]
2021-02-21 Output Job Update
    [B100.PrjPcb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]
2021-02-21 Update B100AA PCB R1.PCBDwf
2021-02-22 Bom List Update
2021-02-26 Component BOM P/N field name update.
    [GSM Power.SchDoc]
2021-02-26 Component parameter fields update, BOM update
    [3V3 LDO Regulator.SchDoc, 3V8 Buck Boost Converter.SchDoc, 5V Buck Boost Converter.SchDoc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]
2021-03-03 Title Update
    [3V3 LDO Regulator.SchDoc, 3V8 Buck Boost Converter.SchDoc, 5V Buck Boost Converter.SchDoc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]
2021-03-04 Project name change
    [B100AA PCB R1.GBL, B100AA PCB R1.GBO, B100AA PCB R1.GBP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]
2021-03-04 Altium 21 update
    [3V8 Buck Boost Converter.SchDoc, B100AA.PrjPcb]
2021-03-04 B100BA Project Start
    [3V3 LDO Regulator.SchDoc, 3V8 Buck Boost Converter.SchDoc, 5V Buck Boost Converter.SchDoc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]
2021-03-04 Template Update
    [3V3 LDO Regulator.SchDoc, 3V8 Buck Boost Converter.SchDoc, 5V Buck Boost Converter.SchDoc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]
2021-03-04 pre Release update
    [B100AA.PrjPcb]
2021-03-04 Initial Update
    [B100BA.PrjPcb]
2021-03-04 Schematic Template Update
    [B100 Block Diagram.SchDoc, GSM IoT.SchDoc, I2C Network.SchDoc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]
2021-03-05 I2C Update
    [Analog Digital Converter.SchDoc, B100 Block Diagram.SchDoc, B100BA.PrjPcb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]
2021-03-05 Schematic Update
    [3V3 LDO Regulator.SchDoc, 3V8 Buck Boost Converter.SchDoc, 5V Buck Boost Converter.SchDoc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]
2021-03-07 Buck Boost Update (on progress)
    [3V8 Buck Boost Converter.SchDoc]
2021-03-07 Buck Boost Update
    [3V8 Buck Boost Converter.SchDoc, B100BA.PrjPcb]
2021-03-07 3V8 Buck Boost Schematic Update
    [3V8 Buck Boost Converter.SchDoc, B100BA.PrjPcb]
2021-03-07 Buck boost regulator update.
    [3V8 Buck Boost Converter.SchDoc]
2021-03-07 Power Section Update
    [B100BA.PrjPcb, GSM Power.SchDoc, Power Source.SchDoc]
2021-03-07 Power Update
    [3V3 LDO Regulator.SchDoc, 5V Buck Boost Converter.SchDoc, B100BA.PrjPcb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]
2021-03-10 Net label update.
    [B100BA.PrjPcb, MicroController.SchDoc]
2021-03-10 MCU Power enable signal solder jumper added for using allwasy on module.
    [Main Power Switch.SchDoc]
2021-03-10 A F L Ports of main MCU are deleted.
    [B100 Block Diagram.SchDoc, B100BA.PrjPcb, I2C Network.SchDoc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]
2021-03-11 Socket update
    [B100BA.PrjPcb, Module Output Connector.SchDoc]
2021-03-11 Module Update
    [Module Output Connector.SchDoc]
